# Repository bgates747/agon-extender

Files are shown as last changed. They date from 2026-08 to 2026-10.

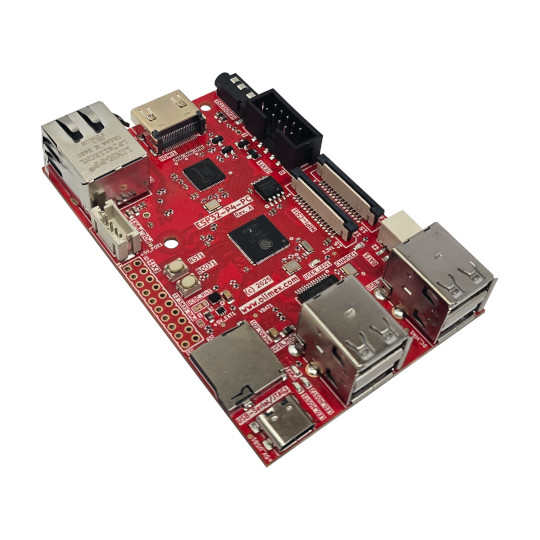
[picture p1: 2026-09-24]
docs/hardware/esp32-p4-pc/upstream/DOCUMENTS/ESP32-P4-PC-2.jpg

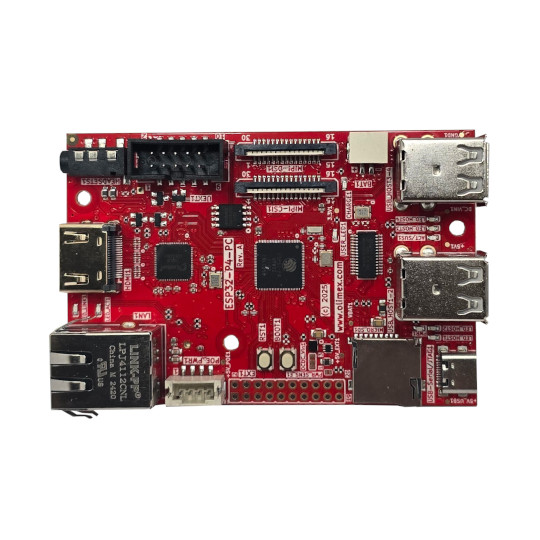
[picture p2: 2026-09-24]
docs/hardware/esp32-p4-pc/upstream/DOCUMENTS/ESP32-P4-PC-3.jpg

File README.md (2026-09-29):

# Agon Extender

Agon Extender adds an ESP32-P4 coprocessor to an Agon computer. **Extended
Display Processor (EDP)** runs on P4; **Extender MOS (EMOS)** replaces MOS on the
eZ80 and owns display routing, keyboard admission and Extender transports.

This is a working development project, not a general ready-to-install release.
The tree includes retained experiments and diagnostic targets. A source checkout,
a successful compile and a deployed/qualified combination are different things.

## Start here

The [Extender handbook](docs/README.md) is the current documentation entry point.

1. **Using an existing installation:** [operator and external-agent entry point](docs/using-extender.md).
2. **Transferring files:** [mainboard SD guide](docs/mainboard-sd.md), including the
   foreground `EMOS sdserve` EMOSlet and paired `--fast` option.
3. **Building:** [component build guide](docs/building.md). Select the native
   `p4-console` profile explicitly; the retained PlatformIO files are historical
   rollback material.
   The accepted r55 console was reconstructed from maintained source; select
   exact approved bytes through [production](production/README.md), not Git HEAD.
4. **Unfinished work:** [TODO](TODO.md). Task records preserve dated evidence;
   they are not automatically current operating instructions.

## Capabilities and limits

Current handbook review: **27 September 2026** (documentation/source inspection). Results apply to the
recorded builds and bench, not every Agon/P4 combination.

| Capability | Current status and authority |
|---|---|
| Legacy / Exclusive Compatible (ExCom) display routing | EMOS selects mainboard VDP or EDP. Retained VDP rendering and browser output work; compatibility and performance limits remain. [Architecture](docs/architecture.md), [bug register](docs/firmware-bugs.md). |
| Physical, browser and agent keyboard input | P4 USB input, explicit browser capture and paced host automation are implemented. All require EMOS to have admitted Extender input. Physical input takes priority; browser capture overrides automation. [Keyboard guide](docs/remote-keyboard.md). |
| Browser video and observation | P4 serves the page and final rendered pixels, with full-frame RLE2 by default. Browser output can slow gameplay; presented fps is not application-loop or native-rendering throughput. [Video contract](docs/protocols/browser-video.md). |
| Agon mainboard SD | Foreground `EMOS sdserve [--fast] /` supports listing, reads and recoverable staged replacement. Normal mode verifies whole files; fast mode omits those verification passes. EMOSlet installation and latest scoped physical checks: [operating guide](docs/mainboard-sd.md). It does not run alongside a game. |
| Remote reset | An optional Pi-hosted bridge pulses the Agon's reset circuit; the browser button uses that bridge. This is not P4-native reset or power cycling. [Reset guide](docs/bench-reset.md). |
| P4-local SD | Development candidate provides CLI/HTTP file and directory management; bounded r57 hardware checks recorded, outside selected production v0.1.0. [P4 SD guide](docs/p4-sd.md). Current bench firmware must be checked separately. |
| Future / deferred | Audio: [PORT-004](docs/tasks/PORT-004.md). Parallel transport, MicroPython and physical video outputs remain separate work; see [TODO](TODO.md). |

Network services use plain HTTP/WebSocket on a trusted LAN, without
authentication. The SD root passed to `sdserve` bounds access; `/` exposes the
whole mainboard card. The SD wire API does not execute programs. Agent keyboard
control can issue MOS commands only after its input path is already admitted.

The current physical reference is **Agon Light 2 + Olimex ESP32-P4-DevKit Rev D1**.
The [r03 UART harness](hardware/designs/light2-harness-r03/README.md) and its
USB addition are not a complete qualification of every as-built circuit.
The planned **ESP32-P4-PC** has a separate [reference library](docs/hardware/esp32-p4-pc/README.md)
with manuals, schematics, provenance and upstream example-clone instructions.
Do not treat the planned board as the installed DevKit.

## Source ownership and further reading

| Component / subject | Entry point |
|---|---|
| Integrated P4 console | [native profile authority](vdp/build/p4-profiles.json), [native builder](scripts/build_p4.py), [p4_console.cpp](vdp/video/extender/boot/p4_console.cpp) |
| EDP / adapted VDP | [vdp/video/extender](vdp/video/extender/), [vdp/video](vdp/video/), [retained libraries](vdp/vendor/) |
| EMOS and SD listener | [agon-emos](https://github.com/bgates747/agon-emos), including `src/` and `projects/sdserve/` |
| Host SD client | [scripts/sdcard.py](scripts/sdcard.py) |
| Embedded browser assets | [web component](vdp/video/extender/web/README.md); no separate npm build |
| Design and responsibility | [architecture](docs/architecture.md), [ownership](OWNERSHIP.md), [protocols](docs/protocols/) |
| Qualification and known faults | [qualification index](docs/qualification/README.md), [firmware bugs](docs/firmware-bugs.md), [publication review](docs/public-release-readiness.md) |
| Evidence and research | [task conventions](docs/tasks/README.md), [TRS-OS community guide](docs/tasks/TRS-80-002/COMMUNITY-GUIDE.md), [hardware-free samples](docs/tasks/TRS-80-002/bin/README.md) |

## License and upstream work

Agon Extender is distributed under **GPL-3.0-only**, except where individual
files or third-party components carry their own compatible license notices.
See [LICENSE](LICENSE) for the full text and [LICENSING.md](LICENSING.md) for
the licensing and attribution policy.

The port builds on the [official Agon VDP](https://github.com/AgonPlatform/agon-vdp)
and FabGL/vdp-gl. Original MIT and GPL-family notices and upstream attribution
remain applicable to their respective sources.

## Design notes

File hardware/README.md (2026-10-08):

# Hardware designs

Tracked hardware profiles, wiring definitions, and design evidence live here.
Every controlled design follows the identity and revision rules in
[`docs/versions/README.md`](../docs/versions/README.md).

The durable role vocabulary for hardware objects is maintained under
[`objects/`](objects/README.md). It owns names, classes, aliases, and containment
only. Pins, nets, components, and electrical connectivity remain authoritative
inside the applicable revisioned design or fixture profile.

The current P4-PC mapping has a separate
[wiring review drawing](designs/light2-p4pc-harness-draft/README.md), with complete
Agon/P4-PC headers, eight data/UART lanes and dedicated READY/CLOCK/VALID lines.
The Author confirms on2026-10-08 that the migration followed that specification.
The restored drawing and native P4-PC profile match; this is reported construction,
not a new continuity or powered parallel qualification. BOARD-001 owns remaining
as-built/electrical gates. GPIO47/48 are spare, proposed for deferred ZDI recovery.

The earlier simplified
[`light2-harness-r03`](designs/light2-harness-r03/README.md) records the DevKit
UART wiring, including disconnected Port D handshake lines, series resistors
and the separate USB cable. Those details are historical for that board; do not
apply them to the later PC assembly. Bounded UART, keyboard and ExCom results
remain under [PORT-008](../docs/tasks/PORT-008.md),
[PORT-015](../docs/tasks/PORT-015.md) and their qualification records. Neither
assembly inherits the buffered r02 isolation guarantees.

The held frozen candidate is
[`light2-harness-r02`](designs/light2-harness-r02/README.md). Its
placement-independent connectivity YAML is the electrical authority. The
revision also provides a checked design BOM in maintained YAML plus generated
Markdown and flat CSV views. The
predecessor [`light2-harness-r01`](designs/light2-harness-r01/README.md)
remains unchanged for the preserved first forward-transport prototype and its
evidence.

Revisioned physical breadboard configurations live under
[`assemblies/`](assemblies/README.md). The preserved first prototype is
`light2-extender-solderless-assembly-r01`; the new r02 electrical design is
assigned to `light2-extender-solderless-assembly-r02`, whose exact construction
map remains unfinished.

The accepted r02 physical schematic provides the circuit basis; the separate
[`wiring order`](designs/light2-harness-r02/wiring-order/README.md) plans powered
incremental construction in a now-superseded draft. The resistor-addition
proposal was rejected. The r02 design, construction, and testing remain
on hold as of 2026-09-07: full wiring is incomplete and the complete circuit
is untested. Signal views remain tracing/debugging references.
HW-001 and QUAL-002 record the actual installed
subset at each step under
[staged circuit validation](../docs/qualification/staged-circuit-validation.md).
The unfinished complete assembly map is not a lack of circuit authority or a
requirement to finish the entire build before checking a bounded stage.

The retained predecessor logic-analyzer attachment reference is
[`la03-p4-probe-fixture-r01`](fixtures/la03-p4-probe-fixture-r01/README.md).
Its green D0 endpoint was physically verified as GPIO32 / EXT2 pin 9; the
contradictory legacy pin-10 label is retained only as provenance.
Each r02 stage selects and verifies its own relevant measurement attachment;
the predecessor map is not automatically the probe map for that stage.

Machine-local specimen identities, bench topology, and current connection
status remain in the ignored `HARDWARE.local.md`, not this directory.

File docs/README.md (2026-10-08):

# Extender handbook

Start here for current operation and contracts. The [handbook closeout](tasks/AUDIT-009/CLOSEOUT.md)
records checked workflows and remaining limits; the broader [AUDIT-009](tasks/AUDIT-009.md)
historical review is incomplete. It must not require comparing old task amendments to determine
current behavior. Dated evidence supports claims but is not a second manual.

Production **v0.1.0** is the accepted local combination. The [current approved local installation](../production/README.md) selects exact
firmware, EMOSlet and host-tool archives with hashes and installation guidance.

## Use an existing installation

| Need | Current guide |
|---|---|
| First use, prerequisites, host setup and another project's workflow | [Using Extender](using-extender.md) |
| P4-local SD file/directory management candidate | [P4 SD HTTP guide](p4-sd.md), candidate only; not in selected production |
| Mainboard SD: foreground checked/fast, candidate automatic WebDAV and application transfers | [Mainboard SD](mainboard-sd.md) |
| Physical/browser/agent input, ownership and platform limits | [Keyboard input](remote-keyboard.md) |
| Read visible ExCom text without taking video ownership | [Screen text](screen-text.md) |
| Normal Agon reset and browser reset button | [Bench reset](bench-reset.md) |
| Recover an Agon that cannot boot MOS | [MOS recovery](mos-recovery.md) |
| Where files belong on SD | [SD layout](sd-layout.md) |

Remote input requires prior EMOS admission. The production SD listener is foreground,
requires Legacy mode and runs as `/emos/sdserve.bin`. Newer paired development
firmware additionally supports automatic staged mainboard WebDAV on port 8081
at an idle CLI in Legacy/negotiated ExCom, and application-initiated card transfers.
These passed bounded hardware checks but are not in selected production; the
[mainboard SD guide](mainboard-sd.md) supplies current usage and limits. P4-local SD HTTP access passed bounded r57 candidate checks but is outside the
selected production bundle. Neither this page nor the selected bundle identifies
the firmware currently on an occupied bench. Physical HDMI output remains unqualified. Consult the operating guides
for precise limits rather than assuming support from a research or example file.

## Develop against the current interfaces

| Need | Current authority |
|---|---|
| Discover host clients versus retained development helpers | [Host tool index](../scripts/README.md) |
| Common P4 service boundaries for other projects | [Shared services](shared-p4-services.md), development interface and consumer obligations |
| Linux emulator setup and review boundaries | [Emulator setup](emulator-setup.md) |
| Component builds and hardware-equivalence limits | [Building](building.md) |
| Installation bundles and selection status | [Production entry point](../production/README.md), [installation guide](installing.md) |
| Processor ownership and accepted architecture | [Architecture](architecture.md), [repository ownership](../OWNERSHIP.md) |
| EMOS resident gateway and prefixed utilities | [EMOS documentation](https://github.com/bgates747/agon-emos/blob/main/docs/README.md) |
| ExCom control / display-preserving switching | [Console protocol](protocols/excom-console.md) |
| SD wire protocol | [SD protocol](protocols/mainboard-sd.md) |
| Browser frame encodings and pacing boundary | [Video protocol](protocols/browser-video.md) |
| Firmware/build identity rules | [Version policy](versions/README.md) |
| Known faults and reproduction references | [Firmware bug register](firmware-bugs.md) |

The architecture includes accepted design beyond implemented coverage. Current
operation is bounded by the guides and recorded qualifications; an accepted
architecture is not a claim that every mode/peripheral has been implemented.
The selected r55 DevKit composition has a clean build and bounded physical
acceptance; use the production manifests rather than historical overlay recipes.
Other boards and complete peripheral compatibility remain unqualified.
The native [build guide](building.md#board-selection-and-compile-time-pin-mapping)
provides separate DevKit and candidate P4-PC board selections from one VDP source
tree. P4-PC pin and USB-hub configuration is compile-time input; it does not
establish hardware qualification or add HDMI output. A separately selected
experimental [P4-PC HDMI output](tasks/HDMI-001.md) provides fixed720p RGB888,
centered unscaled images with cropping, and retained browser keyboard/services.
r03 passes bounded Author startup and gameplay checks. Excess sprite flicker,
presentation throughput and full mode coverage remain open; this output remains
outside selected production and has no complete product HDMI acceptance.

## Test and qualify

| Need | Authority |
|---|---|
| Current versus historical procedure applicability | [Procedure index](procedures/README.md) |
| Current fixture constraints and accepted input exceptions | [Bench constraints](qualification/bench-constraints.md) |
| Capture failures and uninstrumented controls | [Capture protocol](qualification/capture-failure-protocol.md) |
| Offline HDMI candidate ranking | [HDMI candidate tool](testing/hdmi-candidates.md), experimental; no hardware changes or acceptance guarantees |
| Timing scopes, PRT units and package reuse boundary | [Game timing](testing/game-timing.md) |
| Deterministic rendering load, indefinite visual fixtures and paired mainboard/P4 measurements | [Rendering load suite](testing/render-load.md), experimental; campaign paused with partial results and an offline plotting tool |
| Permanent representative rendering fixtures and local-card result collection | [Resident rendering suite](testing/resident-render-suite.md), exact existing files and bounded acceptance |
| Installed-firmware acceptance suite | [Qualification suite](../qualification/README.md) |
| Qualification operation and retained runs | [Qualification procedure](testing/regression-suite.md) |
| Compatibility evidence / generated-matrix status | [Qualification index](qualification/README.md) |

Bench access, endpoints and installed-build receipts remain machine-local.
A procedure's existence does not authorize its execution or qualify a rebuilt
candidate. Historical runner scripts require review before reuse.

## Evidence and future work

[TODO](../TODO.md) is the unfinished-work index. [Task records](tasks/README.md),
[decision records](decisions/README.md), dated development logs and qualification
receipts hold history and rationale. [P4-PC references](hardware/esp32-p4-pc/README.md)
identify the official reference for the received Rev C replacement board and
retain the historical Rev B snapshot. Integration remains unqualified. Routine users should not need these archives
to reconstruct the instructions in this handbook.

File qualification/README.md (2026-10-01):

# Firmware qualification authority

This directory is the sole maintained executable authority for accepting an
Extender P4 or EMOS firmware revision. Historical task fixtures and scripts are
evidence and research inputs, not acceptance suites. Compatibility launchers
under `scripts/` may delegate here but contain no qualification logic.

## Acceptance policy

An installed Extender/EMOS combination is eligible for Author acceptance only
when the flash tool has produced verified receipts for both exact installed
components and one invocation of `qualification/run.py` records all of the
following against those receipts:

1. every `acceptance_required` case in `manifests/hardware.json` whose
   `applies_to` includes the flashed component passes on the installed boards;
2. the runner restores ordinary startup and admitted neutral keyboard state;
3. the durable summary identifies the flashed artifact and exact source commit,
   case results, elapsed times, and notification outcome; and
4. the Author completes any separately declared manual cases, including loaded-
   asset mode switches, before accepting a revision whose changes intersect
   those cases.

Offline source regression remains a separate development gate in `offline.py`;
it is not rerun by installed-firmware qualification and cannot substitute for
it. Build, emulator, browser-simulation, flash-write, boot-identity, and
human observations remain distinct evidence. No zero-hardware run may report
firmware qualification success. A flash receipt proves installation; it does
not substitute for installed-hardware qualification.

## Layout

| Path | Authority |
|---|---|
| `run.py` | Installed-firmware acceptance runner |
| `performance.py` | Separate installed P4 application/video cadence runner; not an acceptance substitute |
| `offline.py` | Separate pinned-source development regression runner |
| `notify.py` | Terminal spoken cue and durable visible verdict |
| `manifests/offline.json` | Complete maintained host/browser/build inventory |
| `manifests/hardware.json` | Applicable mandatory physical cases and drivers |
| `config.example.json` | Tracked schema for the ignored bench configuration |
| `tests/` | Structural tests for this qualification authority |

The full default run currently requires 25 independently reported checks across
three physical cases. The integrated P4 case exercises actual browser assets and
reset bridge, Agon reset/readmission, Legacy and ExCom routing, keyboard input,
display status, text capture, three fresh decoded WebSocket video frames, an
exact mainboard-SD round trip, independently verified cleanup, and final startup
recovery. WebSocket acquisition retains but discards queued transition geometry,
then requires three distinct frames matching the committed display status. The
RP06 P4 case exercises mode 8→20→8 first without a browser
client and then while retaining one browser-video WebSocket, checking committed
status and decoded frame geometry at every edge. The EMOS case builds its
receipt-bound fixture, stages it with restoration safeguards, exercises real
raw-sector write/read/restore with independent CRC oracles, observes a unique
ExCom start marker, then requires its unique post-I/O completion token and a
returned MOS prompt before starting its result listener and restoring the
original startup file. If completion is absent, only that run's start marker
followed by a later prompt permits recovery input; a bare prompt or retained
framebuffer content is not a foreground oracle. A missing prerequisite, receipt
or check fails closed.

QUAL-003 and QUAL-004 remain provenance for broad graphics and exact paired-
pixel testing. Their private adapters, diagnostic mainboard firmware, and
historical payloads are not silently executed as routine acceptance tests.
Reusable cases must be promoted here with current setup, cleanup, and exact
oracles before they become mandatory.

## Invocation

```sh
.venv/bin/python qualification/run.py \
  --flash-receipt /absolute/path/to/p4-flash-receipt.json \
  --flash-receipt /absolute/path/to/emos-flash-receipt.json
```

The default run requires one verified receipt for each component. `--case` is
reserved for targeted diagnostics and cannot establish full acceptance. The
runner owns its documented board resets, temporary
qualification SD file, cleanup, and terminal notification. It never flashes.

The separate performance runner also requires both verified receipts, but it
does not replace the mandatory acceptance suite:

```sh
.venv/bin/python qualification/performance.py \
  --flash-receipt /absolute/path/to/p4-flash-receipt.json \
  --flash-receipt /absolute/path/to/emos-flash-receipt.json
```

Keep ordinary browser video disconnected. The runner supplies its own controlled
video consumer for the observer-present half of each matched pair and reports
application updates/s separately from delivered frames/s. Empty controls use
the current 60-Hz request cap; Nurples adds the retained 30-Hz comparison. Each
application sample spans 30 seconds of MOS wall time. Nurples starts only after
loading and gameplay initialization; a post-sample white frame bounds the same
30-second host receive window without including loading or result cleanup. The
optional video-work counter endpoint strengthens no-video cases when present;
its absence is recorded and leaves browser disconnection as an operator-owned
precondition rather than rejecting an otherwise measurable firmware image.

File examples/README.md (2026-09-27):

# Development examples and witnesses

These programs are bounded diagnostics, not installed utilities or automatic
qualification. Current use belongs in the [handbook](../docs/README.md).
Do not replay a historical deployment just because its source remains buildable.

| Example | Purpose | Reuse boundary |
|---|---|---|
| [Key query](key-query/README.md) | Stock virtual-key query and event-counter witness | PORT-003 P03-EX01 must refresh hard-coded receipt placement before new runs |
| [Keyboard screen](keyboard-screen/README.md) | Stock rendered-character query diagnostic | REMOTE-002 R02-EX01 must refresh receipt placement and listener handover |
| [Remote keyboard](remote-keyboard/README.md) | eZ80 witness for host-injected events | REMOTE-002 R02-EX01 must refresh qualifier/receipt paths and listener handover |
| [Network hello](network-hello/README.md) | File replacement and ordinary VDP speech demonstration | DEMO-001 D01-EX01 owns the historical installer; refresh startup/service handover before replay |
| [Road matrix](road-matrix-probe/README.md) | Separate buffered computation from final drawing | Current placement guidance uses explicit evidence working directory; source still records submission, not completed rendering |
| [Video marker](video-marker/README.md) | Observable frame progress marker | Current placement guidance uses explicit evidence working directory; no scanout/completion claim |

For every new run, review and freeze its owning task's bounded fixture contract,
identify compiled bytes and preserve earlier receipts. `/autoexec.txt` alone
selects the video mode before invocation. Prepare directories and validate
current keyboard, route and foreground-service readiness. Source/build checks
do not establish current bench applicability. No examples were run or deployed
by the documentation audit.

The four refresh-required guides link retained recipes outside the current
operating path. The last two rows provide source-inspected placement only, not
a new build, installation or hardware pass.

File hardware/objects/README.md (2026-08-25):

# Hardware object authority

This directory is the durable project authority for role-descriptive hardware
object names, classifications, aliases, and containment. It answers **what an
object is** independently of a particular wiring revision, physical specimen,
bench location, test run, or ERP record.

The machine-readable authority is [`objects.yaml`](objects.yaml). Its structural
contract is [`schema.json`](schema.json), and the project validator adds
collection-wide checks that JSON Schema cannot express.

The current authority identity is `hardware-object-registry-r01`, with `draft`
status. Its lineage and latest identity are registered in
`docs/versions/artifacts.yaml`; status and identity in that registry and the
machine-readable authority must agree.

The initial 41-object vocabulary was synthesized from the accepted SETUP-006.1
discovery inventory and naming review. Those task files remain provenance, not
a second maintained object list.

## Authority boundary

The object authority owns:

1. one unique lowercase `object_id` for each durable role;
2. one human-readable label and description;
3. product, prototype, bench, measurement, proposed-product, and context
   domains;
4. reusable object classes and containment relationships;
5. searchable legacy aliases; and
6. links to related project artifact lineages where they already exist.

It does **not** own:

1. pins, nets, wire colors, connector terminals, component values, or
   electrical connectivity;
2. artifact versions or revisions, lifecycle status, physical specimen IDs,
   build IDs, baselines, or test runs;
3. current machine-local bench attachment or power state;
4. Odoo Product, Internal Reference, External ID, lot, serial, BoM, or ECO
   identities; or
5. unresolved protocol, operating-mode, or firmware behavior.

Electrical connectivity remains part of a controlled design revision under
`hardware/designs/<identity>/`. Measurement attachment remains part of a
controlled fixture revision under `hardware/fixtures/<identity>/`. This split
prevents a global vocabulary edit from silently changing the meaning of a
historical harness, fixture, baseline, or qualification run.

Machine-local specimen identity and current bench state remain in ignored local
records as required by the project handoff. ERP exports, when introduced, must
derive stable mappings from this authority and the applicable revisioned design;
they must not become a competing source of electrical truth.

## Change control

Adding, removing, merging, splitting, or redefining an object is a reviewed
semantic change to this authority. Changing only a legacy alias or correcting
wording without changing object meaning is editorial. Neither operation
silently increments a hardware design or fixture revision; any affected
revisioned artifact must be reviewed independently under
`docs/versions/README.md`.

Objects are sorted lexicographically by `object_id`. A `parent_object_id` is a
containment relationship, not an electrical connection. `related_artifact_ids`
are cross-references to the version registry, not assertions that the object is
identical to, wholly governed by, or qualified with that artifact.

## Validation

From the repository root, using the project virtual environment:

```text
.venv/bin/python scripts/validate-hardware-objects.py
```

Validation checks the JSON Schema, identifier and alias uniqueness, deterministic
ordering, parent existence and acyclicity, and references to registered artifact
IDs.

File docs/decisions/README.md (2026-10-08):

# Architecture decision records

Architecture decision records (ADRs) preserve accepted project architecture
and its rationale. Open questions and actionable work remain in the
authoritative `TODO.md` and corresponding files under `docs/tasks/`.

## Decision index

For implemented behavior begin with the [current architecture boundary](../architecture.md#implementation-boundary)
and [handbook](../README.md). This index reports decision metadata, not whether
an implementation or particular board has passed qualification. Later amendments
and linked current contracts govern over superseded details; historical run or
attention instructions are not continuing execution authorization.

| Decision | Recorded authority / completeness |
|---|---|
| [ADR-0001 — Place Extender code under `vdp/video/extender/`](ADR-0001-vdp-source-layout.md) | Accepted / Complete |
| [ADR-0002 — Use PlatformIO with Arduino and ESP-IDF together](ADR-0002-hybrid-firmware-framework.md) | Superseded by ADR-0023 / Complete |
| [ADR-0003 — Pin pioarduino release 55.03.311](ADR-0003-pioarduino-platform-baseline.md) | Accepted / Complete |
| [ADR-0004 — Identify the board as a pre-v3 ESP32-P4](ADR-0004-p4-silicon-identity.md) | Accepted / Complete |
| [ADR-0005 — Qualify QIO flash operation at 80 MHz](ADR-0005-flash-bus-mode.md) | Accepted / Complete |
| [ADR-0006 — Represent internal SRAM and external PSRAM separately](ADR-0006-board-memory-model.md) | Accepted / Complete |
| [ADR-0007 — Use two large OTA application slots](ADR-0007-flash-partition-strategy.md) | Accepted / Complete |
| [ADR-0008 — Add CMake only when the hybrid build proves it necessary](ADR-0008-minimal-cmake-boundary.md) | Superseded by ADR-0023 / Complete |
| [ADR-0009 — Provide a transparent PlatformIO wrapper](ADR-0009-platformio-wrapper.md) | Superseded by ADR-0023 / Complete |
| [ADR-0010 — Use 360 MHz on the current pre-v3 P4](ADR-0010-cpu-frequency.md) | Accepted / Complete |
| [ADR-0011 — Maintain upstream VDP fidelity and separate project-owned structure](ADR-0011-upstream-vdp-integration-and-project-structure.md) | Accepted / Complete |
| [ADR-0012 — Vendor exact release dependencies for the VDP firmware](ADR-0012-vendored-release-dependencies.md) | Accepted / Complete |
| [ADR-0013 — VDP survey findings and integration boundaries](ADR-0013-vdp-survey-integration-boundaries.md) | Accepted / Complete |
| [ADR-0014 — EDU operating modes, state ownership, and service architecture](ADR-0014-edu-operating-modes-and-service-architecture.md) | Accepted / Partial |
| [ADR-0015 — P4 display backend and logical frame service](ADR-0015-p4-display-backend-and-frame-service.md) | Accepted / Complete |
| [ADR-0016 — V1 transport electrical core](ADR-0016-v1-transport-electrical-core.md) | Accepted / Partial |
| [ADR-0017 — Generalized EDP callbacks](ADR-0017-generalized-edp-callbacks.md) | Accepted / Partial |
| [ADR-0018 — RGB222 browser video and bounded frame pacing](ADR-0018-rgb222-browser-video.md) | Accepted / Complete |
| [ADR-0019 — Host keyboard input and independent bench reset](ADR-0019-host-keyboard-and-bench-reset-control.md) | Accepted / Complete |
| [ADR-0020 — 30 fps web output at512×384](ADR-0020-web-output-30fps.md) | Accepted / Complete |
| [ADR-0021 — RLE2 as the browser-video default](ADR-0021-rle2-browser-default.md) | Accepted / Complete |
| [ADR-0022 — Explicit browser keyboard capture](ADR-0022-browser-keyboard-capture.md) | Accepted / Complete |
| [ADR-0023 — Native ESP-IDF/CMake with Arduino as a component](ADR-0023-native-esp-idf-build-authority.md) | Accepted / Partial; implementation decisions in BUILD-001 |
| [ADR-0024 — Centered HDMI presentation](ADR-0024-centered-unscaled-hdmi.md) | Accepted / Complete; HDMI-001/HDMI-002;512×384 stays pillarboxed in a widescreen carrier |
| [ADR-0025 — Bounded RGB888 rendering experiment](ADR-0025-rgb888-rendering-experiment.md) | Accepted / Complete |
| [ADR-0026 — Eight-bit ExExt payload with existing-wire handshaking](ADR-0026-four-lane-exext-transport.md) | Accepted / Partial; PORT-008 owns peripheral/protocol selection and qualification |
| [SD separation of support files, evidence and transactions](ADR-2026-09-21-sd-layout.md) | Accepted / Complete |

[Browser mainboard SD access](ADR-2026-09-27-browser-file-access.md): Accepted / Partial; remaining decisions in REMOTE-005.

[Staged WebDAV with EMOS admission](ADR-2026-09-27-staged-webdav-admission.md): Proposed / Partial; review and open decisions in REMOTE-005.

When changing an ADR's identity, title, status or completeness, update this index.
Do not infer a new decision or change qualification status merely to make the
index look complete.

## Required metadata

Every ADR begins with these fields immediately below its title:

```markdown
- Status: Accepted
- Completeness: Complete
- Date: YYYY-MM-DD
```

Add `Related task` when a task owns the decision. An ADR with partial
completeness must also name its authoritative tracker:

```markdown
- Open-decision tracker: SETUP-NNN
```

## Status

- **Proposed:** presented for review but not authoritative.
- **Accepted:** authoritative current architecture.
- **Rejected:** considered and explicitly declined.
- **Superseded:** no longer authoritative; the ADR identifies its replacement.

Status describes the authority of decisions already recorded. Qualification,
implementation, and testing state do not change an accepted decision's status;
record those separately in its task and evidence.

## Completeness

- **Partial:** accepted decisions exist, but known architectural decisions
  remain unresolved inside the ADR's declared scope.
- **Complete:** no known architectural decisions remain unresolved inside the
  declared scope.

Complete does not mean immutable, implemented, tested, or eternally final. New
evidence may amend or supersede any ADR. Partial ADRs contain only accepted
decisions and link to a task that owns the unresolved questions; they do not
duplicate open questions or actionable checklists.

When the final tracked question is resolved, incorporate the accepted result,
change completeness to `Complete`, and update the task and development log.

## Design audit records

Files named `AUDIT-YYYY-MM-DD-NNN-<subject>.md` record a bounded review of
current architecture, tasks, implementation, generated data, and evidence.
They identify contradictions, omissions, stale assumptions, and affected
authorities without making new architecture authoritative merely by finding a
problem.

Every audit begins with `Status`, `Date`, `Trigger`, `Scope`, and `Owning task`.
Findings use stable IDs and record severity, observed state, required
disposition, and affected artifacts. Status is `In progress` while coverage is
being gathered and `Complete` when the declared scope has been reviewed and
every finding has an owner or explicit deferral.

Accepted architectural corrections are promoted into the applicable ADR and
normative architecture document. Actionable work remains in the owning tracked
task and `TODO.md`; generated outputs are regenerated from their corrected
authorities. An audit is evidence and a correction map, never a competing
architecture specification or task list.

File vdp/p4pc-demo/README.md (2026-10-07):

# P4-PC playground

## Executive summary

Standalone experimental ESP-IDF firmware for P4PC-001: native VGA/720p HDMI animation,
finite analog audio playback, persistent Ethernet and a USB serial command
prompt. This is not an Extender production profile. Agon is not connected.

## Controls

Use the board's USB Serial/JTAG endpoint, 115200 baud, without DTR/RTS reset. Use the supplied Linux client to avoid open-time
modem-line transitions; generic terminal programs may reset this board.
The prompt is `p4pc>`. `help` repeats the controls.
For a single command, use project Python to run
`vdp/p4pc-demo/control.py --port PORT "demo bounce"`; it leaves DTR/RTS
untouched and waits for a bounded command-completion prompt.

| Command | Behavior |
|---|---|
| `info` | Version, IP, heap, SD, scene; pool/render statistics when the display lock is available |
| `demo orbit` | Coloured circles in intersecting orbits |
| `demo bounce` | Bouncing coloured shapes |
| `demo bars` | Static eight-colour bars |
| `demo widgets` | Start the LVGL widgets slideshow once per boot, preferably from paused startup bars |
| `bench 30` | Finite 5–30 second paced benchmark; default 10 seconds; updates/renders/submissions/scanout and stage timings |
| `bench 20 draw` | Drawing capacity: sequential fixed motion steps/refresh, same cache writeback, no presentation/wait |
| `bench 20 rgb332` / `bench 20 rgb888` | Native 640×480 matched opaque-circle reference; direct packed writes/full clear, scanout stopped; restores GUI/prior scanout |
| `scanout off` / `scanout on` | Stop/resume P4 framebuffer DMA and DSI video; retained buffers; off blanks the monitor |
| `pause` / `resume` | Freeze/resume playground animation (does not pause the widgets slideshow) |
| `tone 440 3` | 440 Hz sine wave for 3 seconds; 50–4000 Hz, 1–10 seconds |
| `melody` | Short C-major phrase |
| `volume 65` | Set codec volume, 0–90; default 65 |
| `video` | Report framebuffer samples and LVGL flush count |
| `video raw` | Pause UI refresh and fill scanout memory with direct colour bars |
| `video pattern` | DSI host bars independent of framebuffer pixels |
| `video ui` | Restore UI rendering; resumes playground animation when widgets are inactive |
| `net start` | Start persistent Ethernet/DHCP (deferred during display diagnosis) |
| `sd mount` | Mount SD read-only test path without formatting or write test |
| `sd ls` | List the SD root, limited to 128 entries; no file writes |

The serial owner executes audio synchronously for its finite duration while
LVGL and networking run independently. Audio starts silent; output goes through
the analog headset jack at codec volume 65 with moderate signal amplitude and
short note envelopes. This is not HDMI audio or a stereo-separation test.

`prepare.py --resolution 640x480` selects native RGB888 VGA: PLL 240 MHz / 8,
30 MHz, totals 952×525 and calculated 60.0240 Hz, horizontal blanking 168/96/48,
vertical 10/2/33, VIC 1 and 4:3 metadata. The selected copied BSP slot is
repurposed, including LVGL and panel buffer geometry. It is not a small window
in a 720p framebuffer. Both DSI lanes use 360 Mbps, matching RGB888 pixel demand; peripherals remain idle. This is custom
blanking requiring monitor validation. `--vga-clock apll` retains the failed r10
25.2 MHz/800×525 control; it produced no framebuffer completions.

r11/r12 native output fails Author visual review despite advancing panel
counters. r13 tests LT8912B low-resolution settle and live-stream receiver/DDS
relock; this remains an experimental remedy. Render-only format results do not
require usable HDMI and do not establish a visual pass. The selected LVGL
software renderer has no direct RGB332 backend; the reference kernel excludes
antialiasing/labels and reports drawing, motion and cache times separately.
See the [packed-format method](../../docs/tasks/P4PC-001/RGB332-REFERENCE.md).

The default remains 1280x720, RGB888. r06 uses matched WLED-derived 60 MHz
DPI/bridge timing, two 720 Mbps DSI lanes and totals 1350 × 741, calculating
59.979 Hz. This custom blanking needs physical monitor acceptance; it is not
measured refresh or proof of universal monitor support. The ultimate target
is 60 Hz. The factory SDK's inherited configuration calculates approximately
75 Hz; the earlier unbuilt 80 MHz preparation remains historical evidence.
See the task's [timing research](../../docs/tasks/P4PC-001/DEMO-CANDIDATES.md).
r09 schedules animation and LVGL refresh at 16 ms, with orbit phase based on
elapsed time. This does not establish 60 rendered frames/s: the measured
24-circle 720p workload renders about 12 frames/s while the panel completes
about 60 frames/s. See the [benchmark](../../docs/tasks/P4PC-001/BENCHMARK.md).
Ethernet remains active after DHCP. The BOOT button is deliberately unused
because GPIO35 is shared with RMII TXD1. Do not use BOOT for scene selection.
SD mounting never formats; the upstream write-test function is not invoked.

## Build and provenance

Run `prepare.py` with the project `.venv/bin/python`, supplying `--upstream`
and a new `--output` directory, plus an Author-approved `--revision rNN`.
Optional `--resolution 640x480` selects the Author-requested native VGA
comparison; default is `1280x720`. It requires a clean Olimex checkout at
`04032d68e5c727870f9d40beb9e37b7ab3a66916`. The preparer copies the factory
project into an ignored build workspace, replaces its entry point, removes
unused test components and changes console/font/formatting configuration.
The timing adaptation changes DPI and LT8912B timing together, chooses an exact clock divider,
and disables low-power blanking. Provenance and the IDF divider/compensation
workaround are explained in `prepare.py` beside the edits. The widgets demo
is supplied by the pinned LVGL dependency; its slideshow uses no input device.
r09 uses direct double buffering and a 1 MiB builtin pool allocated through
IDF's fixed PSRAM malloc policy. The inherited compiler remains debug `-Og`;
no accelerated LVGL drawing backend is selected.
The upstream BSP retains its notices and board wiring. No upstream checkout
is edited. Main application code belongs to this project.

`build.py` uses project-owned ESP-IDF 5.5.5 at
`b774170ff46c393eeb5e495ea37936038d3f4f4f` and native host tools under the
ignored workspace. Its default workspace is `agents/p4pc-demo`, containing
`project`, `tools`, `python-env` and `build`. The toolchain is Espressif
`esp-14.2.0_20260121`; Python packages must satisfy IDF's v5.5 constraints.
`build.py` rebases copied local dependency paths into the selected prepared
project without changing registry pins, then checks the actual compiled
component directories. A stale copied lock previously selected an older port;
prepared source alone is insufficient evidence of compiled source.
Retain the generated component lock, SDK configuration, source manifest and
image hashes with each candidate. `version.txt` carries the short build suffix
because the IDF app-description field is limited in size.

Before replacement, preserve and device-verify the entire factory flash. Flash
only the generated segments at their recorded offsets, keeping header bytes,
and verify them before reset. Local endpoint, rollback and installation receipts
belong in `HARDWARE.local.md` and ignored evidence. The task record owns human
visual/audio acceptance and known limits.

The current main starts with paused direct framebuffer bars before creating the animation
task. Atomic pause controls stop incoming animation without waiting behind
rendering. `info` reads counters independently of the display lock; allocator
statistics can still be unavailable while rendering is busy. Ethernet/SD remain
deferred and audio idle. The original factory control and r06 bars/circles
passed physical review. The Author also confirmed changing r09 widgets.

`display_experiment.py` copies the pinned SDK's `esp_lcd` component into the
prepared project and adds a task-local stop/resume hook. Stop waits for a complete
DMA frame, skips rearming and disables DSI video/DPI demand. Resume rebuilds the
existing descriptors, retaining buffers. This is diagnostic source, not an SDK
patch or production display contract. The SDK reference remains unmodified.

Drawing-capacity mode holds the LVGL mutex for a finite window, executes one
fixed animation step and explicit refresh per iteration, and yields one tick
for idle/watchdog readiness. The ordinary tasks remain blocked or paused until
restoration. It bypasses the ordinary port flip/wait in both scanout
states and matches its full-frame cache writeback. LVGL keeps its two buffers
and synchronization. Active DMA repeats a buffer that the diagnostic may
overwrite; drawing-only counts are not safely presented FPS or visual quality.
The paired windows isolate DMA contention. Ordinary paced mode supplies the
practical visible reference; 60 scanout completions/s alone is insufficient.

For a benchmark, select the workload first and use the raw client with a timeout
longer than the finite command, for example `--timeout 45 "bench 30"`. Retain
its start/end markers, actual device microseconds and counter output with
`--log`. A panel completion can repeat pixels. The USB owner does not update
its ordinary periodic status label while the benchmark command runs.

Stage timings use complete intervals beginning inside the finite window.
`draw_mean_ms` is render duration minus wrapper flush time, including software
drawing/dispatch. `cache_mean_ms` measures writeback, `wait_mean_ms` the port's
frame-completion semaphore, and `refresh_mean_ms` includes layout and buffer
synchronization outside the render interval. Boundary counts may differ by one.
See the [native scanout comparison](../../docs/tasks/P4PC-001/SCANOUT-COMPARISON.md).

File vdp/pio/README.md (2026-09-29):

# Historical hybrid build material

BUILD-001 replaced PlatformIO/SCons with native ESP-IDF/CMake as the sole
maintained P4 build authority. Files in this directory and `vdp/platformio.ini`
remain only to reproduce identified pre-cutover evidence, especially hybrid r61.
They are not a second current source/profile authority.

Routine builds use `scripts/build_p4.py` and `vdp/build/p4-profiles.json`.
`scripts/vdp-pio.sh` refuses execution unless the operator supplies the explicit
historical-use acknowledgement documented by that script. Frozen diagnostic
builders retain their owning task contracts; a future need must define a native
profile under a bounded task instead of silently reviving a hybrid environment.

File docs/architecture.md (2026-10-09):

# Agon Extender Architecture

This document defines the accepted design, including requirements whose
implementation remains deferred. It is not a claim of complete compatibility.
[The handbook](README.md) owns current operation; [TODO](../TODO.md) and linked
tasks own incomplete implementation and decisions. No new architecture is
established by a successful experiment or by this documentation reconciliation.

## Implementation boundary

| Area | Current boundary | Authority |
|---|---|---|
| Ordinary display | Legacy and bounded ExCom over UART work; Dual/Exclusive Extended remain broader design requirements | [Console contract](protocols/excom-console.md), PORT-003 / SETUP-005 |
| Input | Mainboard selection and admitted Extender USB/browser/agent input; platform/fault limits remain | [Keyboard guide](remote-keyboard.md) |
| Mainboard SD | Foreground EMOSlet through resident `ext.sdlink` in Legacy; not a background filesystem | [SD guide](mainboard-sd.md) |
| Generalized callbacks | Accepted production requirement; current private timing callback is not the finalized general ABI | [ADR-0017](decisions/ADR-0017-generalized-edp-callbacks.md) |
| Audio / P4-local SD / local video | Accepted or researched directions, not current working output/storage capabilities | PORT-004 / PORT-007 / P4PC-001 |
| Hardware | Simplified r03 UART/USB path has bounded evidence; drawing/as-built work remains. Four-chip r02 is held | [Hardware index](../hardware/README.md), HW-002 |
| Web pacing | Accepted 30-fps contract at 512×384 is not enforced by the selected presentation-credit browser client | [Video boundary](protocols/browser-video.md#implementation-and-later-experiment-boundary) |
| Rebuild | Base target does not reconstruct every deployed overlay | [Build limits](building.md#deployed-candidates-versus-the-base-target) |

The remaining sections state design obligations unless an implemented subset is
identified explicitly. Full fault recovery, generalized EDU APIs and compatibility
coverage must not be inferred from the working console or diagnostic services.

## Browser-video default encoding

RLE2 is the accepted default for browser video output. It compresses complete
supported frames; raw compatibility and explicit test overrides remain available.
See [ADR-0021](decisions/ADR-0021-rle2-browser-default.md) and the
[browser-video contract](protocols/browser-video.md). Encoding choice does not
change the separately accepted output pacing policy.

## Web-output cadence

The accepted 512×384 web-output contract is 30 complete frames/s. The selected r55 browser has no explicit rate limiter; its presentation-driven credits must not be described as either a guaranteed 60 Hz or an enforced 30 fps. Normal test
fixtures must cap snapshot/output admission at 30 fps, independently of native
rendering and application cadence. See [browser-video contract](protocols/browser-video.md)
and [ADR-0020](decisions/ADR-0020-web-output-30fps.md). This target still needs
representative production/browser qualification; it is not a blanket measured guarantee.

## VDP firmware lineage

Agon Extender's VDP firmware begins as a faithful port of the official Agon VDP
to the ESP32-P4. Full backward compatibility with existing Agon software is a
product requirement.

The port preserves official directory names, filenames, relative source
locations, and recognizable code wherever the target permits. P4-specific
changes should be narrow and explicit so maintainers can compare the port with
upstream and incorporate future official changes without reconstructing
equivalent modules under unrelated names.

## Repository layout

The complete P4 build project and VDP firmware live under the repository's
top-level `vdp/` directory. During BUILD-001 migration that directory contains
both the operational hybrid PlatformIO rollback path and the accepted native
ESP-IDF/CMake target structure. Within the project, `vdp/video/` mirrors the
official VDP source directory.

New Extender capabilities and extended functions live under:

```text
vdp/video/extender/
```

This location is inside the firmware source directory selected by the project's
neutral build-profile manifest while retaining a clear ownership boundary.
Existing upstream files remain at their official relative paths. Calls between the
upstream-shaped compatibility port and Extender-owned modules must use narrow,
documented integration points.

The rationale and consequences of this placement are recorded in
[ADR-0001](decisions/ADR-0001-vdp-source-layout.md).

## Change boundaries

The upstream-shaped compatibility port owns stock VDP behavior. The
`video/extender/` subtree owns capabilities that do not exist in the official
firmware.

Target adaptation should follow this preference order:

1. retain upstream code unchanged;
2. isolate board or architecture differences in target-specific support code;
3. use a small conditional or insertion point in an upstream-shaped file when
   isolation is impractical; and
4. replace an upstream implementation only when the P4 target makes the
   original mechanism unavailable.

Every deviation from upstream should remain attributable to a verified target
requirement or an accepted Extender feature.

The official header-defined screen facade remains the display integration
boundary for the port. Preserve its global Canvas/controller ownership, mode
selection and fallback, logical dimensions and scaling, palette and Copper
state, logical frame counter, completion waits, and buffer swaps. P4 display
work may narrowly adapt the concrete controller created behind that facade; it
must not replace the facade with an unrelated project-owned display model.

FabGL `Canvas` and the common bitmapped rendering layer remain the semantic
implementation beneath that facade. Preserve their primitive ordering and
queues, paint and clipping state, geometry, glyph and bitmap operations,
sprites, cursors, readback, completion, and buffering contracts. Direct
assumptions about the old Xtensa VGA-ISR environment may receive narrow P4
adaptations; those changes do not authorize unrelated renderer redesign.

The original VGA2/4/8/16/64 concrete controller family is retained behind a
narrow P4 processor/output binding. It produces native framebuffer state and
logical frame progression independently of any one physical output sink, so
the guaranteed network/browser path and later P4-native local displays consume
one rendering model. Preserve stock mode dimensions, palette quantization,
Copper scanline effects, sprite composition, readback, double buffering, frame
waits and counters, callbacks, and mode failure/fallback behavior as closely as
practical. The old GPIO-matrix, I2S1, DMA-chain, and VSync-ISR engine remains
vendored reference material, not the P4 physical backend.

This stock-shaped family is the **sole product display owner**. The neutral
P4 profile manifest names it explicitly and requires every display-bearing
profile to select exactly one complete, mutually excluded family. The older
project-owned `P4DisplayController`/`P4FrameService`/`PlaneStorage`/
`PaletteState`/`PresentationCompositor` family is not an alternate product
backend and must receive no copied product repair. It remains buildable only in
the non-release PORT-008 qualification profile while that task completes its
actual-action provenance and retained-parser fault-injection gates. Once those
gates are accepted and their transport oracles no longer depend on the older
display closure, the profile and older family are removed; frozen PORT-003
evidence remains historical rather than executable product guidance.

The video backend preserves stock framebuffer formats, memory organization,
row access, rendering algorithms and fast paths as faithfully as possible.
Reuse upstream code exactly wherever processor facilities and video-output
interfaces permit it, including portable code within the old concrete VGA
classes. Differences require a specific evidenced processor/output dependency;
generic abstractions, browser serialization and an existing project design do
not by themselves justify replacement.

Retain stock native packing, palette/Copper behavior, bitmap save/readback,
sprites, cursors, buffering, completion and mode contracts. Contiguous allocation
may coexist with a logical row-pointer table. Browser and later local-display
adapters produce their required output representation at the output boundary;
they do not require the drawing framebuffer to share that representation.
ADR-0013 and ADR-0015 record the Author's fidelity direction. The accepted
AUDIT-006 comparison selects original depth classes with narrow P4 bindings;
PORT-003 owns implementation. First-pass restoration preserves compilable
upstream behavior unchanged, including suspected bugs; fixes are deferred.
Stock lane ordering and inert sync bytes may remain in native storage, with
normalization confined to the output boundary.

A short P4 `esp_timer` callback accounts elapsed logical frames independently
of every output sink and wakes separate drawing and output tasks. P4 preserves queued primitive
execution through the unchanged common controller, logical frame progression
and presentation publication, while maintaining stock's separation between
drawing progress and periodic display progression. Frame counting/output
opportunities must not wait for a continuously replenished drawing queue to
empty. Physical sink callbacks may recycle sink buffers
but do not advance the VDP frame counter or unblock logical swaps.
On a service opportunity, P4 drains queued drawing in FIFO order until empty
or suspended, matching stock VDP's background worker with its timeout disabled.
No fixed primitive-count or elapsed-time cap throttles this drain. Suspension
is checked between primitive executions; immediate flush and double-buffered
drawing/swap contracts remain unchanged.

For the original-controller P4 binding, browser row preparation may wait for
one drawing primitive under PORT-003-R2-D001. Native drawing is excluded only
during one row preparation, and all metadata/lifetime owners share the same
exclusion protocol. This output compromise was accepted with reservation:
stock's reliable 60 Hz cadence remains the reference. The frame-clock path
takes no native-state lock and does not wait for drawing, output preparation,
network delivery or a free snapshot slot. Qualification distinguishes actual
clock jitter from delayed browser presentation. A full queue drain or full
frame copy is not an allowed exclusion boundary.
The current base service prepares snapshots on consumer demand, not on every
logical tick when no sink requests an image. The mode-derived logical
clock interval (16,667 microseconds for 60 Hz) is distinct from rendering
completion and browser presentation rate. Elapsed-tick accounting is not proof of bounded callback jitter or
uninterrupted gameplay; the [display decision](decisions/ADR-0015-p4-display-backend-and-frame-service.md)
maps current source responsibilities and qualification limits.

The retained common renderer preserves pinned upstream bodies for
queue submission, completion waits, background draining, dynamic payloads, and
swap notification. The P4 controller replaces only the unavailable physical
frame executor through existing protected seams. Narrow native-state guards
at execution/lifetime boundaries implement the accepted P4 CPU-reader binding;
they do not change drawing algorithms or add upstream bug fixes. In particular, strict
compatibility retains upstream queue-depth completion behavior even though a
separate A/B research task may evaluate stronger semantics for an upstream
contribution.

Generalized callbacks are an accepted production EDP requirement: applications
are to receive a documented return path for EDP events, results and state. The
current private timing callback is not that finalized general interface. This
supports meaningful interaction beyond submitting display commands. EMOS
retains transport and application mediation under the EDU service contract.
Render completion and the graphics benchmark are initial use cases within the
broader facility. Rendering completion remains distinct from output-sink
presentation, and the retained stock VDU completion contract still applies.
Pingo's mainboard-tested callback supplies a precedent without prescribing the
general callback mechanism or ABI. See
[ADR-0017](decisions/ADR-0017-generalized-edp-callbacks.md).

## EMOS lifecycle observability

Resident EMOS is the authoritative owner of its startup, foreground,
mode/route, failure and admitted-job lifecycle state. The P4 EDP may issue a
bounded read-only query and cache the current-epoch EMOS report for host tools;
P4 keyboard counters, rendered pixels, elapsed time and P4-local service state
are not substitutes for that report. A query grants the P4 no authority to
launch, cancel, reset, select a mode, commit a route, or mutate EMOS state.

QUAL-006 owns the incomplete protocol design. Its recommended no-rewire carrier
uses the existing full-duplex r03 UART1 epoch: P4's transmit lane carries a
private query and EMOS's sole output serializer emits one complete private
response between complete VDU/service records. RTS/CTS remain flow control, not
request signalling. The exact framing and whether queries must work before
explicit Extender UART admission remain open; no new wire or early-boot service
is selected merely by this architecture requirement.

One shared output path reuses stock per-depth packed row expansion, palette
tables, Copper traversal and sprite/cursor decoration without changing
logical framebuffer state or readback. Network/browser and later local-display
sinks receive fixed-capacity latest-generation mailboxes through a common
consumer contract. The frame service never invokes sink code; sinks poll from
their own tasks. Slow sinks may drop reported presentation generations; they
must not block rendering, grow an unbounded queue, or redefine logical frame
timing. See
[ADR-0015](decisions/ADR-0015-p4-display-backend-and-frame-service.md).

By default the P4-PC HDMI adapter presents fitting mode images unscaled and
centered in a selected widescreen nominal60Hz output buffer (initially1280×720), with black
letterboxing and pillarboxing, cropping centered oversized images. Each logical
pixel occupies one output pixel; RGB888 conversion and composition remain at
the output boundary. HDMI follows logical mode double buffering where feasible,
otherwise single buffering, with completed double-buffer publication at a
hardware frame boundary. VDP frames follow the hardware cadence independently
of conversion success. HDMI replaces browser video in this build selection;
browser keyboard and other web services remain available. Future runtime output
selection is owned by EMOS. This accepted
geometry is implemented with bounded hardware evidence; full qualification
remains pending. See
[ADR-0024](decisions/ADR-0024-centered-unscaled-hdmi.md); HDMI-001 owns remaining
implementation and qualification. The Author specifies that logical512×384
stays pillarboxed inside a widescreen carrier; it is not a4:3 HDMI output target.
HDMI-002 qualifies smaller widescreen timings under that same presentation rule.
The Author also authorizes full-width logical drawing on the proven848×480
carrier. Such Extender-specific modes use ordinary EMOS-routed VDU22 selection;
stock mode IDs and geometry remain unchanged. Initial IDs are experimental and
their implementation/qualification belongs to HDMI-002, not the stock API.
At an ordinary EMOS-routed logical mode change, the P4 may select the smallest
proven fitting carrier:684×384 for fitting images up to384lines,848×480 for
480-line images. The P4 joins drawing/output, retires borrowed framebuffer
references and restarts DSI/bridge ownership on core1 before publishing the new
mode. Same-carrier changes retain the existing candidate lifecycle. Logical
mode IDs and buffering semantics remain stock-owned. Oversized images retain
the documented crop fallback; this does not qualify additional carriers.
Experimental timing selection does not change legacy logical mode IDs.
The Author-authorized 320×240 experimental exception uses PPA bilinear2×
presentation: a decorated private320×240 snapshot becomes640×480 at(104,0) in
848×480. Logical front/back buffers remain independent from the HDMI pair.
The P4 rejects a snapshot spanning a logical swap, finishes scaling before
publication and waits for actual DMA release before reusing HDMI buffers.
This exception preserves application dimensions/swap commands, and its loaded
qualification remains owned by HDMI-002; other modes retain unscaled output.

The separate FabGL `VGATextController` is retained in the complete vendored
vdp-gl source but excluded from Extender builds. Official VDP text remains on
the retained Canvas/bitmapped-controller path, so the unused hardware
character-cell VGA driver receives neither a P4 port nor a compatibility stub.

FabGL `CVBSGenerator` likewise remains in the complete vendored vdp-gl source
but is excluded from Extender builds. Composite video is neither part of the
official VDP runtime nor a selected Extender output, so its classic-ESP32
DAC/I2S0/DMA implementation receives no P4 replacement or stub.

FabGL `Scene` also remains vendored but is excluded from Extender builds.
Official VDP sprites retain their own state and bitmapped-controller path;
shared Sprite/display types survive independently. No Scene task, mutex,
collision callback, or parallel sprite scheduler is selected unless a future
Extender feature adopts it explicitly.

The following audio paragraphs define the accepted implementation direction;
current EDP command-consumption support does not provide audio synthesis or a
working output sink. PORT-004/AUDIO-001 own that deferred implementation.
The official header-defined VDP audio runtime remains the audio integration
boundary. Preserve its parser, `PACKET_AUDIO` acknowledgements, channel state,
envelopes, buffer-backed samples, playback timing, audio-control task, and VDU
7 behavior. P4 audio work may narrowly adapt its direct
`fabgl::SoundGenerator` binding to the selected synthesis and output service;
it must not replace the official runtime with a separate audio model.

The vdp-gl waveform and mixer core remains the synthesis layer beneath that
runtime. Preserve waveform generation, channel attachment and lifetime,
sample-rate propagation, channel and global volume behavior, and signed
eight-bit PCM mixing. A narrow P4 adaptation may expose mixed samples to an
Extender-owned scheduler or sink; output backends must not create independent
synthesis semantics.

An Extender-owned PCM scheduler and sink service replaces FabGL's
classic-ESP32 DAC, sigma-delta, I2S0-register, legacy-DMA, fixed-pin, ISR/timer,
and display-mode-selected output machinery. Those physical paths remain in the
complete vendored source but are excluded from the P4 build. Network/browser
audio is the guaranteed Rev 1 sink; Rev 1 does not promise the stock analog
output location or exact analog characteristics.

Logical audio playback runs from the selected sample clock independently of
sink latency, backpressure, or availability. A disconnected or slow browser
must not block VDU processing, delay logical note completion, or alter channel
status; delivery may drop or resynchronize instead. Optional forwarding to the
onboard VDP for local playback remains a separate operating-mode decision.

The dormant vdp-gl `FileBrowser` remains in the complete vendored source but is
excluded from Extender builds. Extender does not presently select a file-browser
API, and required local storage does not imply one. The P4 DevKit microSD card
is a required v1 capability deferred beyond the first beta; its implementation
will follow maintained Olimex/Espressif P4 SDMMC reference code and a
project-owned lifecycle rather than FabGL's classic-ESP32 storage backend.
EDP owns this physical card and its filesystem service. EMOS must be able to
request file reads and receive data from that service through its owned
Extender transport; the P4 card is distinct from the Agon's own SD card.
PORT-007 owns the EMOS interface and storage integration.
Future installed-application, media, network-file, or browser interfaces consume
that storage capability without defining its physical backend.

## Hardware design and active evidence

The current P4-PC uses the
[direct PC harness mapping](../hardware/designs/light2-p4pc-harness-draft/README.md)
under BOARD-001. The Author confirms that the migration followed that drawing:
eight Port C data/UART lanes plus PD4 READY_N, PD5 CLOCK and PD7 VALID_N are
connected as specified. GPIO47/48 remain spare, proposed for deferred ZDI recovery.
No four-chip isolation circuit or series resistors are specified in that PC
drawing; pull-resistor rails and sensing-link constraints are recorded there.
This construction report does not establish powered parallel or reverse-transfer
qualification. The former
[DevKit r03 arrangement](../hardware/designs/light2-harness-r03/README.md), including
disconnected handshake lines and a separate keyboard cable, is historical evidence
for that board, not the current PC pin budget.

[ADR-0016](decisions/ADR-0016-v1-transport-electrical-core.md) records the
accepted but **held** four-chip `light2-harness-r02` candidate and provisional
V1 transport core. Its UART/parallel enable groups and hardware-default isolation
belong to that circuit, not the active direct-wire r03 arrangement. Full r02
construction and qualification remain incomplete; its retained connectivity
profile also has the unresolved integrity mismatch recorded by the audit.
Neither this document nor ordinary r03 gameplay authorizes resuming r02 or
silently promotes r03 to the released replacement architecture. HW-001/HW-002
own that reconciliation.

[`light2-harness-r01`](../hardware/designs/light2-harness-r01/README.md)
preserves predecessor forward-prototype evidence. Do not reuse one revision's
pin, probe, isolation or construction assumptions for another. The
[hardware index](../hardware/README.md) identifies their authorities; the
[staged validation process](qualification/staged-circuit-validation.md) governs
newly authorized construction/testing without requiring unrelated firmware work.
Machine-local installed state remains separate from all design records.

## EDU operating modes and application interface

Project terminology distinguishes the **Extended Display Unit (EDU)** exposed
to eZ80 software from the **Extended Display Processor (EDP)** that implements
it on the ESP32-P4. EDU names the command set, API, and logical facility; EDP
names the processor and its firmware. The terms intentionally parallel Agon's
existing VDU and VDP terminology.

The accepted short names are **ExCom** (Exclusive Compatible) and **ExExt**
(Exclusive Extended); **Dual** remains the two-display mode. Transport behavior
is part of the distinction between the exclusive modes, not an independent
policy that silently upgrades ExCom to parallel operation.

| Mode | Ordinary VDU destination and transport | Explicit EDU destination | Implementation boundary |
|---|---|---|---|
| Legacy | Mainboard VDP, stock mainboard UART | Ordinary EDU plane inactive; documented service exceptions remain | Implemented bounded production subset |
| ExCom | P4 EDP over UART; no parallel traffic | Separate EMOS-owned interface to EDP where supported | Implemented bounded production subset |
| ExExt | P4 EDP with enhanced transport for standard VDU commands; eight-bit bidirectional payload target with existing-wire handshake and UART/parallel phases | Separate EMOS-owned interface | Planned; byte timing, handover, integration and compatibility unqualified |
| Dual | Mainboard VDP; never mirrored | P4 EDP, separate result domain | Planned; general EDU interface unimplemented |

ExExt lets existing VDU applications benefit from faster transport without
rewriting their output calls. It does not promise ExCom-equivalent timing or
compatibility: differences may prove small, but require separate qualification.
Keyboard source remains independently selected. The current
[eight-bit candidate decision](decisions/ADR-0026-four-lane-exext-transport.md)
uses the existing dedicated READY/CLOCK/VALID wires for phase handshakes.
PC4–PC7 remain data lanes; PC0–PC3 serve UART between payload phases.
Payload then uses all eight lanes, temporarily excluding UART on the same pins.
EMOS owns admission, its GPIO state and UART handover; P4 firmware owns its
counterpart. Local RAM flags alone do not establish peer readiness or byte
sampling. PORT-008 owns feasibility and recovery; existing wiring is not yet
qualified for this traffic.

The future parallel-capable pair requires a reciprocal pad-release handshake
before EMOS enables shared UART pins after reset. Absent/older P4 firmware leaves
Extender I/O unavailable while mainboard MOS/keyboard remain usable. EMOS must
not reclaim those pins on timeout. Reset invalidates admission state; the current
UART-only firmware is not represented as implementing this candidate boot fence.

Extender-aware programs address the P4 through an explicit, stable, versioned
EDU API owned by EMOS. Synchronous foreground applications may link a client
binding, but that binding invokes EMOS and does not own the transport,
activation, receiver, or lifecycle. Persistent or asynchronous capabilities may
use an explicitly installed resident facility subordinate to EMOS arbitration.

Optional resident facilities do not independently intercept or redirect
`RST.LIL 10h` or `RST.LIL 18h`; the EMOS mode dispatcher alone owns those VDU
paths. Applications must discover and open EDU deliberately through EMOS. EMOS
owns persistent transport state, interrupt-driven reception, queues, client
arbitration, and mode lifecycle. Extend resident EMOS with ordinary compile-time
linking and clear command/service/interrupt boundaries. The current scope
requires no module loader, runtime relocation or restriction to moslet space.
Keep changes small and upstream-reviewable while preserving the EDU contract.
See
[ADR-0014](decisions/ADR-0014-edu-operating-modes-and-service-architecture.md).

In **Exclusive Compatible (ExCom) mode**, the EDP is the sole compatibility display
processor and uses the stock VDP UART transport contract. It owns the
stock-compatible command and response stream while MOS retains canonical VDP
sysvar storage, completion flags, and the mechanism that updates them. The
selected hardware core provides all four eZ80 UART1 signals independently of
the predecessor split-link harness; its exact firmware behavior and physical
qualification remain under HW-001 and PORT-008.

In **Exclusive Extended (ExExt) mode**, the EDP has the same exclusive compatibility
authority and logical MOS/eZ80 integration reach. Enhanced transport remains
planned. The current investigation targets eight-bit payload in both directions,
with handshake/status over the dedicated READY/CLOCK/VALID connections before
and after each bounded parallel phase. EMOS owns CLOCK and VALID in both
directions; P4 owns READY. UART must be quiesced and restored under EMOS/P4 coordination; it cannot
carry control or keyboard bytes concurrently on shared payload pins. Byte timing,
protocol and routing integration remain under PORT-008 and SETUP-005. The older
forward-only circuit remains held evidence. EMOS ownership is unchanged.

Both exclusive modes may claim compatibility only for the declared normal
application-facing surface; Extender v1 explicitly excludes local printer/USB
serial, console/terminal, ZDI, Intel HEX, YMODEM, updater, and debug facilities
unless a later accepted decision restores them. The deferred printer/console/
terminal intentions below refine that exclusion without qualifying an output
binding. EMOS's fixed VDU dispatcher and committed-backend selection are
implemented for the qualified Legacy/ExCom subset. The
[console protocol](protocols/excom-console.md) owns its current activation,
response and lifecycle contract; PORT-003 and QUAL-003 retain wider coverage
and qualification obligations. Do not interpret a working subset as complete
compatibility.

Author clarification, 2026-09-19: Firmware-update commands and Intel HEX/YMODEM maintenance are supported only
through the stock mainboard path in Legacy mode for now. The operator selects
Legacy through EMOS before invoking them; EMOS does not silently forward these
commands from ExCom to mainboard VDP. EDP does not implement their update or
transfer operations. Project-owned SD service, P4 deployment and ZDI recovery
remain separate capabilities. This scope decision does not assert that upstream
has retired or superseded these utilities. Accidental delivery to EDP still
requires defined rejection/consumption behaviour; empty handlers are not thereby
qualified as safe.

In **Dual mode**, the onboard VDP remains authoritative for VDU and MOS VDP
sysvars while the EDP is addressed through EDU and retains results in an
EDU-owned state domain. Applications and project-owned abstraction layers may
coordinate both processors, but ordinary application VDU is never mirrored:
Legacy and Dual route it only to the onboard VDP, and both exclusive modes
route it only to the EDP. Targeted private input/bootstrap control, recovery
diagnostics, and separately identified qualification traffic are not mirrored
application output. Competing writes to canonical sysvars remain unsupported.

Separately identified qualification traffic may originate in an SD-loaded
application that submits a bounded request to resident EMOS. EMOS validates
and owns the complete transport transaction; the application does not access
Extender registers, UARTs or routing state. The visible-text diagnostic keeps
ordinary VDU on the onboard VDP while P4 executes the submitted text through
retained EDP. Sample contents are independent of both firmware images. This
implements the diagnostic exception in ADR-0014 and does not constitute an
additional operating mode or ordinary-VDU route.

EMOS is one complete backward-compatible replacement for stock MOS, not a
side-by-side companion. It is the only supported software authority for
ordinary VDU routing, Extender transport ownership, and committed mode.
Applications, linked EDU bindings, and optional resident services
request those operations through EMOS and do not install independent hooks or
claim UART/GPIO ownership. The proof-of-concept and v1 contract enforce this
across supported software; they do not attempt adversarial isolation from
deliberate eZ80 machine code with unrestricted register and GPIO access. Such
direct manipulation is unsupported caveat emptor. Project hardware and
software still use fail-safe defaults and bounded activation, but make no
non-bricking guarantee for external code that violates this normative contract.

EMOS is also the sole authoritative source of the current formal operating-mode
name. It derives that name only from committed VDU-route and EDP-service state.
EDP/P4 firmware and applications may report their local condition, requested or
pending targets, readiness, transport state, and failures, but may not describe
an uncommitted, failed, or partial combination as Legacy, Dual, Exclusive
Compatible, or Exclusive Extended.

### Mode lifecycle, transition, and recovery

Formal mode is the committed combination of two EMOS-owned logical planes:
ordinary-VDU routing and EDP service. Only these combinations are valid:

| Formal mode | Committed VDU route | Committed EDP service |
|---|---|---|
| Legacy | onboard VDP | inactive |
| Dual | onboard VDP | active |
| Exclusive Compatible | EDP compatible | active |
| Exclusive Extended | EDP extended | active |

An exclusive route with inactive EDP service is invalid. Keyboard-source
selection is independently retained across mode changes under ADR-0014's
2026-09-08 amendment. Keyboard-only P4 activity does not activate the ordinary
EDP/EDU service plane or imply Dual. EMOS alone derives
and names formal mode from the two committed planes; requested, conditionally
pending, failure, and fallback information belongs to lifecycle state rather
than to a fifth formal mode.

Cold boot first reaches fully operational Legacy. Each explicit late
`autoexec.txt` or manual request permits the EMOS coordinator to make at most
one prepare/readiness/commit/recover attempt. EMOS validates every prerequisite
and initializes the complete target before publishing either plane. On a
missing or incompatible prerequisite, EMOS returns or reports a bounded failure
through an available accepted caller or diagnostic path. Any pre-commit failure
restores the current stable mode with routing unchanged and no partial
publication; this routing-coherence guarantee does not depend on preserving the
initiating program or other processor state. For the general mode-service design, a successful presence/version
probe activates EDP and commits Dual; a failed probe leaves Legacy. Exclusive
entry likewise begins in Legacy. Legacy is the mandatory transition hub: EMOS
commits Legacy before attempting a different non-Legacy destination, and no
direct non-Legacy-to-non-Legacy transition is contracted. Live Legacy-to-Dual
and Dual-to-Legacy activation is accepted; an ordinary-VDU route change may
instead use the disruptive transition described below.

Extender v1 uses pull discovery and defines no proactive EDP presence signal.
EMOS selects a reviewed transport/wiring profile, arms the eZ80 receiver, sends
the request, validates the EDP identity, protocol, and capabilities, and alone
commits mode. That handshake establishes protocol readiness; QUAL-002 remains
the authority for electrical and power/reset qualification. EDP asynchronous
traffic requires a negotiated and armed post-activation receiver. P4 reset
revokes that permission, and EMOS quarantines stale traffic.

EMOS uses one fixed set of reset-vector and C-runtime output handlers and one
semantic VDU dispatcher. Each active invocation retains a snapshot of one
committed backend. To change that backend, the EMOS coordinator blocks new
invocations, waits for active calls and owned response work to finish or be
abandoned, reinitializes affected parser state, and commits atomically. The beta
adds no second semantic VDU parser and does not preserve multi-call partial
commands across a disruptive transition.

The first idle-console Legacy↔Exclusive Compatible increment may switch
without rebooting, as accepted in PORT-008-D005. EMOS preserves keyboard
source/layout and presents a fresh destination screen/prompt. It retains
transactional readiness, parser/queue quiescence and bounded failure recovery;
ordinary commands do not authorize in-flight application switching or display
migration. The explicit `--keep-display` application exception below preserves
each processor's own display without migrating assets. The older disruptive controlled-restart baseline
applies outside this bounded exception and remains an acceptable v1 fallback.
Preserving loaded eZ80 program, data, and resident processor state is an
aspirational v1 target and a firm v2 requirement under MODE-001; preservation
never implies migration of display assets between processors. The exact restart
actor and carrier remain open under SETUP-005 F018. A fixed-backend build still
activates explicitly after Legacy startup, and persisted preferred mode is not
a v1 contract. A pending state carried across reset exists only if a selected
implementation requires it; retained cross-boot circuit breaking remains
conditional under MODE-002. Exact lifecycle-state storage and session/shutdown
APIs remain open in SETUP-005.

A successful explicit activation remains latched system state when the
foreground caller exits or no known callers remain. Normal return to Legacy is
an explicit coordinated EMOS shutdown and may refuse or time out if registered
work cannot quiesce. A separately explicit forced shutdown may invalidate work
after warning.

Reset invalidates the affected component's sessions, parsers, pending work,
readiness, and authority even if RAM bytes or another processor survive;
invalidation does not require erasure. eZ80/MOS and whole-system resets return
through Legacy. P4 reset or detected EDP failure in Dual invalidates EDU work
and causes EMOS to commit Legacy while ordinary VDU continues through the
onboard VDP. In an exclusive mode, EDP or transport failure blocks ordinary
VDU, permits only bounded reinitialization, and then disruptively recovers to
Legacy without claiming preservation of application, display, audio, buffer,
or other EDP-visible state. EMOS recovery may use the onboard VDP for a
best-effort diagnostic only after disclaiming that continuity.

EMOS lifecycle records retain requested, conditionally pending, committed,
failure, and fallback information. Structured failure reporting is advisable
during beta and mandatory for v1. It provides best-effort descriptive display
output plus durable machine-readable consequences and safely obtainable
processor context, never relies solely on a failed component when another
accepted sink survives, and never delays safe recovery. The durable P4-flash
crash-log requirement and provisional `coredump` sink are defined below; exact
record behavior and qualification remain with DIAG-001.

Application entry point and operating-mode destination are separate concerns.
`RST.LIL 10h`, `RST.LIL 18h`, and the corresponding C-runtime output paths are
always conventional VDU calls. EMOS routes them to the onboard VDP in Legacy
and Dual, to the EDP stock-compatible backend in Exclusive Compatible, and to
the EDP enhanced backend in Exclusive Extended. Explicit EDU calls remain a
separate versioned interface with a separate result domain, even in an
exclusive mode where both interfaces reach the EDP.

No new RST vector is allocated for EDU. The existing MOS API dispatcher reaches
the resident EMOS gateway through API `0x51`; C-function slot `0x20` is its C
entry. A versioned request identifies the service and input/output buffers;
a client binding may hide that request construction. The maintained
[EMOS gateway contract](https://github.com/bgates747/agon-emos/blob/main/docs/emos-v1-contract.md)
owns the exact ABI. The gateway exists, but general EDU drawing services and
Dual mode do not follow merely from its presence. The same distinction keeps
ordinary VDU queries in the canonical MOS result domain and explicit EDU results
separate. Do not resurrect the cancelled external module/provider loader.

An EDU-aware application may therefore combine VDU and EDU calls without
creating another operating mode. In Dual this intentionally coordinates two
processors; in either exclusive mode it uses two interfaces to the EDP. An
application may also require Exclusive Extended and use conventional VDU
restart calls as its efficient compatible-output path rather than wrapping
every transfer in an EDU invocation. Such a mode-dependent application must
verify or request Exclusive Extended before issuing output that would be unsafe
or meaningless if routed to the onboard VDP.

Every active Extender mode requires EMOS. In Dual, EMOS keeps ordinary VDU on
the onboard VDP while separately activating and arbitrating EDU access to the
EDP. Stock MOS supports only Legacy: Extender remains inactive, and an unknown
Extender command or API may fail normally. Direct linked-client ownership of
UART1, parallel GPIO, interrupt vectors, or EDP lifecycle under stock MOS is
outside the supported architecture.

The accepted buffered r02 design requires hardware-default driver isolation;
the active direct-wire r03 arrangement does not provide those buffer enables.
Do not infer power-domain or contention isolation from software ownership or
pull-up resistors. EDP gates ordinary display activation through the bounded
EMOS exchange. Explicit resident keyboard and foreground SD services have their
own admission and do not implicitly enable ordinary VDU routing. Supported
pre-activation logic patterns or GPIO-direction
changes may be ignored or fail safely without opening another operation. These
rules govern every project-produced design, build,
example, and test. They are not a privilege boundary or warranty for arbitrary
external code that directly manipulates shared GPIO, UART, interrupt, flash, or
routing resources in violation of the EMOS contract; such code may corrupt,
damage, or brick either system. If EDP safely observes unmanaged activity, it
may warn through an Extender-owned display or log only and must not respond over
unactivated Agon-facing wiring.

In **Legacy mode**, the onboard VDP retains ordinary VDU and display behavior,
including maintenance/operator facilities omitted by Extender. Explicitly
selected browser or native USB keyboard input may continue through P4 and EMOS; it is the
accepted exception to older total Extender absence/quiescence requirements.
EMOS retains canonical keyboard state ownership. The foreground mainboard-SD
listener is another explicitly admitted Legacy
service: EMOS owns its transport through `ext.sdlink`, and sdserve performs file
I/O on eZ80. It does not activate the ordinary EDP display/EDU plane or imply
Dual. Other general EDP/EDU service remains inactive. In Dual mode those
facilities may likewise remain available through ordinary VDU
to the onboard VDP; they are not implemented by Extender.

During ExCom, EMOS leaves a static mode/status notice on mainboard VGA and
hides its text cursor with stock VDP commands. Ordinary CLI echo and application
VDU output follow the EDP route. The mainboard VDP keeps scanning out the notice
and generating the retained VBlank clock without periodic EMOS redraws or a
double-buffering requirement. This transition/status output does not mirror
ordinary VDU; Dual retains both displays' active roles.
Initially, returning to Legacy starts a fresh mainboard screen with a visible
cursor and MOS prompt, preserving keyboard source and layout. Clearing the
screen is an initial implementation choice rather than a permanent mode rule.

The formal operating-mode names are **Legacy mode**, **Exclusive Compatible
mode**, **Exclusive Extended mode**, and **Dual mode**. “Compatible” and
“Extended” are accepted short forms in unambiguous operating-mode context, but
“Exclusive” remains part of both official exclusive-mode names.
**ExCom** is accepted conversational shorthand for **Exclusive Compatible**;
the formal name and stable mode identity remain unchanged.

EMOS CLI control uses case-insensitive `EMOS <subcommand>` syntax in both
interactive commands and autoexec. `EMOS EXCOM` and `EMOS LEGACY` request the
named destination mode; `EDU` explicitly addresses Extender functionality while
`VDU` retains ordinary semantics and EMOS-owned routing. The accepted command
contract is in [ADR-0014](decisions/ADR-0014-edu-operating-modes-and-service-architecture.md#cli-and-keyboard-selection--2026-09-08).

`EMOS KEYINPUT mainboard` selects the Agon mainboard keyboard;
`EMOS KEYINPUT extender` selects P4's common input source: native USB, explicit
browser capture or host-agent automation, arbitrated on P4. Browser capture does
not require the historical `EMOS KEYINPUT browser` selector. This supersedes the
earlier browser-input deferral; see [ADR-0022](decisions/ADR-0022-browser-keyboard-capture.md)
and the [keyboard guide](remote-keyboard.md). PORT-015 records native USB
implementation and qualification; REMOTE-001/002 record the remote providers.
With no source argument, the command reports the selected source.
`SET KEYBOARD n` remains the distinct runtime layout selection with the same
effect across modes. `EMOS LEGACY` preserves the selected keyboard source;
returning display output to the mainboard does not shut down selected browser
or P4 USB keyboard input.
Across boots, `autoexec.txt` alone restores these selections. EMOS starts with
mainboard keyboard input; commands at the interactive prompt change runtime
state without saving a separate state/configuration file. No new nonvolatile
settings store is introduced for this increment.

Extender v1 does not inherit the stock VDP's UART0 `DBGSerial` mapping or local
operator facilities. In either exclusive mode, attempts to invoke those paths
must follow stock VDP command consumption and observable failure behavior as
closely as practical. Strict compatibility modes preserve even undesirable
observable stock behavior; other modes should provide improved deterministic
failure and recovery. The exact strict-mode boundary and command-level
semantics are tracked under SETUP-005-D006.

## Firmware build model

Native ESP-IDF/CMake is the accepted outer project, dependency and build
authority. The project retains Arduino-ESP32 as a pinned ESP-IDF component
rather than selecting two competing outer frameworks. BUILD-001 completed the
maintained-path cutover; PlatformIO/SCons remains identified historical rollback
material only.

Arduino preserves the application-level structure expected by official
`agon-vdp`, including its sketch entry point and Arduino-oriented APIs and
libraries. ESP-IDF supplies the lower-level target configuration and native P4
facilities needed for silicon revision handling, memory, partitions, USB,
Ethernet, multimedia peripherals, and future Extender functions.

The native build must prove selected, compiled and linked graph agreement,
configuration/dependency equivalence and bounded physical behavior before it
replaces the operational hybrid build. See
[ADR-0023](decisions/ADR-0023-native-esp-idf-build-authority.md).

FreeRTOS supplied by ESP-IDF remains the firmware concurrency substrate.
Extender replaces inherited ESP32-PICO watchdog disabling and core-placement
assumptions with one explicit P4-native policy. Operating modes may change
which tasks run and how they are supervised; strict compatibility governs
externally observable reset and failure behavior rather than requiring obsolete
watchdog internals. Exact task affinity, subscriptions, timeouts, and controlled
resets require subsystem-specific qualification.

Arduino PSRAM and ESP-IDF capability-aware allocation remain the underlying
memory substrate, preserving explicit selection of external, internal,
DMA-capable, and other constrained memory. The compatibility baseline does not
preclude future compile-time performance profiles that exploit P4 resources at
the cost of legacy behavioral fidelity. EDU-aware applications must discover
the active profile's advertised capabilities rather than infer them.

The input choices are Agon-mainboard or Extender-connected keyboard input. P4 acquires one directly attached USB HID boot keyboard,
translates its events into retained stock VDP keyboard semantics and emits
normal VDP keyboard packets to EMOS over the existing r03 four-signal UART1 link at
1,152,000 baud, 8N1 with RTS/CTS. Keyboard configuration/query traffic uses the
same UART in the Agon-to-P4 direction. No parallel transfer or direct
onboard-VDP/EDP link is required for this capability.

EMOS owns the selected input ingress and stock-compatible packet handling.
P4 sends keyboard events/settings, not MOS memory: EMOS updates its own key
sysvars, event counter, virtual keyboard map and application keyboard hooks
through the stock handling semantics. Ordinary applications continue to use
MOS keyboard APIs, sysvars and the keymap; they do not forward input to P4 or
configure UART1. Browser/P4 session messages are distinct from the stock VDP
wire contract and do not introduce a proprietary UART keyboard envelope.

An explicit `EMOS KEYINPUT extender` command enables native USB input through
P4; `EMOS KEYINPUT mainboard` selects the mainboard VDP's keyboard path. EMOS
admits only the selected keyboard source and continues handling the mainboard
VDP's other communications. Source selection is independent of display mode;
autoexec alone restores the desired selection after reboot. Source changes
release held state before admitting the new source; no dual-keyboard mixing
is selected.

Browser input follows [ADR-0022](decisions/ADR-0022-browser-keyboard-capture.md).
P4 admits one controlling browser session at a time. Explicit Capture overrides
host-agent input; a physical USB keypress overrides browser and agent input.
P4 releases the displaced provider's held keys and discards its pending events
before admitting the new provider. Latest explicit browser Capture wins among
browser sessions; opening/reconnecting a page alone does not take ownership.
Input-socket loss, focus loss or explicit release revokes browser capture;
video-only disconnect does not. Reacquisition is explicit. Human browser key
transitions are not subject to the host-agent API's 20 ms pacing policy.

Session admission and revocation precede stock packet delivery. The selected
browser session is a keyboard authority, including normal stock key effects;
focus is a capture condition, not authentication. EMOS retains input-source
selection and canonical-state ownership. EMOS uses interrupt-driven UART1 reception with packet assembly separate from
UART0; the receive streams must not race or splice parser state. The precise session and ingress mechanisms are
owned by SETUP-005, REMOTE-001, PORT-006, PORT-008 and agon-emos INTEG-009.

Physical PS/2 keyboard/mouse acquisition remains on the onboard VDP where
those devices are used. It is not a relay for browser keys. The accepted bench
clock remains the onboard VDP's VBlank/PB1 path. Native USB input uses the
[specified USB keyboard connection](../hardware/designs/light2-harness-r03/README.md#usb-keyboard-addition--2026-09-09).
It does not replace VBlank or itself change ordinary VDU routing. A bounded
qualification session has explicit entry/exit; it does not
claim complete Exclusive Compatible mode; Legacy permits the explicitly
selected keyboard service described above.

For the selected directly attached USB keyboard, P4 receives
USB HID reports through its native host controller, translates them into
ordered processed keyboard events and sends stock keyboard packets through
the same EMOS-owned UART1 session. Explicit `EMOS KEYINPUT extender` selection
controls this path independently of browser focus/network and display mode.
Initial scope is one wired HID boot-protocol keyboard with normal EMOS CLI on
mainboard VGA. USB removal releases held state; it is not browser lease expiry.
No implicit browser/USB mixing or new UART keyboard packet format is selected.

P4's processed-input adapter owns EDP-local keyboard variables, relevant
callbacks, control-key and paged-mode behavior and stock packet generation.
Later Agon-originated EDU event forwarding retains its non-echo rule; browser
keys are original events and must be emitted toward EMOS. Mouse injection and
full mode-specific input composition remain separate scope.

Physical vdp-gl keyboard/mouse drivers, PS/2 controllers, scan-code tasks and
device controls stay vendored but excluded from the P4 build. The browser
adapter reuses stock virtual-key/event vocabulary and applicable pure mapping
semantics without depending on physical PS/2 hardware. Direct USB keyboard
input may use the selected P4 DevKit's existing native host plus the required
USB connector and power assembly. This permission does not restore the omitted
PS/2 engines or select other peripheral expansion.

Extender retains ESP-IDF's OTA image, boot-partition, rollback, and restart
lifecycle as the low-level update substrate. This is independent of the omitted
stock VDP serial updater and does not select an update transport. A project-
owned replacement is warranted only if evidence shows the ESP-IDF facilities
are materially inferior to sound clean-sheet ESP32-P4 practice.

Extender networking is project-owned. The P4 DevKit's native wired Ethernet is
the primary Rev 1 backend; the dedicated-header Olimex MOD-WIFI-ESP8266 is an
optional Rev 1 wireless backend whose P4-to-module protocol and module firmware
must be selected and qualified separately. The dormant vendored vdp-gl ICMP
helper is excluded from the P4 build: it assumes a local Arduino WiFi/raw-lwIP
interface and is not an adapter for a separate ESP8266 network processor.

The initial build pins pioarduino platform release `55.03.311`, which combines
Arduino-ESP32 3.3.11 with ESP-IDF 5.5.5. A moving release alias or development
branch is not an acceptable reproducible baseline. See
[ADR-0003](decisions/ADR-0003-pioarduino-platform-baseline.md).

The Rev-D1 development board's v1.3 ESP32-P4 is represented as the pre-v3
`esp32p4_es` platform variant. SDK configuration explicitly limits compatible
full revisions to 100 through 199, and board qualification reports and checks
the runtime revision. See
[ADR-0004](decisions/ADR-0004-p4-silicon-identity.md).

The primary board environment configures the 16 MB SPI flash for QIO at
80 MHz. This is a qualification candidate until cold-boot, reset, reflash, and
flash-integrity tests pass on the physical board. DIO at 80 MHz is the defined
fallback if QIO proves unreliable. See
[ADR-0005](decisions/ADR-0005-flash-bus-mode.md).

The board definition uses a conservative 512,000-byte internal-RAM link budget
and declares external PSRAM separately. The 32 MB PSRAM operates in hexadecimal
mode at 200 MHz and is intended for explicit bulk allocation; it is not treated
as interchangeable with internal SRAM. Bring-up verifies its capacity and runs
a memory test. See [ADR-0006](decisions/ADR-0006-board-memory-model.md).

The 16 MB flash contains two equal 7 MiB OTA application slots. A candidate
image is written to the inactive slot and must pass an explicit post-boot health
check before it is marked valid; otherwise the bootloader rolls back. There is
no separately maintained factory application. Required NVS, OTA metadata, and
crash diagnostics use the leading data area, and the approximately 1.9 MiB
remainder stays reserved until a durable use is approved. See
[ADR-0007](decisions/ADR-0007-flash-partition-strategy.md).

V1 requires a bounded durable crash-log sink in the P4's onboard flash so
mainboard failure evidence never depends on an optional microSD card. The
dedicated `coredump` partition is the initial candidate and must be validated
for the versioned Extender record, native ESP-IDF crash evidence, integrity,
interrupted writes, and wear limits. P4 microSD may provide richer optional
history or exports. Browser or local video may present a surviving
human-readable report but is not durable by itself. Diagnostic persistence must
never delay safe recovery.

Native ESP-IDF/CMake is the accepted sole top-level build authority for
maintained P4 firmware. Arduino-ESP32 remains a pinned ESP-IDF component so the
upstream-compatible VDP lifecycle and Arduino APIs do not require a runtime
rewrite. One neutral checked-in manifest owns buildable profiles and selected
project sources; a project-owned wrapper binds pinned project-scoped ESP-IDF
source/tools, fresh profile output, dependency locks and build identity. The
native CMake/Ninja graph must compile and link the same declared source closure,
and its compilation database is authoritative only after validation against the
linked objects. See
[ADR-0023](decisions/ADR-0023-native-esp-idf-build-authority.md).

BUILD-001 implemented that accepted direction after host and hardware
equivalence. `scripts/vdp-pio.sh` now fails closed unless an operator explicitly
acknowledges a bounded historical rollback reproduction. Neither the cutover nor
a development build changes the selected production bundle.

The primary Rev-D1 pre-v3 board environment configures the CPU at 360 MHz. A
forced 400 MHz candidate repeatedly asserted during clock initialization on the
attached rev 1.3 silicon and is rejected for this hardware profile. See
[ADR-0010](decisions/ADR-0010-cpu-frequency.md).

### Explicit application display preservation

For paired graphics inspection, applications use public mos_oscli to request
`EMOS LEGACY --keep-display` and `EMOS EXCOM --keep-display` at complete
VDU/query boundaries. Mainboard VDP and EDP each retain their own mode, scene
and resources; EMOS changes the committed route and reply authority through
its coordinator without clearing those scenes or drawing a mode notice. USB
source selection and the mainboard clock remain independent. Default console
switch commands keep their fresh-display behavior. ADR-0014 records this
bounded extension; it does not authorize direct application transport access.

## Browser-video encoding and pacing

EDP composes the final pixels on P4. The [browser-video contract](protocols/browser-video.md)
owns presentation transport encoding and pacing: RGB222 saves threefold payload
relative to RGB888, browser WebGL expands colours, and bounded frame credits
control delivery without a fixed 5 fps throttle. Logical VDP time remains
independent of network/browser progress. Hardware qualification of the new
encoding and pacing is tracked in PORT-003.

### Deferred Extender firmware update path — 2026-09-20

Current stock maintenance support remains Legacy-only. Functional P4 EDP
updating using the stock &A1 interface is a deferred production direction,
under EMOS-owned routing and explicit update targeting. Both implementation
and discard-only repairs are deferred; this does not qualify today's empty
handler. ADR-0014 and PORT-003-D015 record the scope and research.

### Deferred printer output intent — 2026-09-20

VDU 1/2/3 remain desired serial debugging/output facilities for EDP, rather than
intentional discard-only commands. Their P4 output binding is not yet selected
or qualified. Research and likely implementation are deferred; this is not a
v1 delivery commitment. ADR-0014 and PORT-003-D016 refine the earlier exclusion.

Console (&FE) and terminal (&FF) modes share the deferred printer-output scope:
possible future serial facilities, with one endpoint/coexistence review before
implementation. Current P4 behavior and EMOS route authority remain unchanged;
no implementation or qualification is implied (PORT-003-D017).

### Foreground EMOS utilities

Resident EMOS retains gateway, transport, keyboard and display-mode ownership.
The accepted `/emos/<name>.bin` foreground MOSlet dispatch follows
[ADR-0014](decisions/ADR-0014-edu-operating-modes-and-service-architecture.md):
built-ins first, idle CLI only, ordinary fixed-address MOSlet format. Cancelled
external `.emo` provider loading is retired; no background module framework is
introduced. Implementation and validation are tracked in
[AUDIT-008](tasks/AUDIT-008.md).

### Planned browser file access

The browser file-management trial for mainboard SD is parked as a fallback,
including bulk selection and whole-directory operations. The browser uses P4
HTTP and EMOS-owned mainboard service access. Final interface selection is reopened after usability review. Library selection
and added operations remain investigation scope; this is not implemented browser behavior.
See [the decision](decisions/ADR-2026-09-27-browser-file-access.md).

### Bounded direct RGB888 experiment

The explicitly selected RGB-001 experimental P4-PC HDMI build may replace the
mode20/8/13664-colour logical storage with BGR888 rows in the LCD-owned720p
buffers while retaining colour semantics, EMOS routing and the independent frame
clock. The row spacing is3840bytes. Double-buffer swaps release the former front
only after DMA adopts the completed back; physical scrolling moves pixel contents.
Ordinary builds retain native storage. The initial separate-plane/copy variant
remains retained evidence. This scoped experiment is recorded in
[ADR-0025](decisions/ADR-0025-rgb888-rendering-experiment.md); production selection
and performance acceptance remain separate. Double-buffer overlay changes are
presented with explicit application swaps; autonomous overlay timing remains
outside this variant's qualified scope.

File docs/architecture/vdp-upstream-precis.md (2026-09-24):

# Official VDP Architecture Précis

Status: Draft for Author review  
Source baseline: AgonPlatform/agon-vdp release `v2.16.0`,
[`c7ac293d2aa81ddfa693390549bcd909069c8fc3`](https://github.com/AgonPlatform/agon-vdp/commit/c7ac293d2aa81ddfa693390549bcd909069c8fc3),
verified as the latest official tag on 2026-08-20

## Scope
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

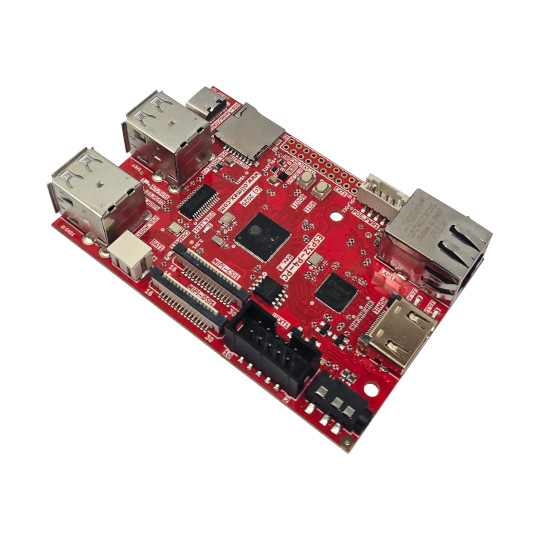
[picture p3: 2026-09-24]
docs/hardware/esp32-p4-pc/upstream/DOCUMENTS/ESP32-P4-PC-1.jpg

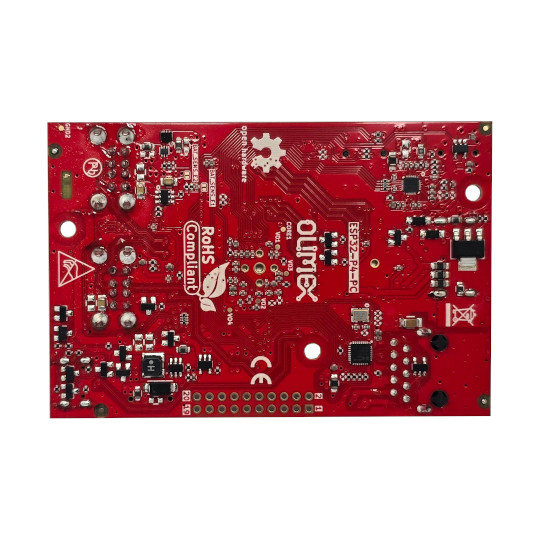
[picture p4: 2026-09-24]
docs/hardware/esp32-p4-pc/upstream/DOCUMENTS/ESP32-P4-PC-4.jpg

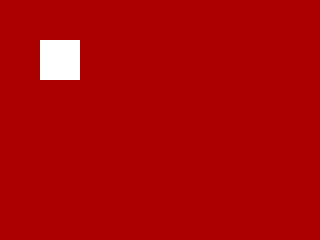
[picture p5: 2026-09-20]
docs/tasks/QUAL-004/page-controls/evidence/PAGE_FRONT/mainboard.png

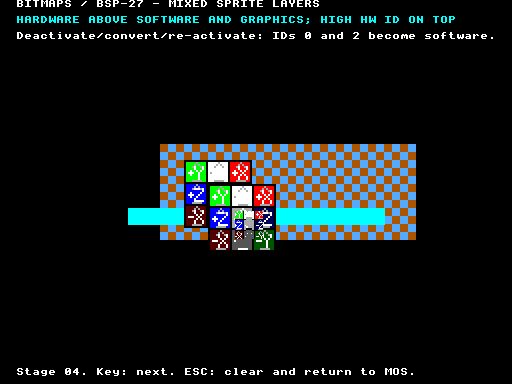
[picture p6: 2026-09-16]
docs/tasks/QUAL-004/evidence/bounded-corpus/BSP27_04-a1/BSP27_04/mainboard.png

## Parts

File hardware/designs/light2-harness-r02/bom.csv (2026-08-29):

line_id | quantity | uom | category | references | product_name | manufacturer | manufacturer_part_number | value | package | procurement_spec | role
ic-sn74lvc244an | 2 | each | integrated-circuit | U1;U2 | TI SN74LVC244AN octal buffer | Texas Instruments | SN74LVC244AN | SN74LVC244AN | PDIP-20 | Exact part number; N suffix is the through-hole PDIP package. | Agon-powered forward UART, parallel-data, CLOCK, and VALID_N buffering.
ic-sn74lv125an | 2 | each | integrated-circuit | U3;U4 | TI SN74LV125AN quad buffer | Texas Instruments | SN74LV125AN | SN74LV125AN | PDIP-14 | Exact part number; N suffix is the through-hole PDIP package. | Agon-powered UART return and P4-powered low-only isolated controls.
resistor-220r-1pct | 13 | each | resistor | R1;R2;R3;R4;R5;R6;R7;R8;R9;R10;R11;R12;R13 | 220 ohm 1% through-hole resistor |  |  | 220 ohm | axial through-hole | 220 ohm, 1% tolerance or better; breadboard-compatible lead size. | Replaceable source-series protection and damping on every driven transport output.
resistor-47k-1pct | 8 | each | resistor | R14;R15;R16;R17;R18;R19;R20;R21 | 47 kilohm 1% through-hole resistor |  |  | 47 kohm | axial through-hole | 47 kilohm, 1% tolerance or better; breadboard-compatible lead size. | P4 data and shared-UART inactive-state bias.
resistor-10k-1pct | 10 | each | resistor | R22;R23;R24;R25;R26;R27;R28;R29;R30;R31 | 10 kilohm 1% through-hole resistor |  |  | 10 kohm | axial through-hole | 10 kilohm, 1% tolerance or better; breadboard-compatible lead size. | CLOCK, VALID_N, READY_N, output-enable, and P4 control default-state bias.
capacitor-100nf-ceramic | 4 | each | capacitor | C1;C2;C3;C4 | 100 nF ceramic bypass capacitor |  |  | 100 nF | radial through-hole | Nonpolar ceramic, at least 6.3 V rating, breadboard-compatible lead spacing. | One local supply bypass capacitor at each logic IC.
capacitor-1uf-ceramic | 2 | each | capacitor | C5;C6 | 1 uF ceramic bulk capacitor |  |  | 1 uF | radial through-hole | Nonpolar ceramic, at least 6.3 V rating, breadboard-compatible lead spacing. | One local bulk capacitor for each independent 3.3 V power domain.

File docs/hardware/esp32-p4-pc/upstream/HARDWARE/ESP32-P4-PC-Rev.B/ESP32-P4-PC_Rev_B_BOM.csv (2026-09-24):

Id | Designator | Footprint | Quantity | Designation | Supplier and ref
1 | C73,C72 | C_0402_5MIL_DWS | 2 | NA(27pF/50V/5%/C0G/C0402)
2 | FET7,FET8,FET4,FET3,FET6,FET5 | SOT23 | 6 | BSS138(SOT-23)
3 | +5V1,DC_VIN1,GND1,+5V_POE1,VBAT1,+5V_EXT1,+5V_USB1,3.3V1,VO4,GND2,CORE1,VO2,VO3,VO1 | TESTPAD_40-ROUND | 14 | TESTPAD
4 | R86,R64,R85,R48,R83,R70,R42,R43,R67,R27,R55,R66,R102,R68,R54,R41,R3 | R_0402_5MIL_DWS | 17 | 10k/R0402
5 | USB-Serial/JTAG1 | USB2.0_TYPE-C(A40-00119-A52-12)_Paste | 1 | USB-C-16P-F(A40-00119-A52-12)
6 | MIPI-CSI1,MIPI-DSI1 | TE_1-1734248-5 | 2 | FPA-VZA2-15-LF
7 | HDMI1 | HDMI-SWM-19_Paste | 1 | HDMI-SWM-19
8 | USER_LED1,LED_LINK1,LED_HOST3,LED_HOST4,LED_HOST2,LED_HOST1 | LED_0603_KA | 6 | LED/GREEN/0603
9 | C28,C27 | C_0402_5MIL_DWS | 2 | 150pF/50V/2%/NP0/C0402
10 | C38,C107,C106,C105,C95,C30,C21,C19,C7,C52,C91,C109,C112,C108,C111,C69,C4,C121,C96,C40,C53,C87,C51,C85,C46,C5,C23,C119,C42,C131,C57,C11,C49,C43,C12,C47,C32,C9,C101,C128,C94,C115,C120,C54,C31,C71 | C_0402_5MIL_DWS | 46 | 100nF/10V/20%/X5R/C0402
11 | C114,C113,C25,C80,C81,C79,C24 | C_0402_5MIL_DWS | 7 | 27pF/50V/5%/C0G/C0402
12 | BOOT1,RST1 | YTS-A016-X | 2 | YTS-A016-X
13 | R21,R12,R69,R11,R7,R10,R33,R49,R22,R37 | R_0402_5MIL_DWS | 10 | 4.7k/R0402
14 | R74,R84,R73,R88,R8,R72,R9,R91,R4,R39,R61,R82,R93,R92,R62,R56,R57,R80 | R_0402_5MIL_DWS | 18 | 2.2k/R0402
15 | R94,R90,R96 | R_0402_5MIL_DWS | 3 | 470k/R0402
16 | R26,R15,R16,R14,R25,R38 | R_0402_5MIL_DWS | 6 | 22R/R0402
17 | L4,L3 | L_2016_MM | 2 | 1.0uH/4.2A/DCR=35mR/20%/2.00x1.60x1.00mm/L2016(PIM201610-1R0MTS00)
18 | C14,C65,C74,C129,C133,C134,C136,C118,C132,C93,C130,C92 | C_0805_5MIL_DWS | 12 | 47uF/6.3V/20%/X5R/C0805
19 | C35,C102,C103,C123,C63,C75,C37,C124,C66 | C_0603_5MIL_DWS | 9 | 22uF/6.3V/20%/X5R/C0603
20 | Q6,Q2 | TSX-3.2x2.5mm_GND(3) | 2 | Q25MHz/18pF/30ppm/4P/3.2x2.5mm(ABM8-25.000MHZ-D2Y-T)
21 | Q3 | TSX-3.2x2.5mm_GND(3) | 1 | Q40.000MHz/12pF/10ppm/4P/3.2x2.5x0.70mm(Harmony_Electronics_CORP./HSX321S)
22 | R87 | R_0402_5MIL_DWS | 1 | 1M/R0402
23 | C1,C45,C2,C44 | C_0402_5MIL_DWS | 4 | 22pF/50V/5%/C0G/C0402
24 | LED_ACT1,CHARGE1 | LED_0603_KA | 2 | LED/Yellow/0603
25 | UEXT1 | GBH-254-SMT-10 | 1 | P-B-V-10-LF
26 | Q1 | CM7V-T1A(Crystal_Package-1206_3.20x1.50x0.65mm) | 1 | Q32.768kHz/12.5pF/2P/SMD1206
27 | U1 | QFN104_10mm×10mm_Pitch_0.35mm | 1 | ESP32-P4NRWxx(QFN104)
28 | R46,R47 | R_0402_5MIL_DWS | 2 | 10.5k/1%/R0402
29 | U9,U10,U11 | SLP2510P8_TEST | 3 | NA(RCLAMP0524P(SLP2510P8))
30 | C29,C6,C18,C67,C82,C99,C3,C56,C22,C68,C20,C50,C70,C76,C41 | C_0402_5MIL_DWS | 15 | 10uF/6.3V/20%/X5R/C0402
31 | C16,C15 | C_0603_5MIL_DWS | 2 | 100nF/50V/20%/Y5V/C0603
32 | U7 | SSOP28_10x4mm_Pitch_0.64mm | 1 | FE1.1s(SSOP-28)
33 | R63,R32,R19,R81 | R_0402_5MIL_DWS | 4 | NA/R0402
34 | USB_HOST3-4,USB_HOST1-2 | USB_TWO_LEVEL | 2 | USBB1-FRWH-4A(USB-Ax2)
35 | BAT1 | PH2.0-2AT(BAT) | 1 | PH2.0-2AT
36 | R76 | R_0402_5MIL_DWS | 1 | 6.04k/1%/R0402
37 | FID2,FID4,FID6,FID8 | Fiducial1x3_Paste | 4 | Fiducial
38 | U3 | SO-8_208mil | 1 | W25Q128JVSIQ(16MB)
39 | PWR1,ACT/SUS1 | LED_0603_KA | 2 | LED/RED/0603
40 | U5,U4 | SOT-563-6 | 2 | TPS62A02ADRLR(SOT-563-6)
41 | U12 | QFN64_7.5x7.5mm_Pitch_0.4mm | 1 | LT8912B(QFN64)
42 | R36 | R_0402_5MIL_DWS | 1 | 220k/R0402
43 | LAN1 | RJP-003TC1(LPJ4112CNL) | 1 | RJP-003TC1(LPJ4112CNL)
44 | R65,R75,R71 | R_0402_5MIL_DWS | 3 | 100k/R0402
45 | Q4 | TSX-3.2x2.5mm_GND(3) | 1 | Q12MHz/18pF/30ppm/4P/3.2x2.5mm(ABM8-12.000MHZ-D2Y-T)
46 | MICRO_SD1 | TFC-WPAPR-08 | 1 | TFC-WPAPR-08-LF
47 | L1,L7,L8,L2,L5,L6 | L_0805_5MIL_DWS | 6 | 600OHM/2A/UPZ2012E-601-2R0TF/0805
48 | HEADSETS1 | PJ-320D | 1 | PJ-320D
49 | C117 | CPOL-RM3.5mm_8.0x11.5mm_PTH | 1 | 1000uF/10V/20%
50 | POE_PWR1 | PH2.0-4PLB | 1 | PH2.0-4AT
51 | C62,C59 | C_0402_5MIL_DWS | 2 | NA(120pF/50V/5%/C0G/C0402)
52 | EXT1 | HN2x10 | 1 | NA(HN2x10)
53 | C60,C33 | C_0402_5MIL_DWS | 2 | NA(100nF/10V/20%/X5R/C0402)
54 | MH1,MH2,MH3 | Mounting_Hole_Drill-3.3mm_Clerance-7mm | 3 | Mounting_Hole_NPTH
55 | FID3,FID1,FID7,FID5 | Fiducial1x3 | 4 | Fiducial
56 | R13 | R_0402_5MIL_DWS | 1 | 10M/R0402
57 | DCDC_Vin1 | SJ_2_SMALL_12_TIED | 1 | Closed(1-2)
58 | C110 | C_0402_5MIL_DWS | 1 | 2.2nF/50V/10%/X7R/C0402
59 | PWR_SENS_E1,BAT_SENS_E1,BAT_SENS_E2 | SJ_1_SMALLER | 3 | Opened
60 | C61,C36,C88,C48,C97,C84,C55,C58,C98,C39,C86,C100,C10,C126,C104,C8 | C_0402_5MIL_DWS | 16 | 1uF/6.3V/10%/X5R/C0402
61 | R5,R6 | R_0402_5MIL_DWS | 2 | 5.1k/1%/R0402
62 | R103,R89 | R_0402_5MIL_DWS | 2 | 6.81k/1%/R0402
63 | C125,C135,C90,C89,C127,C116 | C_0805_5MIL_DWS | 6 | NA(47uF/6.3V/20%/X5R/C0805)
64 | R2,R1 | R_0402_5MIL_DWS | 2 | 4.02k/1%/R0402
65 | U15 | SOT-23-5 | 1 | TP4054-42-SOT25-R(SOT23-5)
66 | C122,C34,C64 | C_0603_5MIL_DWS | 3 | NA(22uF/6.3V/20%/X5R/C0603)
67 | R50 | R_0402_5MIL_DWS | 1 | 110R/1%/R0402
68 | R35,R34 | R_0402_5MIL_DWS | 2 | 1.5k/R0402
69 | R78 | R_0402_5MIL_DWS | 1 | NA(200R/R0402)
70 | L9 | L_0805_5MIL_DWS | 1 | NA(600OHM/2A/UPZ2012E-601-2R0TF/0805)
71 | R29,R30 | R_0402_5MIL_DWS | 2 | NA(2.2k/R0402)
72 | L11 | CD42(43) | 1 | 4.7uH/2.33A/DCR=70mR/20%/CD43(NRS4018T4R7MDGJ)
73 | D4 | SMA-KA | 1 | 1N5822/SS34/SMA
74 | R17 | R_0402_5MIL_DWS | 1 | 6.19k/1%/R0402
75 | R77 | R_0402_5MIL_DWS | 1 | 10R/R0402
76 | R52 | R_0402_5MIL_DWS | 1 | 240R/1%/R0402
77 | R53 | R_0402_5MIL_DWS | 1 | 2.7k/1%/R0402
78 | C26,C83 | C_0402_5MIL_DWS | 2 | NA(10uF/6.3V/20%/X5R/C0402)
79 | D2,D3 | SOD-123_1C-2A_KA | 2 | 1N5819S4(SOD123)
80 | Q5 | SOT23 | 1 | BC817-40
81 | VR2 | SOT-23-5 | 1 | AP1231-3.3V(SOT23-5)
82 | R24,R105 | R_0402_5MIL_DWS | 2 | 24.9k/1%/R0402
83 | R28,R18 | R_0402_5MIL_DWS | 2 | NA(10k/R0402)
84 | R95 | R_0402_5MIL_DWS | 1 | 8.25k/1%/R0402
85 | VR1 | SOT223 | 1 | LD1117AG-AD-AA3-A-R
86 | C77,C78 | C_0402_5MIL_DWS | 2 | 20pF/50V/5%/NP0/C0402
87 | R45 | R_0402_5MIL_DWS | 1 | 6.49k/1%/R0402
88 | R51 | R_0402_5MIL_DWS | 1 | 49.9k/1%/R0402
89 | R59,R58,R60 | R_0402_5MIL_DWS | 3 | 33R/R0402
90 | U6 | SOT23-6 | 1 | CH217K(SOT23-6L)
91 | U14 | SOT23-6 | 1 | MT3608(SOT23-6)
92 | R23 | R_0402_5MIL_DWS | 1 | NA(4.7k/R0402)
93 | R31 | R_0603_5MIL_DWS | 1 | 0R/R0603
94 | U2 | QFN32_EP(33)_4.00x4.00x0.80mm_Pitch_0.40mm | 1 | IP101GRR(32-PIN_QFN)
95 | C17 | C_1206_5MIL_DWS_ISO | 1 | 1nF/2000V/10%/X7R/C1206
96 | R98 | R_0402_5MIL_DWS | 1 | 1.05k/1%/R0402
97 | R40 | R_0402_5MIL_DWS | 1 | NA(0R/R0402)
98 | R79 | R_0402_5MIL_DWS | 1 | 200R/R0402
99 | U16,U13 | SOT-5X3 | 2 | TPS2116
100 | RM2 | RA0805_(4X0402)_xx_BIGGEROUTPADS | 1 | RA0805_(4X0402)_33R
101 | U8 | QFN-20_EP(21)_3x3x0.6mm_Pitch_0.4mm | 1 | ES8311(QFN-20)
102 | RM1 | RA0805_(4X0402)_xx_BIGGEROUTPADS | 1 | RMAT_(4x0402)_4.7k
103 | TVS1 | SOT-23-5 | 1 | ESDS314DBVR(SOT-23-5)
104 | C13 | C_0402_5MIL_DWS | 1 | 4.7uF/X5R/20%/10V/C0402
105 | FET1 | SOT23 | 1 | IRLML6402(SOT-23)
106 | R44 | R_0402_5MIL_DWS | 1 | 30.1k/1%/R0402
107 | R20 | R_0402_5MIL_DWS | 1 | NA(10M/R0402)

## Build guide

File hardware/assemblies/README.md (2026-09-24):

# Hardware assembly configurations

This directory records reproducible physical assembly configurations. An
assembly revision selects an electrical design revision and describes how that
design is physically realized. It does not replace the selected design's
connectivity authority.

## Recorded assemblies and current applicability

| Record | Applicability |
|---|---|
| [r01](light2-extender-solderless-assembly-r01/README.md) | Preserved first prototype, not the current r03 wiring map |
| [r02](light2-extender-solderless-assembly-r02/README.md) | Held incomplete buffered construction; no complete-circuit qualification |

The active simplified r03 wiring has no complete replacement assembly record
here. [HW-002](../../docs/tasks/HW-002.md) owns that gap and the deferred USB
drawing update; the [hardware index](../README.md) owns current applicability.
Do not label the live bench as either recorded assembly merely because those
are the available profile files.

## Specimens and revisions

An individual board on the bench is a specimen of an assembly revision. Its
private serial identity, location, and live attachment state remain in ignored
machine-local records. Qualification manifests use safe specimen aliases and
select both the exact assembly and electrical-design revisions.

Moving a conductor or component, changing a breadboard coordinate, changing a
connector or wire construction, or making another physical change that may
affect reproduction or test results advances the assembly revision. A separate
electrical-design revision is also required when that change alters the
selected connectivity or electrical properties.

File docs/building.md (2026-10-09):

# Building Extender components

Compile entry points and the accepted combination are indexed by the
[production selection](../production/README.md). The r55 clean build passed bounded
physical and Author review. This is not a fresh-machine installation qualification
or permission to deploy. Read the
[provenance boundary](#deployed-candidates-versus-the-base-target) before selecting
a replacement for an installed image, and the [operation entry point](using-extender.md)
before using an existing bench.

## Building the P4 firmware

Native ESP-IDF/CMake is the sole maintained outer build authority. Arduino-ESP32
3.3.11 remains a pinned ESP-IDF component. The project-scoped ESP-IDF 5.5.5
source, Python environment and tools are provisioned under ignored
`agents/build001/native-tools/`; the exact ESP-IDF commit is enforced by the
wrapper. Use **`p4-console` explicitly** and a fresh output path:

```sh
.venv/bin/python scripts/build_p4.py \
  --profile p4-console \
  --output agents/builds/console-local \
  --build-id UNVERSIONED-DO-NOT-DEPLOY
```

`p4-console` is the minimal ordinary product-development profile. Its manifest
records required definitions separately from default-off historical diagnostics
and rejected experiments; the builder rejects overlap, and the action validator
rejects excluded definitions on compiled sources. Do not enable a diagnostic or
experiment by editing the ordinary profile. A recurring diagnostic requires an
explicitly named profile and owning task contract.

The same manifest declares the selected stock-shaped display family as the
single product display owner. `p4-port008-nonrelease-qualification` selects a
different, older family solely to close PORT-008's bounded provenance and
retained-parser work; it is not a product, deployment, fallback or repair
target. The builder rejects mixed display families, a second product owner, or
a non-release family without an explicit task owner and retirement contract.
Do not copy a product display fix into the non-release family.

An identified build uses a project-approved ID in place of the unversioned
sentinel and requires a clean committed checkout. The wrapper rejects an
existing output, a wrong ESP-IDF checkout, unsafe manifest paths, unsupported
profiles and dirty identified inputs. It generates disposable CMake component
files, invokes IDF/Ninja, validates declared/compiled/archived/linked agreement,
and writes a manifest, dependency lock, effective SDK configuration, build log,
section report, validation report, canonical compilation database, ELF, map,
individual flash segments and offset-zero factory image.

Use optional `--reset-url "$RESET_BRIDGE_URL"` to configure the browser reset
bridge. The default is unset, leaving the reset button disabled. The endpoint is
recorded only by hash in the local manifest and inserted into the generated
embedded page; never commit a private endpoint. Request pacing is unchanged; the browser requests
`?rle2=1&packed=2` for the retained lossless compression selection.

After building, with Playwright and Chromium installed in the local environment:

```sh
.venv/bin/python tests/browser_bundle_test.py \
  --build-output agents/builds/console-local
```

This checks actual embedded asset bytes, browser negotiation and paired codec
outputs without a board connection. It does not measure P4 performance.
[prepare_console.py](../scripts/prepare_console.py) is only a compatibility name
that delegates ordinary console builds to the native wrapper. The old
[PlatformIO wrapper](../scripts/vdp-pio.sh) is retained for accepted bounded
reproduction of identified hybrid evidence and fails unless its historical-use
acknowledgement is supplied.

### Board selection and compile-time pin mapping

The native builder selects hardware independently of the software profile:

```sh
.venv/bin/python scripts/build_p4.py \
  --profile p4-console --board p4-pc \
  --tools-path "$P4_IDF_TOOLS" --python-env "$P4_IDF_PYTHON_ENV" \
  --output agents/builds/pc-local \
  --build-id UNVERSIONED-DO-NOT-DEPLOY
```

Set the two tool variables to host-native installations. Migrated x86 compiler
executables cannot run on the Pi ARM64 host; the wrapper checks executability
before creating output. Neither option changes the pinned ESP-IDF checkout or
managed component versions. Machine-local tool locations belong in
`HARDWARE.local.md`, not board profiles.

Omitting `--board` retains `p4-devkit`. The revisioned configuration files under
[`vdp/build/boards`](../vdp/build/boards/README.md) are the native hardware-input
authority. `p4-pc` currently supports only `p4-console`; recovery and historical
buffered parallel qualification remain DevKit-only. The builder rejects unknown
boards, unsupported compositions and invalid/conflicting GPIO allocations.

Each output contains `board.json` and the generated
`project/components/agon_vdp/agon_extender_board_config.hpp`. Shared C++ code
uses that header for UART routing, its startup input fence and TX cancellation,
Ethernet, local SD and USB hub setup. The build manifest records board identity,
configuration/header hashes and compiler identity. Validation checks actual
compiler dependencies and the effective application/bootloader silicon range.

Both variants retain browser output. Selecting the PC board does not add HDMI,
select a new display family or change EMOS's ownership of transport admission.
The PC mapping is a candidate direct harness: eight shared UART/parallel lanes
plus READY_N, CLOCK and VALID_N. Its GPIO20/32 sensing options must remain
disconnected. See [BOARD-001](tasks/BOARD-001.md) for pending physical review and
bench gates; compile success does not qualify that wiring or authorize flashing.

The [current wiring drawing and mapping](../hardware/designs/light2-p4pc-harness-draft/README.md)
retain the original assignments. The Author arranged the bench to suit that
mapping and withdrew the reversed-PC proposal. The unchanged PC board JSON
and existing PC build outputs match this restored mapping; no firmware
remapping is needed for the orientation request.

For the pending P4-PC keyboard experiment, add `--usb-fsls-only` to the native
`p4-console --board p4-pc` command. IDF 5.5.5 lacks the public `fsls_only`
install option. The source-bound recipe in
[`usb_fsls_only.cmake`](../vdp/native/usb_fsls_only.cmake) generates a USB HCD
derivative that restricts the existing HS-capable controller to FS/LS before
each root-port reset. It keeps the onboard hub and pin mapping, with a
12 Mbit/s upstream link. Other board/profile combinations reject the flag;
omitting it retains the existing USB source. The SDK checkout remains unchanged.
The manifest records the option and recipe/derivative hashes; validation checks
the actual compile action and USB archive. The Author's keyboard tests fail;
passive serial confirms full-speed operation followed by failure of the initial
device-descriptor transfer. Physical keyboard operation remains unqualified;
see BOARD-001.

### Selected DevKit configuration

The maintained [board definition](../vdp/boards/olimex_esp32_p4_devkit.json),
[console SDK configuration](../vdp/pio/p4-console.sdkconfig),
[SDK defaults](../vdp/sdkconfig.defaults) and
[partition table](../vdp/partitions.csv) select the following baseline. These
are build inputs, not a fresh measurement of the installed firmware or a P4-PC
profile.

| Item | Selected configuration / interpretation |
|---|---|
| Silicon | Pre-v3 P4 (`esp32p4_es`); generated revision bounds must be checked for the selected build |
| CPU | SDK selects 360 MHz. The board JSON's descriptive 400 MHz field is not runtime proof; [ADR-0010](decisions/ADR-0010-cpu-frequency.md) records why forced 400 MHz was rejected |
| Flash | 16 MiB, 80 MHz. Effective IDF flash settings and the first-stage image header are recorded by the selected native build |
| PSRAM | 32 MiB target, hex mode at 200 MHz, boot memory test; distinct from internal SRAM |
| Internal-memory budget | The historical board metadata's 512,000-byte figure is not physical SRAM capacity and does not include all PSRAM; use IDF map/size output and runtime heap evidence |
| Application partitions | Two 7 MiB OTA slots, plus NVS, OTA metadata, coredump and reserved data. Partition presence does not implement a network updater or qualify durable crash reporting |

The [recorded bring-up](tasks/SETUP-001.md) passed its bounded canary scope;
sustained production-load and later-board qualification are separate. SDK defaults
do not necessarily overwrite a previously generated configuration. Inspect the
selected build's effective SDK settings when defaults or targets change; retain
candidate provenance rather than treating an old generated file as authority.

Build products are under `<output>/build/`; `<output>/manifest.json` records
their hashes and identities. The wrapper never flashes a board. An ordinary
build should carry **`UNVERSIONED-DO-NOT-DEPLOY`**. A successful build alone
does not qualify its firmware for a particular assembly; consult the
[version/build conventions](versions/README.md) and the relevant physical
acceptance record before deployment.

### Which files actually get compiled?

The definitive source/profile authority is
[p4-profiles.json](../vdp/build/p4-profiles.json). It names compiled sources,
forbidden alternatives, embedded browser assets, dependencies, definitions and
profile-specific integration settings. Generated project/component CMake files
inside a fresh output are disposable and must not be edited. The validator
compares this declaration to the actual compile database and Ninja archive/link
edges. Start tracing execution at
[p4_console.cpp](../vdp/video/extender/boot/p4_console.cpp), which includes the
retained browser-VDP boot code and
[console transport](../vdp/video/extender/transport/console_hardware.inc).

### Upstream source and library pins

The [reviewed import identities](dependencies/reviewed/source-baselines.yaml)
record VDP `v2.16.0`, vdp-gl `all-the-plots`, ESP32Time `2.0.6` and CRC `1.0.4`.
The first two have pinned Git commits; the latter two use registry-package
path/content evidence. These are recorded imports, not a fresh upstream release
survey. The three libraries are vendored under `vdp/vendor/`; compiled subsets
come from the target selection above, not directory presence.

The [vendoring decision](decisions/ADR-0012-vendored-release-dependencies.md)
does not cover the entire toolchain: platform/framework packages and the console's
pinned managed components still have their own acquisition and lock records.
The [dependency graph's scope](dependencies/README.md#model-scope-versus-deployed-builds)
is narrower than all later console overlays; its historical verification is not
a complete compatibility-delta audit of the currently deployed firmware.

## Building EMOS and the SD application

EMOS is built separately from the P4 firmware. Its current AgonDev build uses
[mos-agondev](https://github.com/bgates747/mos-agondev) for source preparation,
assembly translation and linking, and the
[AgonDev toolchain](https://github.com/AgonPlatform/agondev). The maintained
EMOS source remains in `agon-emos`; generated builder worktrees are disposable.

Start with [mos-agondev/STARTHERE.md](https://github.com/bgates747/mos-agondev/blob/main/STARTHERE.md)
for the toolchain and builder setup, supplying the EMOS checkout to its
`--agon-mos` source option. That builder currently requires Python 3.14 or newer.
EMOS's own Python dependencies are listed in its
[requirements-dev.txt](https://github.com/bgates747/agon-emos/blob/main/requirements-dev.txt).
Once the local paths and Python environments are configured, the EMOS
checkout's own Makefile provides the product build:

```sh
# Run from the agon-emos repository root.
make PYTHON=.venv/bin/python firmware-check
```

The [EMOS Makefile](https://github.com/bgates747/agon-emos/blob/main/Makefile)
defines `MOS_AGONDEV_ROOT`, `MOS_WORKTREE` and `AGONDEV_TOOLCHAIN` overrides.
With its default layout, firmware outputs are in
`../mos-agondev/projects/mos-port/bin/`. For identified builds and automated
qualification, see
[prepare_boot_review.py](https://github.com/bgates747/agon-emos/blob/main/scripts/prepare_boot_review.py);
that workflow also requires a configured Fab runtime and runs automated
runtime checks. Start with [emulator setup](emulator-setup.md) for profile
ownership, stock-versus-EMOS selection and validation limits.

The maintained `agon-emos` repository contains the resident SD gateway and
`projects/sdserve/`. The listener is built separately from resident EMOS. Its
ordinary application build, with AgonDev on `PATH`, is:

```sh
# Run from the agon-emos repository root.
make -C projects/sdserve
```

This produces the ordinary application `projects/sdserve/bin/sdserve.bin`. In that checkout,
`projects/sdserve/README.md` covers explicit toolchain paths, identified builds
and its EMOS requirements; `scripts/prepare_sdserve.py` creates identified
application bundles.
Use the [mainboard SD operating guide](mainboard-sd.md) for the host client
and service lifecycle. Compiling this application alone does not install the
EMOS gateway or matching P4 firmware it needs.

The installed EMOSlet instead occupies the 32 KiB MOSlet region. From the
`agon-emos` repository, a compile-only build is:

```sh
make -C projects/sdserve clean
make -C projects/sdserve RAM_START=0xB0000 RAM_SIZE=0x8000
```

The clean step prevents reuse of objects from the other memory layout. Both
layouts produce the same output filename: do not interchange their payloads.
The MOSlet installs as `/emos/sdserve.bin` and is invoked through `EMOS sdserve`;
the ordinary application fallback uses LOAD/RUN. `prepare_sdserve.py` prepares
ordinary application bundles; it does not by itself select the MOSlet layout.
Identified MOSlet builds and their validation are recorded in the
[fast-transfer tasklet](tasks/REMOTE-005/FAST-TRANSFER.md). Consult the
[EMOS utility contract](https://github.com/bgates747/agon-emos/blob/main/docs/emos-utilities.md)
for dispatch and memory limits. No build command in this guide deploys firmware.

## Private parallel payload compile probe

PORT-008's explicit `--parallel-boot-candidate` P4-PC build compiles the private
shared handover, UART drain/parking and native PARLIO RX/TX coordinator. It does
not activate ExExt or provision a payload buffer. Ordinary selections exclude
the native coordinator and payload leaves. Unprovisioned offers are rejected.

The companion EMOS `port/parallel-native-candidate.mk` includes the private
foreground coordinator and native assembly. The complete checked image uses
130473 ROM bytes, 599 free; ordinary EMOS uses 128739 bytes, 2333 free. These are
compile/link measurements with unchanged ROM and caller-inventory guards, not
deployed identities or production selections. The coordinator has no activation
caller, public API or CLI command. See the
[coordinator integration evidence and remaining gate](tasks/PORT-008/LIVE-COORDINATOR-LC02-RESULTS.md)
before selecting either private composition. A separately reviewed fixture and
physical qualification remain required.

EMOS excludes its C receive correctness reference from ordinary/native builds;
`port/parallel-reference-test.mk` retains it explicitly for tests. The RAM-only
instruction image is never firmware. Earlier
[ROM-fit](tasks/PORT-008/NATIVE-ROM-FIT-RESULTS.md),
[diagnostic extraction](tasks/PORT-008/DIAGNOSTIC-ROM-RECOVERY-RESULTS.md) and
[block-control refusal](tasks/PORT-008/BLOCK-CONTROL-RESULTS.md) retain their own
historical build sizes and validation limits.

The extracted diagnostics build in sibling `agon-emos/projects/uartprobe` with
`make NAME=uarttest` and `make NAME=vdppoll`, using the selected AgonDev toolchain.
During an authorized paired development deployment their binaries belong at
`/emos/uarttest.bin` and `/emos/vdppoll.bin`; they are not present on SD by
assumption. Commands keep their EMOS prefix, require an idle Legacy CLI and an
unclaimed UART1, and retain their distinct peer/baud requirements. See the
[component guide](../../agon-emos/projects/uartprobe/README.md). No build command
installs either file or authorizes bench use.

## Deployed candidates versus the base target

The maintained `p4-console` target includes the selected codecs, browser decoders,
build flags and hash-guarded DSP derivative. It no longer requires hidden task
snapshot overlays. The accepted r55 build additionally fixes the separate
bootloader configuration path and checks both silicon ranges before freezing an
image. See the [current bundle](../production/README.md) for exact binaries and
[physical acceptance](tasks/RELEASE-001/R01-07.md) for the bounded scope.

EMOS and the listener reproduce historical bytes exactly. P4 r55 is a separately
identified clean reconstruction, not byte-identical to the old installed reset
build. Compression negotiation and reset configuration are explicit in its
manifest. No new FPS guarantee or change to request pacing is implied.

### Exact EMOS and MOSlet reproduction

[reproduce_sd_components.py](../scripts/reproduce_sd_components.py) clones clean
owning repositories into a fresh directory, uses the existing MOS builder and
AgonDev toolchain, and requires expected historical hashes. For the selected
recorded installation (substitute local checkout/tool paths):

```sh
.venv/bin/python scripts/reproduce_sd_components.py \
  --emos-source ../agon-emos --builder-source ../mos-agondev \
  --toolchain ../mos-agondev/toolchains/agondev \
  --builder-python ../mos-agondev/.venv/bin/python \
  --output agents/sd-reproduction \
  --emos-build-id agon-emos-v0.1.19-b2026-09-24-02-02-56Z \
  --listener-build-id sdserve-v0.2.0-b2026-09-24-02-21-03Z \
  --emos-sha256 817deb27aa6139dcfbf616f10f799f90d2eed08c17e87883f57d6cc8583195d7 \
  --listener-sha256 bd7dc38aeac564d2df3da5a7c2dc1cd902ebf1973ef96140307649023f3dbb11
```

The exact commits and compiler hash are in the
[reproduction record](tasks/RELEASE-001/BUILD-RESULTS.json). Select those commits
in clean local checkouts if current source has advanced. Reused timestamps are
permitted solely for exact hash reproduction; differing outputs fail and must
not be deployed with a historical identity. A genuinely changed build needs a
new timestamp through the owning project's identified build procedure.
The helper builds the **MOSlet**, not an ordinary LOAD/RUN application, and does
not modify an emulator, SD card or board.

## Local installation packaging

The [production entry point](../production/README.md) and `production/current.yaml`
select the accepted immutable bundle. r02 packages the exact physically tested
r55 outputs; it does not rebuild or flash them. A clean source export must pass
both application and bootloader silicon-configuration checks. The maintained
pre-build hook resolves the configuration path absolutely for both CMake builds.

The selected inputs are in
[the packaging selection](../production/bundles/extender-installation-r02/selection.json).
Local generated build directories are inputs, not runtime dependencies:

```sh
.venv/bin/python scripts/package_installation.py \
  --selection production/bundles/extender-installation-r02/selection.json \
  --p4-build agents/release001/builds/reset-corrected \
  --sd-build agents/release001/builds/sd-components \
  --emos-source ../agon-emos --builder-source ../mos-agondev
.venv/bin/python scripts/verify_installation.py \
  dist/production/extender-installation-r02/extender-installation-r02
```

The builder requires a clean packaging checkout and refuses an existing output
directory. Use the immutable bundle's recorded packaging commit to reconstruct
its recipe; do not reuse the identity for changed inputs. Archive timestamps are
not claimed reproducible: select retained archives by recorded SHA-256.
Neither command deploys or creates the current selection. The configured local
firmware contains a private reset endpoint. Its build-owner configuration remains
local; changing it requires a newly identified build. Public source/license
limits remain in [NOTICES](../production/NOTICES.md). The failed r01 archive is
historical evidence and must not be deployed.

## P4-local SD HTTP candidate

The standard `p4-console` source selection includes
`video/extender/storage/local/http.cpp`. The selected console SDK configuration
uses heap-backed FatFS long filenames, required by upload staging names. Other
fixture targets do not acquire this service automatically.

Host-only filesystem checks:

```sh
g++ -std=c++17 -Wall -Wextra -Werror -I vdp/video \
  tests/storage/p4_local_files_test.cpp -o /tmp/p4-local-files-test
/tmp/p4-local-files-test
```

A low-level PlatformIO compile is not an identified release or evidence that the
physical SD card mounts. Follow the normal identified build/deployment workflow
before bench qualification. See [P4 SD operations](p4-sd.md).

Additional P4-local file management checks (Linux host):

```sh
g++ -std=c++17 -Wall -Wextra -Werror -I vdp/video \
  tests/storage/p4_local_replace_failure_test.cpp -Wl,--wrap=rename \
  -o /tmp/p4-local-replace-test
/tmp/p4-local-replace-test
.venv/bin/python -m unittest discover -s tests/storage -p 'test_*.py' -v
```

The replacement test injects an installation rename failure and verifies old-file
restoration. Python tests use a localhost HTTP peer to check client framing,
command dispatch and tree transfers; they do not execute ESP-IDF handlers or
qualify an SD card. The console HTTP URI limit is 2048 bytes to accommodate two
encoded paths; recursive filesystem traversal is bounded to 16 levels.

Detached consumers should start with [shared P4 service boundaries](shared-p4-services.md),
not the complete console translation-unit selection. The Ethernet header is
Arduino-backed but independent of VDP, EMOS and HTTP route composition.

The optional development `--lcd` build is described in [LCD output](lcd-output.md);
it is not enabled in ordinary builds or the selected production bundle.

## P4-PC HDMI development output

The native builder accepts `--display-output browser` (the default) or
`--display-output hdmi`. HDMI is restricted to `p4-console` on `p4-pc` and
uses the same stock-shaped renderer. The selected adapter supplies fixed
1280×720 RGB888 output by default, centered unscaled images and cropping, with logical-mode
buffering and hardware-paced frames. Browser video is omitted; browser keyboard,
HTTP and SD services remain. Native DevKit/browser selection is unchanged.

The experimental `--hdmi-timing auto` option requires
`--rolling-scanout --direct-rgb888 --render-benchmark-output normal` and an
explicit dirty-experiment build identity. It selects684×384 for logical images
that fit that carrier and848×480 otherwise. Thus512×384 is centered at(86,0),
while640×480 is centered at(104,0) with no clipped text rows. Smaller modes remain
centered and unscaled;320×240 has no new physical timing yet. Oversized modes
retain the crop fallback pending inventory. `/display/status` reports the active
carrier rather than the build's initial size.

The automatic build also exposes experimental single-buffer modes **96–99**:
848×480 at 64, 16, 4 and 2 colors respectively. These provisional IDs expose
the complete 848×480 carrier, without changing stock modes or adding DB aliases.
They use the existing native compositor; the direct RGB888 fast path remains
limited to its previously qualified geometries. Select them through ordinary
EMOS-routed `VDU 22 n`; stock mainboard VDP does not implement these IDs.
See [full-width qualification](tasks/HDMI-002.md) for current validation limits.

The behavior in this paragraph and the next describes the retained r06 build.
Unaccepted development source now also contains the r07/r08 experiment with
three 848-wide slots, selected task stacks in PSRAM, and direct RGB888 mode 96.
That experiment fails longer Nurples runs with stopped scanout and a recorded
DSI underrun. A fresh build of this working tree is **not** the proven r06
rollback. Use its exact retained artifacts/manifest, and consult the
[failed experiment record](tasks/HDMI-002/ROLLING480-RESULTS.md) before choosing
development firmware. Production selection is unchanged.

The subsequent r09 source adds a bounded one-request refill queue and preserves
the first scanout fault for diagnosis. It passes host checks and target compilation
only; it has not been deployed. See the [offline review](tasks/HDMI-002/OFFLINE480-REVIEW.md)
before choosing this experiment. The three-slot allocation,1,600µs limit and
physical timings are unchanged; waiting time counts toward that limit.

The following r10 experiment adds cancellation of submitted swap waiters and
fault-aware panel borrowing/recreation at joined mode boundaries. It retains
r09's refill remedy. Host lifecycle and failure-injection checks pass; this is
still unflashed development, not a repair verified on the physical monitor.
See the [mode-lifecycle review](tasks/HDMI-002/MODE-LIFECYCLE-REVIEW.md) for exact
build status and the distinction between reproduced host defects and the
unresolved physical mode96-to97 failure.

The automatic build reserves three32-row684 rolling SRAM slots at boot and
retains them across carrier changes, avoiding later fragmentation. The684 carrier
uses those slots and immutable hardware
sprite snapshots. The848 carrier reuses pinned IDF's full-frame DMA, avoiding
an additional47KiB of SRAM that three848-wide slots would require. This does
not qualify equivalent hardware-sprite performance in480-line modes. Sprites
remain enabled through the native compositor, with unchanged palette behavior;
bounded640×480 checks in16/4/2-color modes pass. Carrier
changes stop/join the former rendering owners and restart DSI/LT8912B on core1;
fixed selections remain available. See [runtime qualification](tasks/HDMI-002.md).

The explicit experimental `--hdmi-timing 848x480` option selects the
[HDMI-002](tasks/HDMI-002.md) custom 60.06944 Hz timing: PLL240/7 pixel clock,
two 480 Mbps DSI lanes and 1104×517 totals. It is not exact DMT 0Eh or a
native 512×384 signal. A 512×384 logical image is centered unscaled at (168,48).
Omitting the option retains 1280×720. The build manifest and embedded browser
status record the selected output; browser video remains absent in HDMI builds.
The accepted partial-scroll implementation can be selected with the existing
experimental `--direct-rgb888` option; this does not promote it to production.
The additional experimental `--hdmi-timing 512x384` selection uses a native
512×384 active area with the same clock and totals, larger blanking porches and
4:3 metadata. The standalone signal failed physical review and the Author now
targets a widescreen carrier with512×384 pillarboxed. This full512-wide selection
is retained experimental preparation, not a deployment recommendation.
With `--rolling-scanout --direct-rgb888 --render-benchmark-output normal`,
its twelve 32-row DMA blocks use three internal SRAM slots totaling 147456 bytes,
versus 244224 bytes for the 848-wide experiment. The rolling renderer and DMA
driver must use matching build definitions; validation checks both. Full-firmware
startup, mode transitions, sprites and gameplay for that512-wide build remain
unqualified; it is not the accepted standalone684-wide timing pattern.

The explicit `--hdmi-timing 684x384` selection uses the reviewed widescreen
carrier with512×384 centered at(86,0), preserving the clock and totals above.
Combined with the same rolling/direct/benchmark flags, twelve32-row blocks
reuse three SRAM slots totaling196992bytes. Build validation checks matching
684-wide C DMA and C++ definitions. The initial candidate exhausted internal
memory during hardware Nurples and crashed in buffer ownership cleanup. The
latest placement remedy completes the marked3600-update run at nominal60/s and
ordinary menu/mode-change/Escape exit, with about22KiB internal RAM free during
play. Author review and broader qualification remain pending; automatic Agon
SD admission after ordinary exit rejects in ExCom and recovers through
`EMOS LEGACY` without reset. Use
[the integration record](tasks/SPRITE-001/INTEGRATION.md) for current evidence.
The old full848 image remains usable for service recovery, but is not a
hardware-sprite Nurples playtest rollback. The current rolling candidate prefers
PSRAM for all ordinary malloc sizes (`CONFIG_SPIRAM_MALLOC_ALWAYSINTERNAL=0`),
while preserving the32768-byte internal reserve and explicitly internal RTOS/DMA
allocations. The physical rolling build also allocates the unchanged1024-entry
primitive queue payload in PSRAM, with its RTOS control in internal RAM. The
owned adapter uses pinned IDF static-queue construction and capability-aware
deletion; the stock queue capacity, order and drawing behavior are unchanged.
An optional `--abort-on-alloc-failure` is restricted to an explicit
experimental rolling build; it uses IDF's heap-abort diagnostic and must not be
confused with the memory remedy. Default builds are unaffected. See
[allocation diagnosis and current checks](tasks/HDMI-002/MEMORY-RESULTS.md).
For controlled comparisons, `--dependencies-lock PATH` seeds dependency
resolution from a retained build lock. Verify the resulting lock against the
intended baseline; the option does not itself prevent a resolver update.

HDMI is experimental, outside selected production. Its pre-v3 silicon callback
is DMA frame completion rather than a separate hardware-vsync interrupt; original
70/75Hz modes physically use the fixed ~60Hz HDMI cadence. See
[HDMI-001](tasks/HDMI-001.md) for scope, constraints and pre-flash evidence.

The explicit `--allow-dirty-experimental` exception is restricted to admitted
HDMI experimental build identities on P4-PC/console/HDMI. It archives exact Git-visible
VDP and build-tool source bytes before compiling, records their hashes, and
rejects changes during the build. It does not qualify dirty source or waive
the normal clean-input guard for other identified builds. Build outputs retain
`source.tar.gz`, `source-inputs.json`, `display.json`, board inputs, dependency
lock, compile/link validation, image hashes and normal manifests. No build command
flashes a board.

The 2026-10-09 diagnostic extraction ordinary candidate and its three MOSlets
have subsequently passed [bounded hardware qualification](tasks/PORT-008/DIAGNOSTIC-ROM-RECOVERY-HARDWARE.md).
This development installation does not replace the selected production bundle
or qualify the private parallel coordinator.

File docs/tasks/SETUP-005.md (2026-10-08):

# SETUP-005 — Resolve EDU operating modes and system integration

## State

- Status: In progress — mode vocabulary and D001–D002 accepted. D003/D007 have
  an accepted browser/UART direction; their remaining choices and D004–D006/D008
  stay open. Keyboard decisions accepted for freeze, 2026-09-08.
- Started: 2026-08-21 00:49 EDT
- Finished: --

## Intent

Resolve the remaining architectural decisions governing EDU operating modes,
transparent legacy compatibility, MOS integration, response ownership, and
optional use of the onboard VDP as a service behind Extender. This task is the
authoritative open-decision tracker for
[ADR-0014](../decisions/ADR-0014-edu-operating-modes-and-service-architecture.md).

Do not let these system-integration decisions block SETUP-004's source and
driver disposition survey. SETUP-004 determines what code and behavior must be
retained, replaced, stubbed, omitted, or deferred; this task determines how the
retained behavior is routed between processors and MOS.

## Current integration boundary

Selectable mainboard/Extender input and bounded Legacy/ExCom console switching
are implemented. P4 USB, browser and agent keyboard providers now share
`EMOS KEYINPUT extender` under [ADR-0022](../decisions/ADR-0022-browser-keyboard-capture.md).
Use the [keyboard guide](../remote-keyboard.md) and
[console contract](../protocols/excom-console.md) for current operation.
PORT-015 retains native-input proof; REMOTE-001 retains browser acceptance and
limits. The older decisions below record how this direction was reached, not
an instruction to defer the implemented browser path.

The accepted foreground [mainboard-SD service](../mainboard-sd.md) is an
additional explicit Legacy service under EMOS transport ownership. It does not
activate ordinary EDP/EDU routing or settle the wider D003–D008 decisions.

| Decision | Accepted direction or remaining question | State / owner |
|---|---|---|
| SETUP-005-K001 | Browser → P4 processed keyboard → stock VDP packets on r03 UART1 → EMOS-owned keyboard handling/sysvars/keymap. Both directions use 1152000/8N1 RTS/CTS. No parallel or onboard relay. | Accepted by the Author, 2026-09-08; amended ADR-0014 and architecture. |
| SETUP-005-K002 | Explicit autoexec command enables EMOS browser-keyboard reception; for the first increment EMOS accepts P4 keyboard events exclusively while retaining other onboard VDP communications. On focus loss/disconnect, P4 sends stock key-up packets for held keys, then stops keyboard packets to EMOS. | Initial behavior accepted for trial by the Author, 2026-09-08. Detailed session mechanisms remain to be specified with REMOTE-001 and INTEG-009. |
| SETUP-005-K003 | Persistent UART1 reception and stock handler reuse with separate UART0 parser state, stock callback context/order and no conflicting keyboard writers. | Interrupt-driven UART1 and separate packet assembly accepted, 2026-09-08; detailed implementation/qualification belongs to PORT-008 and INTEG-009. |
| SETUP-005-K004 | Case-insensitive `EMOS <subcommand>` control; `EMOS EXCOM` / `EMOS LEGACY` destination selectors; `EDU` explicit Extender commands; `EMOS KEYINPUT [mainboard / browser / extender]` source selection/reporting; `SET KEYBOARD n` layout retained across mode changes; reboot persistence via autoexec. | Accepted, 2026-09-08; ADR-0014 CLI section is authoritative. K009 selects implementation of the reserved extender source. |
| SETUP-005-K005 | Keyboard source is independent of display mode. `EMOS LEGACY` restores mainboard VDU routing while preserving selected browser input; explicitly selected keyboard traffic is an exception to total Extender absence in Legacy. | Accepted by the Author, 2026-09-08; amends ADR-0014 and the two-plane model without treating keyboard-only activity as Dual. |
| SETUP-005-K006 | Start with mainboard input; restore desired source/layout and other explicit startup selections through `autoexec.txt` only. Commands retain runtime state across mode changes, not through separate saved configuration. | Accepted by the Author, 2026-09-08. No new state/.cfg/NVS settings store for this increment; revisit only if a later need justifies it. |
| SETUP-005-K007 | ExCom sends ordinary CLI/VDU output to EDP; mainboard VGA shows a static mode banner with cursor hidden. No double buffering or periodic redraw; VBlank continues. Dual retains active display roles. | Accepted by the Author, 2026-09-08; ADR-0014 display section. |
| SETUP-005-K008 | Initially, return to Legacy with a fresh mainboard screen, visible cursor and MOS prompt, preserving keyboard source/layout. | Accepted by the Author, 2026-09-08. Later, consider one-line transition notices and cursor hide/show while preserving the existing background; not a first-increment gate. |
| SETUP-005-K009 | Bring forward one directly attached USB keyboard using P4 native USB host and `EMOS KEYINPUT extender`; reuse stock packets over r03 UART1. First prove ordinary EMOS CLI on mainboard VGA, independently of browser focus/network. The DevKit USB connector/power assembly is permitted for this input. | Accepted by Author, 2026-09-09; PORT-015 owns implementation and physical proof; ADR-0014 amended. |
| SETUP-005-K010 | Prioritize selectable `mainboard` / `extender` keyboard input after native USB CLI and gameplay pass. Defer browser input until explicitly reprioritized, preserving its code, decisions and findings. Record the tested USB connection in the hardware specification now; defer the schematic update to the next Author session. | Accepted by Author, 2026-09-09; PORT-015/PORT-005 own input qualification. Browser deferral later superseded by [ADR-0022](../decisions/ADR-0022-browser-keyboard-capture.md) and REMOTE-001 implementation; HW-002 owns the drawing update. |

K002's initial behavior, K003's receiver direction and K005's independent
keyboard source are settled; K006 settles autoexec-only persistence. The
original documentation freeze preceded implementation; the current guides above
record the later implemented subset. No broad
mode-transition redesign or complete four-mode matrix is a prerequisite for
an explicitly bounded keyboard test. Product mode integration remains gated.

K002 cleanup was accepted for trial: P4 tracks held keys and emits their stock
key-up events before going quiet on focus loss or browser disconnect. This
avoids leaving EMOS's keymap in a held state. REMOTE-001/PORT-005 implement the
behavior; receiver qualification verifies the resulting EMOS state. Abrupt
browser loss must not depend on the browser sending its own final releases.

K005 explicitly permits selected browser input while mainboard VDU output
continues. Mode changes preserve the keyboard source. Keyboard-only P4 traffic
is an accepted exception to earlier total-inactivity language in D002 and the
linked lifecycle studies; it does not activate the ordinary EDP/EDU service or
commit Dual. EMOS still owns activation, transport and canonical state. K006
restores startup selections only by executing autoexec commands. The immediate
startup/source/receiver decisions are settled; broader task questions remain
outside this first increment.
The Author approved the original decision freeze on 2026-09-08. Subsequent
implementation and acceptance are linked in the current integration boundary.

## Display preservation

The bounded `--keep-display` option now implements explicit per-display
preservation; see the current console contract and ADR-0014. It does not
migrate resources between the two processors. The original preference below
explains that decision rather than requesting another implementation.

The Author would prefer eventually retaining the mainboard display contents,
including a user-chosen background, with one-line mode-change confirmations
and cursor hide/show on departure and return. K008's initial fresh-screen
behavior is accepted for now, not a permanent requirement to clear the display.
When revisiting this, account for notice placement and scrolling so a status
line does not accidentally destroy the background it is meant to preserve.
No screen snapshot/restore machinery or new implementation is requested now.

## Implementation strategy — resident EMOS

The Author rejected the proposed moslet-space module foundation and runtime
relocation. Extend resident EMOS with normal compile-time linking and clear
command/service/interrupt ownership. No module loader, generic module manager
or moslet-space restriction gates the keyboard increment. INTEG-009 owns the
implementation; MOS-001 is cancelled and retains historical research only.
K001–K008 remain accepted. The documentation freeze is approved; coding is
separate.

## Accepted operating-mode vocabulary

Current transport clarification (2026-10-08):
[ADR-0026](../decisions/ADR-0026-four-lane-exext-transport.md) and PORT-008 P08-F
target eight-bit payload both ways, using the existing READY/CLOCK/VALID wires for
handshake/status before and after the payload phase; UART requires coordinated handover.
The earlier parallel-forward/UART-return vocabulary below is historical transport
scope, not a prohibition on this accepted new direction. Mode identity and EMOS
ownership remain unchanged; ExExt lifecycle/routing implementation remains open.

The Author accepted the following formal names and stable identities on
2026-08-23:

- **Legacy mode** — `mode:extender:legacy`; mainboard VDU routing and inactive
  EDP/EDU service, with explicitly selected browser input permitted under K005.
- **Exclusive Compatible mode** — `mode:extender:exclusive-compatible`; the EDP
  is exclusive and uses the stock VDP UART transport contract.
- **Exclusive Extended mode** — `mode:extender:exclusive-extended`; the EDP has
  the same exclusive compatibility authority and uses the enhanced
  parallel-forward/UART-return transport.
- **Dual mode** — `mode:extender:dual`; the onboard VDP owns ordinary VDU and
  canonical stock state while EDU addresses the active EDP separately.

“Compatible” and “Extended” are permitted short forms in unambiguous
operating-mode context. “Exclusive” is mandatory in the two official names.
On 2026-09-08 the Author also accepted **ExCom** as conversational shorthand
for **Exclusive Compatible**, retaining its formal name and stable identity.
On 2026-09-26 the Author accepted **ExExt** for **Exclusive Extended**.
Naming is resolved; lifecycle, routing, reverse capabilities, carve-outs, and
the remaining questions below stay open.

## Accepted clarification — 2026-09-26

SETUP-005-D009 [x] — Author reaffirmed ExCom UART-only/no parallel traffic,
ExExt as Exclusive Extended with standard VDU parallel forwarding, and Dual
as mainboard VDU plus explicit EDP/EDU. ExExt compatibility remains separately
qualified. Existing applications need no output-call rewrite to benefit in
ExExt. Keyboard-source selection remains independent.

The existing MOS API gateway (`0x51`, C slot `0x20`) is the explicit service
entry, not a new RST vector or external-module mechanism. General EDU drawing,
Dual and ExExt implementation remain pending. See the current
[architecture](../architecture.md) and
[ADR amendment](../decisions/ADR-0014-edu-operating-modes-and-service-architecture.md).
This acceptance does not close the other lifecycle/interface questions.

## Accepted MOS terminology

**Extender MOS (EMOS)** is the project-owned complete backward-compatible
replacement build of official stock MOS. EMOS is not a companion installed or
run beside stock MOS. It retains stock MOS behavior and interfaces while adding
the VDU dispatcher, mode-transition coordinator, and other explicitly accepted
Extender support. Use “stock MOS” for the unmodified official firmware and
“EMOS” for this replacement from this point forward.

## Open decisions

- [x] **SETUP-005-D001 — Exclusive EDP routing:** accepted 2026-08-23. Use one
  EMOS semantic VDU dispatcher for `RST.LIL 10h`,
  `RST.LIL 18h`, and MOS C-runtime `putch`/`printf`, with byte and block-stream
  operations. Legacy and Dual select onboard UART0; Exclusive Compatible
  selects the future EDP stock-UART backend; Exclusive Extended selects the EDP
  forward-parallel backend. Raw UART APIs retain their device identities. Rev
  1 uses MOS/eZ80 as the sole onboard-VDP/EDP intermediary and retains a private
  onboard-VDP control route only for input bootstrap and accepted delegated
  configuration. Fixed-backend MOS builds are permitted and required as
  developmental/qualification stages, but do not resolve D002 lifecycle.
  Application entry point and destination remain distinct: reset-vector and
  C-runtime output are always VDU calls, while explicit EDU calls use the
  separate versioned EDU interface and result domain. EDU-aware applications
  may combine both call classes without defining another operating mode. In
  Dual they address different processors; in either exclusive mode both may
  reach different interfaces of the EDP. Mode-dependent applications may
  require Exclusive Extended and use conventional VDU restart calls as their
  efficient compatible-output path, but must verify or request that mode before
  issuing output that would be unsafe or meaningless through the onboard VDP.
- [x] **SETUP-005-D002 — Mode lifecycle:** accepted 2026-08-24. Define selection, discovery,
  transition, reset, failure, and recovery behavior for Legacy, Exclusive
  Compatible, Exclusive Extended, and Dual modes. Legacy mode must make
  Extender electrically and logically absent from the Agon interface. Mode
  activation must be transactional: missing or incompatible MOS hooks, EDP
  firmware support, resident/TSR-like support, MOS Modules, transport backends,
  or other prerequisites must leave the current mode and routing unchanged and
  report a bounded failure. On stock MOS, the normal `Invalid command` or
  unavailable-API result for an uninstalled Extender facility is acceptable
  graceful failure; stock MOS supports only Legacy and direct Extender hardware
  access is out of scope. Accepted lifecycle foundation: formal mode is the
  committed combination of two distinct EMOS-owned logical planes, VDU routing
  and EDP service. The only supported combinations are Legacy
  (onboard/inactive), Dual (onboard/active), Exclusive Compatible
  (EDP-compatible/active), and Exclusive Extended (EDP-extended/active).
  Exclusive routing with inactive EDP is invalid. A third independent state
  dimension requires explicit architectural review. Live Legacy↔Dual
  activation is accepted. The proof-of-concept/beta baseline uses a disruptive
  controlled restart for ordinary-VDU route changes outside the accepted
  PORT-008-D005 idle-console Legacy↔ExCom exception, and remains an
  acceptable v1 fallback. Preserving the loaded eZ80 program/data and resident
  processor state is an aspirational v1 target and firm v2 requirement under
  [MODE-001](MODE-001.md); preservation does not imply migrating display
  assets between processors. Every activation uses a
  prepare/readiness/commit/recover transaction: validate all prerequisites and
  initialize the complete target before publishing new routing, restore a
  stable mode after bounded pre-commit failure, and let the EMOS coordinator
  make no more than one transition attempt per explicit request. This
  routing-coherence guarantee is independent of later
  state-preservation work. Legacy is the mandatory hub for all transitions:
  there are no contracted direct transitions between two non-Legacy modes.
  Every cold boot reaches fully operational Legacy and contacts Extender only
  after an explicit late `autoexec.txt` or manual invocation. A successful
  explicit presence/version probe activates EDP and commits Dual; failure
  leaves Legacy. Exclusive entry begins only after Legacy. Persisted preferred
  mode selection is exploratory and not a v1 contract. Pending state is needed
  only if a selected implementation carries an attempt across reset; retained
  cross-boot circuit breaking is not a beta requirement and remains a
  regression-driven conditional v1 target under [MODE-002](MODE-002.md).
  After commit, detected EDP failure in Dual invalidates EDU work and commits
  Legacy while onboard VDU continues. Exclusive EDP/transport failure blocks
  VDU and allows only bounded reinitialization before disruptive recovery to
  Legacy; it must not claim that application/display state survived. Structured failure
  reporting is advisable during beta and a hard v1 requirement, but not a beta
  gate. It requires best-effort descriptive onscreen reporting and durable
  machine-readable logs of consequences and safely obtainable processor
  context under [DIAG-001](DIAG-001.md). Reset invalidates the affected
  component's sessions, parsers, pending work, readiness, and authority even
  when RAM bytes or another processor survive; invalidation does not require
  erasure. eZ80/MOS and whole-system resets return through Legacy, and P4 reset
  in Dual commits Legacy. EMOS is a single complete
  backward-compatible stock-MOS replacement whose dispatcher alone owns
  ordinary VDU routing and whose lifecycle/EDU machinery alone owns EDP
  activation in Dual and both exclusive modes. Formal mode is derived from the
  two committed planes. Lifecycle
  records include requested, conditionally pending, committed, failure, and
  fallback information. Exact APIs and storage remain deferred, persisted user
  preference is not a v1 contract, and fixed-backend builds still require
  explicit activation after Legacy startup. Successful explicit
  probe/activation latches Dual as system state; foreground exit or zero known
  callers does not deactivate EDP. Normal return to Legacy is an explicit
  coordinated shutdown which may refuse or time out when registered work
  cannot quiesce. A separately explicit forced shutdown may invalidate work
  after warning. Reset/failure follows the accepted recovery rules; exact
  session and shutdown APIs remain deferred.
  EDP presence is pull-discovered as a hard v1 policy. EDP/P4 firmware and
  carrier wiring remain quiescent while Legacy is committed or a mode
  transaction is uncommitted. EMOS prepares the eZ80 receiver, issues the
  explicit request, validates the EDP response, and alone commits mode.
  Asynchronous EDP traffic requires a negotiated, armed post-activation
  receiver; P4 reset revokes that permission and EMOS quarantines stale traffic.
  Rev 1 defines no proactive presence signal. QUAL-002 owns electrical and
  power/reset qualification; D003 owns parser and response-domain mechanics.
  Before EMOS commits an exclusive route, a reviewed transport/wiring profile
  must be selected, EMOS must arm the eZ80 receiver and request readiness, and
  EDP/P4 firmware must return compatible identity, protocol, and capability
  data. That handshake establishes protocol readiness only; QUAL-002 remains
  the physical-wiring electrical authority.
  EMOS uses one fixed set of modified reset-vector and C-runtime output handlers
  which call one VDU dispatcher; mode changes switch only its committed backend,
  not vector tables. Each active invocation retains one backend snapshot. The
  EMOS coordinator blocks new calls, waits for active calls and owned response
  work to finish or be abandoned, reinitializes affected parser state, and then
  commits atomically. Beta adds no second semantic VDU parser and does not
  preserve multi-call partial commands across a disruptive transition.
  The EMOS dispatcher, EDP/P4 firmware, and carrier wiring never mirror
  ordinary application VDU to both processors. Legacy/Dual send it only to
  onboard VDP; exclusive modes send it only to EDP. Targeted private
  input/bootstrap control, recovery diagnostics, and separately identified
  qualification traffic are not mirrored application output.
  EMOS recovery may use the onboard VDP for diagnostics or restored Legacy
  output after exclusive EDP failure only after explicitly disclaiming
  application/display continuity; it must not claim that lost or unknown EDP
  display, audio, buffer, or application-visible state survived.
  Every active Extender mode requires EMOS. Before a valid activation
  transaction, carrier hardware must hold P4-to-Agon drivers disabled through
  hardware-safe defaults and EDP firmware may accept only the bounded
  activation exchange. Valid pre-activation logic patterns or GPIO-direction
  changes through project-owned supported paths may be ignored or fail safely.
  Ordinary VDU, EDU, updater, and persistent-write operations remain
  unavailable. External code that directly violates EMOS ownership receives no
  non-bricking guarantee. Any
  best-effort unmanaged-traffic warning uses only an Extender-owned out-of-band
  display or log and never the unactivated Agon interface. QUAL-002 owns the
  electrical proof; protocol and parser owners must prove bounded handling.
  EMOS recovery/reporting code and EDP/P4 diagnostic firmware must not send the
  only report through a failed component when another accepted sink survives,
  and diagnostic delivery must not delay safe recovery.
  V1 requires a bounded durable crash-log sink in P4 onboard flash independent
  of optional microSD. The existing `coredump` partition is the initial
  candidate pending DIAG-001 integrity, interrupted-write, wear, native-crash,
  retrieval, and evidence-scope qualification. Video/browser reporting alone
  is not durable.
  EMOS is the only supported authority for ordinary VDU routing, Extender
  transport hardware, and committed mode. Applications, linked clients, TSRs,
  MOS Modules, and resident services may request those operations only through
  documented EMOS interfaces. This is not an adversarial guarantee against
  deliberate unrestricted eZ80 register/GPIO access; no bomb-proof privilege
  system is a proof-of-concept or v1 requirement, and violating code may
  corrupt, damage, or brick either system.
  EMOS alone names the current formal mode from its committed state. EDP/P4
  firmware and applications may report local, requested, pending, readiness,
  transport, or failure state but must not present an uncommitted, failed, or
  partial combination as a formal mode.
  The EMOS mode-transition coordinator completes a committed return to Legacy
  before attempting any different non-Legacy destination. Direct non-Legacy
  transitions require later separate architecture, implementation, and
  qualification approval.
- [ ] **SETUP-005-D003 — Compatible response delivery (partially accepted):**
  EMOS owns reception and canonical sysvar effects. K001 selects ordinary VDP
  keyboard packets from P4 over the existing r03 UART1 link for the next
  increment. Stock MOS currently parses VDP packets only from UART0; INTEG-009
  must preserve its keyboard semantics while providing an EMOS-owned UART1
  ingress. Sysvars and the virtual keymap are local MOS memory, not additional
  UART payload formats. Keep UART0/UART1 parser assembly and source authority
  separate; reuse stock handlers without competing canonical writers.
  K002/K003 track session/receiver details. Other packet classes, exclusive-mode
  integration and Dual's separate EDU result domain remain open. The old r02
  circuit and parallel Work 2.e are held, not prerequisites for this r03 UART
  keyboard increment. Do not conflate the completed bounded UART diagnostics
  with a persistent receiver or complete mode qualification.
- [ ] **SETUP-005-D004 — Legacy abstraction boundary:** define which classes of
  non-EDU-aware software can be supported through wrappers or loaders in
  Dual mode and the qualification required for each class.
- [ ] **SETUP-005-D005 — Audio output routing:** decide whether any mode forwards
  EDP audio commands to the onboard VDP for local hardware playback. Retaining
  the complete audio command surface does not require this route; the currently
  scoped Rev 1 output is network/browser audio.
- [ ] **SETUP-005-D006 — Unsupported maintenance-command behavior:** define the
  closest practical stock-VDP-compatible command consumption, parser recovery,
  and externally observable failure behavior used in both exclusive modes for
  printer/USB serial, console/terminal, ZDI, Intel HEX, YMODEM, updater, and
  local-debug commands. Determine the stock behavior for each command and
  classify behavior by operating mode. Strict compatibility modes must permit
  stock-observable Bad Things—including corrupted output, resets, crashes, or
  Guru Meditations—where suppressing them would violate compatibility. Modes
  without that strict promise should improve the behavior with deterministic
  no-op, rejection, status, timeout, parser recovery, and diagnostics. Define
  explicitly which modes are strict before assigning command behavior.
- [ ] **SETUP-005-D007 — Peripheral-input ownership and routing (partially accepted):**
  K009/K010 select native USB keyboard input into P4, then stock keyboard
  packets over UART1 into EMOS, with explicit mainboard/extender selection.
  K001's browser acquisition was subsequently implemented under REMOTE-001;
  [ADR-0022](../decisions/ADR-0022-browser-keyboard-capture.md) selects common
  `KEYINPUT extender` admission and P4 provider arbitration. Applications use normal MOS key reads, sysvars,
  virtual keymap and callbacks; no aware-application relay is required. P4
  preserves relevant EDP-local keyboard state and packet semantics. K002/K003
  retain exact source/session/receiver choices; PORT-015/PORT-005 own native
  USB mapping, repeat and release, while REMOTE-001 retains browser-specific
  session details. The stock onboard VDP remains the source
  for physical devices where selected and remains the current VBlank clock.
  Mouse, multi-source composition and later aware-application EDU forwarding
  remain open. Copied Agon-originated events retain non-echo behavior.
  Rev 1 selects no direct onboard-VDP/EDP bridge; LINK-001 is later research
  and is not a keyboard dependency. The P4 USB connector/power addition is
  selected; no direct onboard-VDP/EDP bridge is implied.
- [ ] **SETUP-005-D008 — RTC authority and synchronization:** define the
  authoritative clock and read/set routing in Legacy, Exclusive Compatible,
  Exclusive Extended, and Dual modes. Specify how MOS RTC sysvars, the onboard
  VDP, the EDP system clock, and optional network time interact; prevent
  competing writers; define reset persistence, timezone expectations, conflict
  and failure behavior, and any capability/status reporting. Do not allow
  network synchronization to silently override an application-set clock unless
  the selected policy explicitly permits it.

When all eight decisions are accepted and incorporated into ADR-0014, change its
completeness to `Complete` and remove the resolved items from this task after
recording their disposition in the development log.

## Qualification and implementation gates

- Every accepted decision must update the corresponding QUAL-001 operating-mode,
  transport, MOS/sysvar, carve-out, blocker, and qualification fields.
- `SETUP-005-D001` and `D002` retain EMOS routing and lifecycle authority.
  PORT-008-D003 now sequences r02 circuit/component tests independently of a
  complete exclusive-mode implementation. Full SETUP-005-D003
  acceptance still gates production response routing, broad General Poll and
  response-class qualification, Exclusive Compatible integration, Dual's EDU
  result domain, and any general compatibility claim. Bounded physical-link
  analysis and stage tests that make no mode or MOS claim remain independently
  permissible under their applicable procedure gates. The
  [staged process](../qualification/staged-circuit-validation.md) does not
  release any mode-dependent freeze or authorize physical execution itself.
- `SETUP-005-D002` gates QUAL-002's complete legacy-absence, reset, failure, and
  recovery state matrix.
- `SETUP-005-D005` gates only optional onboard-VDP audio forwarding; it does not
  block PORT-004's guaranteed network/browser sink.
- `SETUP-005-D006` through `D008` continue to block their exact mode-dependent
  compatibility rows and physical procedures until accepted.

## Current routing analysis

D001's EMOS-owned VDU dispatcher/backend map and D002's lifecycle contract are
accepted. Exact response parsing, input integration, transport details, and
implementation remain gated by D003, D007, REMED-001, and their owning PORT
tasks.

The common required behavior of Exclusive Compatible and Exclusive Extended is:

```text
all application audio/video output -> EDP
selected browser/physical input    -> Extender compatibility path
Extender compatibility path         -> one coherent MOS response/sysvar domain
```

A normal resident program cannot transparently intercept untouched applications
through the documented MOS interrupt-vector API because the VDU restart handlers
are fixed in low ROM. The evaluated implementation families are:

1. **Hardware interposition:** place switching or gateway hardware between the
   eZ80, onboard VDP, and EDP. This offers strong transport ownership but is
   disfavored because requiring users to modify an Agon with a soldering iron is
   incompatible with the intended product experience.
2. **Narrow MOS transport support:** leave `RST.LIL 10h` and `RST.LIL 18h`
   unchanged while adding a selectable output backend to the MOS routines they
   already invoke. Legacy mode targets the onboard UART, Exclusive Compatible
   targets the Extender stock-UART transport, and Exclusive Extended targets
   the Extender enhanced forward transport.
3. **Runtime ROM shadowing or patching:** redirect the low-memory handlers using
   eZ80 mapping facilities if such a safe mechanism exists. Feasibility has not
   been established.
4. **Application loaders or binary rewriting:** adapt selected programs. This
   may support useful compatibility profiles but cannot establish a guarantee
   for arbitrary untouched binaries.

The immediate Extender keyboard route is USB keyboard → P4 → UART1 → EMOS. EMOS
preserves stock packet-handler effects and application interfaces; its
session/source-selection policy prevents conflict with onboard UART0 traffic.
A later selected physical onboard-input route may use an EMOS-owned relay and
controlled device configuration, but is not a prerequisite for native USB input.
D003/D007 retain the remaining parser/session decisions and broader mode scope.

## Review gate

Present the open decisions individually with recommendations, alternatives,
tradeoffs, prerequisites, and downstream effects. Do not implement MOS changes,
resident-service behavior, transport routing, mode transitions, or onboard-VDP
delegation until the corresponding decision is accepted and promoted into
ADR-0014.

## Accepted REMED-002 findings

The Author accepted SETUP-005's portions of F004, F009, and F018 through
[REMED-002](REMED-002.md). The audit evidence and provenance remain in
[`AUDIT-2026-09-01-001`](../decisions/AUDIT-2026-09-01-001-open-task-and-implementation-integrity.md).
These actions do not decide D003--D008 or authorize EMOS/EDP implementation.

1. [ ] **F004 policy split:** Under D006, decide the actor-explicit behavior for
   a complete but unsupported audio or updater command in each reachable mode,
   including full-byte consumption, bounded failure reporting, and whether the
   command is prohibited before transport activation. PORT-003 and PORT-004
   own parser and audio implementation contracts.
2. [x] **F009:** Promote every already accepted D002 lifecycle, transition,
   reset, discovery, recovery, and EMOS-ownership rule into ADR-0014 and
   `docs/architecture.md` before any downstream task consumes D002 as a
   satisfied implementation gate. Record the promotion in the development log.
3. [ ] **F018:** Resolve the disruptive beta transition carrier separately:
   name which processor restarts, where the requested target survives, which
   actor reissues or consumes it, when EMOS commits the target, and how failed
   or absent retained state returns to Legacy. If accepted, assign the EMOS
   implementation and cross-project qualification to a separately approved
   task rather than MODE-001 or MODE-002 by implication.

F009 is correction of normative authority, not a reopening of accepted D002
content. F018 remains an unresolved architecture question and must be presented
one decision at a time under this task's normal review gate.

### F009 promotion record

On 2026-09-01, ADR-0014 and `docs/architecture.md` received the complete
accepted D002 mode-state, transaction, transition, dispatcher, discovery,
activation, shutdown, reset, failure, recovery, and diagnostic-lifecycle
contract. The promotion also corrected two stale durable statements: the EMOS
committed-backend dispatcher is accepted rather than unresolved, and ordinary
application VDU is never mirrored even under controlled ownership. D003--D008
remain open, and the promotion deliberately leaves F018's disruptive-restart
actor and carrier unresolved.

PORT-008-D005, accepted 2026-09-09, authorizes the first idle-CLI ExCom/Legacy
implementation without restart. It preserves keyboard source/layout with fresh
destination screens. F018 is not a prerequisite for this bounded increment.

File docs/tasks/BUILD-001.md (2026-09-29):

# BUILD-001 — Native ESP-IDF/CMake P4 build authority

## Executive summary

**Accepted by the Author on 2026-09-28; frozen by the commit containing this
contract.** Replace
the P4 firmware's PlatformIO/SCons outer build with native ESP-IDF/CMake while
retaining Arduino-ESP32 as a pinned ESP-IDF component. The migration establishes
one authoritative build graph for source selection, compiler options,
dependencies, generated assets, partitions and linked objects. Under the
Author's 2026-09-28 sequencing amendment, it must first reproduce the latest
working pre-LCD ExCom product and provide that closure to AUDIT-010. LCD support
is redeployed only after the audit, review and accepted fixes; it is no longer
part of BUILD-001's initial equivalence baseline.

BUILD-001 is the prerequisite to AUDIT-010's baseline freeze. The
migration must finish, be reviewed and have its resulting source/build identity
recorded before AUDIT-010 A10-02 begins. Until the Author accepts this contract,
no implementation, dependency installation, firmware build, flash, reset, SD
mutation, production selection or audit-baseline change was authorized before
the Author accepted this document.

Created: 2026-09-28. Owning queue: `TODO.md`. Related owners:
[AUDIT-010](AUDIT-010.md), [LCD-001](LCD-001.md), [PORT-003](PORT-003.md),
[PORT-006](PORT-006.md) and [QUAL-001](QUAL-001.md).

## Purpose

Make ESP-IDF/CMake the sole top-level build authority for maintained ESP32-P4
firmware. Arduino-ESP32 remains available as an ESP-IDF component for the
Arduino APIs and upstream-derived code that currently depend on it. Native
ESP-IDF facilities remain native components. The resulting build must expose
the real linked translation-unit closure to CMake and emit a trustworthy
compilation database suitable for AUDIT-010's analysis tools.

The migration must answer these immutable questions:

B01-Q01 [x] Which checked-in artifact is the single authority for selected source
files, and how does CMake consume it without a competing PlatformIO selection?

B01-Q02 [x] How are the ESP-IDF release, tools, Arduino-ESP32 component, managed
components and non-managed third-party sources pinned and reproduced without
depending on unrecorded global developer state?

B01-Q03 [x] How does each maintained P4 build profile express configuration,
feature flags, dependencies, embedded files, partitions and output identity?

B01-Q04 [x] Which current PlatformIO environments are maintained product or
diagnostic profiles that must migrate, and which are obsolete or frozen evidence
that must be disposed explicitly rather than copied forward?

B01-Q05 [x] What evidence demonstrates build equivalence and explains every
material ELF, map, image-size, dependency or runtime difference introduced by
the build migration? Hardware functional equivalence remains B01-06.

B01-Q06 [ ] When can PlatformIO/SCons source selection and its generated CMake
facade be removed from the maintained P4 path without losing rollback,
provenance or a still-used profile?

## Scope and boundaries

The implementation scope is the maintained ESP32-P4 firmware build under
`vdp/`, its project-owned build helpers, configuration, source-selection data,
dependencies, generated assets, tests and current build documentation. Inspect
`../agon-emos` and `../mos-agondev` only where their tools or artifacts consume a
P4 build identity. Official `../../agon-docs`, `../../agon-vdp` and
`../../agon-mos` remain read-only references.

Preserve the selected pre-LCD application behavior and source closure unless a
change is strictly necessary to express the same program under ESP-IDF. Small
compatibility adapters are permitted only when identified individually and
covered by targeted tests. Porting Arduino-dependent application code to pure
ESP-IDF is outside scope. LCD code and its post-r61 source changes are outside
the initial native-equivalence and audit baseline; retain them for LCD-001's
later delta. Repairing LCD behavior, the late-mode20 allocation failure, browser
resource exhaustion, rendering semantics or unrelated defects is outside scope;
record newly exposed defects for their owning tasks.

Production firmware and `production/current.yaml` remain unchanged throughout
the migration. A successful development migration does not authorize production
promotion, a version number, a tag or publication. Do not remove the existing
working build path until the replacement has passed this contract and the Author
accepts the cutover.

Git history and superseded implementations are outside routine discovery. If
current authorities and artifacts cannot resolve a material build contract,
pause before historical review and present the exact question, proposed commits
or date range and stopping condition for Author acceptance.

## Decision register

The Author accepted these decisions with the contract on 2026-09-28.

| ID | State | Recommended decision | Consequence |
|---|---|---|---|
| B01-D01 | [x] Accepted | Native ESP-IDF/CMake becomes the sole top-level authority for maintained P4 builds. | The outer PlatformIO/SCons graph no longer decides which P4 objects are linked. |
| B01-D02 | [x] Accepted | Retain the exact compatible Arduino-ESP32 release as a pinned ESP-IDF component. | Existing Arduino APIs can remain while new native ESP-IDF code does not pass through an Arduino build authority. |
| B01-D03 | [x] Accepted | Retain one neutral, checked-in P4 source/profile manifest and generate or validate CMake inputs deterministically from it. | Source provenance remains machine-readable while CMake compiles the same declared closure; generated files are never a second editable authority. |
| B01-D04 | [x] Accepted | Provide one project-owned wrapper around the pinned native ESP-IDF tools and isolated tool state. | Operators receive repeatable profile selection and identity capture without relying on an ambient `idf.py` installation. |
| B01-D05 | [x] Accepted | Migrate every maintained current or diagnostic P4 profile; explicitly classify obsolete profiles instead of preserving them by default. | Cutover cannot silently strand a qualification or recovery build, while historical experiments do not become permanent maintenance obligations. |
| B01-D06 | [x] Accepted | Judge migration by source/configuration equivalence, explained binary differences and runtime qualification, not presumed byte identity. | Link ordering and native build metadata may change, but unexplained behavioral or material image differences block acceptance. |
| B01-D07 | [x] Accepted | Freeze AUDIT-010's source baseline only after BUILD-001 acceptance. | Static analysis observes the actual native CMake build graph rather than the current hybrid graph's unused object descriptions. |
| B01-D08 | [x] Accepted | Retire the maintained PlatformIO/SCons path only after rollback and clean-build evidence are retained. | The migration remains reversible until the replacement is accepted; frozen historical evidence is not rewritten. |
| B01-D09 | [x] Accepted 2026-09-28 | Rebase BUILD-001 equivalence on the last working pre-LCD Extender commit `6c6bea3beb2f8abc89c5b1f40a0e7dd0890a084d`, paired with EMOS v0.1.23 source `21a9ba27f1f346473d767c2c3053ee18e8911335`. | The combined LCD candidate and its startup failure remain evidence, but AUDIT-010 receives a proven pre-LCD closure; LCD-001 redeploys LCD only after audit fixes. |

## Work contract

### B01-01 [x] Research official integration contracts

The bounded conclusions and exact official sources are recorded in
[RESEARCH.md](BUILD-001/RESEARCH.md).

Read current official ESP-IDF build-system, component-manager, configuration,
tool-installation and compilation-database documentation. Read official
Arduino-ESP32 documentation for use as an ESP-IDF component and establish the
exact Arduino/ESP-IDF compatibility contract for the versions currently pinned
by the project. Consult source only where the official documentation is
insufficient. Record exact documentation, releases, commits and conclusions in
a bounded précis under `docs/tasks/BUILD-001/` before implementation.

B01-01a [x] Determine whether Arduino-ESP32 can be acquired reproducibly as a
managed component at the required version or must be supplied through a pinned
project-owned component source; record integrity and offline-build implications.

B01-01b [x] Establish the native ESP-IDF mechanism for per-profile `sdkconfig`
defaults, partition tables, embedded files, component dependencies and C/C++
compile options used by this project.

B01-01c [x] Establish how the native build emits `compile_commands.json`, map
files, size reports, flash images and dependency locks, and how each artifact is
bound to the selected profile and source revision.

### B01-02 [x] Inventory and preserve the current build contract

Inventory and controls are recorded in [INVENTORY.md](BUILD-001/INVENTORY.md).
The Author accepted the profile dispositions on 2026-09-28: migrate the console,
maintained MOS recovery and active PORT-008 non-release qualification profiles;
freeze superseded diagnostics; preserve rejected profiles as tombstones.

Before changing build files, record the exact repositories, production
selection, development source, PlatformIO platform/framework packages,
toolchains, generated component files and dependency locks. Inventory every
`platformio.ini` environment and classify it as maintained product, maintained
diagnostic, obsolete experiment or frozen evidence. Pause for Author review of
the classification before excluding a profile from migration.

B01-02a [x] Capture the current actual SCons compile and link actions for the
combined ExCom+LCD target, its selected translation units, definitions, include
paths, language standards, component dependencies, embedded assets, partition
table, `sdkconfig`, ELF/map/image sizes and immutable output hashes.

B01-02b [x] Run the currently applicable host-side checks and retain their exact
commands and results as pre-migration controls. Do not initiate a hardware run
without a separately reviewed procedure and explicit Author authorization.

B01-02c [x] Identify every script, document, CI action, qualification profile,
packaging step or operator procedure that invokes PlatformIO or consumes its
output layout.

### B01-03 [x] Review the native-build design

The proposal is recorded in [DESIGN.md](BUILD-001/DESIGN.md) and now pauses for
Author acceptance before any maintained build-path change. The Author accepted
the source/profile authority, wrapper and graph-validator design on 2026-09-28;
the Author then accepted managed Arduino-ESP32 3.3.11 and project-scoped
official ESP-IDF 5.5.5 source/tools. The additive implementation boundary
was accepted on 2026-09-28 through host equivalence only; hardware remains a
separate review gate.

Produce the proposed directory/component graph, source/profile authority,
dependency acquisition and lock strategy, isolated tool environment, output
layout, build-identity format and operator commands. Show how each maintained
profile maps to native ESP-IDF configuration and how the wrapper prevents stale
generated inputs. Pause for Author acceptance of the design before changing the
maintained build path.

B01-03a [x] Name the owner and lifecycle of every generated file. A generator
must fail on stale or inconsistent inputs and must not make generated CMake a
second hand-edited source of truth.

B01-03b [x] Define a build-graph validator that compares declared sources,
compiled objects, linked objects and compilation-database entries, with explicit
handling for framework and third-party component internals.

B01-03c [x] Define rollback so an unsuccessful native migration can restore the
preserved hybrid build without altering production or discarding evidence.

### B01-04 [x] Implement the native ESP-IDF/CMake build

Introduce the minimum checked-in CMake components, profile data and project-owned
wrapper needed to build the preserved P4 source closure with native ESP-IDF.
Retain Arduino-ESP32 as the pinned component selected in B01-01. Keep product
source edits separate from build changes and itemize any unavoidable adapter by
symbol, reason, test and removal condition.

B01-04a [x] Reproduce source selection, language standards, definitions, include
paths, link inputs, embedded assets, partitions, `sdkconfig` values and managed
dependencies for the combined ExCom+LCD target.

B01-04b [x] Map each accepted maintained diagnostic profile without reintroducing
an outer build graph or profile-specific hand-edited source list.

B01-04c [x] Emit immutable build identity, dependency lock, ELF, map, flash
images, size reports and canonical compilation database into a profile-specific
output directory.

B01-04d [x] Ensure a clean checkout can provision or locate the pinned tools and
components through documented, project-scoped commands. Do not modify global
developer packages or hide machine-specific paths in tracked files.

B01-04e [x] Apply the accepted native build authority to the bounded pre-LCD
Extender source `6c6bea3beb2f8abc89c5b1f40a0e7dd0890a084d` without importing
later LCD implementation. Preserve the existing native infrastructure changes
as a reviewable build-only delta and prove that selected project sources match
the retained r61 closure.

The resulting clean branch is `codex/build001-prelcd`. Corrected candidate
`build001-e7b35fd5-console-prelcd`, built at
`e7b35fd5bb5ab88b619a9a433a78ffa132119d19`, selects exactly the retained r61
product closure's 22 project and 11 vendored translation units and no LCD source
or dependency. It explicitly retains r61's staged-WebDAV profile setting and
accepts the private browser-reset endpoint only as a machine-local build input.
The initial boot-only procedure is
[PRELCD-BOOT-PROCEDURE.md](BUILD-001/PRELCD-BOOT-PROCEDURE.md).

### B01-05 [x] Validate build-graph and artifact equivalence

Host evidence and the one remaining static-analysis smoke are recorded in
[VALIDATION.md](BUILD-001/VALIDATION.md).

Run clean native builds and compare them with the B01-02 controls. Triage every
difference before hardware use; do not treat a successful link as equivalence.

B01-05a [x] Prove that every intended project translation unit is compiled once,
every linked project object is represented by the selected source authority, and
the canonical compilation database covers the real linked project closure.

B01-05b [x] Compare configuration, partition layout, embedded assets, symbols,
sections, map ownership, IRAM/DRAM/PSRAM/flash use and image sizes. Explain and
dispose every material difference.

B01-05c [x] Repeat clean builds in fresh output directories and compare outputs.
Record deterministic hashes where achieved; identify and bound any intentional
timestamp, path or tool metadata that prevents byte-for-byte reproducibility.

B01-05d [x] Run applicable host tests, build-graph validation and AUDIT-010's
accepted compiler/static-analysis smoke checks against the canonical database.
Tool findings remain audit inputs and are not repaired inside this migration
unless they prove a migration error.

B01-05e [x] Repeat B01-05a through B01-05d for the pre-LCD native closure and
compare it with retained hardware-tested r61 build
`uart-excom-console-r61-b2026-09-28-03-12-48Z`, factory SHA-256
`f794a8bba96f9afbfc1dae6eaa4554eb676880d76ffe74bda97bbebc7e160fea`.
The completed combined-LCD comparison remains failed/deferred evidence and does
not satisfy this replacement baseline.

### B01-06 [x] Perform bounded hardware equivalence qualification

After B01-05 passes, prepare a run sheet that names the exact firmware, bench
state, expected observations, rollback image, evidence paths and stopping
conditions. Read `HARDWARE.local.md` and current bench constraints, then obtain
explicit Author authorization before flashing or resetting the P4 or deploying
fixtures.

The first authorized attempt failed during ESP-IDF startup and rolled back
safely; see [HARDWARE-RESULTS.md](BUILD-001/HARDWARE-RESULTS.md). No functional
equivalence subitem passed. A corrected immutable candidate and reviewed
procedure dependency are required before B01-06 resumes.

The subsequent native pre-LCD boot canary failed at the identical
`sdio_mempool_create` assertion. Because that candidate selected no LCD source
or dependency, LCD is no longer a candidate cause of this boot loop. B01-HR07
owns diagnosis of the native `esp_hosted`/SDIO build boundary before another
hardware candidate.

B01-HR07 and B01-HR08 subsequently resolved that gate. Native CMake had honored
ESP-Hosted's whole-archive constructor while the working hybrid link omitted
it. Extender uses wired Ethernet, so commit `eadc2925` explicitly disables the
unused remote-Wi-Fi/ESP-Hosted configuration. The exact corrected candidate
booted twice without assertion, initialized USB input and wired Ethernet, and
served HTTP successfully. This is a boot-canary pass, not completion of the
functional-equivalence items below.

The first functional pass then exposed B01-HR09: candidate `d17cae79` booted and
passed Legacy, ExCom, keyboard and HTTP checks, but did not listen on staged
WebDAV port 8081. The migration had reproduced the source closure while omitting
r61's explicit `--staged-webdav` build variant. The corrected native profile now
defines that behavior directly and preserves the private reset endpoint through
a non-tracked wrapper argument. The amended exact-candidate procedure requires
renewed Author acceptance before another flash.

B01-06a [x] Verify flash, boot, EMOS transport, Legacy and ExCom output,
keyboard/input, SD service, browser service and clean recovery using targeted
tests chosen to detect build-migration regressions. Do not enable or test LCD in
this baseline qualification.

B01-06b [x] Run the mode20 static-grid control as an automated fixture with its
mode selected only in `/autoexec.txt`. After all automated passes finish, the
Author manually runs Nurples and other real applications that switch modes
after loading significant VDP-buffer assets. Record the pre-LCD mode-switch,
browser and gameplay result as an equivalence baseline. Do not grant automated
fixtures a mode-switch exception or infer anything about the later LCD resource
failure from a pre-LCD pass.

The controls and human runs are recorded in the accepted procedure and hardware
results. Static mode20 and the asset-heavy transition pass in Legacy; the same
Nurples executable retains 320-by-240 geometry after its late mode20 request in
native pre-LCD ExCom. B01-HR11 must compare the exact hybrid r61 image before
this can be classified as inherited behavior or a migration regression.

B01-06c [x] Keep runtime monitoring bounded. Reusable unattended tests must print
progress on the legacy mainboard display where practical and invoke the existing
audible success/failure notification without overwriting a retained failure
message.

The accepted detached `bench_job.py` terminal-hook contract, focused host tests
and retained hardware result demonstrate this behavior. The failure path plays
its cue before restoring the durable Legacy failure message; the success path
leaves its terminal result visible.

### B01-07 [x] Cut over maintained build consumers

After the Author accepts B01-05 and B01-06 evidence, update maintained build,
test, package and operator entry points to use native ESP-IDF/CMake. Update the
handbook and `docs/building.md`; preserve machine-local details only in ignored
records. Remove or quarantine PlatformIO/SCons generation only after every
B01-02 consumer has migrated or received an explicit disposition.

B01-07a [x] Retain enough identified hybrid-build material and instructions to
reproduce the pre-migration baseline during the agreed rollback interval without
presenting it as the current build authority.

B01-07b [x] Verify that maintained documentation contains one canonical P4 build
procedure and does not direct operators to stale PlatformIO output paths.

B01-07c [x] Present production impact separately. Do not promote, version, tag or
publish a native-built firmware until the Author accepts a production proposal
under the repository's normal promotion rules.

### B01-08 [x] Hand the canonical baseline to AUDIT-010

Record the accepted native-build commit, exact tool/component locks, selected
profile, build identity, artifact hashes and canonical compilation database in
AUDIT-010's baseline ledger. Implement its accepted A10-P02 pre-LCD baseline
amendment while preserving the original frozen A10-P01 combined-LCD direction
as superseded decision history.

B01-08a [x] Demonstrate that AUDIT-010 analysis commands consume actual linked
project actions rather than unused CMake object descriptions.

B01-08b [x] Preserve known LCD/mode20/browser behavior as deferred LCD-001
integration evidence. Do not include LCD code in the exhaustive audit baseline;
after AUDIT-010 review and fixes, require it as a redeployment regression.

## Gates and success criteria

B01-G01 [x] The Author accepted and froze this contract before B01-01 began.

B01-G02 [x] Official integration research and current-profile inventory are
complete before the native design is accepted.

B01-G03 [x] One checked-in authority selects sources and profiles; CMake's actual
compiled and linked graph agrees with it.

B01-G04 [x] The pinned native toolchain and Arduino component build every accepted
maintained P4 profile from clean project-scoped state.

B01-G05 [x] Material configuration, dependency, section, size and binary
differences are explained, and targeted host tests pass.

B01-G06 [x] Author-approved hardware equivalence checks pass with rollback
available and without changing production selection.

B01-G07 [x] Maintained consumers and documentation use the native path; obsolete
PlatformIO profiles and helpers have explicit dispositions.

B01-G08 [x] AUDIT-010 receives a trustworthy canonical compilation database and
an immutable accepted baseline before its exhaustive review begins.

BUILD-001 is complete only when B01-G01 through B01-G08 are satisfied and the
Author accepts the migration result. Completion does not by itself constitute
production promotion.

The native authority was cut over at `755d6f37`; the exact accepted audit
handoff is recorded in [AUDIT-010/BASELINE.md](AUDIT-010/BASELINE.md). Hybrid
r61 material remains explicitly gated rollback evidence. Selected production
v0.1.0/r02 is unchanged. The Author accepted the completed migration result on
2026-09-29; BUILD-001 is closed and removed from the active queue.

## Evidence and change discipline

Store research, inventories, comparison tables, raw build-graph reports and
reviewed result summaries under `docs/tasks/BUILD-001/`; keep bulky generated
build trees and machine-local paths out of Git. Every retained run names its
source commit, profile, tool/component identities, command, output hashes and
result. Use stable `B01-*` identifiers in findings and review discussion.

Commit the accepted contract separately before research or implementation.
Thereafter keep research/design, implementation, validation and cutover changes
reviewable; do not combine unrelated product fixes with build migration. Preserve
dirty work in all participating repositories and never rewrite frozen task
evidence.

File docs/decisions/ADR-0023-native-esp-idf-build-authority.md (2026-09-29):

# ADR-0023 — Use native ESP-IDF/CMake with Arduino as a component

- Status: Accepted
- Completeness: Partial
- Date: 2026-09-28
- Related task: BUILD-001
- Open-decision tracker: BUILD-001

## Context

The P4 firmware began as a PlatformIO Arduino project and later combined
Arduino and ESP-IDF under PlatformIO/SCons. Project source selection, dependency
locks, embedded assets, native ESP-IDF components and build identities were
added incrementally through PlatformIO pre-scripts.

The resulting hybrid build now has two materially different graphs. Generated
ESP-IDF CMake/Ninja metadata describes `.obj` nodes, while SCons separately
compiles and links `.o` nodes. The generated compilation database therefore
cannot authoritatively describe the linked project closure for static analysis
or maintenance. Preserving both orchestration layers also duplicates source,
configuration and dependency reasoning.

The firmware still depends materially on Arduino lifecycle and APIs. Removing
Arduino would turn build consolidation into a broad runtime port without a
demonstrated product benefit.

## Decision

Native ESP-IDF/CMake becomes the sole top-level build authority for maintained
P4 firmware. Retain the exact compatible Arduino-ESP32 release as a pinned
ESP-IDF component and preserve the Arduino `setup()`/`loop()` lifecycle during
the initial migration.

Use one neutral checked-in manifest as the authority for buildable profiles,
selected sources, configuration inputs, embedded assets and relevant compile
options. A project-owned wrapper validates that manifest, selects pinned
project-scoped ESP-IDF source and tools, prepares fresh profile-specific output
and invokes native `idf.py`. Generated CMake fragments are disposable outputs,
not editable authorities.

Validate migration through declared/compiled/linked graph agreement, exact
dependency and configuration records, explained artifact differences, host
controls and later Author-approved hardware equivalence. Do not presume binary
identity. Retain rollback and the current hybrid build until the Author accepts
cutover.

BUILD-001 owns unresolved profile disposition, detailed native layout,
implementation, validation and cutover. Production remains unchanged until a
separate accepted promotion.

## Consequences

1. ESP-IDF CMake, Ninja and the component manager compile and link the final
   P4 image; PlatformIO/SCons will leave the maintained path after accepted
   migration.
2. Arduino APIs and upstream-compatible VDP source structure remain available
   without making Arduino or PlatformIO the outer build authority.
3. ESP-IDF, its tools, Arduino-ESP32 and managed dependencies require exact
   source/tool identities and checked-in solver locks.
4. The native compilation database becomes eligible for AUDIT-010 only after a
   validator proves correspondence with linked project objects.
5. Following accepted BUILD-001 equivalence, native ESP-IDF/CMake is the
   operational development-build authority. PlatformIO procedures remain only
   for explicit bounded reproduction of identified hybrid evidence.

## Superseded decisions

This decision supersedes ADR-0002's selection of PlatformIO as the outer hybrid
build, ADR-0008's generated-CMake boundary and ADR-0009's PlatformIO wrapper as
the long-term maintained interface. Their rationale and transition evidence
remain historical. ADR-0003's exact pioarduino pin remains applicable to the
rollback build until BUILD-001 cutover disposes it.

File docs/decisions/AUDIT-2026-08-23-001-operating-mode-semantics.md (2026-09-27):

# AUDIT-2026-08-23-001 — Operating-mode semantics and ownership consistency

- Status: Historical audit complete — dispositions tracked by REMED-001 and SETUP-005
- Date: 2026-08-23
- Trigger: Author clarification during QUAL-001 Review Gate 2
- Scope: All tracked architecture, decisions, tasks, qualification data,
  procedures, hardware records, implementation, tests, generated artifacts,
  and development logs that encode Extender operating-mode semantics
- Owning task: QUAL-001

## Current applicability

This is the August 23 audit baseline, not the current operating contract.
[Architecture](../architecture.md) and
[ADR-0014](ADR-0014-edu-operating-modes-and-service-architecture.md) own accepted
mode semantics. [REMED-001](../tasks/REMED-001.md) tracks remaining conformance;
[SETUP-005](../tasks/SETUP-005.md) owns unresolved architecture decisions.
Do not restart the naming discussion or treat this record's original instructions
as a second work queue.

| Historical statement | Current disposition |
|---|---|
| No implemented modes; missing UART task | Bounded Legacy/ExCom routing exists under [PORT-008](../tasks/PORT-008.md). The original absence statements describe the audit date, not current firmware. |
| Compatible/Extended short forms | Current accepted abbreviations are ExCom and ExExt; Dual remains separately addressed mainboard VDU and EDP EDU. |
| Legacy implies total logical absence | Current architecture permits explicitly admitted Extender keyboard and foreground SD service in Legacy. That does not activate ordinary EDP display routing or waive electrical constraints. |
| Equal exclusive ownership | Both exclusive modes use EMOS-mediated ownership, but ExExt parallel transport and parity remain unqualified; ownership equivalence is not a timing or compatibility result. |
| Three-mode qualification data need replacement | Still open under [QUAL-001](../tasks/QUAL-001.md) RG2-02R and REMED-001. Bounded ExCom acceptance does not promote the obsolete matrix. |
| Full compatibility / maintenance question | Current architecture retains explicit maintenance deferrals and Legacy-only handling; a mode name does not restore omitted functionality. Broader decisions stay in SETUP-005. |
| Historical harness qualification | Applies only to its named circuit. [QUAL-002](../tasks/QUAL-002.md) and hardware owners retain full electrical gates; later receipts do not qualify the predecessor assembly. |

The findings, coverage table and disposition questions below retain their dated
observations. This applicability review does not revalidate every original
source observation, close Dual/ExExt work or grant physical qualification.

## Purpose and authority boundary

Audit the repository against the Author's clarified top-level operating-mode
boundaries before QUAL-001 accepts or promotes its mode matrix. This record
captures observed state and required disposition. It does not itself rename a
mode, resolve an implementation mechanism, amend ADR-0014, or authorize code,
MOS, transport, wiring, or generated-data changes.

QUAL-001 Review Gate 2 decision `RG2-02` is withdrawn and replaced by
`RG2-02R`. Current qualification mode records remain superseded candidate data
and must not be promoted before the accepted four-mode vocabulary and remaining
boundaries are reflected and reviewed.

## Clarified target contract

The audit uses the following Author-supplied boundary as its review baseline.
The names below are authoritative as accepted by the Author.

| Mode | Active display processors | Compatibility command transport | Reverse path | MOS/eZ80 ownership boundary |
|---|---|---|---|---|
| Legacy | Onboard VDP only; an attached Extender behaves exactly as if it were not attached | Stock onboard-VDP path | Stock onboard-VDP path | Onboard VDP and stock MOS retain all ownership. Official ID: `mode:extender:legacy`. |
| Exclusive Compatible | P4 EDP is the exclusive compatibility display processor | Stock VDP UART transport contract rather than the eight-bit forward path | Stock-compatible UART response path | EDP has the same unrestricted logical access to MOS integration hooks, canonical VDP sysvars, restart-vector routing, and related eZ80 assets that the onboard VDP has through MOS. Official ID: `mode:extender:exclusive-compatible`; **Compatible** is the accepted short form. |
| Exclusive Extended | P4 EDP is the exclusive display processor | Eight-bit forward parallel transport | Enhanced UART return contract, capabilities not yet selected | Same exclusive logical ownership and integration reach as Exclusive Compatible mode; transport enhancement does not reduce compatibility ownership. Official ID: `mode:extender:exclusive-extended`; **Extended** is the accepted short form. |
| Dual | Onboard VDP behaves normally while Extender capabilities are also active | Ordinary VDU remains with the onboard VDP; EDU addresses Extender separately | Extender uses a separate restricted result/return domain | Onboard VDP retains canonical MOS VDP sysvars and other exclusive stock assets. Extender must not collide with or impersonate that ownership; exact restrictions remain to be enumerated. Official ID: `mode:extender:dual`. |

“Logical access” is intentionally mechanism-neutral. The P4 cannot directly
write eZ80 memory across the presently selected physical links. Equivalent
ownership must be supplied through an accepted MOS/eZ80 route; this audit will
distinguish the required externally visible authority from the mechanism used
to implement it.

On 2026-08-23 the Author accepted **Exclusive Compatible mode** and
**Exclusive Extended mode** as the two official P4-exclusive names. The word
“Exclusive” is mandatory in formal naming; **Compatible** and **Extended** are
permitted short forms where the operating-mode context is unambiguous.
The Author also accepted **Dual mode** as the official name for simultaneous,
separately addressed onboard-VDP and EDP operation.

## Initial findings

### `MODE-AUDIT-F001` — “Legacy mode” is ambiguous between two incompatible system states

- Severity: Critical
- Observed state: ADR-0014 decision 20 and `docs/architecture.md` define legacy
  mode as a stock-machine bypass in which Extender is electrically and
  logically absent and the onboard VDP owns VDU, responses, input, sysvars, and
  maintenance facilities.
- Clarified boundary: A P4-active, P4-exclusive mode using the stock UART
  transport contract and full compatibility ownership is mandatory. The Author
  may retain “legacy mode” for the existing electrically absent bypass state
  and coin a new name for this strict-compatible P4 mode.
- Consequence: Existing prose may remain correct for the bypass state if its
  name is retained, but it must not be mistaken for the missing P4-exclusive
  stock-UART mode. Any use of “legacy” without naming the active processor and
  transport is unsafe until terminology is frozen.
- Disposition: Resolved for the two P4-exclusive states as Exclusive Compatible
  and Exclusive Extended. Legacy remains the bypass/inactive name. Amend
  affected architecture where it currently treats bypass as the only
  legacy/stock-compatibility profile.
- Known affected authorities: ADR-0014, `docs/architecture.md`, SETUP-005,
  AUDIT-001, QUAL-001, QUAL-002, PORT-008, SETUP-004 records, and the current
  qualification mode data and generators.

### `MODE-AUDIT-F002` — The required stock-UART exclusive mode is missing

- Severity: Critical
- Observed state: Current documents define one `EDP-exclusive compatibility
  mode`, generally associated with the split parallel-forward/UART-return
  architecture. They do not model a separate P4-exclusive stock-UART mode.
- Clarified boundary: Exclusive Compatible and Exclusive Extended are both
  P4-exclusive and have equivalent compatibility ownership, but use different
  transport profiles and may expose different reverse capabilities.
- Consequence: Current three-way mode matrices cannot represent the clarified
  contract by relabeling rows. A second exclusive identity and transport axis
  are required, or mode records must otherwise encode the distinction without
  losing ownership equivalence.
- Disposition: Names and IDs are resolved as
  `mode:extender:exclusive-compatible` and
  `mode:extender:exclusive-extended`; transport is intrinsic to those mode
  identities. Exact reverse capabilities remain unresolved.

### `MODE-AUDIT-F003` — Dual-mode ownership is directionally correct but incomplete

- Severity: High
- Observed state: ADR-0014 already gives ordinary VDU and canonical MOS VDP
  sysvars to the onboard VDP in Dual mode and requires a distinct EDU
  result domain. This matches the clarified top-level boundary.
- Gap: The repository does not exhaustively enumerate which MOS hooks, sysvars,
  completion flags, restart-vector routes, eZ80 memory, callbacks, input state,
  RTC state, and asynchronous packet domains are exclusive or safely shareable.
- Consequence: “Separate EDU result domain” is directionally sound but too
  abstract to qualify non-collision or to design the reverse transport.
- Required disposition: Produce an explicit ownership inventory after the
  current audit identifies every existing assumption and unresolved item.

### `MODE-AUDIT-F004` — “Access to MOS/sysvars/reset vectors” needs a logical-versus-physical distinction

- Severity: High
- Observed state: Existing accepted architecture correctly prohibits the P4,
  applications, and resident services from writing MOS-owned memory directly.
  Current physical transport also provides no direct memory bus.
- Clarified boundary: Both exclusive modes must enjoy the same externally
  visible integration authority as the stock VDP.
- Consequence: Documentation must state the compatibility contract as logical
  ownership mediated by MOS/eZ80 code, while separately tracking the unresolved
  routing mechanism. Otherwise “unrestricted access” could be misread as
  unsafe direct memory ownership.
- Required disposition: Preserve MOS ownership of memory writes while defining
  the exclusive EDP as authoritative source/consumer for the same logical
  hooks, parser effects, completion flags, and sysvar updates.

### `MODE-AUDIT-F005` — Current QUAL-001 candidate mode matrix is incomplete

- Severity: Critical
- Observed state: QUAL-001 currently assigns all 211 interfaces to the onboard
  VDP in `mode:extender:legacy`, all 211 ordinary VDU interfaces to the onboard
  VDP in cooperative mode, and 185 required/8 unsupported/18 unresolved entries
  to one EDP-exclusive mode.
- Clarified boundary: If “legacy” remains the bypass name, its current ownership
  row may remain. A new Exclusive Compatible row is required, and the current
  EDP-exclusive row is the predecessor candidate most closely aligned with
  Exclusive Extended. Dual remains onboard-VDP-owned for ordinary VDU.
- Consequence: `RG2-02` cannot be accepted as written. Reviewed modes,
  mode-expectations, obligations, fixture data, seed scripts, generated views,
  tests, and the task execution record require correction after terminology and
  the stock/bypass disposition are accepted.
- Required disposition: Keep RG2-02 open and suspend all authority promotion.

### `MODE-AUDIT-F006` — Stock UART compatibility has three distinct layers

- Severity: Critical
- Observed state: Official VDP `v2.16.0` consumes a byte stream at 1,152,000
  baud and returns protocol packets over `Serial2`. Its concrete binding uses
  fixed ESP32 TX, RX, RTS, and CTS pins, starts with RTS flow control, and may
  enable CTS/RTS full duplex. Stock MOS sends VDU bytes through UART0 from the
  fixed restart handlers and feeds UART0 receive bytes directly to the
  MOS-owned VDP packet parser.
- Clarified boundary: Exclusive Compatible mode requires the stock
  application and MOS-visible contract, but the current Extender attachment
  reaches eZ80 UART1 rather than the onboard VDP's UART0 path.
- Consequence: Documentation currently uses “stock UART contract” without
  consistently separating (a) VDU and response bytes, (b) MOS routing and
  parser effects, and (c) physical signaling and flow control. A software/MOS
  route can preserve the first two while using different physical pins, but
  that is not literally the stock electrical path.
- Required disposition: SETUP-005 must define the required fidelity at all
  three layers. PORT-008 then owns the selected implementation and
  qualification; no direct P4 write to MOS memory is permitted.

### `MODE-AUDIT-F007` — The current harness is not a stock-UART design candidate

- Severity: Critical
- Observed state: `light2-harness-r01` maps eZ80 PC0 to P4 GPIO22 as receive,
  and conditionally maps P4 GPIO12 to eZ80 PC1 as transmit through buffered
  direction control. That circuit has inherited 115,200-baud, 8-N-1,
  break-before-make evidence for the predecessor's enhanced
  parallel-forward/reverse-UART experiment. It was not designed to conform to
  the stock VDP UART's physical, flow-control, endpoint-routing, or firmware
  requirements. No separate RTS/CTS conductors are selected.
- Author disposition: Do not treat this circuit as the first stock-UART design
  target and do not qualify it into that role by incremental testing. The
  stock-UART profile requires a fresh hardware design review, a new design, and
  the complete validation and qualification appropriate to that design.
- Sequencing consequence: Hardware design does not gate development of the
  stock-compatible firmware behavior. Firmware work must first establish the
  exact endpoint, signaling, flow-control, timing, reset, failure, and recovery
  demands using hardware-independent boundaries and deterministic tests. Once
  those requirements are mature enough to drive circuitry, create the formal
  hardware design-review task and new versioned design. Physical testing begins
  only after that review is accepted.
- Existing-harness boundary: `light2-harness-r01` remains relevant only to the
  enhanced split-link profile and as inherited evidence about its own circuit.
  It supplies no stock-UART hardware authority or qualification claim.

### `MODE-AUDIT-F008` — PORT-008 owns only the enhanced split transport

- Severity: Critical
- Observed state: PORT-008's intent and work plan define one compatibility
  transport: eight-bit parallel Agon-to-P4 commands and UART1 P4-to-eZ80
  responses. Its General Poll, MOS parser, physical ownership, and bench stages
  all presume that profile.
- Gap: No task owns an end-to-end P4-exclusive stock-UART command and response
  profile, including selection, MOS routing, flow control, General Poll, exact
  packets, sysvar effects, malformed traffic, reset, and recovery.
- Required disposition: After mode names and transport fidelity are accepted,
  revise PORT-008 into explicit transport-profile work or split out a separate
  firmware task. Permit hardware-independent firmware implementation and host
  qualification to proceed. Create a separate hardware design-review task only
  after the firmware requirements can authoritatively drive the new design.
  Keep shared parser and compatibility evidence factored once; do not make two
  unrelated implementations of the official wire semantics.

### `MODE-AUDIT-F009` — “Strict” and “full compatibility” currently exceed the accepted v1 scope

- Severity: High
- Observed state: ADR-0014 promises compatibility only for the declared normal
  application-facing surface and explicitly carves out printer/USB serial,
  console/terminal, ZDI, Intel HEX, YMODEM, firmware updating, and local debug.
  Some current prose nevertheless calls EDP-exclusive operation “strict” or
  “complete” compatibility.
- Consequence: A final mode name containing “strict” or “compatible” can be
  read as restoring those omitted facilities. Transport fidelity and
  compatibility-surface coverage are independent claims.
- Required disposition: The naming discussion must either preserve the
  accepted carve-outs visibly or explicitly reopen them. QUAL-001 must encode
  the selected surface for both P4-exclusive modes rather than infer it from a
  mode label.

### `MODE-AUDIT-F010` — Exclusive Compatible and Exclusive Extended share ownership but not transport

- Severity: High
- Observed state: The clarified contract gives both exclusive modes the EDP as
  the sole audio/video compatibility authority and grants the same logical
  reach into MOS-owned parser effects, completion flags, sysvars, input
  integration, and related eZ80 state. Their required distinction is command
  transport and, eventually, enhanced reverse capabilities.
- Consequence: Most retained VDU, display, audio, RTC, input, malformed-stream,
  and MOS-state obligations apply to both exclusive modes. Copying those rules
  independently would invite drift; transport-specific obligations must remain
  distinct.
- Required disposition: Model both modes explicitly while factoring their
  common exclusive-ownership contract into one reusable profile or domain.
  Duplicate only the interface/mode expectation tuples required by the matrix,
  not the explanatory authority.

### `MODE-AUDIT-F011` — Dual mode does not imply stream or state duplication

- Severity: Medium
- Observed state: The Author accepted Dual mode as the official name. ADR-0014
  explicitly rejects sending one uncontrolled ordinary VDU stream to both
  processors because state and response packets can diverge.
- Consequence: “Dual mode” accurately says both processors are active, but must
  not be documented as dual ownership, mirrored VDU, or shared canonical
  sysvars.
- Disposition: Define Dual mode as VDU/onboard-VDP plus separately addressed
  EDU/EDP, with stock state remaining onboard-owned. “Dual” describes two
  active processors, not dual ownership, mirrored VDU, or shared sysvars.

### `MODE-AUDIT-F012` — Existing source-selection decisions generally survive the four-mode correction

- Severity: Medium
- Observed state: SETUP-004 and ADR-0013 classify upstream code by retained
  behavior versus replaceable or omitted physical implementation. Display,
  audio, RTC surface, parser, packet, and shared type decisions do not depend on
  whether P4 commands arrive by UART or parallel transport. Physical PS/2,
  classic video, analog audio, and maintenance-driver omissions remain
  deliberate.
- Consequence: The audit does not reopen the completed source survey. Its
  mode-dependent language must be expanded so retained behavior is required in
  both P4-exclusive modes and proof-of-concept input injection is not mistaken
  for the final exclusive input route.
- Required disposition: Correct reviewed SETUP-004 evidence and dispositions
  only where they encode a three-mode assumption, then regenerate their
  projections and dependency data. Do not alter accepted source dispositions
  without a separate substantive finding.

### `MODE-AUDIT-F013` — Dual-mode EDU behavior is not the same thing as stock VDU compatibility

- Severity: High
- Observed state: The candidate matrix assigns every ordinary VDU interface to
  the onboard VDP in Dual mode, which matches ADR-0014. Some obligations
  nevertheless associate EDP display, audio, and input behavior with those VDU
  interface subjects in Dual mode.
- Consequence: Those obligations may describe useful EDP behavior reached via
  EDU, but a stock VDU interface row cannot prove an EDU operation that has not
  yet been specified or mapped. This risks conflating stock compatibility with
  analogous extended capability.
- Required disposition: During QUAL-001 correction, keep stock VDU expectations
  onboard-owned in Dual mode. Represent EDP behavior there through
  explicit EDU interfaces, mapped obligations, or another reviewed subject
  type after the EDU contract exists; do not silently reuse stock VDU rows.

### `MODE-AUDIT-F014` — Qualification infrastructure needs bounded correction, not redesign

- Severity: Medium
- Observed state: The schema and semantic validator derive the complete
  interface/mode cross product from reviewed mode records and can support four
  modes. The one-time seed script emits exactly three modes, the compact matrix
  renderer hard-codes three columns, one unit test fixes the count at 633, and
  current reviewed/generated data contain three mode identities.
- Consequence: Adding the missing mode should produce 844 interface/mode tuples
  for the present 211 interfaces. The existing normalized model, duplicate
  protection, references, deterministic generation, and authority boundary
  remain valid.
- Required disposition: After terminology is accepted, update reviewed data,
  make rendering order data-driven or explicitly four-mode, change invariant
  tests to assert the reviewed cross product, and regenerate all projections.
  Do not hand-edit generated files.

### `MODE-AUDIT-F015` — No system-mode behavior is encoded in current firmware

- Severity: Low
- Observed state: No Extender system-mode ID, selector, transition, or routing
  implementation exists under `vdp/`. Current PORT-003 code implements a
  mode-neutral display backend and frame service. Occurrences of upstream
  `legacyModes` in `agon_screen.h`, `context.h`, and `vdu_sys.h` refer to the
  stock VDU display-mode interpretation, not Extender operating modes.
- Consequence: No firmware rollback is required. Future code and generated
  dependency queries must distinguish “legacy display modes” from Extender
  “legacy mode.”
- Required disposition: Reserve stable machine IDs for Extender operating
  modes and use qualified terminology in prose. Do not rename upstream
  `legacyModes`, because preserving upstream names supports future merges.

### `MODE-AUDIT-F016` — Legacy/bypass is also an electrical contract

- Severity: High
- Observed state: ADR-0014, QUAL-002, and AUDIT-001 already require a connected
  and powered or unpowered Extender to be electrically and logically absent in
  legacy mode. The current harness leaves production isolation, power order,
  reset order, and released shared lines unqualified.
- Consequence: Retaining “legacy mode” for bypass is semantically coherent, but
  it is not satisfied merely by firmware deciding not to parse commands. The
  inactive board must release every shared net and avoid back-powering,
  contention, reset interference, and partial activation.
- Required disposition: Keep QUAL-002 as owner and expand its state matrix to
  all four modes after lifecycle decisions. Legacy/bypass remains its strongest
  absence case.

### `MODE-AUDIT-F017` — Top-level capability prose is incomplete, not contradictory

- Severity: Medium
- Observed state: README promises stock-compatible UART communication and an
  enhanced one-way parallel path but does not assign them to operating modes.
- Consequence: The public overview supports the clarified product direction but
  leaves readers unable to tell when each transport or VDP is authoritative.
- Required disposition: Add a compact operating-mode summary only after final
  names and boundaries are accepted.

### `MODE-AUDIT-F018` — Historical records and mode-neutral procedures do not need rewriting

- Severity: Low
- Observed state: Development logs record decisions as they occurred, including
  the earlier three-mode model. Existing P4 canary and frame-service procedures
  do not exercise system modes; their uses of “legacy” generally mean the
  predecessor repository or inherited evidence.
- Consequence: Rewriting history would destroy provenance, while globally
  replacing “legacy” would corrupt unrelated meanings.
- Required disposition: Add a dated correction/supersession entry when the new
  taxonomy is accepted. Amend only active or normative records. Preserve old
  logs, run manifests, and mode-neutral procedures as historical evidence.

### `MODE-AUDIT-F019` — Hardware terminology also overloads “legacy”

- Severity: Medium
- Observed state: The hardware profile names its UART section
  `legacy_uart_candidate`, where “legacy” means the inherited stock-compatible
  UART target, while fixture paths use `legacy-evidence` to mean provenance
  imported from the predecessor repository.
- Consequence: Neither term identifies Extender legacy/bypass mode. Automated
  searches can therefore produce false mode matches.
- Required disposition: Preserve `legacy-evidence` as provenance vocabulary.
  After transport names are accepted, rename or explicitly qualify
  `legacy_uart_candidate` as the stock-VDP UART transport candidate and update
  dependent references through the profile's normal revision process.

### `MODE-AUDIT-F020` — Active task and authority correction order is constrained

- Severity: High
- Observed state: ADR-0014 and `docs/architecture.md` are the normative mode
  authority; SETUP-005 owns unresolved architecture; QUAL-001 is paused before
  mode promotion; PORT-008 and QUAL-002 consume those decisions; SETUP-004 and
  AUDIT-001 are accepted planning inputs; generated qualification and
  dependency files are projections.
- Consequence: Editing consumers first would create another incoherent state.
- Required disposition: Apply accepted corrections in this order: (1) freeze
  names and boundaries in SETUP-005/ADR-0014/architecture, (2) revise active
  transport and qualification tasks, (3) correct reviewed source data, (4)
  regenerate projections and dependency artifacts, (5) rerun validators and
  tests, and (6) resume QUAL-001 Review Gate 2.

## Coverage register

| Area | State | Initial observation |
|---|---|---|
| Normative architecture and ADRs | Reviewed | ADR-0014 and `docs/architecture.md` correctly define legacy/bypass and Dual ownership but originally contained only one P4-exclusive mode. ADR-0013 source boundaries remain valid. |
| Active setup/port/qualification tasks | Reviewed | SETUP-005 must own the four-mode correction; PORT-008 lacks stock-UART-exclusive work; QUAL-001 is correctly paused; QUAL-002 remains the absence/power owner; PORT-003 through PORT-007 need only bounded mode-language corrections. |
| Reviewed and generated qualification data | Reviewed | Three-mode data are incomplete. Core model is reusable; seed, renderer, fixed-count test, reviewed records, and generated projections require correction and regeneration. |
| Hardware and transport records | Reviewed | The PC0/PC1 circuit belongs to the enhanced split-link experiment and is not a stock-UART candidate. Stock UART requires a fresh firmware-driven hardware review and new design; shared-pin and electrical-absence work for the existing enhanced harness remains unqualified. |
| Firmware and tests | Reviewed | No Extender system-mode implementation exists. PORT-003 is mode-neutral. Upstream `legacyModes` is unrelated display-mode vocabulary and must remain recognizable for mergeability. |
| Procedures and run manifests | Reviewed | Current procedures and runs are mode-neutral and use “legacy” chiefly for predecessor provenance; no result is invalidated by the taxonomy correction. |
| Development logs and historical evidence | Reviewed | Preserve historical statements. Add a current supersession entry after decisions are accepted rather than rewriting prior logs. |

## Artifact disposition map

| Class | Artifacts | Disposition after Author decisions |
|---|---|---|
| Normative authority | ADR-0014; `docs/architecture.md` | Amend first with final names, four functional boundaries, common exclusive ownership, and mode-specific transports. |
| Open architecture tracker | SETUP-005 | Expand D001–D008 across four modes; add or split questions where strict UART and enhanced reverse contracts differ. |
| Active qualification authority candidate | QUAL-001 task, reviewed YAML, seed script, renderer, tests | Keep RG2-02 open; correct to four modes and 844 tuples; separate stock VDU from EDU behavior in Dual mode; regenerate. |
| Transport and physical qualification | PORT-008; QUAL-002; `light2-harness-r01` | Add hardware-independent stock-UART firmware ownership and preserve enhanced split-link work. After firmware requirements mature, create a separate stock-UART hardware design-review task and new design. Retain legacy/bypass electrical absence qualification; do not repurpose `light2-harness-r01` as stock-UART hardware. |
| Accepted source survey and planning | ADR-0013; SETUP-004; AUDIT-001; PORT-004/005 | Preserve dispositions and findings; add bounded correction notes and regenerate derivative inventories where mode scope changes. |
| Implementation | `vdp/` and current host/target tests | No corrective code action now; modes are not implemented. Later implementation waits for accepted architecture and task gates. |
| Public overview | README | Add mode summary after terminology is frozen. |
| Historical evidence | development logs, procedures, run manifests, `legacy-evidence/` | Preserve; add supersession provenance later. |

## Historical questions referred to the owning tasks

These are audit findings, not decisions or an independent actionable checklist.
Consult SETUP-005 and REMED-001 for current decisions and remaining work;
this historical list does not reopen resolved questions.

1. Does “full compatibility” restore the maintenance/operator facilities
   currently carved out of Extender v1, or do those carve-outs apply to both
   exclusive modes despite the broader phrase?
2. Which exact physical and flow-control requirements must the new stock-UART
   design satisfy after firmware work has frozen its externally visible,
   endpoint, timing, reset, failure, and recovery demands?
3. Which reverse capabilities distinguish Exclusive Extended mode once both
   exclusive modes have equal canonical MOS ownership?

## Audit conclusion

The clarified design is a four-mode system, not a corrected three-mode system:

1. legacy/bypass — Extender inactive and indistinguishable from absence;
2. Exclusive Compatible mode — P4 exclusive over the stock-UART contract;
3. Exclusive Extended mode — P4 exclusive over the enhanced transport; and
4. Dual mode — both processors active, but with separate command
   and state domains and onboard VDP primacy for stock VDU/MOS state.

The repository has no implemented system-mode behavior to remove. Its accepted
source-selection and completed display work remain usable. The material defects
are in mode vocabulary, transport task coverage, qualification classification,
and the boundary between stock VDU compatibility and EDU capability. The
correction must begin with a naming and contract discussion, then proceed
through the ordered authority map above before QUAL-001 Review Gate 2 resumes.

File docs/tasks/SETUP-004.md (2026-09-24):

# SETUP-004 — Determine upstream I/O driver disposition

## Current applicability

This completed survey records dispositions, not implementation of every retained
service. [ADR-0013](../decisions/ADR-0013-vdp-survey-integration-boundaries.md)
and [architecture](../architecture.md) own accepted boundaries;
[building](../building.md) identifies actual console selection.

| Area | Current disposition / limit |
|---|---|
| Video | Retain original depth controllers/native rows through narrow P4 bindings. The generic replacement proposal is superseded by stock restoration. |
| Input | Omit FabGL PS/2 acquisition. P4 USB/browser/agent providers use common EMOS admission under ADR-0022. Application-forwarded non-echo events and mouse integration remain separate scope. |
| Audio | Runtime/synthesis retention is intended implementation; accepted command consumption is not audio output. PORT-004 owns remaining work. |
| Storage | PORT-007 owns future P4-local SD. Current mainboard SD uses the EMOSlet, not FabGL FileBrowser or a P4-local filesystem. |
| Hardware | r01 is historical survey context. HW-001/r02 and HW-002/r03 have separate states/evidence; none is selected by this survey. |
| Generated inventories | Retained extraction/decision evidence for their baseline; not proof of later compiled profiles. Use the durable dependency workflow and current console manifest. |

Dated execution records preserve earlier analysis. Current ADRs and this map
govern reuse; survey completion starts no build or qualification campaign.

## State

- Status: Complete — all subsystem dispositions accepted or explicitly deferred
- Started: 2026-08-20 20:52 EDT
- Finished: 2026-08-22 06:55 EDT

## Intent

Review the official VDP and vdp-gl hardware-facing I/O facilities and decide
which Extender must retain, replace, stub, omit, or defer. Reduce unnecessary
ESP32-PICO-to-P4 porting while preserving the externally observable behavior
required for VDP backward compatibility.

Begin from the documented VDU interface rather than implementation internals.
The Author reviewed command families in
[`SETUP-004/VDU-inventory.md`](SETUP-004/VDU-inventory.md) to establish the intended
compatibility boundary. Driver disposition follows
from that product-level compatibility boundary.

This is a survey and disposition task. It does not implement driver removals,
replacement drivers, compatibility adapters, or build-selection changes.

## Authority and inputs

- [ADR-0013 — VDP survey findings and integration boundaries](../decisions/ADR-0013-vdp-survey-integration-boundaries.md)
- [SETUP-003 — official VDP structural inventory](SETUP-003.md)
- [SETUP-003 generated compiler and include evidence](SETUP-003/generated/)
- [Light 2 harness r01 first design target](../../hardware/designs/light2-harness-r01/README.md)
- Official VDP release `v2.16.0` at
  `c7ac293d2aa81ddfa693390549bcd909069c8fc3`
- vdp-gl tag `all-the-plots` at
  `ac2dd5986daf496c43ae8e7fe41836274aec54a0`

## Required dispositions

Assign exactly one provisional disposition to every material hardware-facing
subsystem:

- **Retain:** required substantially as implemented, subject to P4 adaptation.
- **Replace:** behavior is required but implementation becomes project-owned.
- **Stub:** an interface must remain, but no physical implementation is needed.
- **Omit:** neither implementation nor compatibility surface is required in the
  Extender image.
- **Defer:** evidence is insufficient; record the exact unresolved dependency
  or product decision.

Provisional dispositions become accepted architecture only after Author
review. Any accepted decision with broad or durable consequences receives an
ADR or an amendment to ADR-0013.

## Work

1. Derive a candidate inventory from compiler evidence, source includes,
   PlatformIO library selection, and targeted source searches. At minimum
   review:
   - **1.a** Arduino, ESP-IDF, and FreeRTOS hardware abstractions used by those
     areas;
   - **1.b** RTC and peripheral-device drivers;
   - **1.c** UART, GPIO, ADC, I2C, SPI, timers, interrupts, and ULP facilities;
   - **1.d** FabGL VGA, composite-video, display-controller, and canvas drivers;
   - **1.e** sound generators and physical audio output;
   - **1.f** PS/2 keyboard and mouse controllers;
   - **1.g** network, updater, and transfer facilities;
   - **1.h** storage and filesystem interfaces.

   For each candidate, record:
   - owning project and source files;
   - selected translation units and header-defined implementation;
   - direct hardware and architecture dependencies;
   - startup, task, interrupt, callback, and global-state connections;
   - VDP commands, responses, status packets, or application-visible
     behavior;
   - present physical owner: main board, onboard VDP, Extender, or none;
   - proposed disposition and rationale; and
   - dependencies on other disposition decisions.

   Trace each proposed omission far enough to identify compile/link fallout.
   Distinguish removing an independently selected translation unit from
   severing a header-defined or global-state dependency inside the effective
   VDP translation unit.
2. Identify facilities that are not needed physically but whose protocol
   surface must remain for backward compatibility. Recommend a project-owned
   adapter, inert stub, explicit unsupported response, or continued delegation
   to the onboard VDP as appropriate.
3. Produce a compact review matrix grouped by subsystem. Keep unresolved
   decisions here rather than in an ADR.
4. Present the matrix to the Author in manageable groups and record accepted
   dispositions. Create follow-on implementation tasks only after review.

## Initial accepted boundary

Per ADR-0013, FabGL PS/2 controller and physical keyboard/mouse support will
not be ported or built for Extender. Mainboard PS/2 acquisition remains
with its onboard VDP; P4 USB/browser/agent acquisition is project-owned. The survey must still trace protocol and compile-time coupling
before assigning the precise **Omit**, **Stub**, or **Replace** mechanics.

Retain keyboard and mouse command parsing and externally visible protocol state
needed by exclusive compatibility mode, while leaving broader Dual-mode composition
unresolved. This retained surface does not reverse the physical-driver boundary:
upstream PS/2 acquisition remains excluded, and couplings such as sprite command
`&40` calling mouse-owned cursor code require a project-owned adapter or
delegation boundary.

Retain the complete buffered-callback facility unconditionally. Commands 80 and
81 modify EDP-local registration state, while callback execution can alter or
suppress later protocol packets. Exclusive compatibility mode requires those
indirect MOS-visible effects to match the official VDP behavior.

EMOS owns ordinary VDU dispatch, transport admission and committed mode.
Explicit EDU bindings must use its documented interface; no independent
application/resident bypass is supported. The generalized EDU surface is not
implied complete by this survey. See
[ADR-0014](../decisions/ADR-0014-edu-operating-modes-and-service-architecture.md).

### Known diagnostic-output constraint

Official VDP `v2.16.0` implements buffered command 128 with
`force_debug_log()` through `DBGSerial`, which is stock UART0 on ESP32 pins 3
and 1. It reports the stream count, prints transform matrices in readable form,
or emits the entire first buffer stream as hexadecimal. It sends no VDP protocol
packet and modifies no MOS sysvar.

The P4 port must bind this command to an explicit EDP diagnostic console or log
sink rather than inherit the upstream UART mapping. Because output is
synchronous and unbounded by command semantics, large buffers can stall VDU
processing and may expose task-latency or watchdog problems. Preserve that
behavioral warning during implementation and qualification.

## Outputs

- A machine-readable driver/subsystem inventory under
  `docs/tasks/SETUP-004/generated/`.
- A concise review matrix under `docs/tasks/SETUP-004/`.
- Task-local reproducible extractors under `docs/tasks/SETUP-004/scripts/` if
  SETUP-003 evidence is insufficient.
- Follow-on implementation tasks and accepted ADR updates after review.

## Work 1.a execution record

The deterministic extraction classified 764 scoped evidence items: 719 belong
to 13 framework/runtime candidates and 45 are explicitly assigned to later
Work 1 boundaries. No item is ambiguous or unclassified. The passing
[coverage audit](SETUP-004/generated/work-1a/coverage.yaml) and generated
[disposition matrix](SETUP-004/disposition-matrix.md) record the completed
Author review. Every candidate has an accepted disposition; explicitly deferred
design and qualification details remain in their named follow-on work.

### Work 1.a Author review

- **Accepted — `framework-unused-wifi-include`: Omit.** Official VDP v2.16.0
  includes `WiFi.h` but has no WiFi API consumer or runtime activation. Remove
  the include from the Extender source; no adapter or stub is required.
- **Upstream contribution opportunity:** test removal of the same include in an
  otherwise untouched v2.16.0 checkout using the exact upstream build. If that
  proves no accidental transitive-header dependency, propose the one-line
  cleanup upstream. This is not required for the Extender port and does not
  authorize changing the official checkout or opening a PR.

### Work 1.a question register

These questions were resolved one at a time. Each answer is recorded as
**Accepted**, **Deferred** to a named task or decision, or **Rejected** with a
replacement disposition. Work 1.a closed after every question was disposed and
the generated audit and projections were refreshed.

#### W1A-Q01 — Arduino core types and utilities

- **Status:** Accepted — Retain (2026-08-21)
- **Candidate:** `framework-arduino-core-types`
- **Question:** Retain the Arduino source-level contracts used by vendored
  agon-vdp, vdp-gl, ESP32Time, and CRC code, including `Arduino.h`, `String`,
  and `map()`?
- **Recommendation:** **Retain.** They are available under the accepted hybrid
  framework and avoiding them would require unnecessary upstream-source
  surgery.
- **Alternatives/tradeoffs:** Replace with standard C++ or project-owned
  equivalents, increasing divergence and future upstream-merge work; omission
  would fail compilation.
- **Downstream effect:** Individual hardware APIs remain subject to their own
  disposition; this accepts only the shared source compatibility layer.
- **Disposition:** **Retain.** Preserve the shared Arduino source-compatibility
  layer; hardware-facing APIs remain independently reviewable.

#### W1A-Q02 — Arduino sketch lifecycle

- **Status:** Accepted — Retain (2026-08-21)
- **Candidate:** `framework-arduino-sketch-lifecycle`
- **Question:** Retain Arduino `setup()`/`loop()` lifecycle idioms and upstream
  startup shape on P4?
- **Recommendation:** **Retain.** The hybrid-framework decision and physical
  canary already qualify this lifecycle, and preserving it minimizes upstream
  structural divergence.
- **Alternatives/tradeoffs:** Replace it with a pure ESP-IDF `app_main`, gaining
  direct lifecycle control at the cost of needless porting and merge burden;
  omission removes firmware startup.
- **Downstream effect:** The contents and ordering of `setup()` remain subject
  to display, transport, audio, and input dispositions.
- **Disposition:** **Retain.** Preserve upstream `setup()`/`loop()` structure;
  adapt startup contents only as owning subsystem decisions require.

#### W1A-Q03 — Arduino Stream/Print contract

- **Status:** Accepted — Retain (2026-08-21)
- **Candidate:** `framework-arduino-stream-contract`
- **Question:** Retain the abstract Arduino `Stream`/`Print` byte-stream
  interface as the compatibility seam used by VDP command processing and
  internal buffer streams?
- **Recommendation:** **Retain.** It separates parser behavior from physical
  transport and allows Extender-owned transports to replace stock UART without
  rewriting the parser family.
- **Alternatives/tradeoffs:** A project-owned stream abstraction could reduce
  Arduino coupling but would touch pervasive upstream interfaces; omission is
  compile-incompatible.
- **Downstream effect:** This does not retain `Serial2`, UART pin mappings, or
  stock duplex behavior; those are W1A-Q05 and later peripheral decisions.
- **Disposition:** **Retain.** Preserve the abstract byte-stream seam without
  retaining stock `Serial2`, pin assignments, or duplex behavior.

#### W1A-Q04 — Arduino timing services

- **Status:** Accepted — Retain (2026-08-21)
- **Candidate:** `framework-arduino-timing`
- **Question:** Retain portable Arduino `millis()`, `micros()`, `delay()`, and
  `delayMicroseconds()` calls where their owning subsystem survives?
- **Recommendation:** **Retain**, subject to subsystem-specific timing
  qualification. The accepted target framework supplies them and replacing
  every call adds divergence without an identified benefit.
- **Alternatives/tradeoffs:** Replace globally with ESP-IDF timing APIs for
  finer control, at the cost of broad source changes; omission breaks timing,
  timeout, and pacing behavior.
- **Downstream effect:** Low-level drivers may still require targeted timing
  replacement after Work 1.c–1.f determines their disposition.
- **Disposition:** **Retain.** Preserve portable Arduino timing calls where the
  owning subsystem survives, subject to later driver-level qualification.
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

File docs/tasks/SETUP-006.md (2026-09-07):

# SETUP-006 — Establish the Light 2 Extender wiring target

## State

- Status: On hold — incomplete. Naming/scaffold work and the r02 design and
  assembly records are retained under HW-001. Full-circuit wiring is incomplete
  and the complete circuit is untested; construction and as-built completion
  are paused by the Author as of 2026-09-07.
- Started: 2026-08-24 19:09 EDT
- Finished: --

## Intent

Develop one coherent, human-buildable electrical wiring target for the Agon
Light 2 and Olimex ESP32-P4-DevKit prototype while preserving exact provenance,
machine-readable connectivity, construction guidance, and reviewable diagrams.
Build the task incrementally as firmware requirements and electrical decisions
become concrete rather than attempting to design the complete carrier in
advance.

This task began from the then-adopted `light2-harness-r01`, its vendored
legacy evidence, and the corresponding read-only legacy repository. Existing
files are evidence and inputs, not proof that their terminology, presentation,
mode scope, electrical design, or qualification claims are suitable for the
current product.

## Working boundary

Provisional inventories, naming records, source extracts, diagram generators,
draft diagrams, and review evidence belong under `docs/tasks/SETUP-006/` while
their permanent roles and maintained file structure are being discovered.
Accepted recurring hardware definitions will later be promoted or synthesized
into a role-named location under `hardware/`; the task directory will retain
bounded decision and development evidence.

This task does not by itself authorize moving a wire, changing a component,
advancing a harness revision, powering hardware, connecting the Agon, flashing
firmware, or executing a physical test. Those actions require their applicable
versioning, design-review, procedure, and qualification gates.

## Authority and inputs

The following are the historical research inputs. Suspended construction used
the r02 connectivity basis, maintained physical schematic, and separate
`wiring-order/` under HW-001, following PORT-008-D003/D004 and the
[staged process](../qualification/staged-circuit-validation.md).
The permanent input-bias proposal was rejected; HW-001-Q011 retains the
unresolved input-state question on hold. Signal views remain tracing/debugging
references. No wiring sequence is currently authorized for execution.

1. `hardware/designs/light2-harness-r01/profile.yaml` and its current README.
2. The files under `hardware/designs/light2-harness-r01/legacy-evidence/`,
   especially `wiring-diagram.svg` and `carrier-breakout-design.md`.
3. The read-only legacy project's `design/README.md`, which contains the
   generically named Markdown companion text for `wiring-diagram.svg`.
4. The read-only legacy project's `design/reset-actuator-module.md`, which is
   the only recovered design-intent record for a Pi-controlled P4 `ESP_EN`
   configuration of the reusable reset breakout. It does not document the
   photographed Pi-to-Agon configuration, and its referenced SVG is missing.
5. The accepted operating-mode and hardware boundaries in REMED-001,
   SETUP-005, PORT-008, QUAL-002, and the operating-mode audit.
6. `docs/versions/README.md` for controlled wiring, profile, fixture, diagram,
   procedure, and physical-assembly identities.
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

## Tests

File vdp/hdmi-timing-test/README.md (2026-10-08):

# Standalone HDMI timing pattern

Experimental P4-PC fixture for [HDMI-002](../../docs/tasks/HDMI-002.md).
It replaces the complete P4 application temporarily. No Agon routing, keyboard,
Ethernet, SD, LVGL or game services are started. Product renderer code is unchanged.

The current r02 trial generates custom 848×480 near 60 Hz with supported PLL240/7,
two 480 Mbps DSI lanes and matched 1104×517 totals. The exact 33.75 MHz DMT/APLL
proposal was not deployed; the task explains the silicon-revision concern.

`pattern.c` writes BGR888 directly into the panel-owned framebuffer before DSI
starts. It is never repainted: subsequent USB logs record only frame-DMA progress
and HDMI hot-plug detection. These do not establish picture correctness. The
Author must inspect the outer border, all four corner labels, channel bars and
centered unscaled 512×384 field. Circle/square shapes help reveal stretching.

Use the repository Python environment:

```sh
.venv/bin/python tests/display/hdmi_timing_pattern_test.py
.venv/bin/python vdp/hdmi-timing-test/build.py --output agents/hdmi002/new-build
```

The builder requires the existing native ARM tools from the P4-PC demonstration
and ESP-IDF 5.5.5 at the pinned revision. It refuses an existing output directory,
freezes source/hash provenance, builds and merges the image, then checks compiled
source closure and factory segment contents. `manifest.json` and `build.log`
remain with the generated image. It does not flash.

Deployment requires the current machine-local bench identity, checked silicon
image headers, retained exact rollback and flash/readback evidence. Consult the
task and `HARDWARE.local.md`; do not reuse old private bench addresses or select
production from the newest generated file.

r03 adds `--timing 512x384`, `684x384`, `320x240` and `428x240` for isolated
native-active experiments. The default remains848×480. All retain the accepted
PLL240/7,1104×517 totals and480Mbps lanes; front porches absorb the change in
active dimensions. No resampling or black active border substitutes for native
pixels. `timings.py` owns the explicit experimental tuples; generated
`timing_config.h` and the manifest preserve the selection in each fresh build.
The two wide candidates round width to a multiple of4; aspect rounding is in the
manifest. These are not supported VDU modes. The512×384 physical trial fails
visual review despite continuous DMA progress. The Author now selects widescreen
HDMI with a centered512×384 game canvas;684×384 is the next standalone signal
trial. Its edge/color pattern covers the carrier, before centered-game integration.
Picture acceptance is separate from a successful build or frame-DMA counter.

r04 centers a512×384 image inside684×384, and320×240 inside428×240, with black
sidebars. The outer white border marks the complete carrier; the inner border
marks the logical image. Each color label is centered over its bar. This fixes
the r03 pattern's constant-spacing labels without changing timing or bridge
initialization. The Author confirms the r03 684×384 signal steady with correct
circle/square aspect and all outer edges visible. The r04 centered layout also
passes Author review as correct and steady. These are bounded pattern results,
not qualification of full Extender services or games at this timing.

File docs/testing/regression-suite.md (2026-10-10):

# Firmware qualification suite

The canonical executable authority is [`../../qualification/`](../../qualification/README.md).
The maintained workflow has two independent commands. The first command builds
and flashes one exact component commit and independently verifies the installed
bytes and boot identity; run it separately for P4 and EMOS. The second command accepts both receipts,
runs every applicable installed-hardware case. The separate offline source
suite remains available for development regressions. A host or emulator pass is never described as
hardware validation or firmware acceptance. Acceptance requires a successful
complete canonical run against verified installed bytes.

The maintained regression runner exercises the current Extender host, browser
and native `p4-console` build closure without flashing or resetting either
board, changing either SD card, launching a foreground application, or attaching
an extra browser consumer to the P4. The explicit case and exclusion inventory
is `qualification/manifests/offline.json`. Physical additions are registered in
`qualification/manifests/hardware.json`. They do not weaken or replace any retained
case. `qualification/run.py` consumes the hardware inventory and refuses
to run a physical case without the matching verified component receipt.

The launcher resolves the selected Extender commit once and materializes it in
an ignored local shared clone. The suite runs only from that pinned snapshot and
the selected clean EMOS commit, checking both identities before every case and
at completion. The ordinary development checkouts may therefore change while
the suite runs; no separate Git worktree is required and those edits cannot
silently enter the active run.

Performance measurements and physical/manual cases are not part of this run.
In particular, Nurples and other loaded-asset mode-switch cases remain at the
end of the automated passes for manual testing under the Author's accepted
AUDIT-010 disposition.

## Launch from another computer

Use the [canonical network instructions](https://github.com/bgates747/agon-dev-env/blob/feature/standardized-deployment/codex/environment.md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) to select and access the current regression host.
The host-local `agents/regression-suite.local.json` owns the Extender HTTP
endpoint and remains ignored. Once connected, invoke the installed application
launcher locally:

```sh
~/.local/bin/agon-extender-regression
```

The launcher prints the fresh job path, then streams concise phase, current-case
and case-result lines to the SSH console. The actual worker is detached: closing
SSH or pressing Ctrl-C stops only the status stream and does not stop the suite.
`--detach` returns immediately when no live console display is wanted. Do not
poll the run with an agent. On completion or detected failure, the terminal hook
selects Legacy, plays the accepted `/extender/attention.txt` spoken cue,
explicitly exits the listener started by that batch, and then prints the final
result so alert output cannot erase a failure message. The hook does not reset
either board.

The printed paths identify these durable records:

1. `result.json` — detached command and notification-hook status and durations.
2. `suite/progress.json` — last durable phase/case or terminal state.
3. `suite/events.jsonl` — fsynced UTC transition history.
4. `suite/summary.json` — source identities, case results, separate preparation,
   fixture-runtime and retrieval durations, and stated coverage limits.
5. `suite/cases/*.log` — one combined stdout/stderr log per case.
6. `notification.json` — cue execution receipt, separate from whether a human
   heard it or observed the Legacy pixels.

The suite deliberately does not write progress to the mainboard for each host
case: it does not own the foreground, and taking that ownership could alter a
concurrent physical workload. The durable host records are its progress channel.
Only the terminal notification interacts with the admitted Extender keyboard.

## Commit-pinned hardware workflow

The machine-local `agents/hardware-validation.local.json` follows
`qualification/config.example.json`. It identifies the component-owner
checkouts, exact P4 USB identity and remote flashing tool, Extender endpoint,
and the independently commissioned Agon reset controller. It remains ignored;
tracked files contain no bench addresses, credentials or unique device values.

The flash command is independent of the test command:

```sh
.venv/bin/python scripts/flash_firmware_commit.py \
  --target emos --commit EMOS_COMMIT
```

Before an EMOS flash, the command normally verifies and resets the P4 over its
stable USB identity, waits for the P4 HTTP service, resets the Agon, verifies
fresh Extender input admission, and stops any foreground SD listener before
typing at the EMOS prompt. This closes browser video/input and stale agent
sessions automatically; the operator does not inspect or release them by hand.
Use `--no-reset-p4` only for a deliberate expert run that preserves those
sessions and accepts responsibility for an input-ownership conflict.

Use `--target p4 --commit EXTENDER_COMMIT` for an Extender/P4 repair. The
command resolves the revision to a full commit, builds from a fresh detached
snapshot, performs exactly one component-appropriate flash, verifies the full
EMOS ROM or P4 flash plus observed boot identity, and prints the durable local
receipt path. It never accepts a dirty working tree as the requested firmware.
After a verified P4 flash and boot, the command normally uses the bench Pi's
independent reset actuator to reset the Agon, then requires a new EMOS boot
epoch and working Extender keyboard admission before reporting complete
success. Use `--no-reset-agon` only for deliberate P4-only work where preserving
the running Agon is more important than restoring and proving the paired
connection. A failed or uncertain P4 flash never triggers the Agon reset.

The hardware test command is separately invoked with that receipt:

```sh
.venv/bin/python qualification/run.py \
  --flash-receipt /absolute/path/to/p4-flash-receipt.json \
  --flash-receipt /absolute/path/to/emos-flash-receipt.json
```

It streams every named check and pass/fail status to the invoking SSH console.
The full run requires verified P4 and EMOS receipts and runs all applicable
physical cases against the already installed firmware. It
does not rebuild or reflash. It writes an overall `summary.json`, restores each
case's startup state, sends the accepted Legacy spoken cue, and leaves a failure
verdict on the Legacy screen after alert playback. The operator does not need an
agent to monitor the run.

The mandatory integrated smoke exercises the installed P4 web assets, browser
reset bridge, P4-to-EMOS keyboard path, ExCom display/status/text capture, and a
temporary exact-byte mainboard-SD round trip, then restores the ordinary startup
state. The dependent `a10-rp06-mode-transaction` case then switches mode
8→20→8 without a browser consumer and repeats the sequence while retaining
one browser-video WebSocket. It checks committed display status and decoded
frame geometry at each edge, closes the browser connection and restores
ordinary startup. Loaded-asset Nurples remains a separate manual case.

The additional EMOS physical case is `a10-rp04-raw-sd-write`. Its eZ80 fixture
refuses to write unless the card has a valid MBR whose first partition begins
after sector 2. It retains sector 2 in RAM, exercises the repaired RST `0x08`
write API, independently reads the result, restores through MOS's distinct C
write dispatch, and independently verifies the exact preimage before reporting.
An unverified restoration is an infrastructure failure and stops advancement.
The raw-sector fixture itself starts the result service only after no write was
attempted or after exact restoration was independently verified. The runner
allows 20 seconds for that positive completion handoff. If it is absent, the
runner fails without automatically resetting the Agon; a timeout is never
treated as evidence that interrupting raw media work is safe.

## First complete RP04 hardware run

Exact EMOS commit `8ecea5bc6cb4f9f563bc570316afbdaa08648632` was
built, flashed and verified by full installed-ROM readback. Exact Extender
runner commit `1b79083038b83fc4a60265b3d05db1e554e51c15` then
produced the retained local run
`agents/hardware-validation/regression-2026-09-29-23-07-38Z-1b79083038b8/`.

| Field | Result |
| --- | --- |
| EMOS artifact | 128,579 bytes; SHA-256 `7c7ac79fcbdb4a9d67885aede552e808e0111bcc7e2d54b012c43add0305317a` |
| Installed ROM | 131,072 bytes; exact padded match; SHA-256 `4fab4a413ff3e7d163ee8bd605ef9390503ba25db116a5c9e6137e300932a729` |
| Retained closure | 55 passed; zero failure, infrastructure error, timeout or blocked; 150.491329 monotonic seconds |
| Physical fixture | pass; 142.566509 monotonic seconds; fixture SHA-256 `9ed1064702f339ca8b6f3bb4ba852cdb9ccf724b59446ff4859b69eb85a47ce3` |
| Card safety | sector 2; first partition LBA 8192 |
| Test oracle | write/read pattern CRC32 `3b3befd6`; test status 0 |
| Restoration oracle | preimage/restored CRC32 `b2aa7578`; restore and verification statuses 0 |
| Startup | exact original 85-byte `/autoexec.txt` restored; final ready reset observed |
| Overall summary | success; SHA-256 `b3a2124ed85416e4788570b956a73dca8bb4239e35a3fdfe500d39f5ba9bf04a` |

The spoken Legacy cue ran. The run exposed that the retained attention batch
leaves its SD listener in the foreground; the maintained notifier now exits
that listener before printing its durable verdict. That follow-up has a
targeted structural test and was manually exercised against the run's actual
listener without replaying the already-heard alert.

## Bounded development checks

`--case CASE_ID` or repeated `--phase host|browser|build` options select a
subset. `--no-notify` exists only for runner development; a run using it does
not satisfy the unattended hardware-notification contract. The default launch
is the full manifest at the commit resolved from `HEAD`, with notification.
`--commit COMMIT` selects another existing commit explicitly.

An output folder is never reused. Success means every selected independent case
passed, the native source identities stayed fixed and clean, and the terminal
notification hook succeeded. A missing terminal `result.json` after a host
interruption is unknown, not success.

## First retained complete pre-hardware run

The Author launched the first full pinned run from the Lenovo on 2026-09-29.
The ignored local evidence directory is
`agents/regression-runs/2026-09-29-21-25-50Z-a8e6c5dc549f/`.

| Field | Result |
| --- | --- |
| Extender source | `a8e6c5dc549f355f2264c1423609d2b147410a60`, clean and unchanged |
| EMOS source | `21a9ba27f1f346473d767c2c3053ee18e8911335`, clean and unchanged |
| Cases | 54 passed; zero failure, infrastructure error, timeout or blocked |
| Suite duration | 143.542507419 seconds monotonic |
| Phase duration | host 35.843347309 s; browser 24.551770785 s; build 82.770066925 s |
| Terminal hook | success; 19.632202248 seconds; 108 keyboard events accepted, zero discarded/pending/held |
| Complete detached job | success; 163.236620222 seconds |
| `suite/summary.json` SHA-256 | `798f69c986f301b4d91bfec01adee98e046ca8cfb80e363e24be83d173b6db5f` |
| `result.json` SHA-256 | `4a21029917fff5357344ba11ce80298617704df8e23233f9b47456db40ad0241` |

The terminal-hook receipt proves accepted keyboard injection, not that the
Author heard the cue or observed Legacy pixels. This run establishes the pinned
pre-RP04 host/browser/native baseline; its EMOS commit predates the uncommitted
RP04 raw-SD repair and therefore is not RP04 acceptance evidence.

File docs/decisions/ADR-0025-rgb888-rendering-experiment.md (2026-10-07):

# ADR-0025 — Bounded RGB888 rendering experiment

- Status: Accepted
- Completeness: Complete
- Date: 2026-10-05
- Related task: RGB-001

## Decision

The Author authorizes a CPU-only experiment comparing direct RGB888 logical
storage with the retained native renderer, using existing mode20/8 workloads
and a bounded mode136 follow-up. Ordinary builds retain mode-native storage.
Only an explicitly selected experimental P4-PC HDMI benchmark build substitutes
RGB888 storage for the selected64-colour geometries.

The first implementation reuses common Canvas/rasterizers and preservesRGB222
colour quantization, GCOL operations, public bitmap formats and sprite background
semantics. The P4 CPU expands plotted bitmap/software-sprite pixels when drawing;
it composes hardware sprites into the presentation image before DSI DMA.
Definition-time expansion caches and PPA acceleration remain deferred.

The Author's subsequent direction selects LCD-owned720p buffers as the renderer's
pixel storage. Logical row descriptors address the centered viewport with the
physical720p stride. Ordinary presentation performs cache writeback/selection,
without a framebuffer copy. Stock colour/asset semantics and the independent
nominal60Hz hardware frame clock remain intact.

An application-requested double swap is staged before the upcoming DMA boundary.
A separate core1 task submits the completed back while the drawing executor
waits under native exclusion. The DMA acknowledgment releases the old front;
only then may the ordinary swap notification authorize drawing into it. This
task must not require the exclusion held by its caller. Teardown cancels an
unsubmitted request and joins a submitted buffer's physical release.

The CPU composes overlays into panel storage with saved background rows. It
restores backgrounds before drawing/readback or recycling an old front. Double
overlays are completed on the back at application swaps; independent overlay
updates without those swaps are outside this experiment's qualified scope.

## Rationale and boundary

The initial separate RGB888 planes isolated the renderer change and retained a
presentation copy. Static controls then measured23.19ms preparation at512×384,
including19.41ms row copy/composition. The Author directs removal of that copy.
Its builds, evidence and earlier decision remain traceable in RGB-001.

On IDF5.5.5/pre-v3 P4, the callback follows DMA selection. Releasing the old front
at logical pointer exchange would race scanout. Waiting until a hardware edge
to begin staging would instead introduce two-edge pacing. Early staging plus
actual DMA acknowledgment addresses both constraints. Scrolling must copy pixel
contents because DMA cannot follow logical row-pointer rotations.

No measured performance claim follows the new design alone. EMOS routing,
existing fixture bytes, fixed HDMI timing and production selection remain
unchanged. Expanded asset caches and PPA remain deferred.

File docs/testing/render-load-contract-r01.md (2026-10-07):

# Render load benchmark contract r01

## Executive summary

Frozen first benchmark contract under [BENCH-009](../tasks/BENCH-009.md), authorised
by the Author on2026-10-04. One eZ80 application submits deterministic progressive
workloads through EMOS to either VDP. Application-visible completion, P4 drawing/
presentation phases and hardware refresh are different measurements. No result
may be described as physical displayed FPS without independent output evidence.

The adjacent machine-readable definition under `tests/performance/render_load`
is normative for counts, ordering and parameters. Freeze both hashes before
implementation. Changes require a new contract revision and fresh identified runs.

## Workload and execution

1. Default modes are20,8,136,21,149. Mainboard and P4 run equal modes/colour depths.
   Mode148 is not supported;21/149 supplies the512×384 double-buffer pair.
2. Each level preloads all assets and40 generated frames:8 warm-up,32 measured.
   Integer trajectories use seed0xB009. Levels1,4,16,64 increase count or a stated
   area/overlap unit. Coordinates preserve an8-pixel top band for a frame marker.
3. Families: static control; growing rectangle area; lines/circles;16/32-pixel
   bitmaps; moving software/hardware sprites; fixed64 sprites with growing overlap;
   text/scroll; mixed primitives/bitmaps/sprites. Commands and asset formats are
   explicit. RGBA2222 is used for prepared bitmap assets.
4. Software/hardware sprite variants use the same images/positions, explicit API
   selection and one refresh after each complete movement batch. Setup resets
   sprites and painting/context state. Double-buffer setup initialises both buffers.
5. Three passes alternate endpoint order mainboard/P4, P4/mainboard, mainboard/P4.
   Within each pass levels rise monotonically. Failures are outcomes, not discarded
   samples. Warm-up, loading, setup, SD saving and result retrieval are untimed.
6. The application contains no mode switch, UART/GPIO access or route override.
   `/autoexec.txt` selects EMOS route and `VDU 22 n` before loading it. Payloads
   are length-bounded and hash-verified after deployment. Frames are identical
   across endpoints; diagnostic run tags outside timing may differ.

## Measurements

1. Submission ends after counted MOS output returns; this includes eZ80 command
   copying, routing and transport backpressure. It is not rendering completion.
2. Completion follows official screen-pixel query23,0,0x84 and its matching MOS
   reply flag. The VDP query fences earlier Canvas work. Its cost includes the
   reply and MOS dispatch. It does not measure physical display or all recurring
   sprite/scanline work. Use empty controls to show overhead without subtracting
   it as a constant. Double-buffer frames include the ordinary swap command.
3. Throughput frames have no deliberate pacing. Paced frames target successive
   60Hz opportunities using raw MOS clock deadlines; they never omit workload
   updates to appear faster. PRT1 measures submission, completion and total wall
   intervals. Counts are /256 system-clock ticks, with saturation recorded as
   overflow/failure, never unwrapped. Raw MOS clock corroborates run duration.
4. Nominal PRT units are13.889µs/count at18.432MHz. Raw MOS time advances2 per
   mainboard60Hz vblank; it is120 units/s with16.67ms granularity. Clock calibration
   and immediate-read controls precede comparisons. A16.67ms active completion
   budget is1,200 nominal PRT counts; report clock limits beside deadline results.
5. The P4 diagnostic image measures discontiguous wall intervals for drawing drain,
   native-row lock waiting, row composition, RGB888 expansion, cache submission,
   complete conversions/submissions and DMA frame completion. These are not
   exclusive CPU times. Phase intervals crossing window boundaries are excluded
   and counted. Window bounds may exclude one in-flight conversion.
6. A small prepared bitmap encodes frame index and complement in the top band.
   It supports P4 complete-conversion identity checks and future camera observation;
   it does not prove a coherent image reached the monitor. Single-buffer writes
   can overlap scanout. Mainboard physical frame delivery remains unavailable.
7. Controls retain the same executable: no frame marker/timing probes, marker with
   timing probes disabled, and ordinary marker/timing. Compare perturbation.
   Diagnostic window records must match run tag/case ID with no missing closures.

## Diagnostic windows and output controls

1. An ordinary buffered write23,0,0xA0,65535,0,12,payload carries magic`B009`,
   version1, op(reset0/begin1/end2), little-endian caseID16, flags(timing bit0,
   frame marker bit1) and runTag24. Ordinary mainboard firmware consumes/discards
   the same bytes. Only an explicitly selected P4 diagnostic build observes them.
   No logging, replies, file I/O or network requests occur in per-frame timing.
2. Normal HDMI provides existing scanout and conversion. Held HDMI retains DMA
   scanout/logical hardware cadence but suppresses presentation conversion.
   Render-only retains logical buffers/resident RGB888 memory and ordinary drawing,
   suppresses conversion and starts no DSI DMA; a60Hz software clock supplies
   opportunities. This clock/resource difference must accompany comparisons.
3. Pair the full five-mode mainboard/normal-HDMI suite. Replay modes20/8 for
   held-HDMI and render-only controls with the same passes/workloads. The hold/off
   pair isolates scanout contention in native rendering; normal/hold isolates
   presentation interference. Neither pair isolates RGB expansion without phase
   instrumentation. No architectural timing change is promoted from these tests.

## Validity, recovery and reporting

1. Reject wrong mode/geometry, payload corruption, missing fence reply, timer
   overflow, transport failure, malformed/incomplete records or telemetry mismatch.
   Preserve checkpointed prior cases, mark failed cases, recover a known fixture,
   continue independent work and repeat affected cases without timing probes.
2. Keep finite preparation/runtime/retrieval clocks separately. Pilot evidence
   determines advance estimates; explicit bounded fixture deadlines govern recovery,
   never an assumed duration. Restore prior startup byte-for-byte and ordinary P4
   firmware at the end; verify admitted EMOS input and HTTP readiness.
3. Present worst cases first, ranked by P4/mainboard completion slowdown. Tables
   name endpoint/variant, units, baseline and `(P4−mainboard)/mainboard×100%` for
   equal application metrics. Report medians, ranges/p95, achieved application
   updates/s, over-budget frames, failures and phase costs separately.
4. Preserve exact source/tool/image identities, raw records, contract hashes and
   payload hashes. Do not claim production qualification or measured monitor FPS.

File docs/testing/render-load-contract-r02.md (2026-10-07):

# Render load benchmark contract r02

## Executive summary

Second frozen benchmark contract under [BENCH-009](../tasks/BENCH-009.md), authorised
by the Author on2026-10-04. One eZ80 application submits deterministic progressive
workloads through EMOS to either VDP. Application-visible completion, P4 drawing/
presentation phases and hardware refresh are different measurements. No result
may be described as physical displayed FPS without independent output evidence.

The machine-readable `tests/performance/render_load/contract-r02.json` definition under `tests/performance/render_load`
is normative for counts, ordering and parameters. Freeze both hashes before
implementation. Changes require a new contract revision and fresh identified runs.

## Workload and execution

1. Default modes are20,8,136,21,149. Mainboard and P4 run equal modes/colour depths.
   Mode148 is not supported;21/149 supplies the512×384 double-buffer pair.
2. Each level preloads assets and40 generated template frames, performs8 warm-up
   frames, then repeats the deterministic40-frame cycle indefinitely. Space
   advances one case; Escape finishes the active case and exits the application.
   Presses are latched through the public MOS keyboard callback; release and
   typematic repeats cannot cause duplicate advancement. No timer advances cases.
   Integer trajectories use seed0xB009. Levels1,4,16,64 increase count or a stated
   area/overlap unit. Coordinates preserve an8-pixel top band for a frame marker.
3. Families: static control; growing rectangle area; lines/circles;16/32-pixel
   bitmaps; moving software/hardware sprites; fixed64 sprites with growing overlap;
   text/scroll; mixed primitives/bitmaps/sprites. Commands and asset formats are
   explicit. RGBA2222 is used for prepared bitmap assets.
4. Software/hardware sprite variants use the same images/positions, explicit API
   selection and one refresh after each complete movement batch. Setup resets
   sprites and painting/context state. Double-buffer setup initialises both buffers.
5. Automated runs use the same fixture and admitted keyboard path: the Pi injects
   Space at10-second wall-clock intervals after a20-second startup allowance.
   Actual case bounds and completed frames are recorded; compare rates and
   distributions, not equal work totals. Cases with fewer than64 measured frames
   are marked short and repeated at longer explicit intervals. A transition
   requested during preparation may end the next case prematurely; reject that
   result rather than silently stretching or claiming a fixed10-second window.
   Three passes alternate endpoint order mainboard/P4, P4/mainboard, mainboard/P4.
   Within each pass levels rise monotonically. Failures are outcomes, not discarded
   samples. Warm-up,
   loading, setup, SD saving and result retrieval are untimed. Retain up to65,535
   per-frame records in RAM; visual rendering continues after capacity, with
   truncation explicitly recorded. Complete automated distributions require no
   truncation. Checkpoint records only after a case ends.
6. The application contains no mode switch, UART/GPIO access or route override.
   `/autoexec.txt` selects EMOS route and `VDU 22 n` before loading it. Payloads
   are length-bounded and hash-verified after deployment. Frames are identical
   across endpoints; diagnostic run tags outside timing may differ.

## Measurements

1. Submission ends after counted MOS output returns; this includes eZ80 command
   copying, routing and transport backpressure. It is not rendering completion.
2. Completion follows official screen-pixel query23,0,0x84 and its matching MOS
   reply flag. The VDP query fences earlier Canvas work. Its cost includes the
   reply and MOS dispatch. It does not measure physical display or all recurring
   sprite/scanline work. Use empty controls to show overhead without subtracting
   it as a constant. Double-buffer frames include the ordinary swap command.
3. Throughput frames have no deliberate pacing. Paced frames target successive
   60Hz opportunities using raw MOS clock deadlines; they never omit workload
   updates to appear faster. PRT1 measures submission, completion and total wall
   intervals. Counts are /256 system-clock ticks, with saturation recorded as
   overflow/failure, never unwrapped. Raw MOS clock corroborates run duration.
4. Nominal PRT units are13.889µs/count at18.432MHz. Raw MOS time advances2 per
   mainboard60Hz vblank; it is120 units/s with16.67ms granularity. Clock calibration
   and immediate-read controls precede comparisons. A16.67ms active completion
   budget is1,200 nominal PRT counts; report clock limits beside deadline results.
5. The P4 diagnostic image measures discontiguous wall intervals for drawing drain,
   native-row lock waiting, row composition, RGB888 expansion, cache submission,
   complete conversions/submissions and DMA frame completion. These are not
   exclusive CPU times. Phase intervals crossing window boundaries are excluded
   and counted. Window bounds may exclude one in-flight conversion.
6. A small prepared bitmap encodes frame index and complement in the top band.
   It supports P4 complete-conversion identity checks and future camera observation;
   it does not prove a coherent image reached the monitor. Single-buffer writes
   can overlap scanout. Mainboard physical frame delivery remains unavailable.
7. Controls retain the same executable: no frame marker/timing probes, marker with
   timing probes disabled, and ordinary marker/timing. Compare perturbation.
   Diagnostic window records must match run tag/case ID with no missing closures.

## Diagnostic windows and output controls

1. An ordinary buffered write23,0,0xA0,65535,0,12,payload carries magic`B009`,
   version1, op(reset0/begin1/end2), little-endian caseID16, flags(timing bit0,
   frame marker bit1) and runTag24. Ordinary mainboard firmware consumes/discards
   the same bytes. Only an explicitly selected P4 diagnostic build observes them.
   No logging, replies, file I/O or network requests occur in per-frame timing.
2. Normal HDMI provides existing scanout and conversion. Held HDMI retains DMA
   scanout/logical hardware cadence but suppresses presentation conversion.
   Render-only retains logical buffers/resident RGB888 memory and ordinary drawing,
   suppresses conversion and starts no DSI DMA; a60Hz software clock supplies
   opportunities. This clock/resource difference must accompany comparisons.
3. Pair the full five-mode mainboard/normal-HDMI suite. Replay modes20/8 for
   held-HDMI and render-only controls with the same passes/workloads. The hold/off
   pair isolates scanout contention in native rendering; normal/hold isolates
   presentation interference. Neither pair isolates RGB expansion without phase
   instrumentation. No architectural timing change is promoted from these tests.

## Validity, recovery and reporting

1. Reject wrong mode/geometry, payload corruption, missing fence reply, timer
   overflow, transport failure, malformed/incomplete records or telemetry mismatch.
   Preserve checkpointed prior cases, mark failed cases, recover a known fixture,
   continue independent work and repeat affected cases without timing probes.
2. Keep finite preparation/runtime/retrieval clocks separately. Pilot evidence
   determines advance estimates; explicit bounded fixture deadlines govern recovery,
   never an assumed duration. Restore prior startup byte-for-byte and ordinary P4
   firmware at the end; verify admitted EMOS input and HTTP readiness.
3. Present worst cases first, ranked by P4/mainboard completion slowdown. Tables
   name endpoint/variant, units, baseline and `(P4−mainboard)/mainboard×100%` for
   equal application metrics. Report medians, ranges/p95, achieved application
   updates/s, over-budget frames, failures and phase costs separately.
4. Preserve exact source/tool/image identities, raw records, contract hashes and
   payload hashes. Do not claim production qualification or measured monitor FPS.

## Revision authority and retained evidence

The Author requested longer runs, indefinite visual inspection, manual case
selection/exit and wall-clock scripted keypresses on2026-10-05. This changes
execution from fixed32-frame work to repeated templates and measured actual
windows. The frozen r01 contract and its successful two-case clock/protocol
pilots remain evidence; they are not long benchmark results.

Lossless SD packing is permitted outside measurement: the host validates the
packed stream against the original generated bytes, verifies one deployed
whole-file readback, and the eZ80 restores each complete case before setup and
warm-up. Packing does not change any measured VDU bytes. Fast upload retains
packet CRC checks and skips repeated whole-file verification passes.

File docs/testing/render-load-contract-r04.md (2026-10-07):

# Render load benchmark contract r04

## Executive summary

Fourth frozen benchmark contract under [BENCH-009](../tasks/BENCH-009.md), authorised
by the Author on2026-10-04. One eZ80 application submits deterministic progressive
workloads through EMOS to either VDP. Application-visible completion, P4 drawing/
presentation phases and hardware refresh are different measurements. No result
may be described as physical displayed FPS without independent output evidence.

The machine-readable `tests/performance/render_load/contract-r04.json` definition under `tests/performance/render_load`
is normative for counts, ordering and parameters. Freeze both hashes before
implementation. Changes require a new contract revision and fresh identified runs.

## Workload and execution

1. Default modes are20,8,136,21,149. Mainboard and P4 run equal modes/colour depths.
   Mode148 is not supported;21/149 supplies the512×384 double-buffer pair.
2. Each level preloads assets and40 generated template frames, performs8 warm-up
   frames, then repeats the deterministic40-frame cycle indefinitely. Space
   advances one case; Escape finishes the active case and exits the application.
   Presses are latched through the public MOS keyboard callback; release and
   typematic repeats cannot cause duplicate advancement. No timer advances cases.
   Integer trajectories use seed0xB009. Levels1,4,16,64 increase count or a stated
   area/overlap unit. Coordinates preserve an8-pixel top band for a frame marker.
3. Families: static control; growing rectangle area; lines/circles;16/32-pixel
   bitmaps; moving software/hardware sprites; fixed64 sprites with growing overlap;
   text/scroll; mixed primitives/bitmaps/sprites. Commands and asset formats are
   explicit. RGBA2222 is used for prepared bitmap assets.
4. Software/hardware sprite variants use the same images/positions, explicit API
   selection and one refresh after each complete movement batch. Setup resets
   sprites and painting/context state. Double-buffer setup initialises both buffers.
5. Automated runs use the same fixture and admitted keyboard path: the Pi injects
   Space at10-second wall-clock intervals after a20-second startup allowance.
   Actual case bounds and completed frames are recorded; compare rates and
   distributions, not equal work totals. Cases with fewer than64 measured frames
   are marked short and repeated at longer explicit intervals. A transition
   requested during preparation may end the next case prematurely; reject that
   result rather than silently stretching or claiming a fixed10-second window.
   Three passes alternate endpoint order mainboard/P4, P4/mainboard, mainboard/P4.
   Within each pass levels rise monotonically. Failures are outcomes, not discarded
   samples. Warm-up,
   loading, setup, SD saving and result retrieval are untimed. Retain up to31,402
   per-frame records in RAM; visual rendering continues after capacity, with
   truncation explicitly recorded. Complete automated distributions require no
   truncation. Checkpoint records only after a case ends.
6. The application contains no mode switch, UART/GPIO access or route override.
   `/autoexec.txt` selects EMOS route and `VDU 22 n` before loading it. Payloads
   are length-bounded and hash-verified after deployment. Frames are identical
   across endpoints; diagnostic run tags outside timing may differ.

## Measurements

1. Submission ends after counted MOS output returns; this includes eZ80 command
   copying, routing and transport backpressure. It is not rendering completion.
2. Completion follows official screen-pixel query23,0,0x84 and its matching MOS
   reply flag. The VDP query fences earlier Canvas work. Its cost includes the
   reply and MOS dispatch. It does not measure physical display or all recurring
   sprite/scanline work. Use empty controls to show overhead without subtracting
   it as a constant. Double-buffer frames include the ordinary swap command.
3. Throughput frames have no deliberate pacing. Paced frames target successive
   60Hz opportunities using raw MOS clock deadlines; they never omit workload
   updates to appear faster. PRT1 measures submission, completion and total wall
   intervals. Counts are /256 system-clock ticks, with saturation recorded as
   overflow/failure, never unwrapped. Raw MOS clock corroborates run duration.
4. Nominal PRT units are13.889µs/count at18.432MHz. Raw MOS time advances2 per
   mainboard60Hz vblank; it is120 units/s with16.67ms granularity. Clock calibration
   and immediate-read controls precede comparisons. A16.67ms active completion
   budget is1,200 nominal PRT counts; report clock limits beside deadline results.
5. The P4 diagnostic image measures discontiguous wall intervals for drawing drain,
   native-row lock waiting, row composition, RGB888 expansion, cache submission,
   complete conversions/submissions and DMA frame completion. These are not
   exclusive CPU times. Phase intervals crossing window boundaries are excluded
   and counted. Window bounds may exclude one in-flight conversion.
6. A small prepared bitmap encodes frame index and complement in the top band.
   It supports P4 complete-conversion identity checks and future camera observation;
   it does not prove a coherent image reached the monitor. Single-buffer writes
   can overlap scanout. Mainboard physical frame delivery remains unavailable.
7. Controls retain the same executable: no frame marker/timing probes, marker with
   timing probes disabled, and ordinary marker/timing. Compare perturbation.
   Diagnostic window records must match run tag/case ID with no missing closures.

## Diagnostic windows and output controls

1. An ordinary buffered write23,0,0xA0,65535,0,12,payload carries magic`B009`,
   version1, op(reset0/begin1/end2), little-endian caseID16, flags(timing bit0,
   frame marker bit1) and runTag24. Ordinary mainboard firmware consumes/discards
   the same bytes. Only an explicitly selected P4 diagnostic build observes them.
   No logging, replies, file I/O or network requests occur in per-frame timing.
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

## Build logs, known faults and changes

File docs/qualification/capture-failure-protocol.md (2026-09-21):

# Capture failure and uninstrumented controls

## Executive summary

Author-directed protocol, accepted 2026-09-20: a failure with capture
instrumentation marks that case; it does not end the suite. The host controller
preserves evidence, recovers the affected processor and continues independent
cases. After the suite, the controller reruns failed cases without capture
instrumentation on the affected endpoint. This separates rendering defects
from possible diagnostic interference without losing remaining coverage.

## Procedure

1. The host controller marks each crash, hang, incomplete acquisition or unstable
capture against its case, endpoint, firmware/build hashes and startup history.
Retain useful serial traces, input hashes and any partial images. Do not count
that case as a passing image comparison or immediately retry it to erase failure.
2. The host controller performs the established recovery/reset and verifies
readiness before the next independent case. Recreate each case's required state
from a fresh start; do not carry potentially corrupted state forward. Continue
other cases and the other endpoint where independent execution is possible.
If recovery cannot restore verified readiness, record the remaining cases as
blocked; do not send commands blindly into an unknown state.
3. After the capture suite, rerun every marked case on its affected endpoint:
mainboard uses the verified official stock VDP release; Extender uses the matching
EDP implementation with the capture routine/instrumentation absent. Merely
omitting a capture request or disconnecting the browser is not equivalent to
removing the routine. Record unavoidable binary/configuration differences.
4. Preserve the same fixture bytes, mode, setup/teardown history, pacing and
completion fences. Omit only capture-specific requests. Each control defines a
bounded observation interval and evidence for completion/responsiveness; collect
ordinary serial panic output without introducing new rendering instrumentation.
5. Report capture and control outcomes separately per case and endpoint:
reproduced without capture, not reproduced in the bounded control, or control
blocked/inconclusive. A negative control neither proves capture caused the fault
nor qualifies pixels that were never captured. Preserve repeat counts and limits.
6. Restore verified normal firmware/startup, release observers and confirm input
and prompt readiness after the campaign. Product repairs remain separate work.

## Applicability and traceability

This governs subsequent capture-suite execution, superseding stop-on-first-
capture-failure and immediate diagnostic-retry rules in older task contracts.
It does not rewrite historical outcomes or override explicit deferred test scope.
The motivating [sprite control](../tasks/QUAL-004/sprite-scroll/stock-control/RESULTS.md)
failed with diagnostic firmware but did not reproduce on one official-stock run;
its startup-history difference remains recorded rather than hidden.

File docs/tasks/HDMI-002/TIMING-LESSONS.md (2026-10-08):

# HDMI timing lessons — 640×480 failures and native 512×384

## Executive summary

The earlier 640×480 attempts did **not all fail for a demonstrated common
reason**. The APLL attempt, r10, probably selected a DPI clock source that this
P4 silicon cannot use; it produced no frame-DMA completions. The later PLL
attempts, r11–r13, did scan frames but never produced an acceptable monitor
picture. Their remaining bridge/timing/monitor failure is unresolved.

The successful 848×480 experiment supplies a better starting point: a supported
PLL clock, deliberately matched P4/DSI/bridge timing, a simple static framebuffer
and an unchanged bridge driver. It proves that 480 active lines can work here;
it does not retrospectively identify why the 640-pixel-wide trials failed.

For a future **native 512×384 HDMI signal**, derive the timing from clocks this
silicon can actually generate, check bridge/monitor limits, and repeat the static
visual gate before adding the renderer. The present 512×384 rectangle inside an
848×480 signal is not native 512×384 output.

## Evidence map

1. [Original 640×480 comparison](../P4PC-001/SCANOUT-COMPARISON.md) retains
   r10–r13 observations, configurations and software measurements.
2. [HDMI-002 contract/results](../HDMI-002.md) identifies the successful static
   image, exact factory hash, deployment checks and Author visual confirmation.
3. [Standalone source](../../../vdp/hdmi-timing-test/README.md) contains the
   reproducible build and pattern. Frozen machine-local images/captures remain
   under `agents/hdmi002/`; older captures remain under the P4-PC experiment.
4. ESP-IDF 5.5.5 commit `b774170ff46c393eeb5e495ea37936038d3f4f4f` is the exact
   SDK used. Relevant source is `components/hal/mipi_dsi_hal.c`,
   `components/hal/esp32p4/include/hal/mipi_dsi_ll.h`,
   `components/esp_lcd/dsi/esp_lcd_panel_dpi.c` and
   `components/esp_hw_support/port/esp32p4/rtc_clk.c` in that pinned checkout.
5. The [vendored LT8912B component](../../../vdp/components/esp_lcd_lt8912b/UPSTREAM.json)
   pins Olimex commit `04032d68e5c727870f9d40beb9e37b7ab3a66916` and file hashes.
   Its bridge source is unchanged in the successful experiment.

## Separate the failures

| Trial | Clock and signal | What actually happened | Supported conclusion |
|---|---|---|---|
| 640 r10 | Requested APLL 25.2 MHz; total 800×525; two 720 Mbps lanes | Startup display locks timed out; finite 5.019917 s window had zero renders and zero DMA completions; USB uptime advanced | Display scanout failed to progress. The APLL DPI mux is now a strong causal suspect; not a renderer throughput result or demonstrated reset loop. |
| 640 r11 | PLL240/9≈26.667 MHz; total 847×525; two 720 Mbps lanes | Approximately 60 DMA completions/s; unusable picture, including a fresh static boot | P4 frame progression worked. HDMI acceptance did not. Nonstandard timing/bridge handling remained unresolved. |
| 640 r12 | PLL240/8=30 MHz; total 952×525; two 360 Mbps lanes; H 168/96/48, V 10/2/33; negative sync; 4:3 metadata | Approximately 60 completions/s; fresh paused bars still failed visual review | Integer lane/pixel timing and matched configured totals were **insufficient**. No evidence that LVGL load alone caused the missing picture. |
| 640 r13 | r12 timing plus receiver settle 0x04 and receiver/DDS relock after P4 scanout started | Fresh static bars still failed | These two bridge changes did not repair that configuration. Neither became a proven fix. |
| 848 r02 | PLL240/7≈34.286 MHz; total 1104×517; two 480 Mbps lanes; H 32/112/112, V 6/8/23; positive sync; VIC 0 | Approximately 60 completions/s, HDMI hot-plug detected, Author reports “that is a beautiful sight” | This complete configuration produces visible output on the connected monitor. It is custom timing near 60 Hz, not exact DMT 0Eh. |

H/V triplets above are front porch / sync width / back porch. DMA completions,
LVGL rendering and actual visible output are separate measurements.

### Why r10 probably stalled

The SDK accepts `MIPI_DSI_DPI_CLK_SRC_APLL`, and its APLL setup can report a
plausible calculated frequency without proving that APLL reaches the DPI block.
The old trial's 25,200,020 Hz report therefore did not establish a running pixel
clock. Source inspection found no missing acquire/set step: the SDK powers and
gates APLL, programs coefficients and waits for calibration.

Espressif introduced DPI selector 3/APLL in
[commit be2b6efa](https://github.com/espressif/esp-idf/commit/be2b6efadc559596c22071ffec90423ea962c6e1),
whose subject/body concerns changes for silicon 3.0. The DPI APLL case is not
guarded like the revised PHY clock path. The
[official TRM](https://documentation.espressif.com/esp32-p4_technical_reference_manual_en.html),
pre-release v0.7 dated 2026-08-20, page 1128/register 11.16, lists DPI clock
selector 3 as invalid; it lists XTAL, PLL240 and PLL160 for the other selectors.
The newer DSI diagram in the same preliminary manual includes APLL, so the
manual itself mixes revision coverage. Its SHA256 is recorded in the main task.

Together with r10's zero-DMA behavior on actual silicon 1.3, this is strong evidence
of an unsupported old-silicon mux selection. It is **not** an isolated reproduced
vendor-confirmed defect, and cannot explain r11–r13, which already used PLL.
The 848 experiment avoided the questionable source rather than retrying it.

### Why r11–r13 remain unresolved

Changing a framebuffer size does not define an HDMI mode. The P4's pixel
clock/blanking, DSI packet timing, LT8912B reconstruction and monitor expectations
all have to agree. These trials used custom signals, and later trials changed
several variables together. No single-variable comparison isolated the remaining
fault. Specific facts and unresolved possibilities are:

1. **Clock rounding is a real SDK behavior.** The DPI divider is integer. The
   HAL rounds the source/request ratio, then adjusts the P4 producer's horizontal
   front porch when realized and requested clocks differ. Its DSI host timing
   calculation uses the requested clock separately. Programming the external
   bridge from the original requested totals can therefore produce disagreement.
   This behavior matters to every new modeline; it is not proof that every old
   failed trial had this mismatch. r12 already used an exact integer clock.
2. **Clock alignment alone was not sufficient.** r12 had integer horizontal
   byte-clock timings and still failed. Its two 360 Mbps lanes equal the raw
   RGB888 demand at 30 MHz; the successful trial's two 480 Mbps lanes exceed its
   approximately 411.429 Mbps-per-lane active-pixel demand. That difference may
   matter to DSI packet/blanking/FIFO behavior, but no controlled test proves
   a lane-headroom cause. Do not turn a payload-rate equality into a complete
   DSI link budget: packet overhead and burst scheduling still matter.
3. **Custom timing and HDMI metadata were not equivalent.** The old 640 path
   used VIC 1 with custom clock/blanking, whereas the successful 848 path uses
   VIC 0. Monitor interpretation is a possible contributor; no metadata-only
   comparison was performed. A custom signal must not be advertised as a CTA
   mode merely because active width/height match.
4. **480 active lines are not categorically unsupported.** The working848
   signal also has 480 active lines. It uses the original settle 0x10 and original
   reset order. The earlier settle 0x04/post-start-relock changes are neither
   demonstrated requirements for 480 lines nor a proven repair for 640×480.
5. **The bridge's integer `pclk_mhz` was a misleading lead.** In this pinned
   driver it is consulted only by the disabled internal-pattern path. Ordinary
   output reconstructs timing from incoming DSI. Rounding that field alone did
   not establish a normal-output fault or a fix.
6. **Rendering speed was a different issue.** The earlier LVGL circle workload
   drew in roughly 22–25 ms, too slow for a new rendered frame every 16.67 ms.
   That explains its sub-60 animation throughput, not the unusable static picture.
   Removing LVGL now narrows the test; it does not prove LVGL caused the old
   bridge failure. Older direct/static controls had already failed too.

## Lessons for native 512×384

These are constraints for the next scoped experiment, not authorization to run it.

1. **Define the actual output.** A 512×384 active HDMI signal is different from
   a 512×384 image inside 848×480 or 1280×720. In a true 512×384 signal, the monitor
   must accept the timing and provide any desired pillarboxing/aspect treatment.
   Adding transmitted black columns changes the active signal size again.
2. **Start from supported clocks.** On this specimen use the verified legacy
   clock muxes and realizable integer divisors. Do not reuse APLL solely because
   a current SDK enum exposes it. Derive horizontal/vertical totals from the
   actual clock and desired approximately 60 Hz cadence; then calculate the
   resulting horizontal frequency and blanking durations explicitly.
3. **Check electrical/timing limits before selecting that clock.** Establish
   LT8912B input/output clock ranges, DSI lane constraints and monitor EDID/range
   limits. A smaller active image need not imply a proportionally smaller pixel
   clock: extra blanking may be needed. Present success at 848×480 does not prove
   that the monitor will accept 512×384, nor that a low pixel clock is supported.
4. **Keep all timing owners consistent.** Supply the same active dimensions,
   totals, porch widths and polarity to P4 DPI and LT8912B. Calculate the DSI
   host's byte-clock values using the realized lane rate. Prefer exact integer
   relationships, explicitly account for payload/packet headroom, and record
   any unavoidable HAL compensation. Check driver realizability rather than
   assuming requested lane rates are generated exactly.
5. **Use truthful HDMI metadata.** A custom 512×384 mode has no established
   standard VIC in this experiment. Use custom-mode signaling unless an actual
   standard mapping is verified; choose 4:3 treatment deliberately. An aspect
   hint is not a guarantee that a monitor will preserve shape or avoid overscan.
6. **Use the same minimal proof first.** Keep the proven bridge driver, board
   initialization, channel order and static pattern methodology. Change only
   the timing/geometry required for 512×384. Start with one framebuffer, paint
   before scanout, flush its cache, then leave it unchanged for a physical review.
   A 512-pixel RGB888 row is 1536 bytes and a 384-line frame is 589,824 bytes, both
   suitably aligned to the 64-byte boundary used in these tests.
7. **Verify the right things independently.** Check both bootloader/application
   silicon ranges before flash; read back exact bytes; log selected clock/divider,
   DMA progression and bridge detection. Judge visible edges, colors, one-pixel
   detail, shape/aspect and stability on the actual monitor. None of the software
   counters by itself closes the visual gate. Keep exact 848 and Nurples rollback.
8. **Measure product benefit later.** At equal 60 frames/s, reading a 512×384
   RGB888 framebuffer once per frame is 35.39 MB/s versus 73.27 MB/s for 848×480,
   approximately 51.7% fewer active framebuffer bytes. These are arithmetic
   payload estimates, excluding blanking/protocol traffic, rendering, cache and
   buffer copies; they are not measured contention relief or a gameplay result.
   A static timing pass must precede renderer integration, scrolling/sprites,
   double-buffer ownership and user-input regression tests.

## Stop state

Only the 848×480 static trial has been deployed in this task. The Author's request
for these notes does not authorize a native 512×384 flash or another 640×480 trial.
The existing pattern remains unchanged on the monitor.

Subsequent authorization: the Author later requested native512×384, wide, and
320×240 experiments after sprite integration. See HDMI-002 M01–M03 for current
authorization and selected tuples; the stop state above records the earlier
static-trial handback, not the current bench installation.

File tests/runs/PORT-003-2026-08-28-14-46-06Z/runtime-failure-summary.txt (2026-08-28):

PORT-003-2026-08-28-14-46-06Z runtime failure summary

Candidate source commit:
  39b45df18622d872eb729644a56b2f92297da6cf
Candidate build:
  extender-vdp-v0.1.0-b2026-08-28-01-57-52Z
Factory image SHA-256:
  760c1b0adb465033aded33af097913983ee0f92b385425b92c148fa3566daf32

Deployment result:
  Erase, exact-image write, esptool write verification, and independent
  verify_flash all succeeded on the ESP32-P4 revision 1.3 specimen.

Runtime stop condition:
  The first passive USB Serial/JTAG capture contained 7,780 exact instances of
  the following error in 7,784 lines (475,136 bytes):

    E (11946) task_wdt: esp_task_wdt_reset(707): task not found

  The same error continued through timestamp 19722 ms at approximately one
  message per millisecond. This violates the procedure's clean-runtime
  requirement and makes subsequent timing, Ethernet, browser, reconnect, and
  memory evidence unreliable. Required runtime checks 2 through 10 were not
  attempted.

  Complete bench-retained serial capture SHA-256:
    9e457c0789a8d6cb36b81bf9d2f68ddd1a6e9a16eca66c8f2da5ff1b5b1358ca

Observed periodic diagnostics amid the flood:
  I (13968) extender_snapshot: enabled=1 alloc_fail=0 cadence=671 transition=0 producer_busy=0 no_slot=0 compose_fail=0 published=61 no_new=0
  I (13969) extender_network: state=4 clients=0 refused=0 credits=0 protocol=0 sent=0 send_fail=0 disconnect_release=0 http=1/0 http_fail=0 queued=0 queue_fail=0 socket_fail=0
  I (13970) extender_provider: acquired=0 no_new=0 invalid=0 sent=0 failed=0 disconnected=0

Bounded diagnosis:
  1. The linked processLoop(void*) contains no esp_task_wdt_reset() call, so
     VDP_USE_WDT was not selected in the retained parser task.
  2. The linked setup() retains official VDP v2.16.0's calls to
     disableCore0WDT() and disableCore1WDT().
  3. Arduino-ESP32 3.3.11 implements those functions by removing each IDLE
     task from the ESP-IDF task watchdog. It does not deregister ESP-IDF's
     per-core IDLE hook.
  4. ESP-IDF 5.5.5's still-registered non-SMP idle_hook_cb() calls
     esp_task_wdt_reset() from the now-unregistered IDLE task, producing the
     observed task-not-found flood whenever that core idles.
  5. ESP-IDF's own reconfiguration path removes both the IDLE subscription and
     its hook. The official VDP calls therefore express a valid retained
     intention but use a framework binding that is not valid for this pinned
     P4 Arduino/ESP-IDF combination.

No firmware correction was made during or after this failed run.

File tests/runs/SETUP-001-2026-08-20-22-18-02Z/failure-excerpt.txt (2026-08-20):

Representative excerpt from each repeated r02 boot cycle:

I (...) qio_mode: Enabling QIO for flash chip WinBond
I (...) boot.esp32p4: SPI Speed      : 80MHz
I (...) boot.esp32p4: SPI Mode       : QIO
I (...) boot.esp32p4: SPI Flash Size : 16MB
I (...) boot: Loaded app from partition at offset 0x20000
I (...) esp_psram: Found 32MB PSRAM device
I (...) esp_psram: Speed: 200MHz
I (...) esp_psram: SPI SRAM memory test OK

assert failed: esp_clk_init clk.c:142 (res)
...
Rebooting...

The complete raw captures are retained with the bench run. This tracked excerpt
contains no private network path or unique hardware address.

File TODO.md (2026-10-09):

# Agon Extender TODO

This is the single authoritative unfinished-work index. Task files own detailed
subtasks, gates and evidence. Completed history remains in task records and the
development log. Ordering below replaces historical competing priority headings;
classification does not grant new execution or waive human acceptance.

## Browser paste — accepted development, release closeout pending

- [ ] **[REMOTE-004 — Browser clipboard paste](docs/tasks/REMOTE-004.md)** — Browser paste and restored Reset Agon accepted after Author testing. Source, local tests and bounded P4 deployment evidence retained; broader validation and production promotion remain within the HDMI release boundary. Broader clipboard investigation remains deferred.

## Active board-build preparation

- [ ] **[SPRITE-001 — Nurples hardware-sprite trial](docs/tasks/SPRITE-001.md)** — Author reports beautiful output from the full684 memory remedy; the thin tear disappears when paused, and mainboard hardware sprites show no tear. Rollback reproduces ordinary Nurples's upper-playfield visibility defect. HDMI-002 now selects a480-line carrier on mode0 exit; Author confirms full upper text. ExCom SD admission, tearing and broader qualification remain open.

- [ ] **[HDMI-002 — HDMI video timings](docs/tasks/HDMI-002.md)** — Accepted r10 native HDMI/Nurples evidence retained. Full r11 adds PPA-scaled 320×240 with logical double buffering preserved; bounded sprite checks pass at about60 application updates/s and30 presented images/s. Author reports Rally looks fine in demo/racing, but its existing ExCom control failure remains (Legacy controls work). Diagnostic-label correction, broader qualification and production promotion remain open; three further native240 timing probes also failed Acer picture acquisition; exact full r11 restored and ExCom prompt/input verified. N02 offline timing shortlist is ready for review; no new bench trial.

- [ ] **[BOARD-001 — Board-selectable P4 builds and compile-time pin profiles](docs/tasks/BOARD-001.md)** — Board profiles, shared pin consumers, ARM builds and validation pass for DevKit/PC. Web keyboard/video works; Author reports Nurples at 16–17 fps. The tested full-speed USB experiment bypasses the previous transaction-translation rejection, but serial now confirms failure of the keyboard's initial device-descriptor transfer. Try an alternative keyboard as the next hardware control. SD checks, electrical review and canonical qualification/acceptance remain.

## Networking prior-art review — awaiting review

- [ ] **[NET-002 — Agon networking prior art and Extender reuse](docs/tasks/NET-002.md)** — Review PerryZi/Zimodem, get/zget and related Agon tools against our networking capabilities; recommend reusable code/interfaces and bounded adaptations. Source review N02-01–05 complete; recommendations await Author review. Preserve the existing SD service; proposed AT compatibility is a separate decision.

## Transparent text — scope review

- [ ] **[TEXT-001 — Transparent text backgrounds](docs/tasks/TEXT-001.md)** — Prototype implemented; native pixel checks and P4 compile pass. Lenovo bespoke rainbow demo awaits Author visual acceptance; no hardware deployment.

## Do now — PLAN-001

- [ ] **[AUDIT-010 — Implementation integrity and resource-lifecycle audit](docs/tasks/AUDIT-010.md)** — RP01–RP04 are accepted. The canonical paired installed-system suite passed both cases and all 17 required checks; manual Nurples ExCom mode switching/gameplay passed at 25–29 fps. RP05 is next. Nurples causality remains deferred until the complete audit/repair sequence ends, and LCD returns afterward as a separately reviewed delta.

- [ ] **[AUDIT-009 — Documentation accuracy and consolidation](docs/tasks/AUDIT-009.md)** — Current-handbook closeout complete through N25; broader historical inventory remains incomplete. [Closeout](docs/tasks/AUDIT-009/CLOSEOUT.md) identifies usable guides and remaining owners. No automatic archive-review or bench tranche; revisit unresolved records when current work depends on them.

- [ ] **[REMOTE-005](docs/tasks/REMOTE-005.md)** — Ad hoc fast-transfer implementation deployed; local and bounded physical checks accepted; broader research/discussion: human-friendly access to Agon SD through P4; compare browser, FTP, SMB and WebDAV. Selected production retains EMOS v0.1.19, while development EMOS v0.1.23 and its finite application-card path have bounded hardware evidence and form AUDIT-010's current pre-LCD baseline. YMODEM comparison complete; external protocol unselected. SD layout cleanup recorded; `/tmp/extender` transaction migration, interactive session handling and R05-10 qualification-procedure refresh remain.

- [ ] **[AUDIT-008 — EMOS ROM headroom and SD-loaded EMOSlets](docs/tasks/AUDIT-008.md)** — Delivered tranche closed out; further extraction and broader qualification parked. Revisit for measured ROM pressure or a concrete utility benefit, not routine splitting for its own sake.

- [ ] **[PLAN-001 — Timing closeout and next-work selection](docs/tasks/PLAN-001.md)**. T01 committed; T02 reconciliation prepared for review in [the disposition table](docs/tasks/PLAN-001/QUEUE-REVIEW.md). T03 source audit and mode-startup investigation delivered; inherited palette defect recorded, with upstream/Extender patches deferred for credits. Aginvadors optimization and further browser-performance experiments are deferred.

## Next-work candidates and remaining implementation

- [ ] **[PORT-008 — Eight-bit bidirectional ExExt transport](docs/tasks/PORT-008.md)** — Private native P4 RX/TX and EMOS assembly leaves pass off-bench correctness checks; P4 target compile passes. EMOS ROM gate refuses native integration by 265 bytes (preceding private candidate: 91 free). Full admission/drain/deadline/status composition, ROM fit and physical payload qualification remain. No payload activation or installed firmware change. Earlier UART E08/E09 evidence retained; E10 separate.

- [ ] **[REMOTE-007 — Restore staged WebDAV file transfers](docs/tasks/REMOTE-007.md)** — Metadata requests succeed but file GET returns HTTP 500 on the current bench; checked foreground EMOS listener transfers work. Bounded reproduction, fault isolation, repair and Legacy/ExCom/file-manager validation planned; execution not started.

- [ ] **[HDMI-001 — Fixed 720p HDMI presentation for existing Agon modes](docs/tasks/HDMI-001.md)** — r03 startup, EMOS prompt modes0/3/8/20 and Author gameplay checks pass for Nurples and 320×240 Aginvadors/Rally. Excess sprite flicker remains open; passive timing records about19.2 complete updates/s versus60 DMA frames/s without an identified controlled game scene. Full mode coverage, fidelity/performance and promotion remain pending.
- [ ] **[BENCH-009 — Deterministic rendering load suite](docs/tasks/BENCH-009.md)** — Long r04 campaign paused. Supplemental five-mode static controls complete. Permanent resident selection and card collection pass; the separate bounded RGB888 report is complete. No full-campaign resumption selected.

- [ ] **[RESEARCH-007 — Indexed framebuffer and palette-expansion feasibility](docs/tasks/RESEARCH-007.md)** — Investigation recorded, not started: compare eight-bit indexed storage and P4 CPU/PPA/display expansion for faster output through P4-PC’s existing HDMI path. External VGA/Pico output is separate. Preserve stock VDU semantics and a necessary true-colour path; verify CLUT support and total pipeline cost before changing architecture. No implementation or bench work selected.

- [ ] **[PPA-001 — Identify PPA rendering acceleration opportunities](docs/tasks/PPA-001.md)** — Deferred, not started; Author requests task recording only. Assess current clears, rectangular fills, bitmap/sprite compositing and transforms against IDF5.5.5 PPA capabilities, then rank source-linked opportunities and proposed comparisons. No implementation or bench work selected.

- [ ] **[RGB-001 — Direct RGB888 rendering experiment](docs/tasks/RGB-001.md)** — Original r01 measurements and gameplay failure retained. SCAN-001 copy-scroll remedy r02 passes Author Nurples review; Rally steering remains an unchanged separate issue. Broader firmware qualification/promotion remains pending. Aginvadors held-fire slowdown is an application bug. Caches, PPA and the long campaign stay deferred.

- [ ] **[SCAN-001 — Segmented HDMI scanout and transparent partial scrolling](docs/tasks/SCAN-001.md)** — S01–S05 complete. S06-R01 copy-scroll remedy built/flashed; 13 bounded cases pass, short Nurples returns to 60 updates/s and scrolling with 32 software sprites reaches 54–55 versus 26 before. Normal startup/configurations restored; Author passes Nurples, with Rally input still an unchanged separate issue. Production qualification/promotion and remaining S06 controls/mechanism gates stay open. Segmented DMA and dependent integration are explicitly deferred by the Author after this pass.

- [ ] **[QUAL-006 — Modern automated hardware-test control plane](docs/tasks/QUAL-006.md)** — Audit complete; Author review and contract decisions remain. Generalize EMOS's existing finite safe-point admission so ordinary qualification can stage, launch, observe and finish correlated jobs without rewriting `/autoexec.txt`, rebooting per case, scraping stale prompt pixels, or guessing listener readiness. Retain boot-script launch only where startup, first admission, reset or recovery is the behavior under test. QUAL-005 remains authoritative until an accepted migration.

- [ ] **[DIAG-002 — Report Extender connection and P4 identity at EMOS startup](docs/tasks/DIAG-002.md)** — After AUDIT-010 and the separately reviewed sparse-checkout/workspace reduction, make EMOS report bounded Extender connection state and the installed P4 firmware/build identity at startup. Preserve usable Legacy boot when the P4 is absent and do not merge or automate the independent reset actions.

- [ ] **[FWBUG-013 — ExCom prompt cursor stops flashing at column zero](docs/tasks/FWBUG-013.md)** — Author-reported physical defect: the cursor does not flash initially at the first prompt position and stops after Backspace returns there, but continues flashing when left-arrow returns to the same coordinate. Reconcile the installed build and isolate EMOS cursor-command state from EDP rendering after the AUDIT-010 review gate.

- [ ] **[REMOTE-006 — Independent browser-requested Extender reset](docs/tasks/REMOTE-006.md)** — Add a Reset Extender button beside Reset Agon while preserving two independent actions. Select an external P4 reset executor capable of recovering more than a responsive self-restart; define Legacy/ExCom and in-flight-service outcomes before implementation. Queued behind the active AUDIT-010 review/repair gate unless explicitly reprioritized.

- [ ] **[RESEARCH-006 — Mainboard VDP via Pico 2/Cowbell](docs/tasks/RESEARCH-006.md)** — Initial assessment recorded; investigate header-only serial transport versus digital VGA taps, fidelity and bandwidth. Research only; no implementation or bench work selected.

- [ ] **[TRS-80-003 — Shared P4 services and native-eZ80/MAME bridge](docs/tasks/TRS-80-003.md)** — Feasibility study first: coordinate detached MAME reuse, then native Agon execution with P4 device models, EMOS bridge and eight-bit parallel transport. Cross-project orientation recorded; common Ethernet boundary extracted for detached build evaluation; hybrid feasibility and image leases remain open.

- [ ] **[LCD-001 — Olimex MIPI LCD exploration](docs/tasks/LCD-001.md)** — Preserve the working experimental panel evidence and implementation. After AUDIT-010 reviews and fixes the pre-LCD baseline, redeploy LCD support as a separately reviewed delta and rerun geometry, late-mode, browser/service, performance and gameplay regressions.

- [ ] **[PORT-003](docs/tasks/PORT-003.md)** — Display backend works; wider command consumption and faithful coverage remain incomplete. Primary implementation owner for T03; retain accepted key-query/audio slices and all explicit command deferrals.

- [ ] **[AUDIT-007](docs/tasks/AUDIT-007.md)** — Parked by the Author: first graphics-backend review and mode-startup investigation delivered; exhaustive remainder deferred. Resume only on explicit Author direction; preserve existing finding owners and feature deferrals.

- [ ] **[QUAL-003](docs/tasks/QUAL-003.md)** — Many bounded results complete; correctness gaps and review gates remain; browser experiments parked. Separate retained correctness/exception work from dormant performance branches; no automatic new run.

- [ ] **[PORT-006](docs/tasks/PORT-006.md)** — Network service works; resilience/update-service scope incomplete. Browser keyboard was reintroduced. Keep remaining network obligations; browser input belongs to REMOTE-001, not a retired-service claim.

- [ ] **[QUAL-001](docs/tasks/QUAL-001.md)** — Matrix scaffold exists; four-mode reconciliation and validator integrity gates remain. Retain infrastructure work; partial records do not certify complete compatibility.

- [ ] **[REMED-001](docs/tasks/REMED-001.md)** — Some architecture promotions complete; broader conformance/replacement work incomplete. Reconcile only applicable remaining obligations; old global freeze wording is not evidence that accepted ExCom ceased to work.

- [ ] **[REMED-002](docs/tasks/REMED-002.md)** — Findings have mixed fixes, deferrals and outstanding validation. Retain finding IDs and owning-task gates; no blanket closure from successful gameplay.

- [ ] **[SETUP-005](docs/tasks/SETUP-005.md)** — Immediate ExCom/input decisions accepted; broader mode-integration questions remain. Resolve decisions only when selected scope depends on them; do not reopen settled keyboard choices.

- [ ] **[HW-002](docs/tasks/HW-002.md)** — Simplified wiring accepted within scope; USB schematic/as-built and endpoint review incomplete. Keep documentation obligations; remove the obsolete tomorrow/date framing from the queue.

## Review and closeout queue — no automatic new experiments

- [ ] **[BENCH-002](docs/tasks/BENCH-002.md)** — 30-Hz test deployment exists; later feedback and production/test split supersede initial awaiting-review wording. Review final disposition; production Nurples is single-vblank and the slower build is test-only.

- [ ] **[BENCH-004](docs/tasks/BENCH-004.md)** — Mailbox implementation/local tests complete; task still lacks an explicit Mac handshake receipt. Locate or obtain a peer round-trip only if needed; empty mailbox checks do not establish that gate.

- [ ] **[RESEARCH-001](docs/tasks/RESEARCH-001.md)** — Five source reviews complete; synthesis available. Accept/archive research separately from any proposed optimization; no new search or implementation.

- [ ] **[RESEARCH-002](docs/tasks/RESEARCH-002.md)** — Published-throughput research complete. Accept/archive findings; published link/codec rates are not measured application throughput.

- [ ] **[RESEARCH-003](docs/tasks/RESEARCH-003.md)** — Twelve standalone runs complete; 60-fps delivery unmet. Historical candidate-left-installed note is obsolete as a current bench description. Review bounded result; consult latest restoration authority rather than assume the old candidate is installed.

- [ ] **[BENCH-001](docs/tasks/BENCH-001.md)** — Bounded telemetry/driving work complete and frozen; human review/remaining game continuation separate. Close accepted scope after review; retain AgonArcade RALLY-22 ownership of further driving.

- [ ] **[REMOTE-002](docs/tasks/REMOTE-002.md)** — Host input implemented, tested and used; current task summary links the implementation commit and operating guide. Review remaining physical/human gates; no duplicate implementation required.

- [ ] **[REMED-003](docs/tasks/REMED-003.md)** — Identical filesystem probe passes hardware/raw image and fails directory backend; report prepared. Author reviews report; submitting to upstream requires explicit authorization.

- [ ] **[NET-001](docs/tasks/NET-001.md)** — Viewer takeover implemented; six connections/five handovers passed. Retain pending human browser acceptance; later use does not automatically establish every gate.

- [ ] **[QUAL-004](docs/tasks/QUAL-004.md)** — 77 static scene pairs matched, including [static teletext](docs/tasks/QUAL-004/teletext/RESULTS.md). [Sprite/scroll follow-up](docs/tasks/QUAL-004/sprite-scroll/RESULTS.md): stock INITIAL visual/exit control passed; mainboard OVERLAP/EDGES/HIDDEN passed repeat capture, HIDDEN also full oracle. Extender checks passed; three checkpoints match mainboard exactly, INITIAL has visual control only. [Packed expansion BM02](docs/tasks/QUAL-004/packed-expansion/RESULTS.md) passed; BM03 parked. Capture-interference investigation QUAL-004-CI01 and four Copper controls deferred; no claim of complete dynamic-sprite parity.

## Parked, blocked and unscheduled work

- [ ] **[BENCH-008](docs/tasks/BENCH-008.md)** — Correct output but worse frame rate with replacement deltas; initial experiment complete. B08-06 cost investigation deferred until Author resumes; pre-experiment P4 firmware restored after the regression.

- [ ] **[RESEARCH-008 — P4 output through Pico 2/Cowbell](docs/tasks/RESEARCH-008.md)** — Independent external-output investigation, primarily for P4-DevKit. Assess indexed delivery, palette expansion, HSTX and transport costs only when selected. No dependency for P4-PC indexed HDMI work; no implementation or bench action authorized.

- [ ] **[RESEARCH-005](docs/tasks/RESEARCH-005.md)** — Deferred VGA pillarboxing, P4 VGA output and aspect-preserving output research; FabGL investigation and existing P4 VGA driver lead retained. No implementation or bench work scheduled.

- [ ] **[BENCH-007](docs/tasks/BENCH-007.md)** — Package/results committed; F01 mainboard panic, F02 Rally fixture discrepancy and B07-R01 procedure refresh remain. Retain these unscheduled follow-ups here; measurement implementation is complete, not another half-built package. Refresh the retained runner/startup procedure before reuse under current fixture rules.

- [ ] **[AUDIO-001](docs/tasks/AUDIO-001.md)** — SD feasibility measured; integrated parallel/audio stages not executed. Keep behind current porting priority; AF02 needs its own bounded contract.

- [ ] **[P4PC-001 — Ad hoc P4-PC setup and experimentation](docs/tasks/P4PC-001.md)** — Standalone ESP-IDF HDMI/audio experiments. Working 720p at near-60 Hz scanout renders circles at 12 fps; native 640×480 r12 renders about 30 fps but fails physical picture review. Paired capacity averages 31.77 fps scanout on / 34.02 off; drawing remains the main limit. r13 render-only RGB332 measures 3.786 ms drawing / 200 fps versus RGB888 13.758 ms / 66.667 fps, excluding scanout. Author confirms r13 fresh static bars also fail; usable native HDMI and 60-fps animation remain open.

- [ ] **[TRS-80-001](docs/tasks/TRS-80-001.md)** — Ecosystem survey/reference acquisition complete; architecture unselected. Retain future design work; no new implementation implied.

- [ ] **[HW-003](docs/tasks/HW-003.md)** — Alternate board desk assessment complete; collaborator specimen unresolved. Await exact hardware/variant and separate adaptation scope.

- [ ] **[PORT-005](docs/tasks/PORT-005.md)** — Native USB input works; broader keyboard parity/settings refinements deferred. Preserve working input and fix blocking regressions only; browser-specific follow-up remains separate.

- [ ] **[REMOTE-003](docs/tasks/REMOTE-003.md)** — Pi-backed browser reset accepted. Direct P4 reset wiring remains deferred.

- [ ] **[REMOTE-001](docs/tasks/REMOTE-001.md)** — Browser input/UI deployed; game/fullscreen follow-ups explicitly deferred. Preserve committed input/UI work; do not expand optimization or infer physical takeover acceptance.

- [ ] **[SETUP-006](docs/tasks/SETUP-006.md)** — Old full-circuit wiring target remains on hold/incomplete. Retain predecessor evidence; reconcile applicability when hardware design resumes.

- [ ] **[HW-001](docs/tasks/HW-001.md)** — Old full r02 circuit incomplete and unqualified. Do not treat simplified harness success as full r02 qualification; re-scope before resuming.

- [ ] **[PORT-004](docs/tasks/PORT-004.md)** — Audio command framing slice passed; actual synthesis/output deferred. Retain Wolf3D and wider audio obligations; framing success does not implement sound.

- [ ] **[PORT-007](docs/tasks/PORT-007.md)** — P4-local SD HTTP file/directory management r57 passes bounded hardware checks; Author acceptance/promotion pending. Broader storage remains required v1 work. Keep distinct from the accepted mainboard SD service; EMOS read access remains required.

- [ ] **[QUAL-002](docs/tasks/QUAL-002.md)** — Full-circuit electrical absence/power/reset qualification on hold. Requires applicable hardware design and separate physical contract.

- [ ] **[UPSTREAM-001](docs/tasks/UPSTREAM-001.md)** — Lifecycle correction A/B research not started. No upstream fixes imported into strict-compatible first-pass port by default.

- [ ] **[MODE-001](docs/tasks/MODE-001.md)** — Broader state-preserving transitions not implemented; bounded ExCom switching already exists. Retain future transition contracts without describing current ExCom as absent.

- [ ] **[MODE-002](docs/tasks/MODE-002.md)** — Post-beta automatic retry-protection evaluation not started. Require evidence and explicit scope before adding retry machinery.

- [ ] **[DIAG-001](docs/tasks/DIAG-001.md)** — General recoverable diagnostics/crash-record product work not started. Retain release requirement and evidence/privacy decisions; task-local capture is not the full feature.

- [ ] **[LINK-001](docs/tasks/LINK-001.md)** — Direct onboard-VDP/EDP link is optional deferred research. Not a prerequisite for existing keyboard/ExCom path.

- [ ] **[PORT-016](docs/tasks/PORT-016.md)** — MicroPython long-term feature; v1 placement undecided. No timing or input dependency; remain deferred.

- [ ] **[BENCH-003](docs/tasks/BENCH-003.md)** — Author stopped after first Legacy acquisition timeout; no FPS conclusion. Do not restart; BENCH-007 does not retroactively pass this different experiment.

- [ ] **[BENCH-005](docs/tasks/BENCH-005.md)** — Initial latency and later packing/mode investigations retained; further output experiments now parked. Retain unresolved Legacy acknowledgement/readout limits; no new browser-performance work.

- [ ] **[BENCH-006](docs/tasks/BENCH-006.md)** — ExCom text readback implemented; Legacy S04 explicitly deferred. Keep only Legacy follow-up as remaining scope; preserve functioning ExCom endpoint.

## Governing limits

EMOS owns ordinary VDU routing and Extender activation/transports. Preserve
accepted Legacy/ExCom, input and mainboard SD capabilities. Official references
stay read-only. No Golem, upstream publication, new hardware qualification or
experimental push follows from queue cleanup.

[ADR-0020](docs/decisions/ADR-0020-web-output-30fps.md) remains unchanged. Its
scope versus later higher-rate client/experiment records must be reconciled
before future output qualification; do not assume that a current firmware cap
has been verified. See PLAN-001-N04 in the disposition table. Old experiment
headings no longer compete with the approved current sequence.

- [ ] **[RELEASE-001 — Native HDMI production v0.2.0](docs/tasks/RELEASE-001.md)** — Version authorized; preserve accepted r10/EMOS bytes, complete native receipt/paired qualification and packaging before selection and annotated release tag.

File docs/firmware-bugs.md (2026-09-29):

# MOS/VDP firmware bug register

## Executive summary

Running cross-firmware record started 2026-09-20. Record defects in stock MOS/VDP
and Extender EMOS/EDP, including resolved defects and source-level hazards.
Platform manifestation and evidence strength are separate: an inherited source
bug is not automatically a reproduced hardware crash on both processors.
This is a findings register, not another work queue; TODO and linked tasks own
implementation and priority. No new tests or fixes are authorized by an entry.

## Recording convention

Use stable `FWBUG-NNN` IDs. Never renumber or reuse them. When a finding is
promoted to an implementation task, use the same ID and
`docs/tasks/FWBUG-NNN.md`; TODO remains the only work queue. Existing owning
tasks retain their history and reference this ID rather than creating a second
bug identity. Source task records must link back to the register and item.

Each ID is an identity, not automatic authority to begin fixing it.

Each entry identifies the affected component and
version where known, trigger/reproducer links, separate mainboard/Extender
observations, evidence status, disposition and owning task. Distinguish Author
reports, captured physical failures, host reproductions, source findings and
unverified suspicions. Keep fixed entries. Do not classify intentional behavior,
incomplete features or emulator-only problems as proven stock firmware bugs.

This initial index seeds the current palette finding and retained major records.
Older detailed findings remain authoritative at the links below; this is not a
claim that every historical audit item has already been individually backfilled.

## FWBUG-001 — Palette deletion advances an erased map iterator

| Field | Record |
|---|---|
| Component | Stock VDP v2.16.0 / vdp-gl `ac2dd5986daf496c43ae8e7fe41836274aec54a0`, inherited by EDP. `VGAPalettedController::deletePalette(65535)`. |
| Trigger | Custom Copper palettes exist, then palette cleanup runs during resolution setup. The loop erases its current unordered-map entry, then advances the invalid iterator. |
| Mainboard | **Manifests on mainboard — Author report, 2026-09-20.** Same faulty official source independently reproduced under host ASan. This investigation did not capture this palette fault on physical mainboard; its earlier sprite-scanout crashes are separate. |
| Extender | **Captured physical P4 crash**, installed `key-query-probe-r01-b2026-09-20-02-08-44Z`; fault PC resolves to this loop. EDP host extraction also reports heap-use-after-free. |
| Reproduction conditions | [Retained COP16_SETUP scene and hashes](tasks/QUAL-004/fixtures/SCENES.json), followed by the startup sequence described in [investigation results](tasks/AUDIT-007/mode-lifetime/RESULTS.md). Startup failed during 640×480 allocation before intended mode9 reselection. [Host reproducer](tasks/AUDIT-007/mode-lifetime/check_palette_iterator.py), [panic](tasks/AUDIT-007/mode-lifetime/panic.txt), [receipt](tasks/AUDIT-007/mode-lifetime/receipt.json). The hardware evidence here is P4 evidence, not a claimed mainboard test receipt. |
| Disposition | **Patching upstream and Extender deferred until more credits are available**, per Author. No patch applied. |
| Owner | [AUDIT-007 bounded investigation](tasks/AUDIT-007/MODE-LIFETIME.md); PORT-003 owns any later EDP correction. Upstream publication requires separate authorization. |

## Other retained findings

| ID | Defect / hazard and reproduction record | Mainboard | Extender | Disposition / evidence limits |
|---|---|---|---|---|
| FWBUG-002 | Sprite-scanout crash under bounded sprite scenes; [QUAL-004 results](tasks/QUAL-004/RESULTS.md), including BSP25_04; later [BENCH-007](tasks/BENCH-007.md) F01; [two-software-sprite setup](tasks/QUAL-004/sprite-scroll/RESULTS.md) stopped before its first capture. | Captured physical crashes in diagnostic runs. | No equivalent crash established by these records. | Unresolved INITIAL diagnostic failure; it does not invalidate the later bounded sprite/scroll passes. [Official stock control](tasks/QUAL-004/sprite-scroll/stock-control/RESULTS.md) did not crash in one30-second observation; diagnostic influence, startup history and intermittency remain unresolved. Author deferred capture-interference investigation for token budget under [QUAL-004-CI01](tasks/QUAL-004.md#deferred-capture-interference-investigation--author-decision-2026-09-20). Subsequent stock visual review and clean exit passed. [Later paired checkpoints](tasks/QUAL-004/sprite-scroll/extender-followup/RESULTS.md) passed OVERLAP/EDGES/HIDDEN exactly; P4 INITIAL has visual control only. Full dynamic parity and diagnostic causality remain unproven. Keep separate from palette cleanup. |
| FWBUG-003 | Transform/sample numeric edge cases exposed by Rally; [Rally findings](tasks/QUAL-003/rally-excom/FINDINGS.md). | Same-game baseline does not establish equivalent manifestation. | Port numeric behavior required correction; see per-experiment evidence in linked findings. | Retained scoped corrections; not a claim that all Rally differences are solved or stock runtime is defective. |
| FWBUG-004 | Unsupported audio handler failed to consume complete VDU command payloads, disrupting later parsing; [grammar and fixture](tasks/PORT-004/audio-framing/PLAN.md), [results](tasks/PORT-004/audio-framing/results/README.md). | Reference behavior, not reported defective by this test. | Local parser defect, repaired with retained command grammar and unavailable audio backend. | Scoped framing repair accepted; audio synthesis remains unimplemented. |
| FWBUG-005 | Virtual-key query `VDU 23,0,&99,key` failed to generate its expected reply; [test contract](tasks/PORT-003/key-query/PLAN.md), [269-row physical results](tasks/PORT-003/key-query/RESULTS.md). | Reference behavior; no equivalent defect established. | Confirmed missing reply in old adapter; corrected on P4. | Bounded fix accepted. Preserve normal key-event semantics. |
| FWBUG-006 | Empty firmware-updater handler leaves selector/payload bytes in ordinary VDU stream; [exact grammars and source findings](tasks/PORT-003/command-consumption/README.md), [updater research](tasks/PORT-003/command-consumption/updater.md). | Stock handler is the reference, not the defective empty adapter. | Confirmed source-level consumption gap; do not inflate to a captured application failure. | All updater changes, including discard-only handling, deferred. |
| FWBUG-007 | Primitive completion and swap-notification hazards; [UPSTREAM-001 questions and preserved candidate](tasks/UPSTREAM-001.md). | Stock-hardware manifestation not established by the proposed A/B investigation. | Earlier local lifecycle findings/candidate retained; applicability to restored backend needs review. | Suspected upstream hazards, not blanket proven bugs. A/B research deferred; do not silently import old fixes. Queued operand lifetime is separately indexed as FWBUG-012. |
| FWBUG-013 | At an EMOS prompt in ExCom, the text cursor does not flash initially at column zero. Typing a character starts flashing; backspacing to column zero stops it, while moving left to column zero with the arrow key leaves it flashing. [Bounded report and reproduction contract](tasks/FWBUG-013.md). | Legacy behavior has not yet been compared. | **Author-reported physical observation, 2026-09-29.** The operation-dependent result at the same coordinate suggests cursor state or invalidation history matters; root cause is not established. | Open and queued. Reconcile exact installed EMOS/EDP identities, compare Legacy and ExCom output surfaces, then isolate producer state from P4 rendering before repair. |

## Additional confirmed source findings — 2026-09-20

Source baseline for stock MOS below: v3.0.2,
`8336409351ee5314e02801a7b72a4f1bb5282519`. The audit documents contain exact
upstream source links. Read-only EMOS source check at `26ba877` confirms the
specific inheritance/correction notes below; no hardware run was made for this
register update. MOS and EMOS both execute on the mainboard eZ80: “Extender”
in these rows means the replacement EMOS build, not code executing on P4.

| ID | Bug and trigger / reproduction conditions | Stock mainboard | Extender | Status / disposition |
|---|---|---|---|---|
| FWBUG-008 | Raw SD write API `0x73` calls `_SD_readBlocks_API`. Valid unlock plus nonzero block count reads card data into the caller buffer instead of writing it. [Dispatch trace A010/A011](tasks/AUDIT-004/trace-mos-interfaces.md). | Source-proven v3.0.2 dispatch defect; stock emulator failure recorded. Stock physical cohort excludes this call. | Same call retained through EMOS `8f29bf8`. **Physical EMOS v0.1.17 failure recorded in mos-tests:** success returned but sector unchanged; C write control succeeds. [Existing tests/results](firmware-bugs/mos-tests-coverage.md). The uncommitted A10-RP04 EMOS candidate changes only the call target and passes four independent raw-image cases. Ordinary FatFS writes use a different path. | **Candidate awaiting Author acceptance:** EMOS owns the wrapper correction; `mos-tests` owns the reused fixture/oracle. [RP04 evidence](tasks/AUDIT-010/RP04-RAW-SD-WRITE.md). Physical destructive-sector qualification remains separately gated and was not rerun. |
| FWBUG-009 | Volume-label API `0xA4` calls `_f_setlabel` but lacks a return after restoring HL. It falls into setcp/not-implemented and reports status23 instead of the actual result, even if the label changed. [Wrapper trace](tasks/AUDIT-004/trace-mos-interfaces.md). | Source-proven v3.0.2 defect; stock emulator records status23. Stock physical cohort excludes it. | Same fallthrough retained in EMOS `src/mos_api.asm::ffs_api_setlabel`. **Physical EMOS v0.1.17 reports status23 for both seeds.** [Existing test/results](firmware-bugs/mos-tests-coverage.md). | **Independently discovered and verified:** Extender source audit plus existing mos-tests runtime evidence. Fix owned by mos-tests, deferred until tokens are available. If it blocks current Extender work, consider an EMOS-first patch and notify mos-tests with reusable patch/test evidence. No current blocker established; no patch started. |
| FWBUG-010 | Known UART reply type with payload shorter than its required length still dispatches; fields come partly from stale reusable-buffer bytes. Reproduce by a complete packet followed by a truncated-length packet of a known type. [T001 receiver trace](tasks/AUDIT-004/trace-primary-protocol.md#t001--reverse-framing-mos-receiver-and-failure-limits). | Source-confirmed missing per-type validation; no physical injected-packet run recorded. | EMOS retained UART0 parser still lacks general per-type checks. Its private graphics-result length check is not a general repair; the separate Extender UART receiver is not claimed affected by this record. | Open source-level defect; don't equate a result flag with validated payload receipt. |
| FWBUG-011 | Reply length above16 enters discard without saving that length. With previous length0 it discards256 following bytes, losing subsequent packets. [Exact state-machine trigger](tasks/AUDIT-004/trace-primary-protocol.md#t001--reverse-framing-mos-receiver-and-failure-limits). | Source-confirmed in selected stock MOS; correction not present in that reference. | **Corrected in EMOS source:** UART0 state1 saves received length before entering discard. Not a new physical retest. | Stock-side open; EMOS is not listed as still broken. |
| FWBUG-012 | Clearing bitmap/buffer ownership while queued primitives or active sprite frames still reference it can leave dangling operands. All-buffer clear calls `resetBitmaps` without its required prior sprite reset; oversized managed paths can clear borrowed points before execution. [F022 conditions and source evidence](decisions/AUDIT-2026-09-01-001-open-task-and-implementation-integrity.md#integrity-audit-f022--queued-renderer-operands-and-persistent-users-outlive-their-owners), [PORT-003 D012](tasks/PORT-003.md). | Source-proven lifetime defect in pinned VDP/vdp-gl; isolated physical reproduction not established. | Historical retained exposure documented; current all-buffer clear still does not reset sprites. Native locking alone does not extend destroyed object lifetime. Full current-build trigger suite remains unexecuted. | Deferred under D012. Not asserted to be the root cause of FWBUG-002. Keep original F022/H002 IDs as aliases. |

No single-root-cause claim joins the sprite panic, palette iterator fault and
queued operand lifetime finding. They have different evidence and triggers.

## Existing MOS test-suite coverage

[Cross-reference against mos-tests](firmware-bugs/mos-tests-coverage.md) records
direct coverage for FWBUG-008/009, physical EMOS evidence, stock-hardware
exclusions and absent targeted coverage for the other registered bugs. Reuse
those tests rather than creating duplicate fixtures.

## Historical detailed registers

[REMED-002](tasks/REMED-002.md) indexes earlier EMOS/EDP transport, ownership and
implementation findings with their original stable IDs and mixed validation
states. Those records remain linked coverage rather than being relabelled as
current confirmed bugs. Add individual entries here as their source, applicable
build and reproducible conditions are reconciled; retain the original finding ID.

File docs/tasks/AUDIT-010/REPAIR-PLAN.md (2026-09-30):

# AUDIT-010 A10-07 — Reviewed findings and itemized repair plan

## Executive summary

The Author approved the complete A10-06 findings set on 2026-09-29 and accepted
the proposed repair cadence: address one independently bounded defect at a time,
test it, present its evidence, and pause for Author acceptance before starting
the next item. This document records all finding and coverage dispositions and
proposes the complete dependency-ordered A10-08 plan.

The order is severity-first after two mandatory medium-severity authority
prerequisites. `AUDIT-010-F005` must establish the selected product profile and
`AUDIT-010-F012` must establish the sole product display owner before any
high-severity display repair can produce meaningful evidence. Within a severity
class, direct memory/lifetime risk, demonstrated impact and dependency order
take precedence over the numerical finding ID.

The Author approved this complete itemization on 2026-09-29. A10-07 is frozen
by its dedicated documentation commit before any executable A10-08 change.
Execution is authorized only one item at a time under the acceptance cadence
below; the first authorized item is `A10-RP01`.

## Review state

`A10-RP-S01` [x] The Author reviewed and approved the complete
[A10-06 findings](FINDINGS.md) on 2026-09-29.

`A10-RP-S02` [x] The Author accepted one-at-a-time correction and validation,
with a mandatory pause for Author acceptance before the next item.

`A10-RP-S03` [x] The Author reviewed and approved this complete disposition
matrix, dependency order and validation plan as a whole on 2026-09-29.

`A10-RP-S04` [x] A10-07 is frozen in its own dedicated documentation commit
after `A10-RP-S03`; A10-08 begins from that boundary with `A10-RP01` only.

`A10-RP-S05` — The later Author-reported `FWBUG-013` cursor defect was filed
after the frozen A10-06 findings set. It remains visible in its own task and does
not silently enter this repair plan. Reprioritizing it requires an explicit plan
amendment; it does not change the dispositions below.

## Immutable execution cadence

`A10-RP-C01` — Execute exactly one numbered plan item at a time. An item includes
its bounded research refresh, implementation or validation-only work, regression
manifest, tests, evidence, documentation and logical commit. Shared test
infrastructure may be reused, but unrelated source corrections may not share an
item or acceptance claim.

`A10-RP-C02` — At the end of every executable or validation-only item, stop and
present: exact repositories/commits, changed actors and contracts, test results,
remaining limits, target state, and the next proposed item. Do not begin that
next item until the Author explicitly accepts the completed item.

`A10-RP-C03` — A failed test, incomplete repair or Author-requested revision
remains within the current item. Diagnose and iterate only that item; failure
does not authorize work on a later item. Preserve informative failures under
the normal evidence policy.

`A10-RP-C04` — Before changing code, each item declares a regression manifest
covering its direct behavior, previously accepted neighboring behavior, build
profile and applicable cross-processor/wire contracts. Passing a targeted test
does not waive those regression checks.

`A10-RP-C05` — Source-contract, host, sanitizer, build and static checks are
normal item validation. Each executable repair uses the maintained independent
exact-commit flash command followed by the complete retained suite plus its
registered repair-specific physical case. Running either command is the bounded
operator invocation of its documented mutations; hardware evidence is never
inferred from host or emulator success.

`A10-RP-C06` — Reusable target suites run unattended where practical, print
progress on the Legacy/mainboard screen, preserve failure text, record durable
start/end timing, and emit the accepted audible completion or failure cue. The
agent does not spend the fixture runtime continuously monitoring it.

`A10-RP-C07` — Validation-first findings do not authorize speculative source
changes. Present their evidence and pause. If a mismatch or applicable trigger
is demonstrated, amend this plan with a bounded repair item and obtain Author
approval before implementing it.

`A10-RP-C08` — Each accepted item receives its own final disposition and commit.
Approval advances only to the next listed item; it is not blanket acceptance of
later repairs, production promotion or post-audit LCD redeployment.

## Coverage-row dispositions

The Author's approval accepts the final A10-06 disposition of every frozen
coverage row. The compact record below is explicit; detailed actors, sources
and cross-references remain in [COVERAGE-LEDGER.md](COVERAGE-LEDGER.md).

| Coverage ID | A10-07 disposition |
|---|---|
| `A10-COV001` | Accepted complete; F002 and F005 proceed under this plan. |
| `A10-COV002` | Accepted complete with no finding. |
| `A10-COV003` | Accepted complete; F001, F002 and F012 proceed. |
| `A10-COV004` | Accepted complete; F001, F011, F012 and FWBUG-001 proceed. |
| `A10-COV005` | Accepted complete; F006, F008, F011, F012, FWBUG-001, FWBUG-007 and FWBUG-012 proceed. |
| `A10-COV006` | Accepted complete; eager-lifetime defect remains F002. |
| `A10-COV007` | Accepted complete; persistent allocation policy remains F002. |
| `A10-COV008` | Accepted complete; socket composition remains F004. |
| `A10-COV009` | Accepted complete; F002, F003 and F004 proceed. |
| `A10-COV010` | Accepted complete; F013 is conditionally deferred. |
| `A10-COV011` | Accepted complete; global socket composition remains F004. |
| `A10-COV012` | Accepted complete; F003, F004 and conditionally deferred F013 apply. |
| `A10-COV013` | Accepted complete with no finding. |
| `A10-COV014` | Accepted complete with no finding. |
| `A10-COV015` | Accepted complete with no finding. |
| `A10-COV016` | Accepted complete with no finding and the recorded hardware limit retained. |
| `A10-COV017` | Accepted complete; F013 is conditionally deferred. |
| `A10-COV018` | Accepted complete; F014 contract work proceeds. |
| `A10-COV019` | Accepted complete; F014 contract work proceeds. |
| `A10-COV020` | Accepted complete with no finding. |
| `A10-COV021` | Accepted complete; F005 and F012 proceed. |
| `A10-COV022` | Accepted complete; F005/F012 proceed and retired predecessors remain disposed. |
| `A10-COV023` | Accepted complete; F010 proceeds. |
| `A10-COV024` | Accepted complete with no new client finding. |
| `A10-COV025` | Accepted complete with no finding. |
| `A10-COV026` | Accepted complete; F008/F011 validation and F009 repair proceed. |
| `A10-COV027` | Accepted deferred LCD delta; regress F001/F002/F008 after AUDIT-010. |
| `A10-COV028` | Accepted complete exclusion. |
| `A10-COV029` | Accepted complete read-only reference use with no finding. |
| `A10-COV030` | Accepted bounded comparison; mode20 evidence does not prove cause. |
| `A10-COV031` | Accepted complete with no finding. |
| `A10-COV032` | Accepted complete; FWBUG-008/009/010 proceed under their existing IDs. |
| `A10-COV033` | Accepted complete; F006/F007 and FWBUG-006/007/012 proceed. |
| `A10-COV034` | Accepted complete integration; F004 proceeds and the OSV limit remains explicit. |
| `A10-COV035` | Accepted complete; F004 and F005 proceed. |

## Finding dispositions

No finding is rejected. “Validation first” means evidence is accepted as a
real gap or source concern, but no repair is authorized until the planned
discriminating test establishes an applicable consequence. “Deferred” retains
the finding and its activation condition without scheduling a standalone edit.

| Finding | Severity | A10-07 disposition | Plan owner |
|---|---|---|---|
| `AUDIT-010-F001` | High | Accept for two separately committed repairs: checked lower allocation, then P4 prepare/commit/rollback. | `A10-RP05`, `A10-RP06` |
| `AUDIT-010-F002` | High | Accept for repair after display ownership and transaction repairs. | `A10-RP09` |
| `AUDIT-010-F003` | High | Accept atomic WebDAV startup/rollback repair. | `A10-RP10` |
| `AUDIT-010-F004` | Medium | Accept one application-wide socket budget/admission repair. | `A10-RP12` |
| `AUDIT-010-F005` | Medium prerequisite | Accept profile correction before behavioral firmware repair. | `A10-RP01` |
| `AUDIT-010-F006` | High | Accept isolated size/lifetime/stack-safety repair. | `A10-RP03` |
| `AUDIT-010-F007` | Medium | Accept one defined conversion seam after complete caller inventory. | `A10-RP11` |
| `AUDIT-010-F008` | Medium gap | Accept validation first; repair only through an approved amendment after a mismatch. | `A10-RP16` |
| `AUDIT-010-F009` | Low | Accept browser-test ownership/drain repair. | `A10-RP20` |
| `AUDIT-010-F010` | Low | Accept maintained-documentation correction. | `A10-RP21` |
| `AUDIT-010-F011` | Medium unresolved | Accept shape validation first; repair only proven cases through an approved amendment. | `A10-RP17` |
| `AUDIT-010-F012` | Medium prerequisite | Accept architecture/profile correction, oracle extraction and explicit retirement boundary. | `A10-RP02` |
| `AUDIT-010-F013` | Low | Defer standalone cleanup; activate only when an owning file changes, with golden vectors. | `A10-RP22` |
| `AUDIT-010-F014` | Low | Accept contract clarification and shared corpus first; no assumed consolidation. | `A10-RP19` |
| `FWBUG-001` | High | Accept isolated selected-vdp-gl iterator repair; do not change display family. | `A10-RP07` |
| `FWBUG-006` | Medium | Accept official-grammar-derived consume-and-report repair. | `A10-RP13` |
| `FWBUG-007` | Medium unresolved | Accept bounded validation first; repair only demonstrated applicable subconditions through an amendment. | `A10-RP18` |
| `FWBUG-008` | High | Accept EMOS raw-write wrapper correction using the existing mos-tests owner and fixture. | `A10-RP04` |
| `FWBUG-009` | Medium | Accept EMOS volume-label wrapper-return correction using existing tests. | `A10-RP14` |
| `FWBUG-010` | Medium | Accept general per-reply minimum-length validation in the EMOS UART0 receiver. | `A10-RP15` |
| `FWBUG-012` | High | Accept bounded trigger validation first; ownership repair only for established all-buffer, point and sprite cases through an amendment. | `A10-RP08` |

## Dependency-ordered repair and validation sequence

Every item below ends at the `A10-RP-C02` acceptance pause. Checkbox completion
means its evidence has been presented and accepted, not merely that code was
written or a test launched.

### Authority prerequisites

`A10-RP01` [x] **F005 — Minimal authoritative product-development profile.**
Classify every selected definition/source as required, diagnostic or rejected;
move retained diagnostics to explicitly named profiles; reject conflicting draw
flags; rebuild the native graph and prove one deterministic ordinary profile.
Validation: manifest/profile tests, native build, linked-source/definition graph
and unchanged required service inventory. This medium item precedes high repairs
because all later build and test identities depend on it.

Accepted by the Author on 2026-09-29 after the minimal-profile build/graph and
neighbor regressions passed and the audit-impacting browser oracles were repaired
and rerun. Implementation commits: `2105f50b`, `36131e8d`.

`A10-RP02` [x] **F012 — Sole product display owner and retirement boundary.**
Confirm the selected stock-shaped display family as product owner, inventory and
extract unique nonrelease oracles, define the nonrelease family's removal or
archive condition, and prove exactly one family links in each admitted profile.
Do not copy repairs between families. Validation: `A10-VP06`, architecture and
profile checks, plus build proof. This is the second and final severity-order
exception.

Accepted by the Author on 2026-09-29 after both isolated native profiles,
applicable host contracts, flash verification, boot/service smoke and the
Author-observed Nurples late ExCom mode-switch regression passed. Implementation
commit: `f8458a31`; hardware-observation record: `4307e94d`.

### High severity

`A10-RP03` [x] **F006 — Mutable font bounds, lifetime and fixed scratch.**
Refresh the official font contract, retain backing/offset ownership and size,
validate every metadata mutation/use, and replace unbounded or wrapped stack
scratch with a fixed safe strategy. Validation: `A10-VP07` under ASan/UBSan,
maximum/short/mutated/destroyed-offset cases, screen-character capture, P4
compile and declared neighboring text regressions. Upstream publication remains
a separate decision.

Accepted by the Author on 2026-09-29 after sanitizer, screen-capture,
neighboring renderer/text and actual selected P4 build evidence passed.
Implementation commit: `c789d45a`; see
[RP03-MUTABLE-FONTS.md](RP03-MUTABLE-FONTS.md).

`A10-RP04` [x] **FWBUG-008 — EMOS raw SD write dispatch.** Correct only the
EMOS/MOS API wrapper so valid write requests invoke the write path and preserve
status/ABI behavior. Reuse the owning mos-tests fixture and controls; do not
duplicate it in Extender. Validation: existing emulator/host controls, rebuilt
EMOS identity, and a separately authorized physical destructive-sector test
using a disposable controlled sector with restoration evidence.

Candidate and two-command hardware workflow complete; see
[RP04-RAW-SD-WRITE.md](RP04-RAW-SD-WRITE.md). Source, linked-image, four
independent raw-image cases, exact-commit full-ROM verification, the expanded
55-case retained closure and the registered physical write/readback/restoration
case pass. The Author accepted RP04 on 2026-09-30 after the canonical paired
hardware suite passed all 17 checks and a manual Nurples ExCom run passed.
RP05 is now the next authorized repair item.

`A10-RP05` [x] **F001a — Checked display allocations.** Add complete failure
checks and local cleanup for inherited viewport pool/table and paletted DMA-row
allocation without yet redesigning the outer P4 transaction. Validation: the
allocation subset of `A10-VP01`, null/failure injection at every allocation,
sanitizers where host execution is meaningful, native build, and proof that no
partial object is published or dereferenced.

Accepted implementation and validation are recorded in
[RP05-CHECKED-DISPLAY-ALLOCATIONS.md](RP05-CHECKED-DISPLAY-ALLOCATIONS.md).
The Author accepted RP05 on 2026-09-30 after clean-commit qualification,
exact-commit paired hardware evidence and the required manual loaded-asset
transition passed. RP06 is now the next authorized repair item.

`A10-RP06` [ ] **F001b — P4 mode prepare/commit/rollback.** Build one selected-
family transaction that prepares geometry/controller/clock/workers before
retiring the live mode, publishes only after success, and retains a usable old
mode or mode1 fallback with truthful status. Reuse official modeline parsing.
Validation: the remaining `A10-VP01` failures, early/late mode transitions and,
after explicit authorization, `A10-VP02` mode8↔20 hardware cases. This item does
not absorb palette or browser-resource policy.

Authorized implementation contract:
[RP06-MODE-TRANSACTION.md](RP06-MODE-TRANSACTION.md).

`A10-RP07` [ ] **FWBUG-001 — Palette erase iterator lifetime.** Repair the
selected vdp-gl cleanup loop without selecting the parallel display family.
Validation: retained ASan host reproducer, multiple-palette/all-palette cleanup,
Copper palette regression, native build and the bounded physical sequence only
if its procedure is authorized.

`A10-RP08` [ ] **FWBUG-012 — Queued operand/bitmap/sprite lifetime validation.**
Run the existing bounded current-build trigger suite in required D012 order for
all-buffer clear, managed-point teardown and active sprites. Make no speculative
source repair. Present results and pause. Any established repair becomes a new
subitem added by an Author-approved plan amendment before code changes.

`A10-RP09` [ ] **F002 — Optional, demand-sized browser presentation resources.**
Make basic display attach independent of snapshot availability; size/lifetime
snapshot and codec storage from actual demand with bounded leases and graceful
capability-specific degradation. Validation: `A10-VP03`, every allocation
failure with zero/active browser demand, browser reconnect/codec fallbacks,
native build and separately authorized `A10-VP02` resource measurements.

`A10-RP10` [ ] **F003 — Atomic WebDAV startup and retry.** Keep listener and
workers in staged local ownership, publish readiness only after the complete
runtime exists, unwind in reverse order on every failure and permit a clean
retry. Validation: `A10-VP04` failure at every socket/task step, cleanup/leak
proof, retry, network-service regressions and native build.

### Medium severity

`A10-RP11` [ ] **F007 — Defined numeric conversion seam.** Inventory every
parser and buffered caller, replace aliasing and signed-shift UB with one checked
bit-safe contract, and retire the partial duplicate rather than add a third
helper. Validation: `A10-VP08` UBSan and golden matrices for widths, shifts,
special floating values and all entry points; include Rally numeric regressions.

`A10-RP12` [ ] **F004 — Application-wide socket budget and admission.** Assign
declared shares/reserve across video HTTP, local-SD HTTP, WebDAV and component
internal needs; make startup/admission obey the selected global limit. Do not
merge distinct protocols. Validation: `A10-VP05` static selected-config budget,
boundary admission tests and combined service host checks. Hardware saturation
is optional and requires a later explicit request/procedure.

`A10-RP13` [ ] **FWBUG-006 — Firmware-updater command consumption.** Derive
selector/payload grammar from the official handler, consume every complete
unsupported command, report unsupported status as contracted, and preserve the
following ordinary VDU byte stream. Validation: retained selector/payload corpus
with a sentinel ordinary command after every case, truncation handling, parser
regressions and native build. No P4 OTA feature is implied.

`A10-RP14` [ ] **FWBUG-009 — EMOS volume-label API return.** Add the missing
wrapper return while preserving the actual FatFS result and ABI. Reuse existing
label tests and do not broaden filesystem behavior. Validation: success/failure
status cases, label state, rebuilt EMOS identity and separately authorized
physical reuse of the existing fixture if required.

`A10-RP15` [ ] **FWBUG-010 — EMOS UART reply minimum lengths.** Define the
minimum payload for every known reply type and reject/discard a short known
packet before dispatch without using stale bytes. Keep general validation
separate from the private graphics-result check. Validation: retained complete-
then-short trigger for every known type, following-packet recovery, ordinary
traffic regressions and rebuilt EMOS identity.

`A10-RP16` [ ] **F008 — Dynamic scanout-effects proof.** Build one deterministic
static Copper/cursor/sprite fixture with machine-checkable regions and compare
native P4 output with browser bytes under the unattended cue contract. Do not
repair on visual suspicion. Present `A10-VP09` results; a mismatch requires an
approved plan amendment before source work, while a pass closes only the stated
pre-LCD coverage gap and becomes a later LCD regression.

`A10-RP17` [ ] **F011 — Filled arc/sector consequence validation.** Run
`A10-VP11` across quadrants, wrap and radii against an independent simple edge
oracle. Present results before any code change. Equivalent output disposes the
runtime consequence while retaining the dead-code conclusion; a mismatch opens
only the proven cases through an approved plan amendment.

`A10-RP18` [ ] **FWBUG-007 — Completion/swap applicability validation.** Use
the existing bounded UPSTREAM-001 trigger against the selected product owner;
do not import the preserved candidate first. Present which, if any, completion
or swap subcondition manifests. Any repair requires an approved plan amendment
limited to demonstrated applicable behavior.

### Low severity and retained deferral

`A10-RP19` [ ] **F014 — SD path-policy contract and corpus.** Name common
syntax/confinement versus intentional `sdjob` restrictions and build
`A10-VP13` from shared accepted/rejected vectors. Do not merge the services or
predicates merely because they overlap. Present the policy/corpus result; only
an evidenced accidental divergence may open consolidation through an amendment.

`A10-RP20` [ ] **F009 — Browser page-error ownership.** Bind one immutable error
sink to each page iteration, drain it before PASS/close and prevent a late
callback from contaminating another run. Validation: `A10-VP10`, consecutive
pages with delayed injected failure, existing browser layout checks and a clean
resource shutdown.

`A10-RP21` [ ] **F010 — Maintained build guidance.** Replace the routine
historical PlatformIO invocation with the exact maintained native entry point;
retain explicit historical reproduction wording only where necessary.
Validation: command/link checks and documentation references; no target run.

`A10-RP22` [ ] **F013 — Conditional CRC consolidation watch.** No standalone
code change is scheduled. At each accepted item touching an owning P4 or EMOS
CRC file, either leave the primitive untouched with a recorded reason or amend
that item to introduce one dependency-free primitive per processor toolchain
and run `A10-VP12` cross-target vectors. Mark this finding deferred at A10-09 if
no owner changes; do not create churn solely to close it.

## A10-09 and post-audit boundary

`A10-RP-X01` — A10-09 assembles the individually accepted item receipts and any
approved conditional amendments. It does not rerun already sufficient tests
merely to create one monolithic pass, but it must run the smallest combined
integration matrix needed to detect cross-item regressions.

`A10-RP-X02` — Production promotion, bundle/version/tag selection and publication
occur only after the complete accepted repair set and required target evidence
are reviewed. No plan item independently promotes production.

`A10-RP-X03` — Only after AUDIT-010 closes may LCD-001 reintroduce LCD support as
a separately reviewed delta. That delta must regress mode lifecycle, browser
resource independence, dynamic effects, early/late modes, assets, colour,
geometry and browser/service coexistence.

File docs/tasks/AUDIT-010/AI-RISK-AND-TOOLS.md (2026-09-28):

# AUDIT-010 A10-01 — Model-risk and analysis-tool research

## Executive summary

Research cutoff: 2026-09-28. No public evidence found supports the general
claim that GPT-5.6 writes better code than GPT-6 for a large, mixed-language,
multi-repository embedded product such as Extender. The public labels are also
not symmetric: OpenAI documents a GPT-6 family with Astra, Sol and Luna model
IDs, not a model whose public ID is `gpt-6.0`; `gpt-5.6` is a public alias that
routes to `gpt-5.6-sol`. An exact comparison requires retained model, reasoning,
harness, tool, prompt/context and task receipts. Subjective experience is a
useful reason to audit, but it is not a defect attribution or comparative
measurement.

The credible evidence does support a model-independent risk model. Long-context
information can be used unevenly; repository work requires coordinating changes
across files and functions; generated code exhibits missing cases, fabricated
objects or dependencies and incomplete implementation; and a patch can pass its
available tests while still diverging from intended behavior. Those risks map
directly to Extender's present concerns about allocation order, resource
ownership, stale published state, service coexistence and local tests that may
not exercise the integrated product.

The smallest justified A10-04 stack is the existing compiler-warning and
host-sanitizer coverage plus seven local FOSS capabilities: LLVM
Clang-Tidy/Static Analyzer, Cppcheck, Ruff, mypy, ShellCheck, narrowly authored
Semgrep Community Edition policy rules, and OSV-Scanner in offline scan mode.
This is intentionally a heterogeneous stack: no single parser or rule family
covers C/C++, Python, shell, dependency metadata and Extender-specific ownership
rules. Each tool starts report-only, with a canary proving that it analyzed the
intended files and can detect a known synthetic defect. PMD CPD, Vulture, REUSE,
Include-What-You-Use and secret scanning are deferred or excluded for the
reasons below.

The decisive project-specific prerequisite is compilation-database integrity.
Extender's hybrid PlatformIO/SCons build records that ESP-IDF-generated
`compile_commands.json` and `build.ninja` describe unused CMake `.obj` nodes,
while SCons produces the linked `.o` objects. A10-04 must derive or validate
Clang inputs against captured actual SCons actions and the selected-source
manifest. A clean scan of the wrong build closure would be false evidence.

No new scanner was installed or run. No source, firmware, hardware, SD card,
network service or component-owner repository was changed. Author review and
acceptance of the recommended set remain the gate before A10-04 installation or
execution.

## A10-01 research method and evidence classes

A10-RM01 — **Official product facts.** Model names, published behavioral
guidance and supported reasoning settings come only from current
[OpenAI developer documentation](https://developers.openai.com/api/docs/guides/latest-model).
Tool versions, licenses and behavior come from each tool's maintained source,
release page or official manual.

A10-RM02 — **Reproducible evaluations and published research.** The cited
papers disclose tasks, populations and methods that supply general failure
hypotheses. The TACL long-context study, ICLR SWE-bench paper, USENIX Security
package study and DOI-linked SWE-bench patch study have reviewed publication
venues; the generated-code bug taxonomy is cited from its public research
record. None evaluates the exact current GPT-6 Astra and GPT-5.6 Sol
configurations on Extender, so its rates must not be transferred to either
model or this repository.

A10-RM03 — **Maintainer evidence.** Tool identities, licenses, supported
features and documented limits come from maintained source, official manuals
and release pages. A repository-hosted issue such as the Gitleaks false-negative
report is identified as a reproducible report, not silently elevated to a
vendor guarantee; an accepted tool must still pass its own canary.

A10-RM04 — **Project evidence.** Current tracked source and documentation were
inspected without Git-history traversal. The current tree already contains
many host tests using `-Wall -Wextra -Werror` and AddressSanitizer or
UndefinedBehaviorSanitizer. It also contains the explicit actual-action
provenance warning in `vdp/pio/capture_p4_actual_steps.py`. These facts shape
the recommended tools; they are not a completed audit or a finding set.

A10-RM05 — **Subjective reports.** The Author's experience that some GPT-5.6
work has been stronger than GPT-6 work on this project is retained as the
motivation for A10-01. No community anecdote was promoted to comparative
evidence: such reports normally omit exact model snapshot, reasoning level,
context, tools, instructions, task difficulty and acceptance criteria. A broad
collection of anecdotes would add volume without producing a controlled
comparison.

A10-RM06 — **Local inventory only.** On 2026-09-28 the workstation exposed
Ubuntu Clang 18.1.3, but not `clang-tidy`, `scan-build`, Cppcheck, Ruff, mypy,
Semgrep, ShellCheck or Java on `PATH`. This records installation impact, not the
future A10-02 tool baseline. A10-04 must pin every accepted executable and
receipt after installation.

## Model identity and comparative evidence

| ID | Label under discussion | What the public documentation establishes | Audit treatment |
|---|---|---|---|
| A10-M01 | “GPT-6.0” | OpenAI publishes the GPT-6 family IDs [`gpt-6-astra`, `gpt-6-sol` and `gpt-6-luna`](https://developers.openai.com/api/docs/guides/latest-model). It does not publish `gpt-6.0` as the model ID on that page. | Treat “6.0” as ambiguous unless a retained session receipt identifies the model, reasoning setting and harness. The Author's earlier “6 Astra” wording is consistent with the public family name but does not establish a snapshot or run configuration. |
| A10-M02 | GPT-6 Astra | OpenAI calls Astra its highest-capability GPT-6 model and says it is generally better than GPT-5.6 Sol at staying coherent during long tasks. The same guidance says Astra can be more sensitive to skills and `AGENTS.md`, more likely to stop for clarification, and broader in testing than a small task needs. [Official GPT-6 guidance](https://developers.openai.com/api/docs/guides/latest-model) | These are vendor behavioral claims and prompting cautions, not defect rates or proof that an Extender change is correct. They justify explicit authority, scope and test boundaries. |
| A10-M03 | “GPT-5.6” | OpenAI documents `gpt-5.6` as an alias for `gpt-5.6-sol`, with Terra and Luna as other family members. It supports `none`, `low`, `medium`, `high`, `xhigh` and `max` reasoning; the guidance says to compare settings on representative workloads rather than assume more effort is always the best tradeoff. [Official GPT-5.6 guidance](https://developers.openai.com/api/docs/guides/latest-model?model=gpt-5.6) | A bare family label still omits reasoning, mode, harness, context and tools. Record those inputs for any future comparison. |
| A10-M04 | Direct GPT-6 versus GPT-5.6 result | The official guidance contains a general long-task-coherence claim for Astra, but no public reproducible evaluation was found for this exact P4/ESP-IDF, eZ80, Python and hardware-in-the-loop product. OpenAI also states that model output is nondeterministic and behavior changes between snapshots and families, requiring representative evaluations. [Model-optimization guidance](https://developers.openai.com/api/docs/guides/model-optimization) | No general quality ranking is accepted for AUDIT-010. Repository evidence decides findings. A future model comparison would need a frozen task corpus, blind rubric, repeated runs and executable receipts and is not required to complete this code audit. |

A10-M05 — **Comparative conclusion.** There is evidence for distinct documented
behaviors, but not for the proposition that either family has a higher defect
rate in Extender. Code style, a successful local fix, or a visible regression
cannot identify the authoring model. AUDIT-010 must therefore audit all in-scope
code against the same contracts, regardless of provenance.

## Evidence-backed failure modes and Extender controls

Real-world repository tasks often require coordinated changes across multiple
functions, classes and files and very long contexts, as the original
[SWE-bench paper](https://arxiv.org/abs/2310.06770) explains. A TACL study found
that long-context models could perform materially worse when relevant material
appeared in the middle rather than at the beginning or end, although its tested
models predate GPT-5.6 and GPT-6
([Liu et al., 2024](https://aclanthology.org/2024.tacl-1.9/)). These results
justify explicit coverage and source receipts; they do not measure either
current model.

An empirical taxonomy of 333 bugs from CodeGen, PanGu-Coder and Codex includes
misinterpretation, prompt-biased code, missing corner cases, wrong input types,
hallucinated objects or attributes and incomplete generation
([Tambon et al., 2024](https://arxiv.org/abs/2403.08937)). A later study found
that 7.8% of analyzed plausible SWE-bench patches were counted correct while
failing developer-written tests, while 29.6% behaved differently from the
ground-truth patch
([Wang, Pradel and Liu, 2025/2026](https://arxiv.org/abs/2503.15223)). Those
populations are not Extender and do not yield an Extender failure probability;
they demonstrate why a narrow passing test is insufficient evidence.

| Risk ID | Relevant failure mode | Concrete Extender exposure | Required control |
|---|---|---|---|
| A10-R01 | Incomplete dependency tracing | A display-mode change crosses retained VDP code, selected vendor code, P4 allocation capabilities, output adapters, HTTP snapshots, EMOS-visible state and fixtures. Several generations of implementation coexist in the tree. | A10-02 selected-source ledger; actual compile/link action receipt; caller/consumer tracing across repositories; official API source where documentation is insufficient. |
| A10-R02 | Locally correct but globally inconsistent change | A change can correct LCD output while retaining a larger framebuffer, starving an HTTP connection task, changing browser capture or publishing a mode that did not commit. | Actor-explicit A10-03 transition maps; coexistence/resource matrix; full regression manifest rather than only the triggering fixture. |
| A10-R03 | Instruction or contract drift | Long sessions combine repository instructions, task contracts, accepted ADRs, production pins and later user corrections. OpenAI specifically warns that GPT-6 Astra is sensitive to skills and `AGENTS.md`. | Frozen task contract; one authoritative TODO; source-backed decisions; stable coverage/finding IDs; explicit approval gates; instruction contradictions logged rather than silently resolved. |
| A10-R04 | Fabricated API, dependency or environmental assumption | ESP-IDF capability heaps, FabGL behavior, EMOS/VDP ABI and host packages can be plausible but wrong. Package hallucination is a documented code-generation supply-chain risk in a 576,000-sample study, though that study did not test current GPT-5.6/GPT-6 ([USENIX Security 2025](https://www.usenix.org/conference/usenixsecurity25/presentation/spracklen)). | Verify APIs in official docs/source; compile the selected build; pin and inventory packages; use OSV against recognized manifests; never install a proposed dependency merely because generated code names it. |
| A10-R05 | Weak error paths, rollback or truthfulness | A failed allocation or service startup may leave stale mode state, partial resources, silent fallback or a client-visible reset. Happy-path rendering does not prove rollback. | Manual transition review plus Clang/Cppcheck/Ruff/mypy findings; negative and fault-injection tests; published-state assertions; durable failure receipts. |
| A10-R06 | Lifetime, ownership and concurrency mistakes | Renderer, snapshot, LCD, HTTP, keyboard, UART and storage tasks share buffers, queues, callbacks and shutdown paths. Host models cannot reproduce every FreeRTOS schedule or capability heap. | Static lifetime checks; existing ASan/UBSan host harnesses; selected host TSan only where the same synchronization semantics exist; manual FreeRTOS ownership review; later bounded target heap/task diagnostics. |
| A10-R07 | Test overfitting and incomplete oracle | A deterministic Nurples fixture proved a mode-order symptom but did not by itself prove total exhaustion, fragmentation, a capability-heap shortage or the HTTP failure mechanism. | Preserve counterexamples; test both allocation orders and isolated/simultaneous services; define expected state, not just pixels; run broader regression manifests before accepting a fix. |
| A10-R08 | False completion claims | Compilation, ping, HTTP reset, correct LCD pixels and clean exit each prove different things. One cannot substitute for another. | Evidence matrix that names actor and observation; distinguish build, host, transport and physical evidence; require durable receipts and Author physical acceptance where applicable. |
| A10-R09 | Review bias toward plausible generated code | Fluent code and comments can make locally plausible ownership or fallback behavior appear intentional. Tool output can create a second automation bias. | Review contracts and counter-evidence before authorship; triage every tool report; use canaries and coverage counts; require manual end-to-end tracing; never treat “zero findings” as architecture proof. |
| A10-R10 | Model and harness nondeterminism | Model behavior changes with snapshot, effort, compaction, available tools and context order. [OpenAI's evaluation guidance](https://developers.openai.com/api/docs/guides/evaluation-best-practices) recommends representative regression evaluations and identifies long conversations and ambiguous tool data as edge cases. | Preserve model/harness receipts when model comparison matters; judge product behavior through deterministic builds, tests and evidence rather than confidence in a particular model. |

## Repository-specific analysis constraints

A10-C01 — **Actual C/C++ closure.** `vdp/pio/capture_p4_actual_steps.py`
states that generated ESP-IDF `compile_commands.json` and `build.ninja` refer to
unused CMake `.obj` nodes in this hybrid build; SCons emits the linked `.o`
objects. A10-04 must synthesize analysis commands from a fresh actual-action
capture or prove, file by file and argument by argument, that another database
matches it. The source-selection manifest remains the expected-project-source
set. Analyzer coverage must report selected, successfully parsed, skipped and
failed translation units separately.

A10-C02 — **Compiler diversity.** The production build uses its pinned
Espressif/GCC environment; Clang is an independent parser/analyzer. A Clang
parse failure can reflect GNU extensions, Xtensa/RISC-V builtins, generated
headers or mismatched configuration rather than a product defect. Conversely,
successful Clang parsing does not reproduce the target compiler. Native build
warnings and Clang-based analysis are complementary evidence.

A10-C03 — **Vendor boundary.** Automated tools may scan selected vendor files
and project modifications, but third-party reports must be attributed and
triaged against AUDIT-010's integration-focused scope. Unselected examples,
generated HTML and untouched vendor internals must not dominate counts or
silently enlarge AUDIT-007.

A10-C04 — **Host versus target.** Existing ASan/UBSan harnesses are valuable
for project-owned algorithms and explicit adapters. They do not reproduce P4
heap capabilities, DMA alignment, PSRAM fragmentation, FreeRTOS task stacks,
interrupt context, LCD/DSI timing or physical UART behavior. Every retained
result must name which substitutions the host harness made.

A10-C05 — **Assembly.** No maintained standalone FOSS analyzer was found that
can prove eZ80 register preservation, ADL/24-bit assumptions, bank/address
semantics and MOS/VDP ABI correctness across this product. The selected AgonDev
build, assembler diagnostics, maps, ABI probes, emulator tests and bounded
hardware tests remain necessary. C/C++ or Python scanner success says nothing
about assembly correctness.

A10-C06 — **Privacy and network behavior.** Accepted scanners must execute
locally. Rules and vulnerability data may be downloaded into a pinned local
environment before scanning, but project source, firmware, private bench data,
paths and findings must not be submitted to a hosted service. Auto-fix is off.

## FOSS tool survey — identity and applicability

Versions are the newest maintained releases located on the research cutoff,
not pre-accepted installation choices. A10-02 will record the exact installed
identities after Author selection.

| Tool ID | Tool and research version | Maintained source and license | Languages / analysis class | Compilation database | Target execution |
|---|---|---|---|---|---|
| A10-TL01 | LLVM 23.1.2: Clang diagnostics, Clang-Tidy and Clang Static Analyzer | [23.1.2 release](https://github.com/llvm/llvm-project/releases/tag/llvmorg-23.1.2); [Apache-2.0 WITH LLVM-exception](https://github.com/llvm/llvm-project/blob/main/llvm/LICENSE.TXT) | C/C++; compiler diagnostics, AST lint, path-sensitive static analysis. The [Clang-Tidy manual](https://releases.llvm.org/22.1.0/tools/clang/tools/extra/docs/clang-tidy/index.html) exposes bugprone, analyzer, concurrency, CERT, performance and portability families. | Effectively required at this scale; must satisfy A10-C01. | No for static analysis. LLVM sanitizers require instrumented host execution and an appropriate harness. |
| A10-TL02 | Cppcheck 2.22.0 | [2.22 release/source](https://github.com/cppcheck-opensource/cppcheck/releases/tag/2.22.0); [GPL-3.0](https://github.com/cppcheck-opensource/cppcheck/blob/main/COPYING) | C/C++; independent parser/dataflow for bounds, uninitialized data, lifetime, leaks, API misuse and portability. Its project describes support for non-standard embedded syntax. | Optional but preferred. The [manual](https://github.com/cppcheck-opensource/cppcheck/blob/main/man/manual.md) imports `compile_commands.json`; source-only configuration exploration is also possible. | No. |
| A10-TL03 | Ruff 0.16.9 | [0.16.9 release](https://github.com/astral-sh/ruff/releases/tag/0.16.9); [MIT](https://github.com/astral-sh/ruff) | Python; syntax, correctness, import, exception, modernization and selected security lint rules. | No. | No. |
| A10-TL04 | mypy 2.3.1 | [2.3.1 documentation/changelog](https://mypy.readthedocs.io/en/stable/changelog.html); [MIT](https://github.com/python/mypy/blob/master/pyproject.toml) | Python; gradual static typing and interface consistency. | No; requires import/config resolution and useful annotations or stubs. | No. |
| A10-TL05 | ShellCheck 0.11.0 | [0.11.0 release and maintained source](https://github.com/koalaman/shellcheck/releases/tag/v0.11.0); [GPL-3.0](https://github.com/koalaman/shellcheck/blob/master/LICENSE) | POSIX shell/Bash; syntax, quoting, expansion, pipeline, status and portability semantics. | No. | No. |
| A10-TL06 | Semgrep Community Edition 1.178.0 | [1.178.0 release](https://github.com/semgrep/semgrep/releases/tag/v1.178.0); [LGPL-2.1-or-later](https://github.com/semgrep/semgrep/blob/develop/LICENSE) | Multi-language syntactic/semantic pattern queries. Selected here only for locally authored ownership/API/policy rules, primarily Python and declarative files. | No. | No. |
| A10-TL07 | OSV-Scanner 2.6.0 | [2.6.0 release](https://github.com/google/osv-scanner/releases/tag/v2.6.0); [Apache-2.0](https://github.com/google/osv-scanner/blob/main/LICENSE) | Recognized dependency manifests, lockfiles, SBOMs and installed-package inventories; known-vulnerability and license metadata queries. | No. | No. The [official repository](https://github.com/google/osv-scanner) documents local offline-database scans. |
| A10-TL08 | REUSE 6.2.0 | [6.2.0 release](https://github.com/fsfe/reuse-tool/releases/tag/v6.2.0); the [maintained source](https://github.com/fsfe/reuse-tool) documents original code as GPL-3.0-or-later and mixed licenses for borrowed code/docs/data | Repository copyright/SPDX/license policy and SPDX output. | No. | No. |
| A10-TL09 | PMD Copy/Paste Detector 7.28.0 | [7.28.0 release](https://github.com/pmd/pmd/releases/tag/pmd_releases/7.28.0); [BSD-3-Clause](https://github.com/pmd/pmd/blob/main/LICENSE) | Token-level duplicate detection for C/C++, Python and other languages. | No. | No; requires a Java runtime. |
| A10-TL10 | Vulture 2.16 | [2.16 release](https://github.com/jendrikseipp/vulture/releases/tag/v2.16); [MIT](https://github.com/jendrikseipp/vulture/blob/main/LICENSE.txt) | Python dead/unreachable-code candidates with confidence levels. | No. | No. |
| A10-TL11 | Include-What-You-Use 0.26 | [0.26 release](https://github.com/include-what-you-use/include-what-you-use/releases/tag/0.26); [University of Illinois/NCSA Open Source License](https://github.com/include-what-you-use/include-what-you-use/blob/master/LICENSE.TXT) | C/C++ direct include dependency analysis. The maintained README calls it experimental and binds 0.26 to Clang 22. | Required. | No. |
| A10-TL12 | Gitleaks 8.30.1 | [8.30.1 release](https://github.com/gitleaks/gitleaks/releases/tag/v8.30.1); [MIT](https://github.com/gitleaks/gitleaks/blob/master/LICENSE) | Secret-pattern scanning of files or Git history. | No. | No. |
| A10-TL13 | ESP-IDF 5.5.5 built-in size and heap diagnostics | Project is already pinned to 5.5.5; [ESP-IDF license](https://github.com/espressif/esp-idf/blob/master/LICENSE) is Apache-2.0 | P4 linked-image size plus capability-heap, task-allocation, failed-allocation and heap-trace diagnostics. | No for runtime APIs; size reporting consumes the real map/ELF. | Yes for heap/task behavior; size analysis is host-side over the built image. |

## FOSS tool survey — likely signal, noise, cost and disposition

| Tool ID | Likely Extender signal | Expected false positives / blind spots | Resource cost | Proposed disposition |
|---|---|---|---|---|
| A10-TL01 | Use-after-move, null/lifetime paths, unchecked results, suspicious conversions, lock/API patterns and target-independent UB in selected C/C++. Host ASan/UBSan can expose executed memory/UB faults; a bounded host TSan run can expose races only in faithfully modeled host concurrency. | GNU/ESP attributes, generated headers, FreeRTOS idioms and vendor code may be noisy. Static analysis is path- and model-limited. [ASan typically doubles runtime](https://clang.llvm.org/docs/AddressSanitizer.html); [TSan uses about 5× memory plus 1 MB per thread by default](https://clang.llvm.org/docs/ThreadSanitizer.html) and cannot establish P4 scheduling correctness. | Moderate-to-high installation/storage; moderate scan CPU; high for sanitizers over broad suites. | **Select.** Pin a project-isolated LLVM release, validate actual commands, use a reviewed check set, and prohibit `-fix`. Retain existing native compiler warnings as a separate pass. |
| A10-TL02 | A second parser can find bounds, uninitialized, leak and ownership problems even where Clang cannot consume the embedded build cleanly. | Configuration explosion, macro-heavy ESP code and incomplete library models can create noise; no FreeRTOS schedule or target heap model. | Moderate CPU and result volume; small-to-moderate install. | **Select as a bounded complementary pass.** First run project-owned/selected files with the validated configuration; stop expanding configurations if the pilot produces no unique signal. |
| A10-TL03 | High-signal Python correctness, exception, resource, import and obvious security issues in build, deployment, fixture and receipt tools. | Rule families can conflict with established style; lint does not prove subprocess protocol, filesystem atomicity or hardware behavior. | Low. | **Select.** Start with correctness/error/security families, report-only, and add style only where it bears on correctness. |
| A10-TL04 | Interface/return-state mismatches, `None` handling, collection shape and typed receipt/schema errors in higher-risk Python tools. | [Mypy does not type-check unannotated function bodies by default](https://mypy.readthedocs.io/en/stable/dynamic_typing.html); dynamic imports, subprocess data and loosely typed scripts limit coverage. Repo-wide strict mode would create annotation debt unrelated to defects. | Low-to-moderate; potentially high triage if enabled indiscriminately. | **Select, staged.** Analyze already typed modules and high-risk orchestration/receipt code first; record typed-line/module coverage. Do not add annotations merely to silence the tool during audit. |
| A10-TL05 | Quoting, wildcard, pipeline-status, unset-variable and portability faults in the small shell surface. | Cannot understand external command contracts or hardware state; intentional word splitting needs review. | Very low. | **Select.** The source surface is small and the semantic signal is distinct. |
| A10-TL06 | Enforce Extender-specific forbidden bypasses, owner-only calls, missing paired cleanup patterns, diagnostic-build guards and policy-sensitive APIs that generic linters do not know. | Semgrep itself states CE is limited to single-file/single-function analysis and tolerates more noise; its advanced C/C++ capabilities are in the proprietary engine ([CE comparison](https://semgrep.dev/products/semgrep-vs-ce/)). A match cannot prove cross-file ownership or absence. | Low-to-moderate for narrow local rules. | **Select narrowly.** Use only reviewed, checked-in local rules with positive/negative canaries and metrics/network disabled. Do not use cloud, Assistant, Pro rules or C/C++ security claims. |
| A10-TL07 | Known vulnerabilities and license metadata for dependency ecosystems and lockfiles it recognizes. It can reveal stale host Python or packaged dependencies relevant to build/deployment integrity. | PlatformIO/ESP-IDF managed components, vendored snapshots and ad hoc pins may be absent or mapped imperfectly. A match does not prove exploitability; a clean result covers only recognized packages and database contents. | Moderate initial database download/disk; low-to-moderate scan. | **Select in offline scan mode.** Record recognized and unrecognized manifests separately; do not run experimental remediation or package-manager actions. |
| A10-TL08 | Missing SPDX/copyright/license records across project files and bundled source. | Extender already has layered notices and vendor provenance not necessarily expressed file-by-file in REUSE form, so initial noise could be very high and remediation could become unrelated metadata work. | Low scan cost, potentially high triage/remediation cost. | **Defer.** First use current manifests, `NOTICES.md` and AUDIT-010 vendor ledger. Pilot REUSE later only if those expose an unresolved provenance gap. |
| A10-TL09 | Large copied blocks that may have diverged, duplicated ownership or repeated fixes across C/C++ and Python. | Token similarity is not semantic duplication; generated fixtures, protocol tables and vendor code dominate unless carefully excluded. Requires Java, currently absent. | Moderate-to-high install/disk and triage. | **Defer.** Manual coverage-ledger review should identify suspicious duplication first; then run CPD against named project-owned areas if needed. |
| A10-TL10 | Unused or unreachable Python functions and imports that may expose abandoned paths. | The project explicitly uses callbacks, plugin-like entry points and generated/invoked scripts; [Vulture documents both missed dead code and implicit-call false positives](https://github.com/jendrikseipp/vulture). | Low. | **Defer.** Use Ruff, mypy, coverage/callers and manual tracing first. Run Vulture only against a bounded module with an explicit entry-point whitelist. |
| A10-TL11 | Direct include hygiene and accidental dependency coupling. | Its own README calls it experimental; version 0.26 targets Clang 22 while the current LLVM release is 23.1.2. Embedded generated headers and the hybrid build add mapping noise. It does not find lifecycle defects. | High integration effort relative to expected A10 signal. | **Exclude from A10-04.** Reconsider only for a demonstrated include/dependency problem. |
| A10-TL12 | Current-tree credentials or private tokens committed in ordinary files. | The latest release has a reproducible maintainer-repository report that canonical secrets can produce “no leaks found” with exit 0 ([issue 2170](https://github.com/gitleaks/gitleaks/issues/2170)). Git-history mode would also violate AUDIT-010's historical-review gate. | Low scan cost but unacceptable false-assurance risk at this version. | **Exclude 8.30.1.** A later fixed/pinned version would require a known-secret canary and current-tree-only scope unless the Author separately approves bounded history. |
| A10-TL13 | Distinguish total free memory from largest contiguous block, capability-specific shortage and low-water marks; attribute allocations to tasks; capture requested size/capabilities/function on failure. Static size reports expose linked DRAM/IRAM/flash growth. | Heap tracing/task tracking consume RAM and can severely affect allocator performance; broad hooks can perturb the exact shortage under study. Static size cannot show runtime allocations or fragmentation. [ESP-IDF heap documentation](https://docs.espressif.com/projects/esp-idf/en/latest/esp32p4/api-reference/system/heap_debug.html) describes these APIs and overhead. | Low for size reports; moderate-to-high and perturbing for target tracking. | **Select only as later A10-03/A10-06 targeted diagnostics, not a general A10-04 scan.** Each instrumentation change and hardware run needs the task's bounded plan and authorization. |

## Recommended minimum A10-04 tool set

The following set is recommended for Author acceptance. “Minimum” means each
item covers a distinct risk class; it does not mean every available rule should
be enabled.

A10-SET01 — **Existing build and executed host checks.** Preserve the selected
target compilers' warnings and all existing `-Wall -Wextra -Werror` builds.
Inventory and run the existing ASan/UBSan host harnesses under their documented
substitutions. Add no broad sanitizer mode until coverage and cost are known.

A10-SET02 — **LLVM 23.1.2 static pass.** Use Clang-Tidy plus Clang Static
Analyzer over the actual selected project C/C++ closure. Start with compiler,
`clang-analyzer-*`, `bugprone-*`, relevant `cert-*`, `concurrency-*`,
`performance-*` and `portability-*`; remove style-only or inapplicable checks
before the full run. Record parse/coverage counts. Do not auto-fix.

A10-SET03 — **Cppcheck 2.22.0 complementary pass.** Run project-owned and
actively selected C/C++ with the validated defines/includes and a bounded
configuration policy. Compare unique findings with LLVM before considering any
additional configuration expansion.

A10-SET04 — **Python and shell pass.** Run Ruff 0.16.9 across project-owned
Python with reviewed correctness/error/security rules; run mypy 2.3.1 in staged
modules with explicit coverage; run ShellCheck 0.11.0 over maintained shell
scripts. Generated, frozen-evidence and third-party paths need explicit
inclusion/exclusion records rather than silent global ignores.

A10-SET05 — **Local semantic-policy pass.** Run Semgrep CE 1.178.0 only with
locally stored, reviewed A10 rules and canaries. Initial rules should encode
specific known contracts such as owner-only ordinary VDU routing, forbidden
diagnostic code in release selections, allocation/cleanup pair leads and direct
bypasses identified by the coverage ledger. A generic public ruleset is not a
substitute for this pass.

A10-SET06 — **Dependency-vulnerability inventory.** Run OSV-Scanner 2.6.0
offline over recognized current-tree manifests/locks and any task-produced SBOM.
Report ecosystem coverage and unmatched pins. Disable remediation.

A10-SET07 — **Manual assembly, architecture and lifecycle review.** This is part
of the minimum even though it is not a new executable. None of A10-SET01 through
SET06 can prove cross-task ownership, rollback transactions, capability-heap
budgets, eZ80 ABI behavior or truthful externally published state.

## Tool-to-risk coverage and non-claims

| Risk ID | Primary automated evidence | Required manual or runtime evidence | What the combined check still cannot establish |
|---|---|---|---|
| A10-R01 dependency tracing | Actual-action coverage manifest; LLVM parse receipts; Semgrep owner/API matches; Python import/type checks | Coverage-ledger caller/consumer trace across all three project repositories and official references | That every runtime callback, indirect call, assembly edge or generated selection is semantically correct. |
| A10-R02 global inconsistency | Full selected builds; cross-module type/lint; regression suite | Resource/coexistence matrix and end-to-end transition review | Physical service coexistence, peak target resources or externally observed truth without bounded runs. |
| A10-R03 instruction drift | Local Semgrep/policy rules; task/document link and manifest validators | Reconcile current contract, ADR, handbook, production selection and source | That an instruction is the right product decision; Author acceptance remains authoritative. |
| A10-R04 fabricated API/dependency | Compiler/type/import failures; OSV recognized-package report | Official documentation/source verification and pin/provenance review | That an existing API was used with the right lifecycle or that an unrecognized pin is safe. |
| A10-R05 weak errors/rollback | Clang Analyzer, Cppcheck, Ruff, mypy; executed negative tests | Transaction/state trace and fault injection | Completeness of all failure paths or truthfulness to every consumer. |
| A10-R06 lifetime/concurrency | Static lifetime checks; existing ASan/UBSan; bounded host TSan where faithful | FreeRTOS lock/task/callback review and targeted target diagnostics | Absence of target races, ISR violations, stack overflow, capability fragmentation or timing faults. |
| A10-R07 test overfit | Regression manifest, coverage counts and negative cases | Author-reviewed behavioral oracle; isolated and simultaneous service runs | Equivalence to every real application or workload. |
| A10-R08 false completion | Durable phase/result receipts and independent artifact hashes | Evidence-scope review and physical observation where required | A broader success claim than the named observation. |
| A10-R09 review bias | Independent parsers with known-defect canaries; complete triage ledger | Counter-evidence review and source-contract reasoning | That tool agreement means correctness; correlated rules and shared assumptions remain possible. |
| A10-R10 nondeterminism | Frozen commands, versions, inputs and machine-readable output | Repeat only the cases where variability matters and retain exact receipts | General future behavior of a changed model, tool release, environment or target timing. |

## A10-04 execution safeguards proposed for review

A10-ES01 — Every accepted tool runs from an isolated, pinned environment and
prints its version into the receipt. Record binary/package hashes where the
installation channel provides them.

A10-ES02 — Before the real scan, every tool receives a tiny task-owned positive
canary and, where meaningful, a negative canary. Failure to detect the positive
case is a tool failure, not a clean product result. Delete or retain canaries in
the task silo; never seed product source with artificial defects.

A10-ES03 — Produce an explicit input manifest for each run. Counts must separate
project-owned source, selected vendor integration, third-party source, generated
source, tests/fixtures, frozen evidence, skipped files and parse failures.

A10-ES04 — C/C++ analysis begins only after an actual-action-derived or
independently proven compilation database matches the A10-02 selected-source
closure. A generic CMake database is inadmissible for this build.

A10-ES05 — Tools run report-only with network/telemetry disabled during source
analysis. No auto-fix, mass annotation, formatter rewrite, guided dependency
remediation or package-manager execution is permitted.

A10-ES06 — Retain raw machine-readable output and exact commands in the task
silo. Every report is triaged as confirmed, false positive, accepted exception
or unresolved. Suppressions require a local rationale and cannot hide parse or
coverage failure.

A10-ES07 — Run broad source analysis before repairs. Later targeted diagnostics
or per-fix reruns supplement, but do not silently replace, the frozen audit
result or previously passed regression manifest.

## First target diagnostic implied by the latest LCD/Nurples round

This is a proposal for later A10-03/A10-06 authorization, not work performed by
A10-01.

A10-DIAG01 — At boot, before game-asset load, immediately before and after
mode-20 allocation, after snapshot/LCD/HTTP service initialization, and at the
first failed allocation, record `heap_caps_get_free_size()`,
`heap_caps_get_largest_free_block()`, `heap_caps_get_minimum_free_size()` and
the relevant `multi_heap_info_t` fields separately for default/internal,
8-bit, DMA-capable and PSRAM capabilities. ESP-IDF documents the largest free
block as the largest currently possible single allocation and recommends
comparing it with total free memory to detect fragmentation
([ESP-IDF heap debugging](https://docs.espressif.com/projects/esp-idf/en/latest/esp32p4/api-reference/system/heap_debug.html)).

A10-DIAG02 — Register the failed-allocation callback only in the diagnostic
build so the P4 reports requested size, requested capabilities and originating
function. Add task-stack high-water marks for the renderer, LCD, HTTP and
snapshot tasks. Use a bounded standalone heap trace only if the lightweight
measurements do not discriminate total exhaustion, fragmentation,
capability-specific exhaustion and retained/leaked allocation.

A10-DIAG03 — Compare the two already demonstrated orders: early mode 20 before
assets and late mode 20 after assets. Run isolated LCD, isolated browser and
simultaneous LCD/browser cases separately. Browser clients remain disconnected
except in the cases that require them. Static linked-image size belongs in the
receipt but cannot explain runtime fragmentation; ESP-IDF notes that runtime
heap is lower than compile-time static estimates because startup allocates task
and other resources
([ESP-IDF memory allocation](https://docs.espressif.com/projects/esp-idf/en/v5.5/esp32p4/api-reference/system/mem_alloc.html)).

A10-DIAG04 — Declare the diagnostic overhead and removal condition before the
build. Heap task tracking is not a passive observer: ESP-IDF warns of
non-negligible RAM overhead and severe allocator-performance impact. Therefore
the first diagnostic should use lightweight snapshots and a failed-allocation
callback, not broad allocation tracking.

## Research disposition

A10-RD01 — A10-01a is satisfied by A10-R01 through A10-R10 and their controls.

A10-RD02 — A10-01b is satisfied with a negative comparative result: documented
behavioral differences exist, but no evidence justifies a general GPT-6 versus
GPT-5.6 code-quality ranking for Extender, and the bare labels do not completely
identify the runs.

A10-RD03 — A10-01c and A10-01d are satisfied by A10-TL01 through A10-TL13,
including selected, deferred and excluded tools across compiler/sanitizer,
static, semantic-policy, dependency, duplicate/dead-code, Python, security,
repository-policy and target-diagnostic classes.

A10-RD04 — A10-01e is satisfied by A10-SET01 through A10-SET07, the risk
coverage table and A10-ES01 through A10-ES07. The recommendation is not
authorization to install or execute anything.

A10-RD05 — **Review gate.** The Author should accept, revise or reject the
recommended set and safeguards before A10-P01/A10-02 proceed and before any new
scanner installation or run. A10-01 did not inspect Git history and did not
trigger any A10-H01 through A10-H07 exception.

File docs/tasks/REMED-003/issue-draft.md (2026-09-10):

# Draft: host-directory SD accepts an existing FA_CREATE_NEW file and fails f_sync

Ready for review; unsubmitted. The identical executable has now been checked
on physical Agon hardware and both emulator SD backends.

## Summary

The same standalone MOS application produces different FatFS results with
Fab's host-directory SD backend and its raw FAT-image backend. An existing
file opened with `FA_WRITE | FA_CREATE_NEW` returns success in directory mode
instead of `FR_EXIST`. `f_sync` on a successfully opened and written file then
returns `FR_INVALID_OBJECT` (9). Raw-image mode and physical Agon hardware
return the expected results.
The original file remains intact because the reproducer deliberately closes
the unexpectedly successful open without writing to it.

## Reproducer and results

The [small C application](fixture/src/main.c) uses only public MOS APIs.
It needs MOS 3.0 or later for `ffs_fsync`; it uses no EMOS-specific operation,
UART peer, direct hardware access or emulator-specific conditional code.
Each run creates a new `/extender/fscheck/Rnnnnn` directory and saves
`RESULT.TXT`, `CREATE.DAT` and `SYNC.DAT` there.

| Observation | Expected | Fab host directory | Fab raw FAT image | Physical Agon |
| --- | --- | --- | --- | --- |
| Open existing file with FA_CREATE_NEW | 8, FR_EXIST | **0, FR_OK** | 8 | 8 |
| Re-read original contents | Unchanged | Unchanged | Unchanged | Unchanged |
| Sync an open, written file | 0, FR_OK | **9, FR_INVALID_OBJECT** | 0 | 0 |
| Close file | 0 | 0 | 0 | 0 |
| Reopen/read written contents | Match | Match | Match | Match |

These are independently reported numeric observations, not just an aggregate
PASS/FAIL. All three runs used the identical binary:

Retained output: [directory mode](evidence/directory-result.txt),
[raw FAT image](evidence/image-result.txt), [physical Agon](evidence/hardware/RESULT.TXT),
[initial emulator observations](evidence/observations.json) and
[hardware collection record](evidence/hardware/collection.json). The returned
SD's executable hash matches the emulator executable, and both saved sentinel
files match byte-for-byte. These records do not invent exact run-start times.
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

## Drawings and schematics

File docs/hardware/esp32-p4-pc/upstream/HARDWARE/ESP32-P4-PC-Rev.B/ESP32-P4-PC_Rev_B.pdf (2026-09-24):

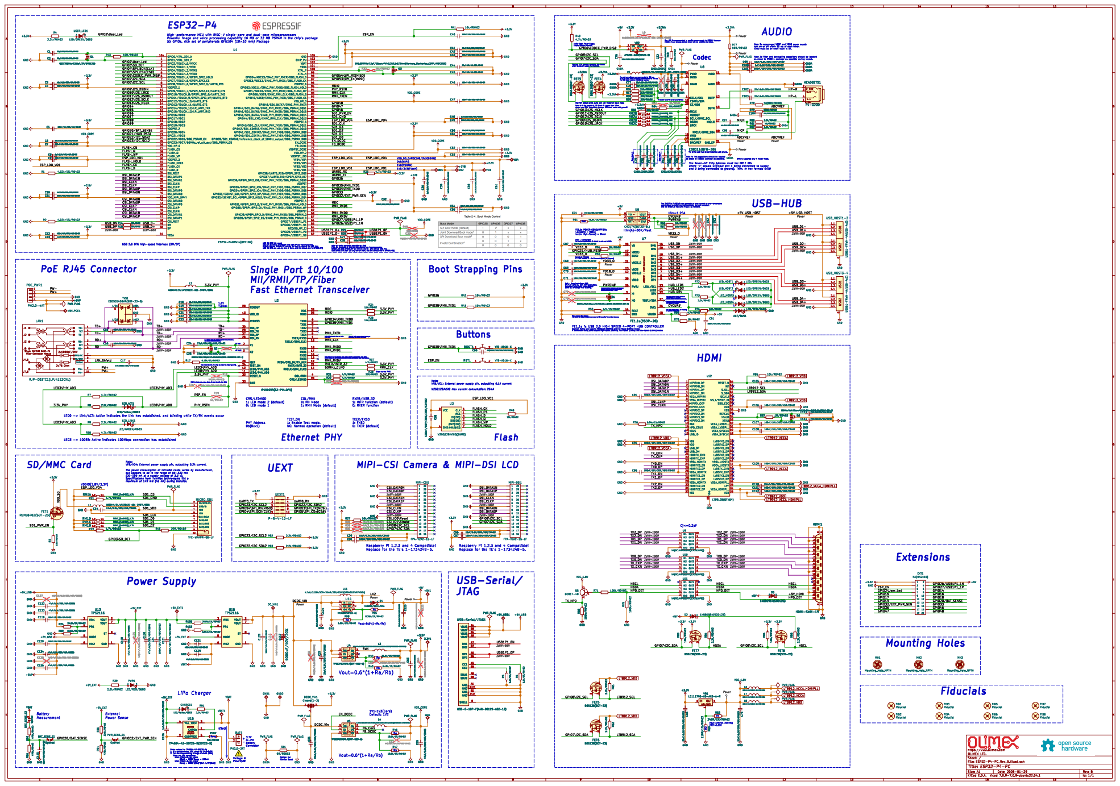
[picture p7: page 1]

One LDO is recommended to provide power supply to ES8311 because ES8311 is an analog device which will be sensitive to noise. PoE RJ45 Connector

Iout(max)=150mA@(VIN>=VOUT+1V)

Note 3: recommend VDDP and VDDD power supply

The two FETs prevent powering the Codec when its power supply is disabled.

The termal pad must be connected to audio ground.

VDD_SD_CARD(1V8/3V3(SDIO))
as close to ES8311 package as possible. 1V8/3V3(Flash)
2V5(MIPI)
1V8(PSRAM)

DMIC is supported only in master mode.

and 0 being connected to ground). Then, in hex format: 0x18

connectedto USBportVBUS Currentlimiting thresholdsetting, externalresistorRsetto GND to setIset ground

alarmopen-drainoutput,activelow Common

USB 2.0 OTG full-speed

Single Port 10/100
MII/RMII/TP/Fiber
Fast Ethernet Transceiver

RESET_N: Enable a low status signal will reset the chip. Type I(PU).

CRS/LEDMOD
1: LED mode 2 (default) 0: LED mode 1

COL/RMII 0: MII Mode

RXER/INTR_32
1: INTR function (default) 0: RXER function

GND GND GND GND GND GND GND GND GND

TEST_ON
1: Enable Test mode. NC: Normal operation (default)
Ethernet PHY

9 MIPI-DSI1 FPA-VZA2-15-LF GND GND

Card DetectSwitch Card'sHousing DAT2/RES 1

TFC-WPAPR-08-LF GND

Raspberry Pi 1,2,3 and 4 Compatible!
Replace for the TE's 1-1734248-5.

V(ENL)=0.4V(Max) Vin=(2-24)VDC

Vout=0.6*(1+Rc/Rd) LX 1 GND
Current(Shutdown)=1uA(Max) FB InputBiasCurrent=-50nA(min) FB Voltage=0.6V(Typical) OperatingInputVoltage
QuiescentCurrent(PFM)=200uA(Max) QuiescentCurrent(PWM)=2.2mA(Max) RecommendedInductorvalues:up to 22uH.

The inductorshouldhavelow corelossat 1.2MHz andlow DCR for betterefficiency. RecommendedInput/OutputCapacitors: 22uF/X5R(X7R). Schottkydiodeis a goodchoicefor MT3608

because of its low forwardvoltagedropandfast reversesrecovery. V(ENH)=1.5V(Min)

1 2 BAT_SENS_E2 Opened C115 100nF/10V/20%/X5R/C0402 C37 22uF/6.3V/20%/X5R/C0603 C116 NA(47uF/6.3V/20%/X5R/C0805) GND GND C34 NA(22uF/6.3V/20%/X5R/C0603) 1 C117 2 1000uF/10V/20%

(SOT563-6) A 0.47uHinductorcanalsobe usedwith thesamerecommendedoutput capacitorsfortheTPS62A02x. a largervaluereducesinputvoltageripple. Cin=4.7uF/6.3V/X5R

Cout=(10~22)uF/6.3V/X5Rþÿ(Vout"e1.8V). 22uFRecommended! Cout=22uF/6.3V/X5Rþÿ(1.2V"dVout<1.8V) Cout=44uF/6.3V/X5Rþÿ(0.6V"dVout<1.2V) DCR<50mR

In casea loweroutputrippleisdesired,higheroutputcapacitancecanhelpreducetheripple. Lx=1.0uH

Donotfloat. Enablecontrol. FB Input Current,I(FB)=100nA(max) FeedbackReferenceVoltage,V(REF)=0.6V
Rb mustnotbehigherthanþÿ100k© toprovideacceptablenoisesensitivity. ShutdownCurrentI(SHDN)=0.01-2uA

Option for Ferrite Bead Voltage &
GND
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

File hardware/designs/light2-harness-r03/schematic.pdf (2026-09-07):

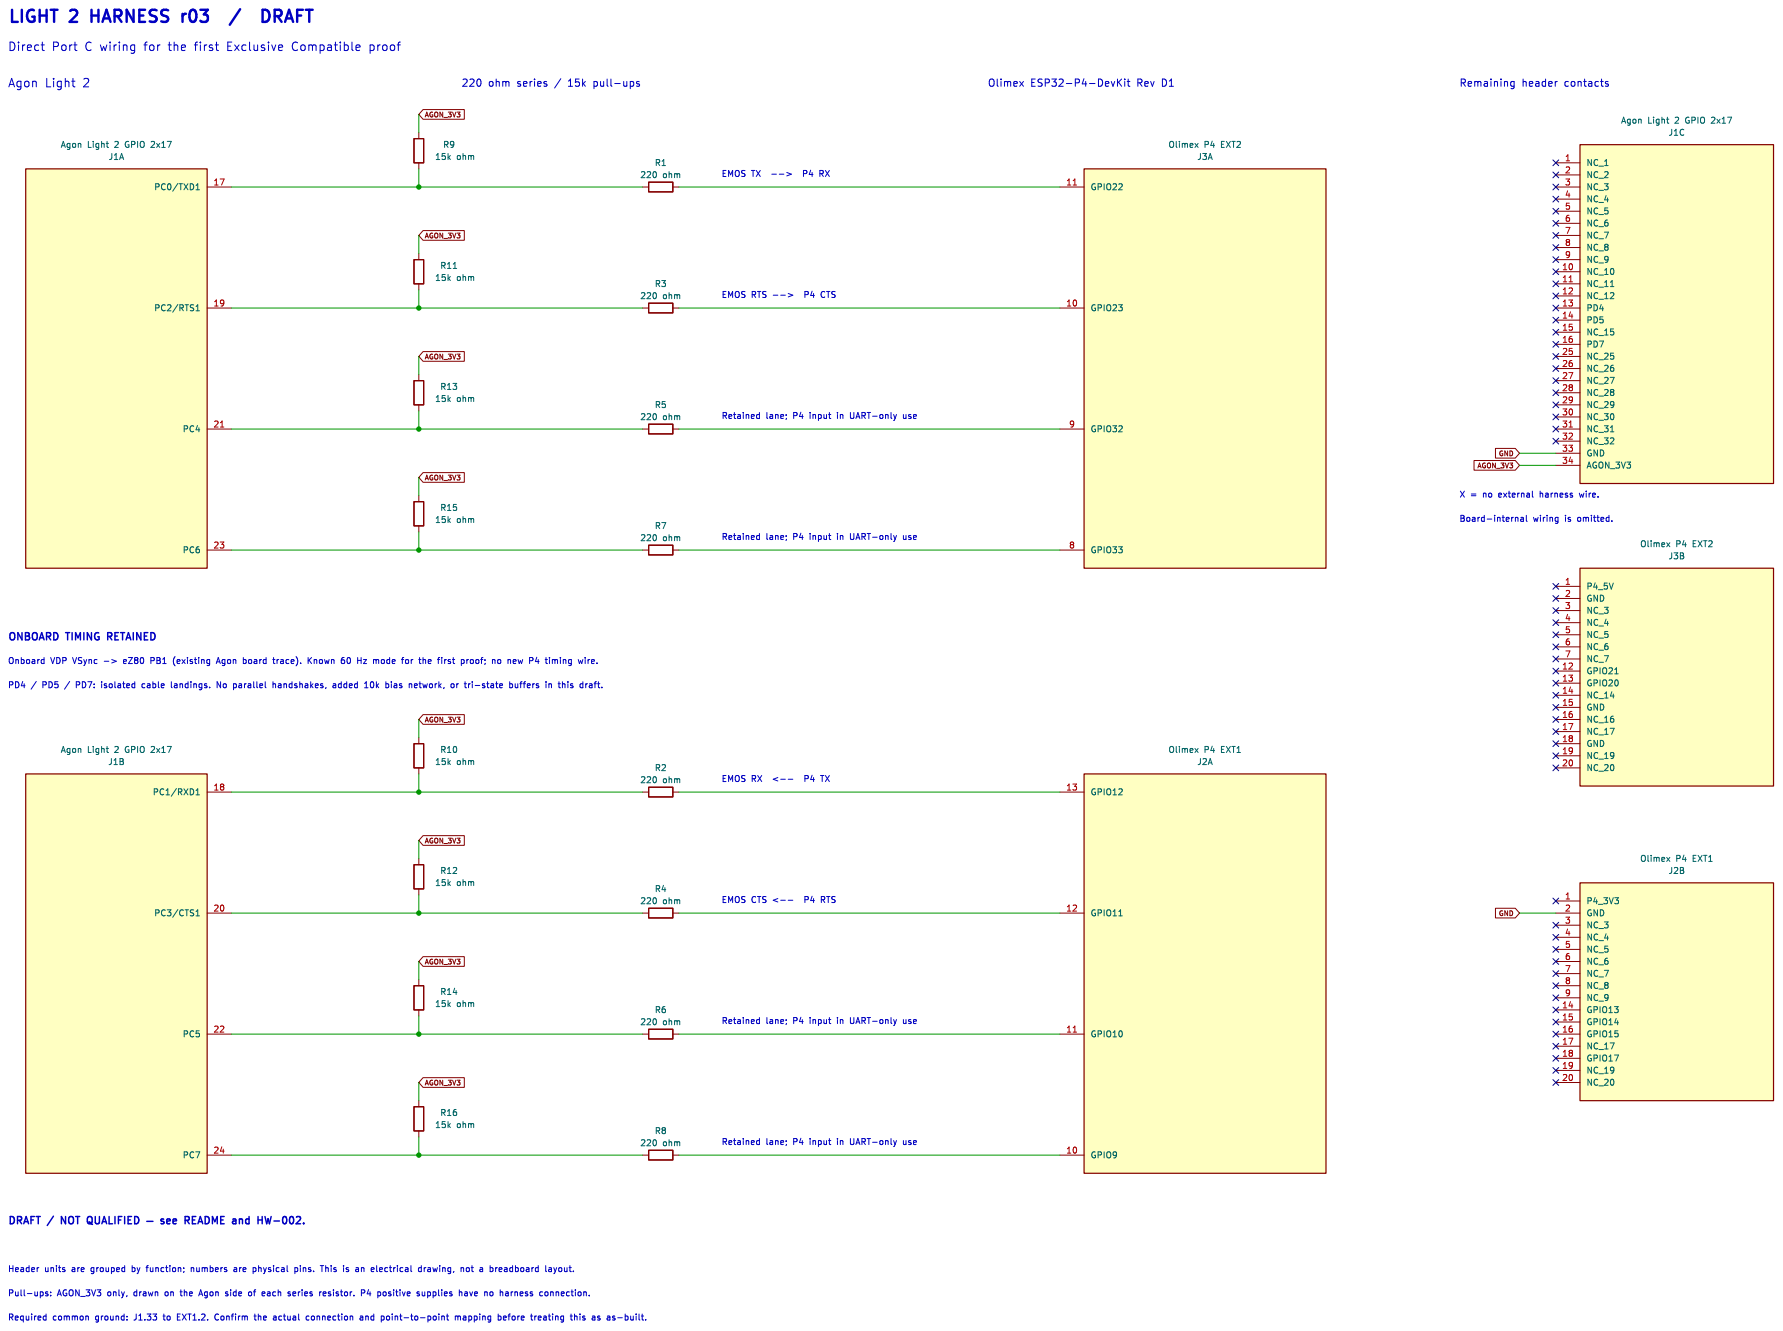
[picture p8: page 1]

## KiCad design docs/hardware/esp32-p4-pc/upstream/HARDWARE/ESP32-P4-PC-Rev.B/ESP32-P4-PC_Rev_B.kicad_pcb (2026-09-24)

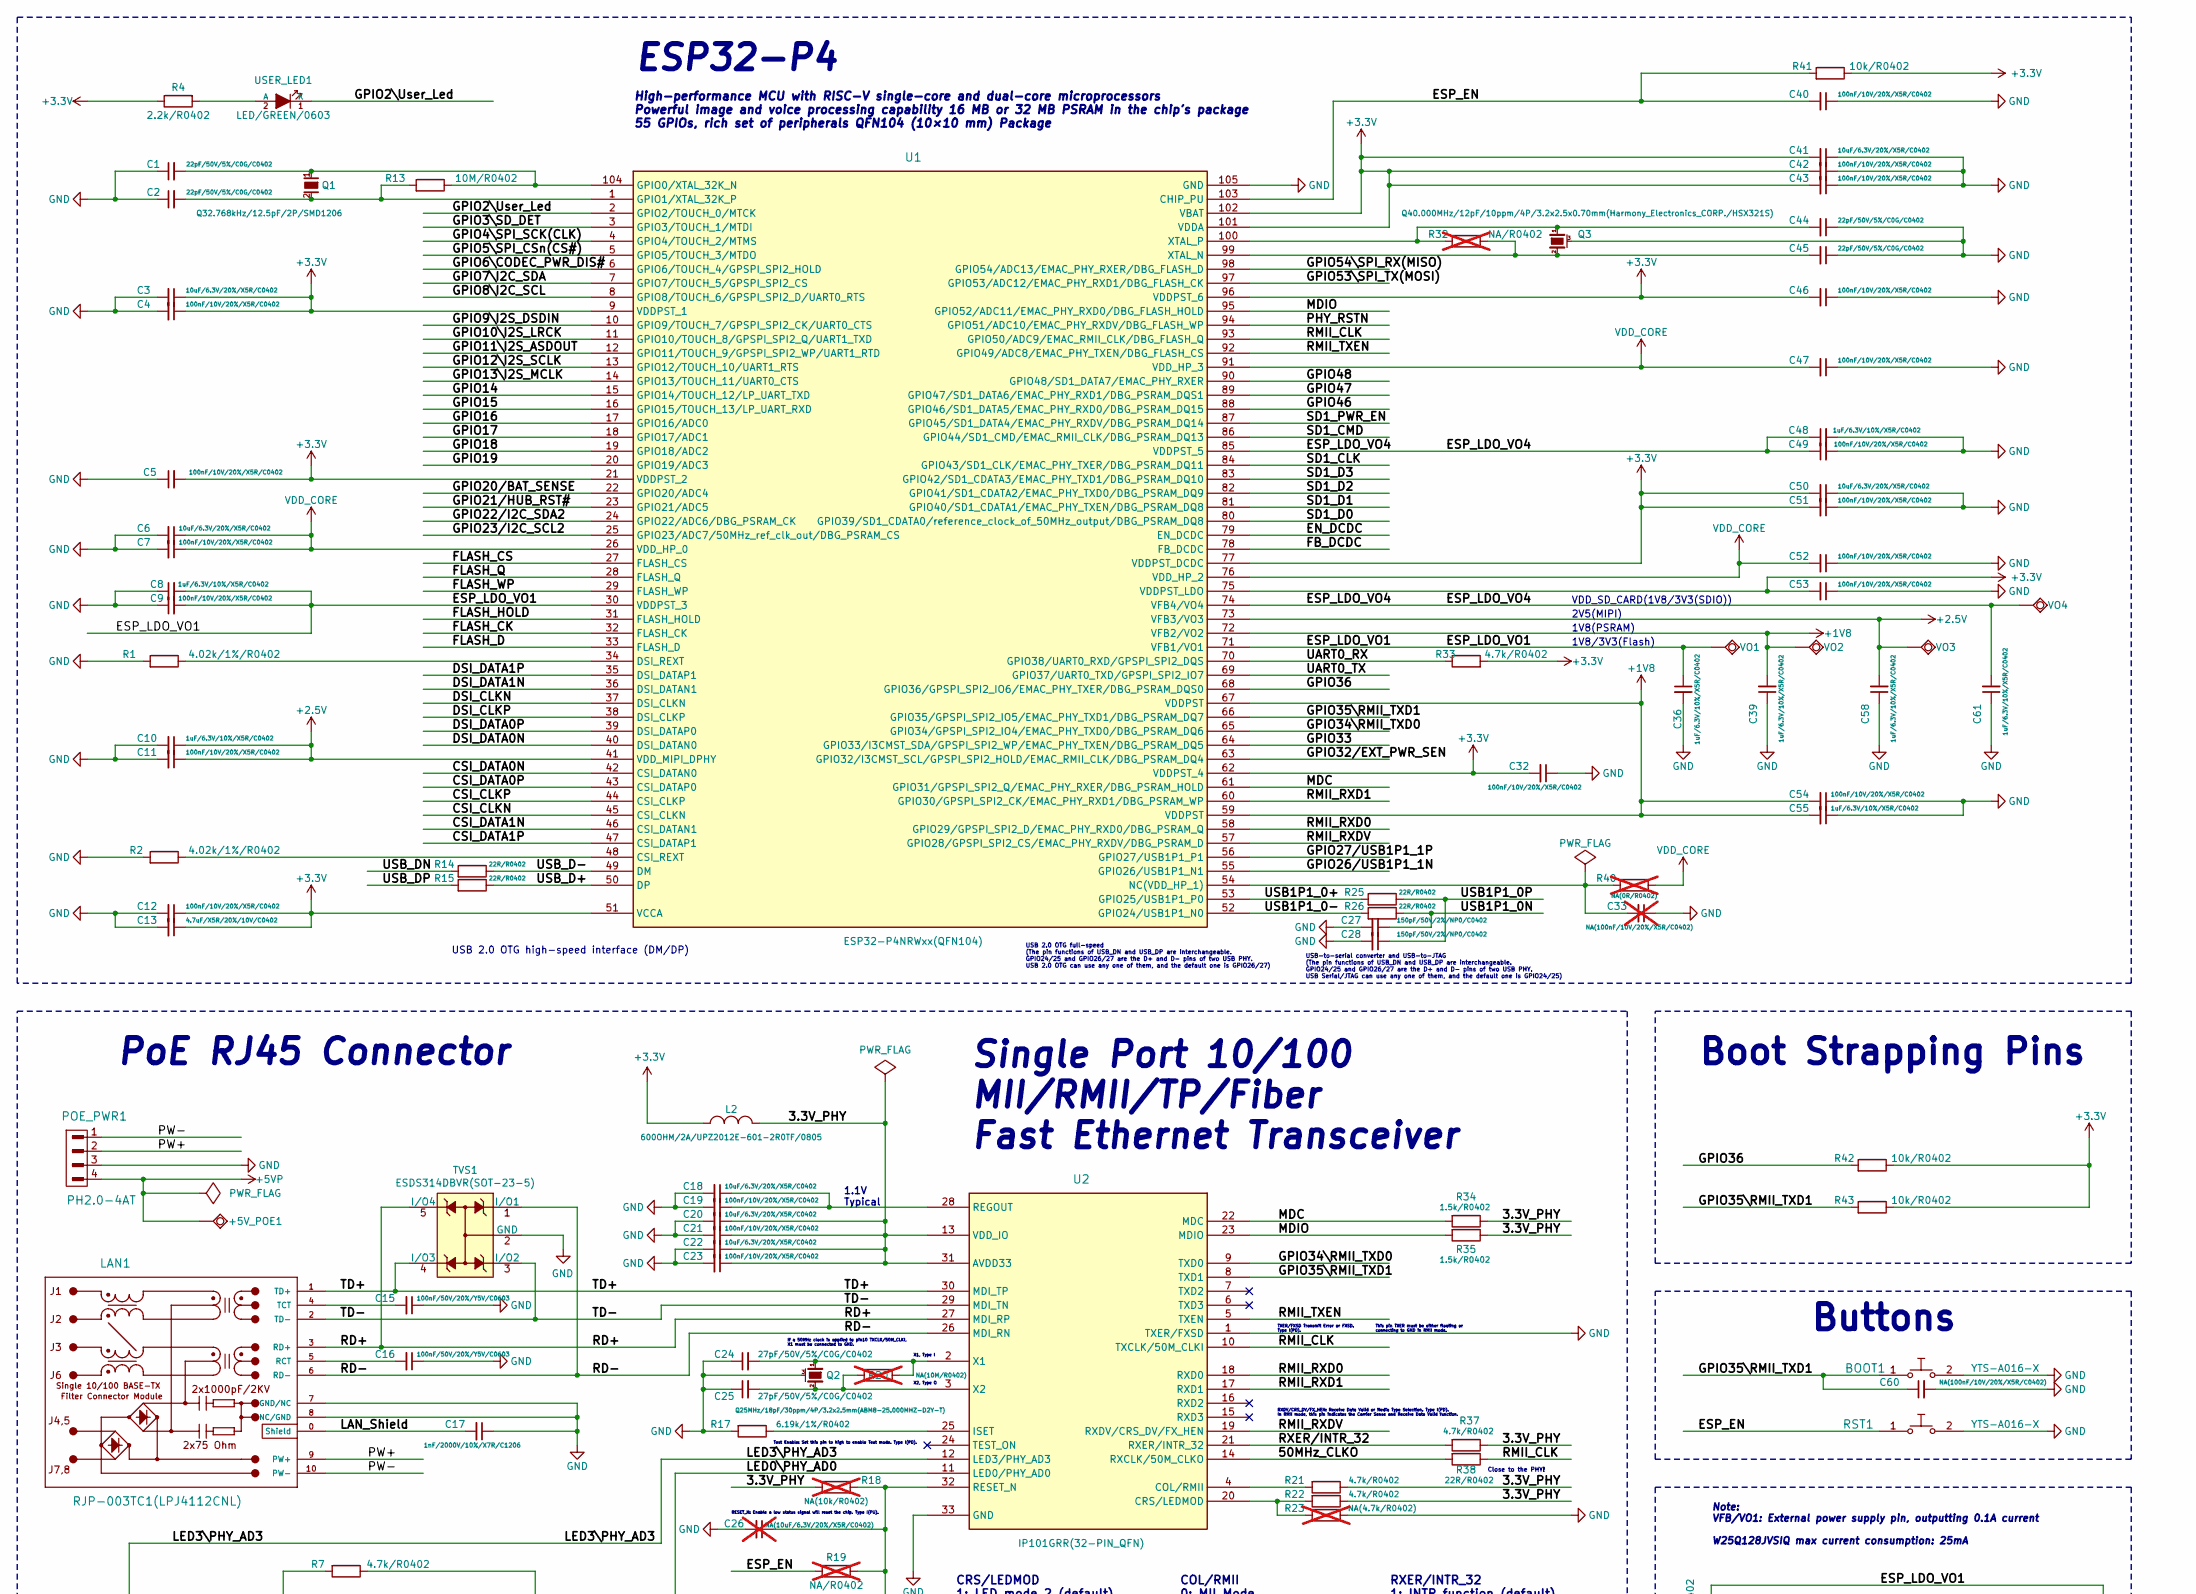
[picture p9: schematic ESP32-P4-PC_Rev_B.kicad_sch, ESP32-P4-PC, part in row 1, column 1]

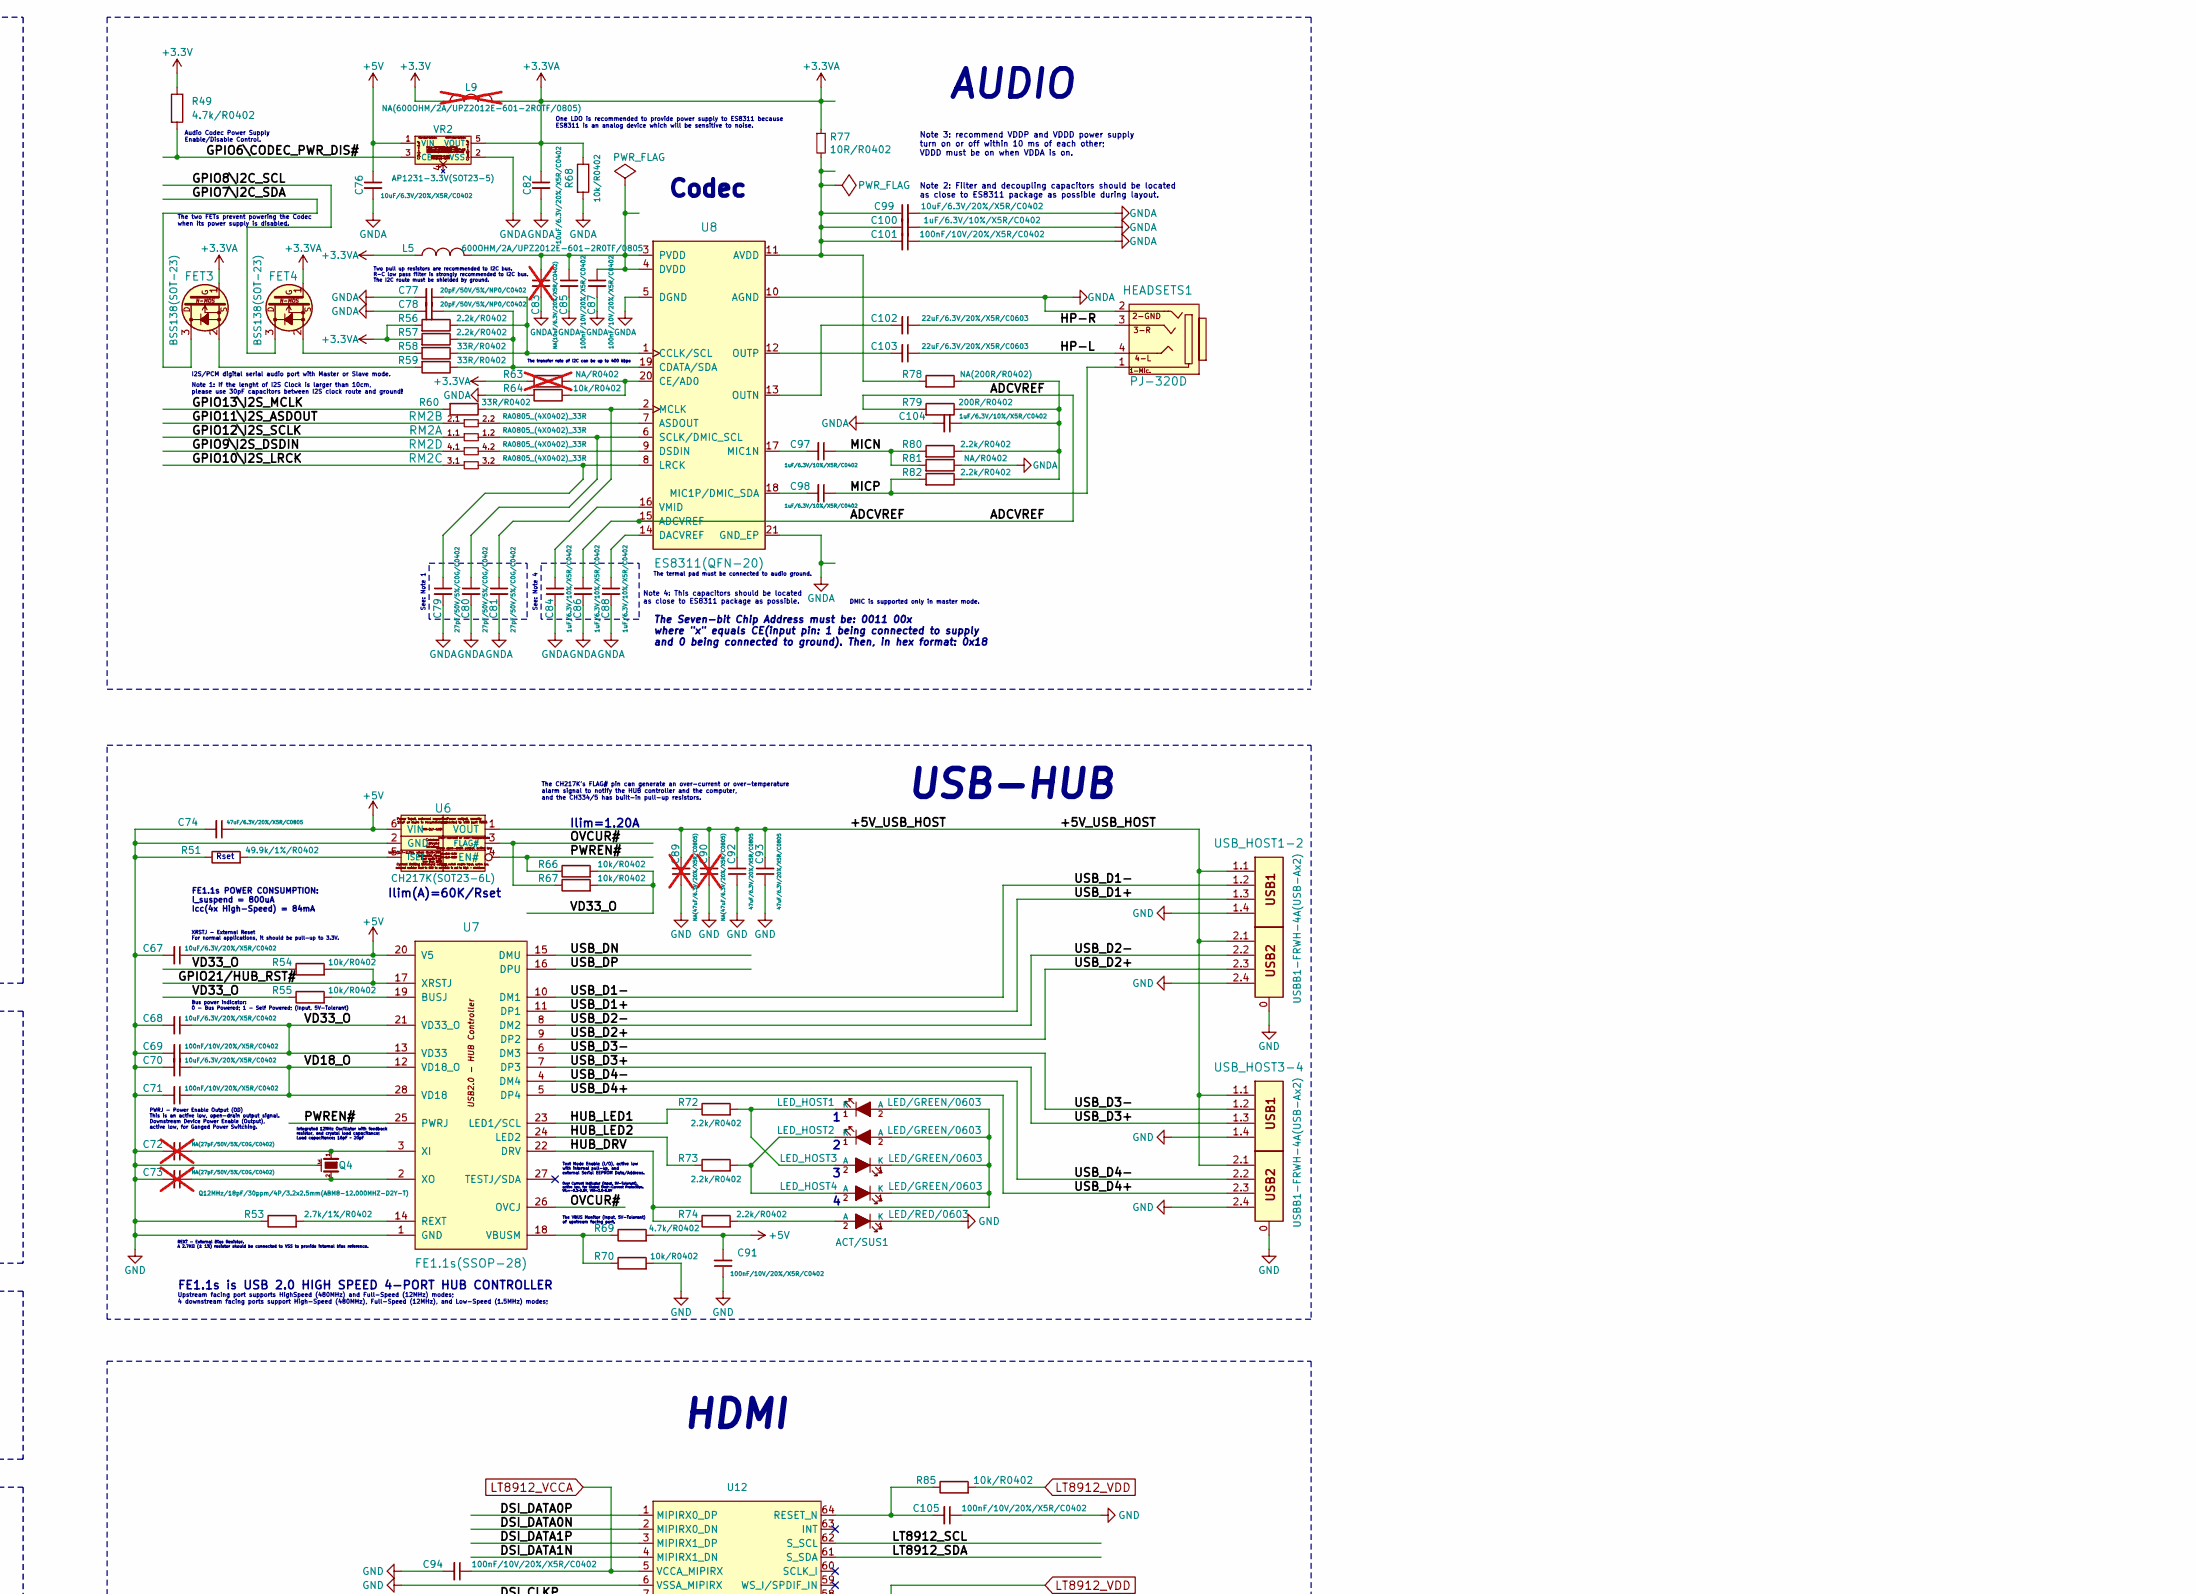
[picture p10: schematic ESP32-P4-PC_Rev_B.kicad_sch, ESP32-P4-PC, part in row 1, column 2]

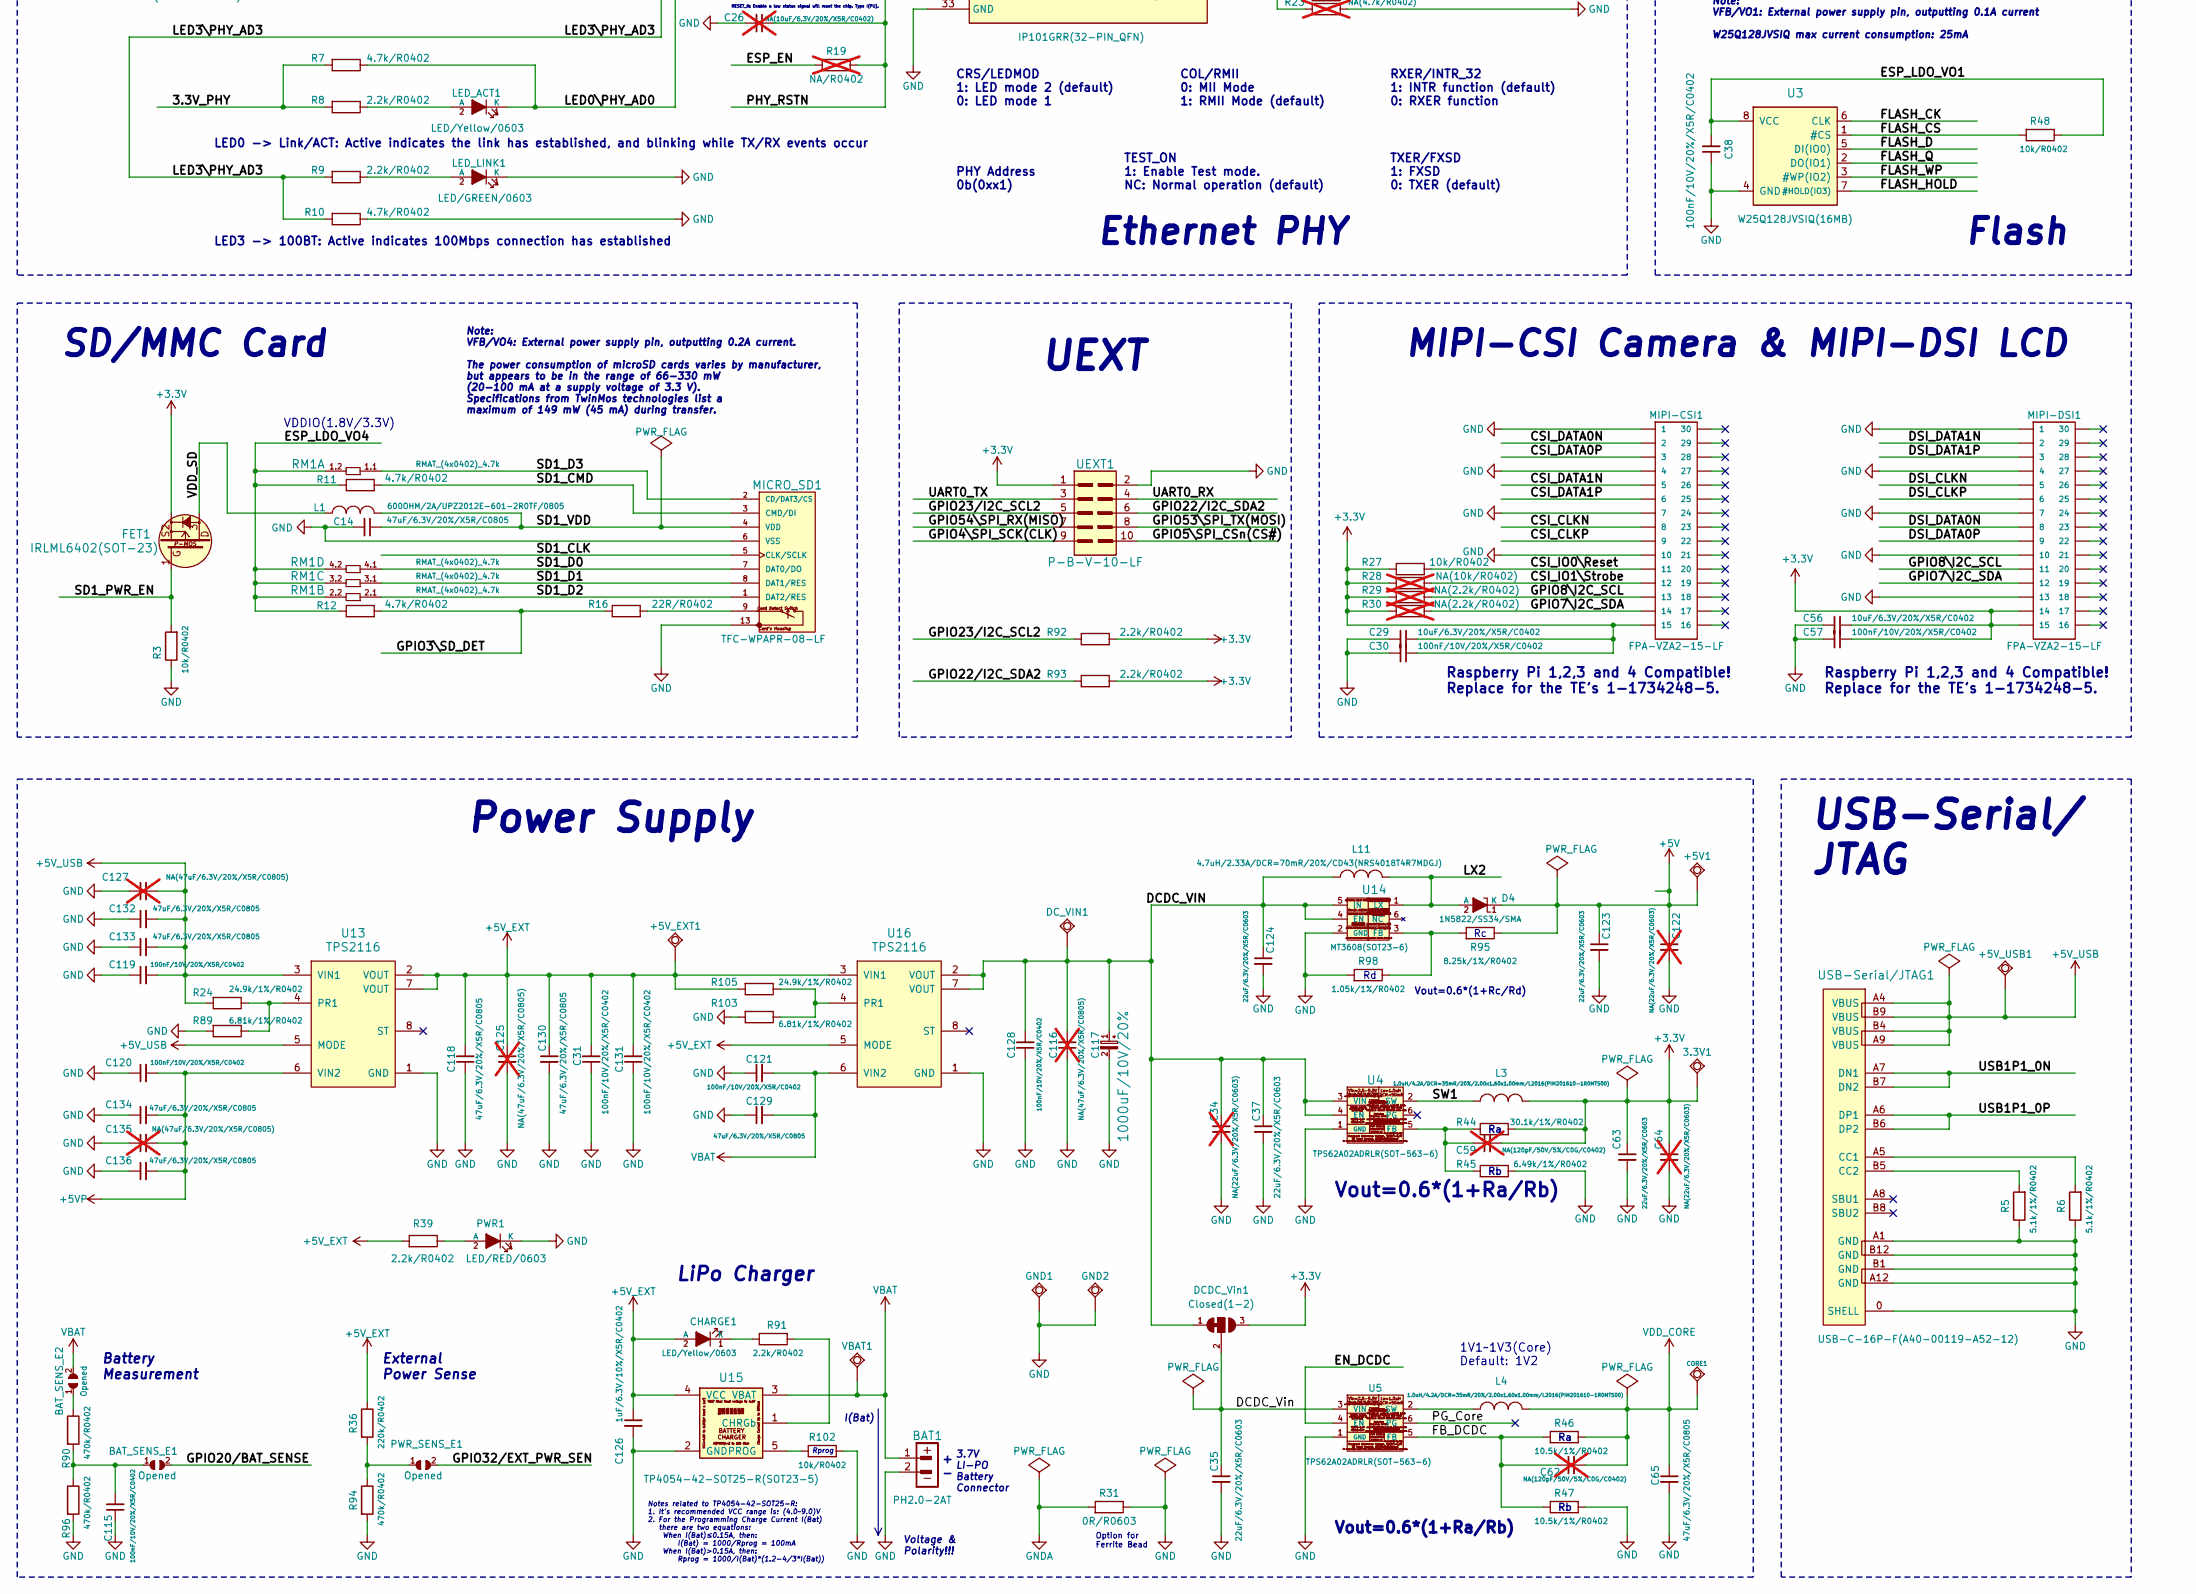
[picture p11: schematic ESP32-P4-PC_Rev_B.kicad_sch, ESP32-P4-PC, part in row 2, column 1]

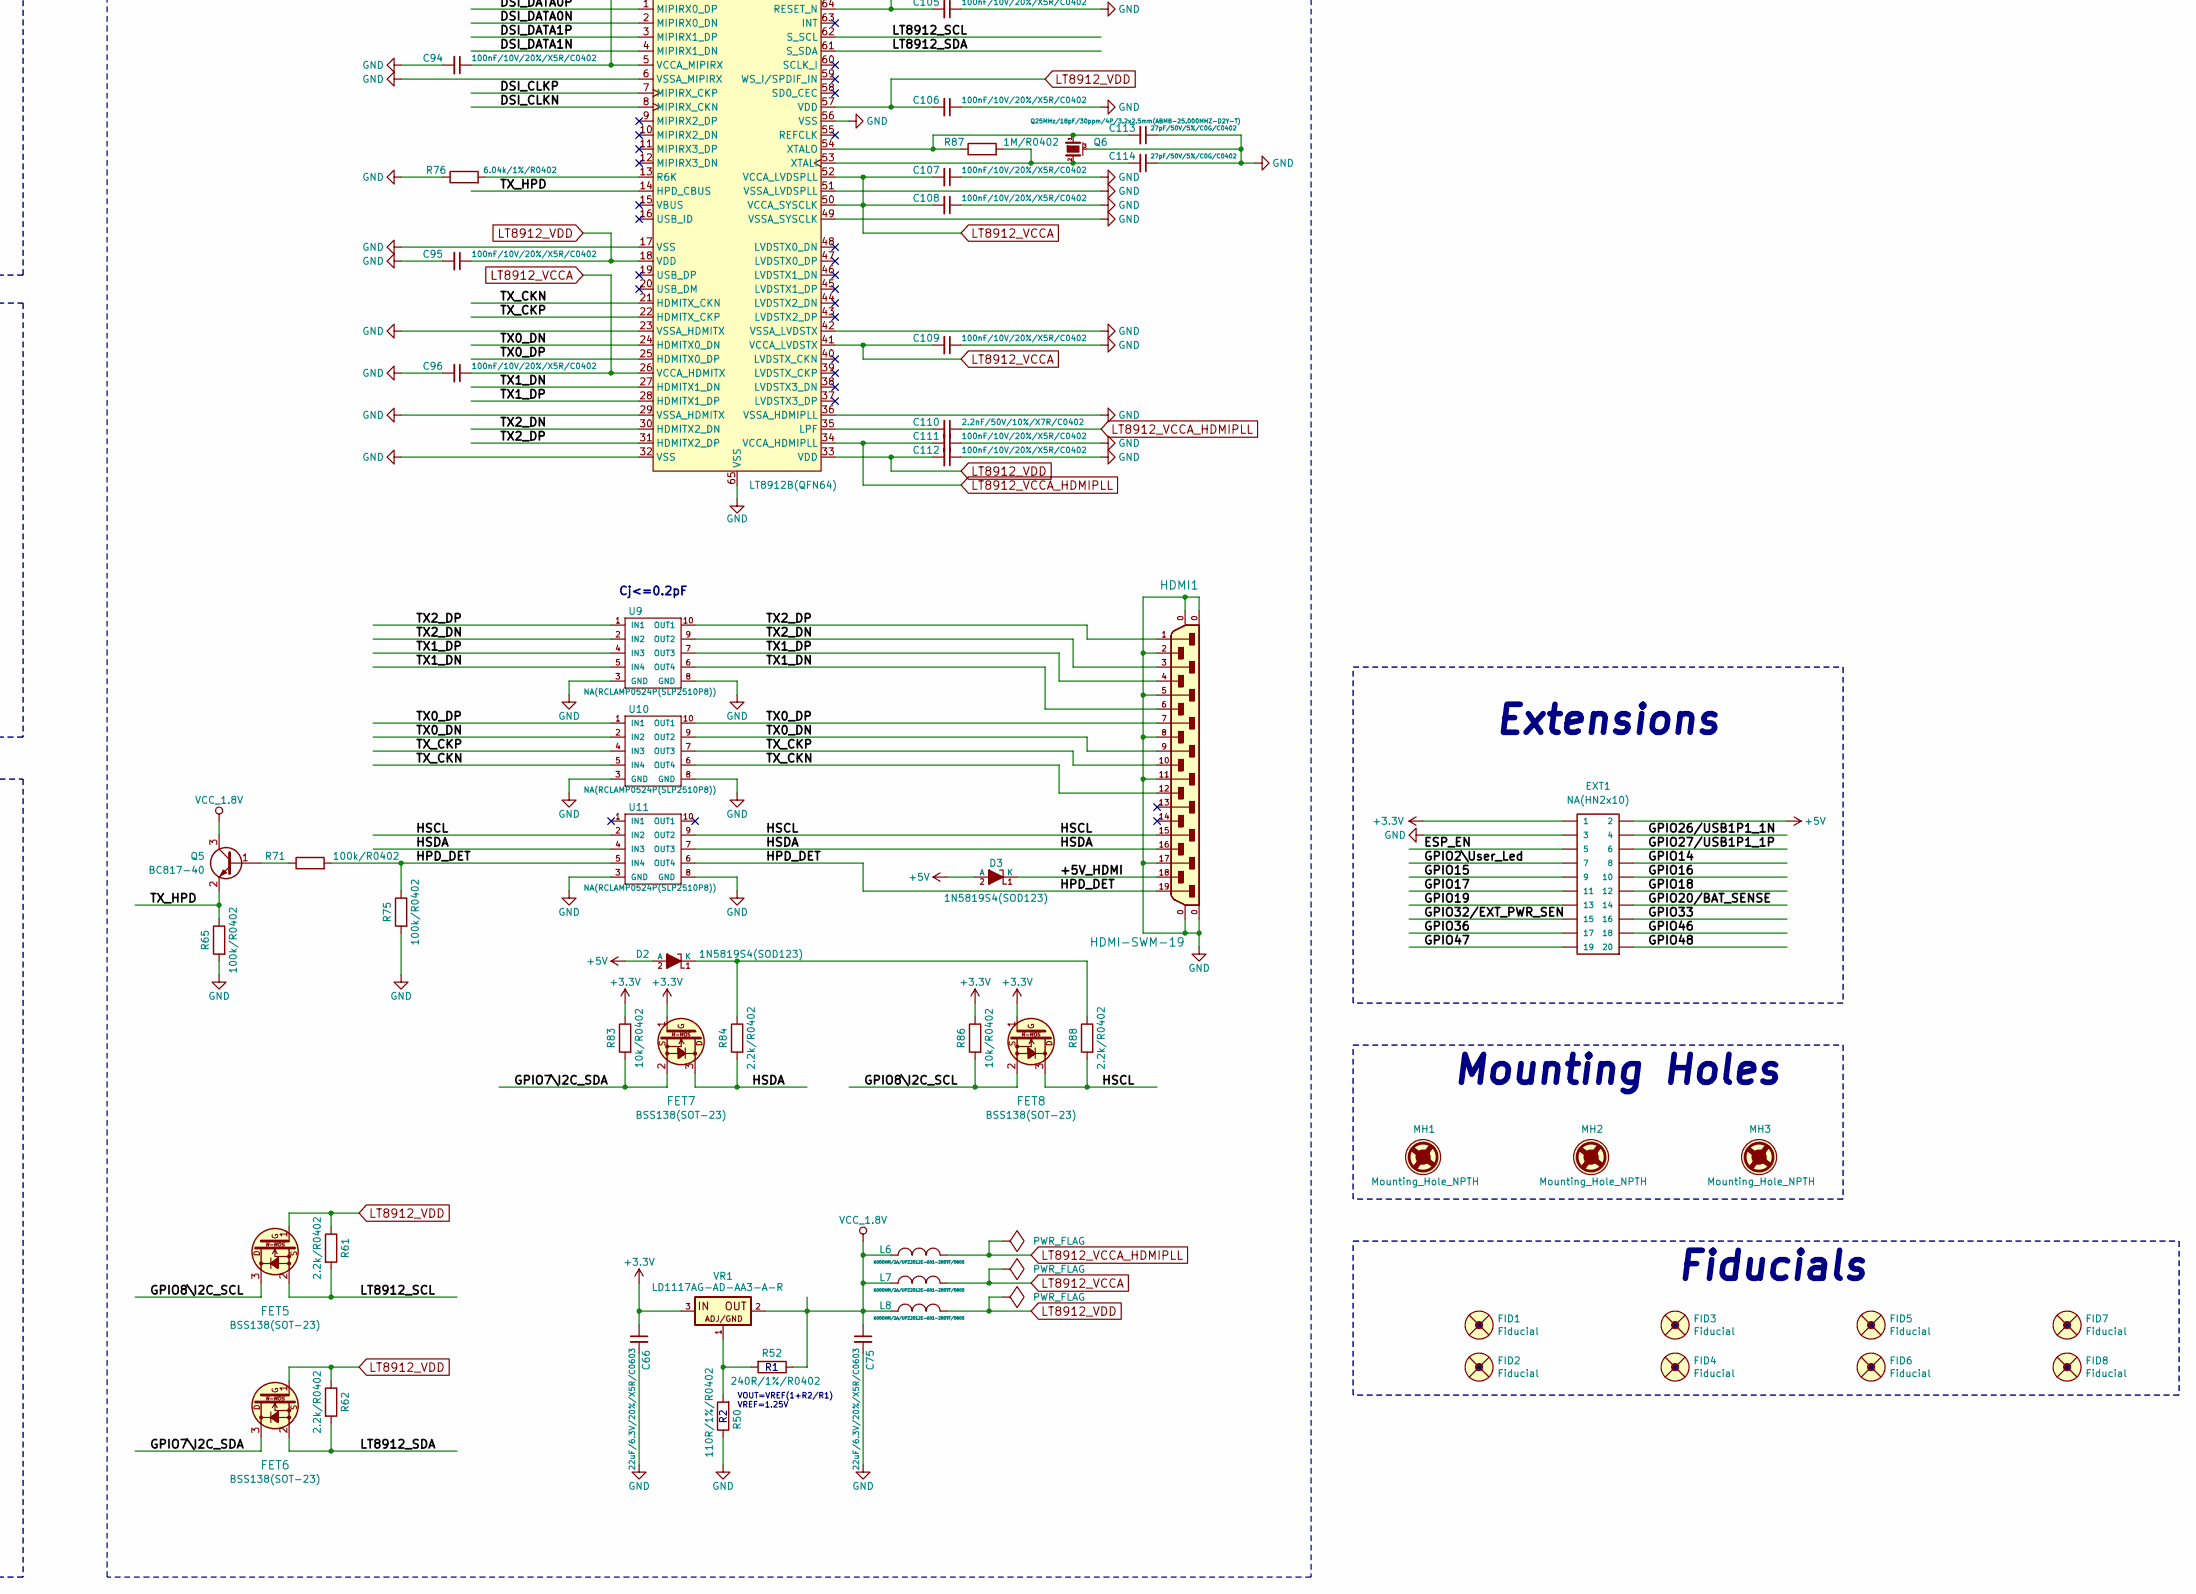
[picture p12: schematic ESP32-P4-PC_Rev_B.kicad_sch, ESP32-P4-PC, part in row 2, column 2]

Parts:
3.3V1: TESTPAD; TESTPAD_40-ROUND
+5V1, +5V_EXT1, +5V_POE1, +5V_USB1: TESTPAD; TESTPAD_40-ROUND
ACT/SUS1: LED/RED/0603; LED_0603_KA
BAT1: PH2.0-2AT; PH2.0-2AT(BAT)
BAT_SENS_E1, BAT_SENS_E2: Opened; SJ_1_SMALLER
BOOT1: YTS-A016-X
C1, C2, C44, C45: 22pF/50V/5%/C0G/C0402; C_0402_5MIL_DWS
C3, C6, C18, C20, C22, C29, C41, C50, C56, C67, C68, C70, C76, C82, C99: 10uF/6.3V/20%/X5R/C0402; C_0402_5MIL_DWS
C4, C5, C7, C9, C11, C12, C19, C21, C23, C30, C31, C32, C38, C40, C42, C43, C46, C47, C49, C51, C52, C53, C54, C57, C69, C71, C85, C87, C91, C94, C95, C96, C101, C105, C106, C107, C108, C109, C111, C112, C115, C119, C120, C121, C128, C131: 100nF/10V/20%/X5R/C0402; C_0402_5MIL_DWS
C8, C10, C36, C39, C48, C55, C58, C61, C84, C86, C88, C97, C98, C100, C104, C126: 1uF/6.3V/10%/X5R/C0402; C_0402_5MIL_DWS
C13: 4.7uF/X5R/20%/10V/C0402; C_0402_5MIL_DWS
C14, C65, C74, C92, C93, C118, C129, C130, C132, C133, C134, C136: 47uF/6.3V/20%/X5R/C0805; C_0805_5MIL_DWS
C15, C16: 100nF/50V/20%/Y5V/C0603; C_0603_5MIL_DWS
C17: 1nF/2000V/10%/X7R/C1206; C_1206_5MIL_DWS_ISO
C24, C25, C79, C80, C81, C113, C114: 27pF/50V/5%/C0G/C0402; C_0402_5MIL_DWS
C26, C83: NA(10uF/6.3V/20%/X5R/C0402); C_0402_5MIL_DWS; not fitted
C27, C28: 150pF/50V/2%/NP0/C0402; C_0402_5MIL_DWS
C33: NA(100nF/10V/20%/X5R/C0402); C_0402_5MIL_DWS; not fitted
C34, C64, C122: NA(22uF/6.3V/20%/X5R/C0603); C_0603_5MIL_DWS; not fitted
C35, C37, C63, C66, C75, C102, C103, C123, C124: 22uF/6.3V/20%/X5R/C0603; C_0603_5MIL_DWS
C59, C62: NA(120pF/50V/5%/C0G/C0402); C_0402_5MIL_DWS; not fitted
C60: NA(100nF/10V/20%/X5R/C0402); C_0402_5MIL_DWS
C72, C73: NA(27pF/50V/5%/C0G/C0402); C_0402_5MIL_DWS; not fitted
C77, C78: 20pF/50V/5%/NP0/C0402; C_0402_5MIL_DWS
C89, C90, C116, C125, C127, C135: NA(47uF/6.3V/20%/X5R/C0805); C_0805_5MIL_DWS; not fitted
C110: 2.2nF/50V/10%/X7R/C0402; C_0402_5MIL_DWS
C117: 1000uF/10V/20%; CPOL-RM3.5mm_8.0x11.5mm_PTH
CHARGE1: LED/Yellow/0603; LED_0603_KA
CORE1: TESTPAD; TESTPAD_40-ROUND
D2, D3: 1N5819S4(SOD123); SOD-123_1C-2A_KA
D4: 1N5822/SS34/SMA; SMA-KA
DCDC_Vin1: Closed(1-2); SJ_2_SMALL_12_TIED
DC_VIN1: TESTPAD; TESTPAD_40-ROUND
EXT1: NA(HN2x10); HN2x10
FET1: IRLML6402(SOT-23); SOT23
FET3, FET4, FET5, FET6, FET7, FET8: BSS138(SOT-23); SOT23
FID1, FID3, FID5, FID7: Fiducial; Fiducial1x3
FID2, FID4, FID6, FID8: Fiducial; Fiducial1x3_Paste
GND1, GND2: TESTPAD; TESTPAD_40-ROUND
HDMI1: HDMI-SWM-19; HDMI-SWM-19_Paste
HEADSETS1: PJ-320D
L1, L2, L5, L6, L7, L8: 600OHM/2A/UPZ2012E-601-2R0TF/0805; L_0805_5MIL_DWS
L3, L4: 1.0uH/4.2A/DCR=35mR/20%/2.00x1.60x1.00mm/L2016(PI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; L_2016_MM
L9: NA(600OHM/2A/UPZ2012E-601-2R0TF/0805); L_0805_5MIL_DWS; not fitted
L11: 4.7uH/2.33A/DCR=70mR/20%/CD43(NRS4018T4R7MDGJ); CD42(43)
LAN1: RJP-003TC1(LPJ4112CNL)
LED_ACT1: LED/Yellow/0603; LED_0603_KA
LED_HOST1, LED_HOST2, LED_HOST3, LED_HOST4: LED/GREEN/0603; LED_0603_KA
LED_LINK1: LED/GREEN/0603; LED_0603_KA
MH1, MH2, MH3: Mounting_Hole_NPTH; Mounting_Hole_Drill-3.3mm_Clerance-7mm
MICRO_SD1: TFC-WPAPR-08-LF; TFC-WPAPR-08
MIPI-CSI1: FPA-VZA2-15-LF; TE_1-1734248-5
MIPI-DSI1: FPA-VZA2-15-LF; TE_1-1734248-5
POE_PWR1: PH2.0-4AT; PH2.0-4PLB
PWR1: LED/RED/0603; LED_0603_KA
PWR_SENS_E1: Opened; SJ_1_SMALLER
Q1: Q32.768kHz/12.5pF/2P/SMD1206; CM7V-T1A(Crystal_Package-1206_3.20x1.50x0.65mm)
Q2, Q6: Q25MHz/18pF/30ppm/4P/3.2x2.5mm(ABM8-25.000MHZ-D2Y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; TSX-3.2x2.5mm_GND(3)
Q3: Q40.000MHz/12pF/10ppm/4P/3.2x2.5x0.70mm(Harmony_E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; TSX-3.2x2.5mm_GND(3)
Q4: Q12MHz/18pF/30ppm/4P/3.2x2.5mm(ABM8-12.000MHZ-D2Y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; TSX-3.2x2.5mm_GND(3)
Q5: BC817-40; SOT23
R1, R2: 4.02k/1%/R0402; R_0402_5MIL_DWS
R3, R27, R41, R42, R43, R48, R54, R55, R64, R66, R67, R68, R70, R83, R85, R86, R102: 10k/R0402; R_0402_5MIL_DWS
R4, R8, R9, R39, R56, R57, R61, R62, R72, R73, R74, R80, R82, R84, R88, R91, R92, R93: 2.2k/R0402; R_0402_5MIL_DWS
R5, R6: 5.1k/1%/R0402; R_0402_5MIL_DWS
R7, R10, R11, R12, R21, R22, R33, R37, R49, R69: 4.7k/R0402; R_0402_5MIL_DWS
R13: 10M/R0402; R_0402_5MIL_DWS
R14, R15, R16, R25, R26, R38: 22R/R0402; R_0402_5MIL_DWS
R17: 6.19k/1%/R0402; R_0402_5MIL_DWS
R18, R28: NA(10k/R0402); R_0402_5MIL_DWS; not fitted
R19, R32, R63: NA/R0402; R_0402_5MIL_DWS; not fitted
R20: NA(10M/R0402); R_0402_5MIL_DWS; not fitted
R23: NA(4.7k/R0402); R_0402_5MIL_DWS; not fitted
R24, R105: 24.9k/1%/R0402; R_0402_5MIL_DWS
R29, R30: NA(2.2k/R0402); R_0402_5MIL_DWS; not fitted
R31: 0R/R0603; R_0603_5MIL_DWS
R34, R35: 1.5k/R0402; R_0402_5MIL_DWS
R36: 220k/R0402; R_0402_5MIL_DWS
R40: NA(0R/R0402); R_0402_5MIL_DWS; not fitted
R44: 30.1k/1%/R0402; R_0402_5MIL_DWS
R45: 6.49k/1%/R0402; R_0402_5MIL_DWS
R46, R47: 10.5k/1%/R0402; R_0402_5MIL_DWS
R50: 110R/1%/R0402; R_0402_5MIL_DWS
R51: 49.9k/1%/R0402; R_0402_5MIL_DWS
R52: 240R/1%/R0402; R_0402_5MIL_DWS
R53: 2.7k/1%/R0402; R_0402_5MIL_DWS
R58, R59, R60: 33R/R0402; R_0402_5MIL_DWS
R65, R71, R75: 100k/R0402; R_0402_5MIL_DWS
R76: 6.04k/1%/R0402; R_0402_5MIL_DWS
R77: 10R/R0402; R_0402_5MIL_DWS
R78: NA(200R/R0402); R_0402_5MIL_DWS
R79: 200R/R0402; R_0402_5MIL_DWS
R81: NA/R0402; R_0402_5MIL_DWS
R87: 1M/R0402; R_0402_5MIL_DWS
R89, R103: 6.81k/1%/R0402; R_0402_5MIL_DWS
R90, R94, R96: 470k/R0402; R_0402_5MIL_DWS
R95: 8.25k/1%/R0402; R_0402_5MIL_DWS
R98: 1.05k/1%/R0402; R_0402_5MIL_DWS
RM1: RMAT_(4x0402)_4.7k; RA0805_(4X0402)_xx_BIGGEROUTPADS
RM2: RA0805_(4X0402)_33R; RA0805_(4X0402)_xx_BIGGEROUTPADS
RST1: YTS-A016-X
TVS1: ESDS314DBVR(SOT-23-5); SOT-23-5
U1: ESP32-P4NRWxx(QFN104); QFN104_10mm×10mm_Pitch_0.35mm
U2: IP101GRR(32-PIN_QFN); QFN32_EP(33)_4.00x4.00x0.80mm_Pitch_0.40mm
U3: W25Q128JVSIQ(16MB); SO-8_208mil
U4, U5: TPS62A02ADRLR(SOT-563-6); SOT-563-6
U6: CH217K(SOT23-6L); SOT23-6
U7: FE1.1s(SSOP-28); SSOP28_10x4mm_Pitch_0.64mm
U8: ES8311(QFN-20); QFN-20_EP(21)_3x3x0.6mm_Pitch_0.4mm
U9, U10, U11: NA(RCLAMP0524P(SLP2510P8)); SLP2510P8_TEST
U12: LT8912B(QFN64); QFN64_7.5x7.5mm_Pitch_0.4mm
U13, U16: TPS2116; SOT-5X3
U14: MT3608(SOT23-6); SOT23-6
U15: TP4054-42-SOT25-R(SOT23-5); SOT-23-5
UEXT1: P-B-V-10-LF; GBH-254-SMT-10
USB-Serial/JTAG1: USB-C-16P-F(A40-00119-A52-12); USB2.0_TYPE-C(A40-00119-A52-12)_Paste
USB_HOST1-2, USB_HOST3-4: USBB1-FRWH-4A(USB-Ax2); USB_TWO_LEVEL
USER_LED1: LED/GREEN/0603; LED_0603_KA
VBAT1: TESTPAD; TESTPAD_40-ROUND
VO1, VO2, VO3, VO4: TESTPAD; TESTPAD_40-ROUND
VR1: LD1117AG-AD-AA3-A-R; SOT223
VR2: AP1231-3.3V(SOT23-5); SOT-23-5

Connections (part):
+1V8: C39.2, C54.2, C55.2, U1.59 (VDDPST), U1.67 (VDDPST), U1.72 (VFB2/VO2), VO2.1 (Pad)
+2.5V: C10.1, C11.1, C58.2, U1.41 (VDD_MIPI_DPHY), U1.73 (VFB3/VO3), VO3.1 (Pad)
+3.3V: 3.3V1.1 (Pad), C3.1, C4.1, C5.2, C12.1, C13.1, C29.1, C30.1, C32.2, C41.2, C42.2, C43.2, C46.2, C50.2, C51.2, C53.2, C56.1, C57.1, C59.2, C63.1, C64.1, C66.1, DCDC_Vin1.3, EXT1.1, FET1.2, FET7.1 (G), FET8.1 (G), L2.1, L3.2, L9.1, MIPI-CSI1.15, MIPI-DSI1.14, MIPI-DSI1.15, R4.1, R27.1, R28.1, R29.1, R30.1, R33.2, R41.1, R42.1, R43.1, R44.2, R49.1, R83.1, R86.1, R92.2, R93.2, U1.9 (VDDPST_1), U1.21 (VDDPST_2), U1.51 (VCCA), U1.62 (VDDPST_4), U1.75 (VDDPST_LDO), U1.77 (VDDPST_DCDC), U1.96 (VDDPST_6), U1.101 (VDDA), U1.102 (VBAT), UEXT1.1, VR1.3 (IN)
+3.3VA: C82.1, FET3.1 (G), FET4.1 (G), L5.1, L9.2, R56.2, R57.2, R63.2, R68.1, R77.1, VR2.5 (VOUT)
+5V: +5V1.1 (Pad), C67.1, C74.1, C76.1, C91.2, C122.1, C123.1, D2.2 (A), D3.2 (A), D4.1 (K), EXT1.2, R69.2, R95.1, U6.6 (VIN), U7.20 (V5), VR2.1 (VIN)
+5VP: +5V_POE1.1 (Pad), C120.2, C134.2, C135.2, C136.2, POE_PWR1.4, U13.6 (VIN2)
+5V_EXT: +5V_EXT1.1 (Pad), C31.2, C118.2, C125.1, C126.1, C130.1, C131.2, CHARGE1.2 (A), R36.1, R39.2, R105.2, U13.2 (VOUT), U13.7 (VOUT), U15.4 (VCC), U16.3 (VIN1), U16.5 (MODE)
+5V_USB: +5V_USB1.1 (Pad), C119.2, C127.2, C132.2, C133.2, R24.2, U13.3 (VIN1), U13.5 (MODE), USB-Serial/JTAG1.A4 (VBUS), USB-Serial/JTAG1.A9 (VBUS), USB-Serial/JTAG1.B4 (VBUS), USB-Serial/JTAG1.B9 (VBUS)
/3.3V_PHY: C20.1, C21.1, C22.1, C23.1, L2.2, R7.2, R8.2, R18.1, R21.1, R22.1, R34.1, R35.1, R37.1, U2.13 (VDD_IO), U2.31 (AVDD33)
/50MHz_CLKO: R38.2, U2.14 (RXCLK/50M_CLKO)
/+5V_HDMI: D3.1 (K), HDMI1.18
/+5V_USB_HOST: C89.2, C90.2, C92.2, C93.2, U6.1 (VOUT), USB_HOST1-2.1.1, USB_HOST1-2.2.1, USB_HOST3-4.1.1, USB_HOST3-4.2.1
/ADCVREF: C86.1, R79.2, U8.15 (ADCVREF)
/CSI_CLKN: MIPI-CSI1.8, U1.45 (CSI_CLKN)
/CSI_CLKP: MIPI-CSI1.9, U1.44 (CSI_CLKP)
/CSI_DATA0N: MIPI-CSI1.2, U1.42 (CSI_DATAN0)
/CSI_DATA0P: MIPI-CSI1.3, U1.43 (CSI_DATAP0)
/CSI_DATA1N: MIPI-CSI1.5, U1.46 (CSI_DATAN1)
/CSI_DATA1P: MIPI-CSI1.6, U1.47 (CSI_DATAP1)
/CSI_IO0\Reset: MIPI-CSI1.11, R27.2
/CSI_IO1\Strobe: MIPI-CSI1.12, R28.2
/DCDC_VIN: C34.1, C37.1, C116.2, C117.1 (+), C124.1, C128.2, DCDC_Vin1.1, DC_VIN1.1 (Pad), L11.2, U4.3 (VIN), U4.4 (EN), U14.4 (EN), U14.5 (IN), U16.2 (VOUT), U16.7 (VOUT)
/DCDC_Vin: C35.1, DCDC_Vin1.2, U5.3 (VIN)
/DSI_CLKN: MIPI-DSI1.5, U1.37 (DSI_CLKN), U12.8 (MIPIRX_CKN)
/DSI_CLKP: MIPI-DSI1.6, U1.38 (DSI_CLKP), U12.7 (MIPIRX_CKP)
/DSI_DATA0N: MIPI-DSI1.8, U1.40 (DSI_DATAN0), U12.2 (MIPIRX0_DN)
/DSI_DATA0P: MIPI-DSI1.9, U1.39 (DSI_DATAP0), U12.1 (MIPIRX0_DP)
/DSI_DATA1N: MIPI-DSI1.2, U1.36 (DSI_DATAN1), U12.4 (MIPIRX1_DN)
/DSI_DATA1P: MIPI-DSI1.3, U1.35 (DSI_DATAP1), U12.3 (MIPIRX1_DP)
/EN_DCDC: U1.79 (EN_DCDC), U5.4 (EN)
/ESP_EN: C40.2, EXT1.5, R19.1, R41.2, RST1.1, U1.103 (CHIP_PU)
/ESP_LDO_VO1: C8.2, C9.2, C36.1, C38.2, R48.1, U1.30 (VDDPST_3), U1.71 (VFB1/VO1), U3.8 (VCC), VO1.1 (Pad)
/ESP_LDO_VO4: C48.1, C49.1, C61.2, R11.1, R12.1, RM1.1.2, RM1.2.2, RM1.3.2, RM1.4.2, U1.74 (VFB4/VO4), U1.85 (VDDPST_5), VO4.1 (Pad)
/FB_DCDC: C62.1, R46.1, R47.1, U1.78 (FB_DCDC), U5.5 (FB)
/FLASH_CK: U1.32 (FLASH_CK), U3.6 (CLK)
/FLASH_CS: R48.2, U1.27 (FLASH_CS), U3.1 (#CS)
/FLASH_D: U1.33 (FLASH_D), U3.5 (DI(IO0))
/FLASH_HOLD: U1.31 (FLASH_HOLD), U3.7 (#HOLD(IO3))
/FLASH_Q: U1.28 (FLASH_Q), U3.2 (DO(IO1))
/FLASH_WP: U1.29 (FLASH_WP), U3.3 (#WP(IO2))
/GPIO2\User_Led: EXT1.7, U1.2 (GPIO2/TOUCH_0/MTCK), USER_LED1.1 (K)
/GPIO3\SD_DET: R12.2, R16.1, U1.3 (GPIO3/TOUCH_1/MTDI)
/GPIO4\SPI_SCK(CLK): U1.4 (GPIO4/TOUCH_2/MTMS), UEXT1.9
/GPIO5\SPI_CSn(CS#): U1.5 (GPIO5/TOUCH_3/MTDO), UEXT1.10
/GPIO6\CODEC_PWR_DIS#: R49.2, U1.6 (GPIO6/TOUCH_4/GPSPI_SPI2_HOLD), VR2.3 (CE)
/GPIO7\I2C_SDA: FET3.3 (D), FET6.3 (D), FET7.2 (S), MIPI-CSI1.14, MIPI-DSI1.12, R30.2, R83.2, U1.7 (GPIO7/TOUCH_5/GPSPI_SPI2_CS)
/GPIO8\I2C_SCL: FET4.3 (D), FET5.3 (D), FET8.2 (S), MIPI-CSI1.13, MIPI-DSI1.11, R29.2, R86.2, U1.8 (GPIO8/TOUCH_6/GPSPI_SPI2_D/UART0_RTS)
/GPIO9\I2S_DSDIN: RM2.4.1, U1.10 (GPIO9/TOUCH_7/GPSPI_SPI2_CK/UART0_CTS)
/GPIO10\I2S_LRCK: RM2.3.1, U1.11 (GPIO10/TOUCH_8/GPSPI_SPI2_Q/UART1_TXD)
/GPIO11\I2S_ASDOUT: RM2.2.1, U1.12 (GPIO11/TOUCH_9/GPSPI_SPI2_WP/UART1_RTD)
/GPIO12\I2S_SCLK: RM2.1.1, U1.13 (GPIO12/TOUCH_10/UART1_RTS)
/GPIO13\I2S_MCLK: R60.2, U1.14 (GPIO13/TOUCH_11/UART0_CTS)
/GPIO14: EXT1.8, U1.15 (GPIO14/TOUCH_12/LP_UART_TXD)
/GPIO15: EXT1.9, U1.16 (GPIO15/TOUCH_13/LP_UART_RXD)
/GPIO16: EXT1.10, U1.17 (GPIO16/ADC0)
/GPIO17: EXT1.11, U1.18 (GPIO17/ADC1)
/GPIO18: EXT1.12, U1.19 (GPIO18/ADC2)
/GPIO19: EXT1.13, U1.20 (GPIO19/ADC3)
/GPIO20/BAT_SENSE: BAT_SENS_E1.2, EXT1.14, U1.22 (GPIO20/ADC4)
/GPIO21/HUB_RST#: R54.2, U1.23 (GPIO21/ADC5), U7.17 (XRSTJ)
/GPIO22/I2C_SDA2: R93.1, U1.24 (GPIO22/ADC6/DBG_PSRAM_CK), UEXT1.6
/GPIO23/I2C_SCL2: R92.1, U1.25 (GPIO23/ADC7/50MHz_ref_clk_out/DBG_PSRAM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), UEXT1.5
/GPIO26/USB1P1_1N: EXT1.4, U1.55 (GPIO26/USB1P1_N1)
/GPIO27/USB1P1_1P: EXT1.6, U1.56 (GPIO27/USB1P1_P1)
/GPIO32/EXT_PWR_SEN: EXT1.15, PWR_SENS_E1.2, U1.63 (GPIO32/I3CMST_SCL/GPSPI_SPI2_HOLD/EMAC_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)
/GPIO33: EXT1.16, U1.64 (GPIO33/I3CMST_SDA/GPSPI_SPI2_WP/EMAC_PH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)
/GPIO34\RMII_TXD0: U1.65 (GPIO34/GPSPI_SPI2_IO4/EMAC_PHY_TXD0/DBG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), U2.9 (TXD0)
/GPIO35\RMII_TXD1: BOOT1.1, C60.1, R43.2, U1.66 (GPIO35/GPSPI_SPI2_IO5/EMAC_PHY_TXD1/DBG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), U2.8 (TXD1)
/GPIO36: EXT1.17, R42.2, U1.68 (GPIO36/GPSPI_SPI2_IO6/EMAC_PHY_TXER/DBG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)
/GPIO46: EXT1.18, U1.88 (GPIO46/SD1_DATA5/EMAC_PHY_RXD0/DBG_PSRA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)
/GPIO47: EXT1.19, U1.89 (GPIO47/SD1_DATA6/EMAC_PHY_RXD1/DBG_PSRA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)
/GPIO48: EXT1.20, U1.90 (GPIO48/SD1_DATA7/EMAC_PHY_RXER)
/GPIO53\SPI_TX(MOSI): U1.97 (GPIO53/ADC12/EMAC_PHY_RXD1/DBG_FLASH_CK), UEXT1.8
/GPIO54\SPI_RX(MISO): U1.98 (GPIO54/ADC13/EMAC_PHY_RXER/DBG_FLASH_D), UEXT1.7
/HP-L: C103.1, HEADSETS1.4
/HP-R: C102.1, HEADSETS1.3
/HPD_DET: HDMI1.19, R71.2, R75.1, U11.5 (IN4), U11.6 (OUT4)
/HSCL: FET8.3 (D), HDMI1.15, R88.2, U11.2 (IN2), U11.9 (OUT2)
/HSDA: FET7.3 (D), HDMI1.16, R84.2, U11.4 (IN3), U11.7 (OUT3)
/HUB_DRV: LED_HOST1.2 (A), LED_HOST2.2 (A), LED_HOST3.1 (K), LED_HOST4.1 (K), R74.1, U7.22 (DRV)
/HUB_LED1: R72.1, U7.23 (LED1/SCL)
/HUB_LED2: R73.1, U7.24 (LED2)
/LAN_Shield: C17.2, LAN1.0 (Shield)
/LED0\PHY_AD0: LED_ACT1.1 (K), R7.1, U2.11 (LED0/PHY_AD0)
/LED3\PHY_AD3: R9.2, R10.2, U2.12 (LED3/PHY_AD3)
/LT8912_SCL: FET5.2 (S), R61.2, U12.62 (S_SCL)
/LT8912_SDA: FET6.2 (S), R62.2, U12.61 (S_SDA)
/LX2: D4.2 (A), L11.1, U14.1 (LX)
/MDC: R34.2, U1.61 (GPIO31/GPSPI_SPI2_Q/EMAC_PHY_RXER/DBG_P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), U2.22 (MDC)
/MDIO: R35.2, U1.95 (GPIO52/ADC11/EMAC_PHY_RXD0/DBG_FLASH_HO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), U2.23 (MDIO)
/MICN: C97.1, R80.2, R81.2
/MICP: C98.1, HEADSETS1.1, R82.2
/OVCUR#: R67.1, U6.3 (FLAG#), U7.26 (OVCJ)
/PG_Core: U5.6 (PG)
/PHY_RSTN: C26.1, R18.2, R19.2, U1.94 (GPIO51/ADC10/EMAC_PHY_RXDV/DBG_FLASH_WP), U2.32 (RESET_N)
/PW+: LAN1.9 (PW+), POE_PWR1.2
/PW-: LAN1.10 (PW-), POE_PWR1.1
/PWREN#: R66.1, U6.4 (EN#), U7.25 (PWRJ)
/RD+: LAN1.3 (RD+), TVS1.5 (I/O4), U2.27 (MDI_RP)
/RD-: LAN1.6 (RD-), TVS1.1 (I/O1), U2.26 (MDI_RN)
/RMII_CLK: R38.1, U1.93 (GPIO50/ADC9/EMAC_RMII_CLK/DBG_FLASH_Q), U2.10 (TXCLK/50M_CLKI)
/RMII_RXD0: U1.58 (GPIO29/GPSPI_SPI2_D/EMAC_PHY_RXD0/DBG_P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), U2.18 (RXD0)
/RMII_RXD1: U1.60 (GPIO30/GPSPI_SPI2_CK/EMAC_PHY_RXD1/DBG_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), U2.17 (RXD1)
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

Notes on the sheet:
One LDO is recommended to provide power supply to ES8311 because ES8311 is an analog device which will be sensitive to noise.
Cj<=0.2pF
XRSTJ - External Reset For normal applications, it should be pull-up to 3.3V.
Note: VFB/VO1: External power supply pin, outputting 0.1A current W25Q128JVSIQ max current consumption: 25mA
TXER/FXSD Transmit Error or FXSD. Type I(PD).
USB-to-serial converter and USB-to-JTAG (The pin functions of USB_DN and USB_DP are interchangeable. GPIO24/25 and GPIO26/27 are the D+ and D- pins of two USB PHY. USB Serial/JTAG can use any one of them, and the default one is GPIO24/25)
Power Supply
Ilim=1.20A
The termal pad must be connected to audio ground.
Vout=0.6*(1+Ra/Rb)
Two pull up resistors are recommended to I2C bus. R-C low pass filter is strongly recommended to I2C bus. The I2C route must be shielded by ground.
I2S/PCM digital serial audio port with Master or Slave mode.
The two FETs prevent powering the Codec when its power supply is disabled.
Note 4: This capacitors should be located as close to ES8311 package as possible.
REXT - External Bias Resistor. A 2.7KΩ (± 1%) resistor should be connected to VSS to provide internal bias reference.
See: Note 1
Boot Strapping Pins
Mounting Holes
LED0 -> Link/ACT: Active indicates the link has established, and blinking while TX/RX events occur
Over Current Indicator (Input, 5V-Tolerant), active low, for Global Over-Current Protection. VIL=-0.3~0.8V, VIH=2.0~5.5V
RXER/INTR_32 1: INTR function (default) 0: RXER function
COL/RMII 0: MII Mode 1: RMII Mode (default)
This pin TXER must be either floating or connecting to GND in RMII mode.
The transfer rate of I2C can be up to 400 kbps
RXDV/CRS_DV/FX_HEN: Receive Data Valid or Media Type Selection. Type I(PD). In RMII mode, this pin indicates the Carrier Sense and Receive Data Valid function.
TXER/FXSD 1: FXSD 0: TXER (default)
3.7V LI-PO Battery Connector
FE1.1s is USB 2.0 HIGH SPEED 4-PORT HUB CONTROLLER
TEST_ON 1: Enable Test mode. NC: Normal operation (default)
Ethernet PHY
The CH217K's FLAG# pin can generate an over-current or over-temperature alarm signal to notify the HUB controller and the computer, and the CH334/5 has built-in pull-up resistors.
LiPo Charger
See: Note 4
Test Mode Enable (I/O), active low with internal pull-up, and external Serial EEPROM Data/Address.
Test Enable: Set this pin to high to enable Test mode. Type I(PD).
High-performance MCU with RISC-V single-core and dual-core microprocessors Powerful image and voice processing capability 16 MB or 32 MB PSRAM in the chip's package 55 GPIOs, rich set of peripherals QFN104 (10×10 mm) Package
USB 2.0 OTG high-speed interface (DM/DP)
AUDIO
If a 50MHz clock is applied to pin10 TXCLK/50M_CLKI, X1 must be connected to GND.
1V8/3V3(Flash)

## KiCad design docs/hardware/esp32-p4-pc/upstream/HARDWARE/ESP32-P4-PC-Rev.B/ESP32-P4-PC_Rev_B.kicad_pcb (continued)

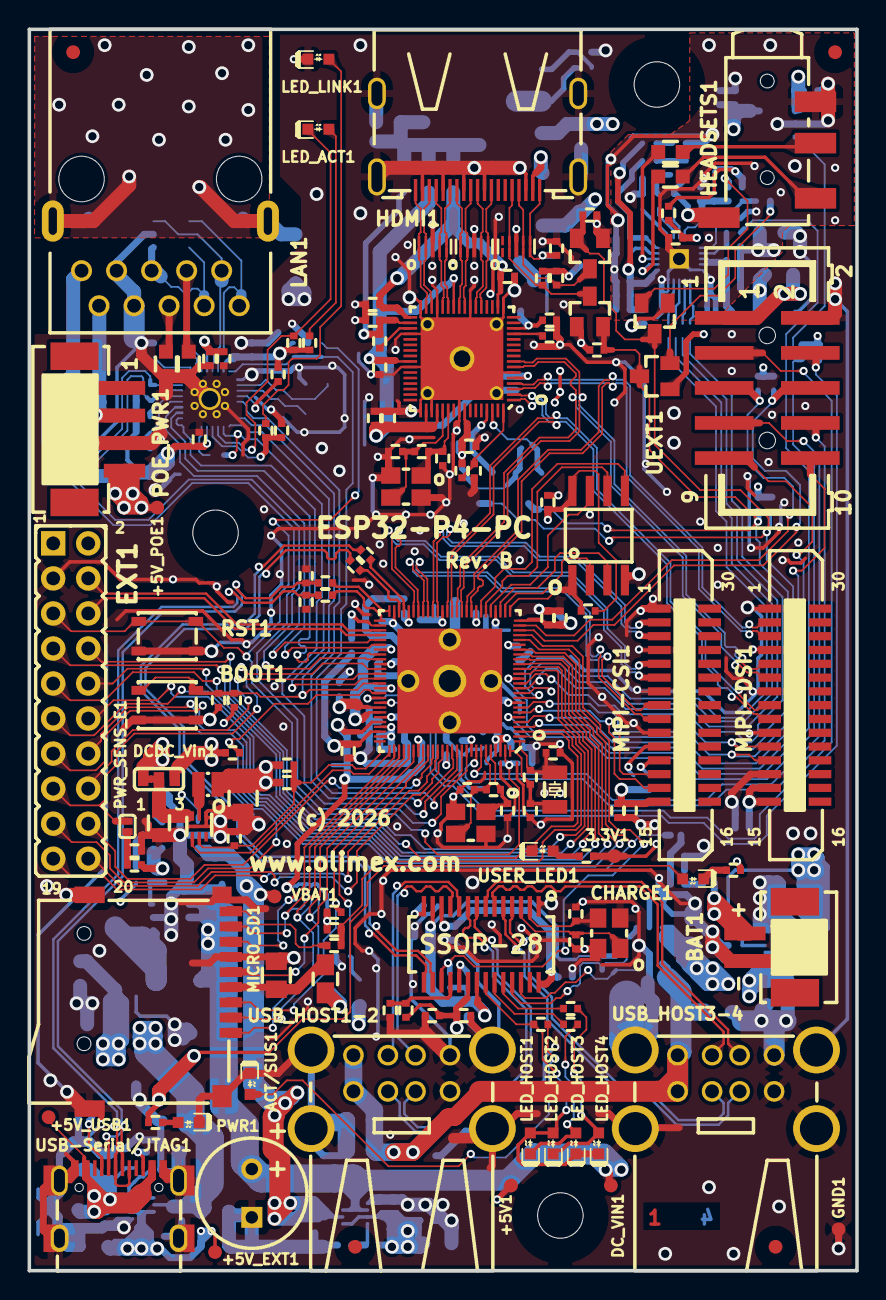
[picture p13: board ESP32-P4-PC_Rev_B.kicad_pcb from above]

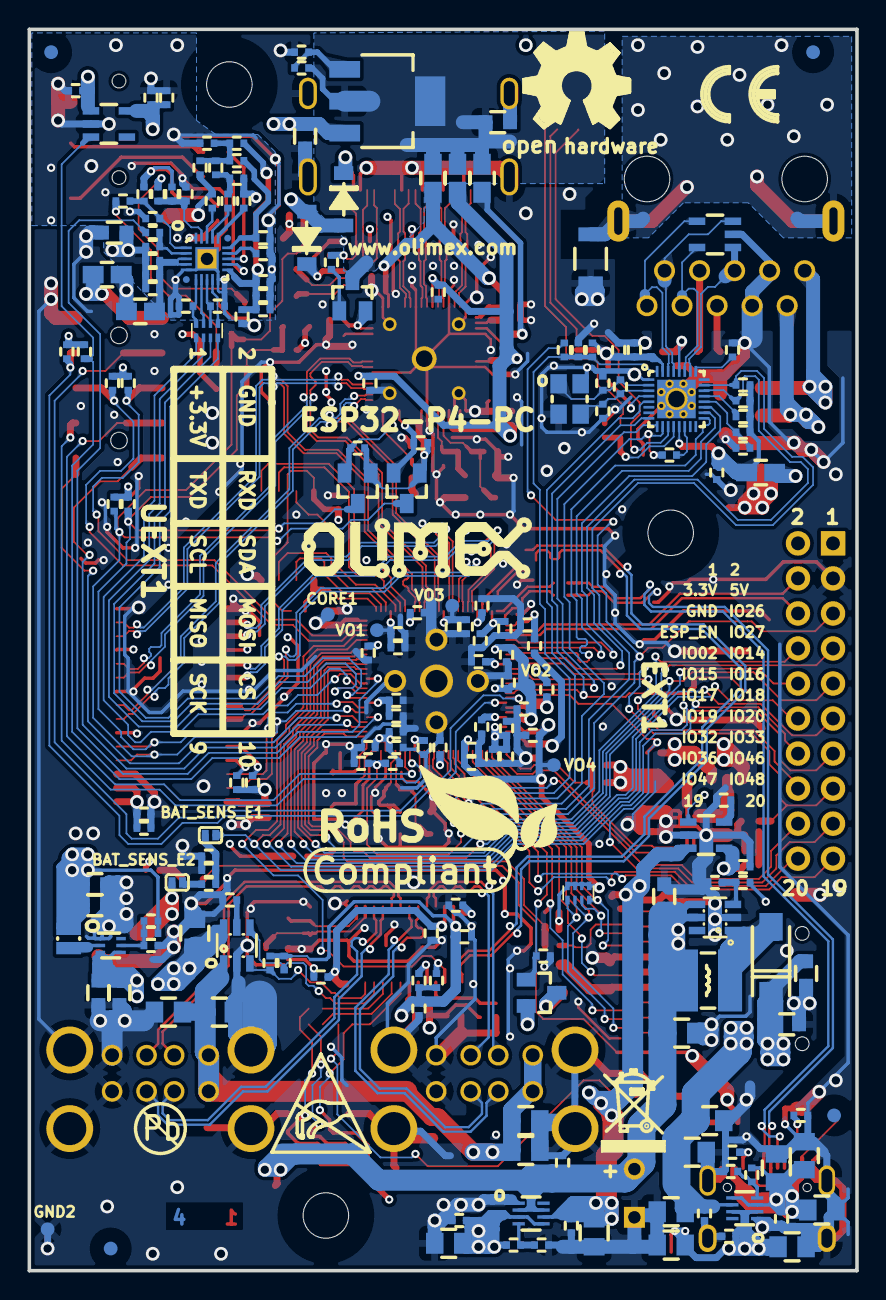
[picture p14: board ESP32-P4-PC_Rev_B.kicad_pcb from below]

Board: 4 copper layers, 60.0 x 90.0 mm, 344 parts (204 on the bottom side), 223 nets.

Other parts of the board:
Logo_OLIMEX_TB: Logo_OLIMEX_TB
Sign_Antistatic: Sign_Antistatic
Sign_CE: CE_Sign
Sign_OSHW_8x8: Sign_OSHW_8x8
Sign_PB-Free: Sign_PB-Free
Sign_RecycleBin_1: Sign_RecycleBin_1
Sign_RoHS_1: Sign_RoHS_1

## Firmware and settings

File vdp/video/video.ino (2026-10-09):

//
// Title:			Agon Video BIOS
// Author:			Dean Belfield
// Contributors:	Jeroen Venema (Sprite Code, VGA Mode Switching)
//					Damien Guard (Fonts)
//					Igor Chaves Cananea (vdp-gl maintenance)
//					Steve Sims (Audio enhancements, refactoring, bug fixes)
// Created:			22/03/2022
// Last Updated:	12/09/2023
//
// Modinfo:
// 11/07/2022:		Baud rate tweaked for Agon Light, HW Flow Control temporarily commented out
// 26/07/2022:		Added VDU 29 support
// 03/08/2022:		Set codepage 1252, fixed keyboard mappings for AGON, added cursorTab, VDP serial protocol
// 06/08/2022:		Added a custom font, fixed UART initialisation, flow control
// 10/08/2022:		Improved keyboard mappings, added sprites, audio, new font
// 05/09/2022:		Moved the audio class to agon_audio.h, added function prototypes in agon.h
// 02/10/2022:		Version 1.00: Tweaked the sprite code, changed bootup title to Quark
// 04/10/2022:		Version 1.01: Can now change keyboard layout, origin and sprites reset on mode change, available modes tweaked
// 23/10/2022:		Version 1.02: Bug fixes, cursor visibility and scrolling
// 15/02/2023:		Version 1.03: Improved mode, colour handling and international support
// 04/03/2023:					+ Added logical screen resolution, sendScreenPixel now sends palette index as well as RGB values
// 09/03/2023:					+ Keyboard now sends virtual key data, improved VDU 19 to handle COLOUR l,p as well as COLOUR l,r,g,b
// 15/03/2023:					+ Added terminal support for CP/M, RTC support for MOS
// 21/03/2023:				RC2 + Added keyboard repeat delay and rate, logical coords now selectable
// 22/03/2023:					+ VDP control codes now indexed from 0x80, added paged mode (VDU 14/VDU 15)
// 23/03/2023:					+ Added VDP_GP
// 26/03/2023:				RC3 + Potential fixes for FabGL being overwhelmed by faster comms
// 27/03/2023:					+ Fix for sprite system crash
// 29/03/2023:					+ Typo in boot screen fixed
// 01/04/2023:					+ Added resetPalette to MODE, timeouts to VDU commands
// 08/04/2023:				RC4 + Removed delay in readbyte_t, fixed VDP_SCRCHAR, VDP_SCRPIXEL
// 12/04/2023:					+ Fixed bug in playNote
// 13/04/2023:					+ Fixed bootup fail with no keyboard
// 17/04/2023:				RC5 + Moved wait_completion in vdu so that it only executes after graphical operations
// 18/04/2023:					+ Minor tweaks to wait completion logic
// 12/05/2023:		Version 1.04: Now uses vdp-gl instead of FabGL, implemented GCOL mode, sendModeInformation now sends video mode
// 19/05/2023:					+ Added VDU 4/5 support
// 25/05/2023:					+ Added VDU 24, VDU 26 and VDU 28, fixed inverted text colour settings
// 30/05/2023:					+ Added VDU 23,16 (cursor movement control)
// 28/06/2023:					+ Improved get_screen_char, fixed vdu_textViewport, cursorHome, changed modeline for Mode 2
// 30/06/2023:					+ Fixed vdu_sys_sprites to correctly discard serial input if bitmap allocation fails
// 13/08/2023:				RC2	+ New video modes, mode change resets page mode
// 05/09/2023:					+ New audio enhancements, improved mode change code
// 12/09/2023:					+ Refactored
// 17/09/2023:					+ Added ZDI mode

#include <HardwareSerial.h>
#ifndef AGON_EXTENDER_P4_BOOT
#include <WiFi.h>
#endif
#ifdef AGON_EXTENDER_P4_BOOT
#include "extender/compat/p4_vdp_gl.hpp"
#else
#include <fabgl.h>
#endif
#include <ESP32Time.h>
#ifdef AGON_EXTENDER_P4_BOOT
#include <esp_log.h>
#include <esp_heap_caps.h>
#if !defined(AGON_EXTENDER_SOURCE_IDENTITY) || \
      !defined(AGON_EXTENDER_BUILD_ID) || \
      !defined(AGON_EXTENDER_ARTIFACT_STATUS)
#error "The P4 boot target requires explicit build-identity definitions"
#endif
#ifdef AGON_EXTENDER_PORT008_NONRELEASE_QUALIFICATION
#ifndef AGON_EXTENDER_QUALIFICATION_COMPOSITION_IDENTITY
#error "The P4 qualification target requires an explicit composition identity"
#endif
#elif defined(AGON_EXTENDER_QUALIFICATION_COMPOSITION_IDENTITY)
#error "Ordinary P4 boot targets must not carry a qualification composition identity"
#endif
#endif

// Serial Debug Mode: 1 = enable
// Always enabled on the emulator, to support --verbose mode
#ifdef USERSPACE
#undef DEBUG
# define	DEBUG			1
#else /* !USERSPACE */
#undef DEBUG
# define	DEBUG			0
#endif /* USERSPACE */

#define SERIALBAUDRATE	115200

#ifdef USERSPACE
extern uint32_t startup_screen_mode; /* in rust_glue.cpp */
#else /* !USERSPACE */
#define startup_screen_mode 0
#endif /* !USERSPACE */

HardwareSerial	DBGSerial(0);

#include "agon.h"								// Configuration file

TerminalState	terminalState = TerminalState::Disabled;		// Terminal state (for CP/M, etc)
bool			consoleMode = false;			// Serial console mode (0 = off, 1 = console enabled)
bool			printerOn = false;				// Output "printer" to debug serial link
bool			controlKeys = true;				// Control keys enabled
ESP32Time		rtc(0);							// The RTC

#include "version.h"							// Version information
#ifdef AGON_EXTENDER_P4_BOOT
#include "extender/input/unavailable_input_adapter.hpp"
#include "extender/port/p4_task_watchdog.hpp"
#else
#include "agon_ps2.h"							// Keyboard support
#include "agon_audio.h"							// Audio support
#endif
#include "agon_screen.h"						// Screen support
#include "agon_ttxt.h"
#ifdef AGON_EXTENDER_P4_BOOT
#include "extender/network/wired_network_service.hpp"
#if defined(AGON_EXTENDER_CONSOLE)
#include "extender/transport/console_stream.hpp"
#include "extender/transport/console_uart_owner.hpp"
#elif defined(AGON_EXTENDER_BROWSER_TYPING)
#include "extender/diagnostic/browser_typing_stream.hpp"
#elif defined(AGON_EXTENDER_KEYBOARD_QUALIFICATION)
#ifdef AGON_EXTENDER_USB_CLI
#include "extender/diagnostic/usb_cli_stream.hpp"
#else
#include "extender/diagnostic/keyboard_probe_stream.hpp"
#endif
#elif defined(AGON_EXTENDER_VISIBLE_TEXT_QUALIFICATION)
#include "extender/diagnostic/visible_text_stream.hpp"
#elif defined(AGON_EXTENDER_GENERAL_POLL_QUALIFICATION)
#include "extender/diagnostic/general_poll_stream.hpp"
#elif defined(AGON_EXTENDER_PORT008_NONRELEASE_QUALIFICATION)
#include "extender/transport/p4_parallel_qualification.hpp"
#elif defined(AGON_EXTENDER_PORT008_FORWARD)
#include "extender/transport/forward_parallel_stream.hpp"
#else
#include "extender/transport/disconnected_stream.hpp"
#endif
#include "extender/web/browser_video_provider.hpp"
#if defined(AGON_EXTENDER_HDMI)
#include "extender/display/hdmi_output.hpp"
#endif
#else
#include "vdp_protocol.h"						// VDP Protocol
#endif
#include "vdu_stream_processor.h"
#ifndef AGON_EXTENDER_P4_BOOT
#include "hexload.h"
#endif

#ifndef AGON_EXTENDER_P4_BOOT
std::unique_ptr<fabgl::Terminal>	Terminal;	// Used for Terminal emulation mode (for CP/M, etc)
#endif
VDUStreamProcessor *	processor;				// VDU Stream Processor

#if !defined(USERSPACE) && !defined(AGON_EXTENDER_P4_BOOT)
#include "zdi.h"								// ZDI debugging console
#endif /* !USERSPACE */

#ifdef AGON_EXTENDER_P4_BOOT
#if defined(AGON_EXTENDER_CONSOLE)
// The ordinary UART composition supplies its Stream in setup.
#elif defined(AGON_EXTENDER_BROWSER_TYPING)
// The typing composition supplies its adopted Stream in setup.
#elif defined(AGON_EXTENDER_KEYBOARD_QUALIFICATION)
// The keyboard composition supplies its adopted Stream in setup.
#elif defined(AGON_EXTENDER_VISIBLE_TEXT_QUALIFICATION)
// The bounded visible-text composition supplies its Stream in setup.
#elif defined(AGON_EXTENDER_GENERAL_POLL_QUALIFICATION)
// The bounded General Poll composition supplies its adopted Stream in setup.
#elif defined(AGON_EXTENDER_PORT008_NONRELEASE_QUALIFICATION)
// The qualification composition owns its production objects and returns the
// one heap Stream that VDUStreamProcessor adopts below.
#elif defined(AGON_EXTENDER_PORT008_FORWARD)
// Rejected predecessor branch.  p4-forward-vdp is blocked by its retired
// source-selection record; retain this binding only to keep old source and
// evidence intelligible.
agon::extender::transport::ForwardParallelStream forwardVDPStream;
#else
agon::extender::transport::DisconnectedStream disconnectedVDPStream;
#endif
std::unique_ptr<agon::extender::web::BrowserVideoProvider>	browserVideoProvider;
std::unique_ptr<agon::extender::network::WiredNetworkService>	wiredNetworkService;
#endif

TaskHandle_t		Core0Task;					// Core 0 task handle

void setup() {
	#ifndef VDP_USE_WDT
		#ifdef AGON_EXTENDER_P4_BOOT
		// Official VDP v2.16.0 disables each classic-ESP32 IDLE watchdog
		// below. Arduino-ESP32 3.3.11 removes those P4 tasks but leaves
		// ESP-IDF 5.5.5's feed hooks active, producing a continuous error
		// flood. Use the hook-aware public ESP-IDF path on P4, retain the
		// original total delay, and fail closed if reconfiguration fails.
		if (!agon::extender::port::disableRetainedVdpIdleWatchdogs()) {
			ESP_LOGE("extender_boot", "retained VDP watchdog setup failed");
			return;
		}
		delay(200); delay(200);
		#else
		disableCore0WDT(); delay(200);				// Disable the watchdog timers
		disableCore1WDT(); delay(200);
		#endif
	#endif
	#ifdef AGON_EXTENDER_P4_BOOT
		// Stock UART0 GPIO 3/1 is inapplicable on the DevKit. ESP-IDF logging is
		// routed to the sdkconfig-selected USB Serial/JTAG console instead.
		#ifdef AGON_EXTENDER_PORT008_NONRELEASE_QUALIFICATION
			ESP_LOGW("extender_identity",
				"NON-RELEASE COMPILE/LINK QUALIFICATION TARGET; DO NOT DEPLOY");
			ESP_LOGW("extender_identity", "qualification_composition=%s",
				AGON_EXTENDER_QUALIFICATION_COMPOSITION_IDENTITY);
			#endif
		ESP_LOGI("extender_identity", "source_identity=%s",
			AGON_EXTENDER_SOURCE_IDENTITY);
		ESP_LOGI("extender_identity", "build_id=%s", AGON_EXTENDER_BUILD_ID);
		ESP_LOGI("extender_identity", "artifact_status=%s",
			AGON_EXTENDER_ARTIFACT_STATUS);
		ESP_LOGI("extender_boot", "retained VDP setup starting");
	#else
		DBGSerial.begin(SERIALBAUDRATE, SERIAL_8N1, 3, 1);
	#endif
	#if defined(AGON_EXTENDER_HDMI)
		// Initialize before the first fallible logical mode preparation, on
		// core 1 shared with the HDMI output worker and DSI/DMA interrupts.
		if (!agon::extender::display::hdmiOutput().start()) {
			ESP_LOGE("extender_boot", "HDMI startup failed; parser not started");
			return;
		}
	#endif
	changeMode(startup_screen_mode);
	copy_font();
	#ifdef AGON_EXTENDER_P4_BOOT
		#if defined(AGON_EXTENDER_CONSOLE)
		processor = new VDUStreamProcessor(beginConsole());
		#elif defined(AGON_EXTENDER_BROWSER_TYPING)
		processor = new VDUStreamProcessor(beginBrowserTyping());
		#elif defined(AGON_EXTENDER_KEYBOARD_QUALIFICATION)
		processor = new VDUStreamProcessor(beginKeyboardQualification());
		#elif defined(AGON_EXTENDER_VISIBLE_TEXT_QUALIFICATION)
		processor = new VDUStreamProcessor(beginVisibleTextQualification());
		#elif defined(AGON_EXTENDER_GENERAL_POLL_QUALIFICATION)
		processor = new VDUStreamProcessor(beginGeneralPollQualification());
		#elif defined(AGON_EXTENDER_PORT008_NONRELEASE_QUALIFICATION)
		auto *qualificationVDPStream =
			agon::extender::transport::
				beginP4ParallelNonreleaseQualification();
		if (qualificationVDPStream == nullptr) {
			ESP_LOGE("extender_boot",
				"non-release production transport composition failed");
			return;
		}
		processor = new VDUStreamProcessor(qualificationVDPStream);
		#elif defined(AGON_EXTENDER_PORT008_FORWARD)
		if (!forwardVDPStream.begin()) {
			ESP_LOGE("extender_boot", "forward transport start failed");
			return;
		}
		processor = new VDUStreamProcessor(&forwardVDPStream);
		#else
		processor = new VDUStreamProcessor(&disconnectedVDPStream);
		#endif
	#else
		setupVDPProtocol();
		processor = new VDUStreamProcessor(&VDPSerial);
	#endif
	auto processTaskResult = xTaskCreatePinnedToCore(
		processLoop,
		"processLoop",
		4096,		// Stack size - highwater mark checks show this generally still leaves about 2000 words free
		NULL,
		3,			// Priority
		&Core0Task,
		#if defined(AGON_EXTENDER_CONSOLE)
		agon::extender::transport::consoleUartOwnerCore
		#else
		0			// Core 0
		#endif
	);
	#ifdef AGON_EXTENDER_P4_BOOT
			if (processTaskResult != pdPASS) {
				ESP_LOGE("extender_boot", "retained process task creation failed");
				#ifdef AGON_EXTENDER_PORT008_NONRELEASE_QUALIFICATION
				agon::extender::transport::
					requestP4ParallelNonreleaseQualificationStop();
				#endif
				return;
			}
	#else
		(void)processTaskResult;
		initAudio();
	#endif
	boot_screen();
	#if defined(AGON_EXTENDER_P4_BOOT) && !defined(AGON_EXTENDER_GENERAL_POLL_QUALIFICATION) && !defined(AGON_EXTENDER_USB_CLI)
		if (_VGAController == nullptr) {
			ESP_LOGE("extender_boot", "browser service has no display controller");
		} else {
			browserVideoProvider.reset(
				new agon::extender::web::BrowserVideoProvider(
					displaySnapshotPool()));
			wiredNetworkService.reset(
				new agon::extender::network::WiredNetworkService(
					*browserVideoProvider));
			if (!wiredNetworkService->start()) {
				ESP_LOGE("extender_boot", "wired browser service start failed");
			}
		}
	#endif
	debug_log("Setup ran on core %d, busy core is %d\n\r", xPortGetCoreID(), CoreUsage::busiestCore());
}

// The main loop
//
void loop() {
	while (true) {
		delay(1000);
		#ifdef AGON_EXTENDER_P4_BOOT
			// Phase F target qualification reads only thread-safe, sink-owned
			// counters here. Do not sample LogicalFrameService::metrics() while
			// its task is running: that interface is intentionally post-stop.
			static uint8_t diagnosticSeconds = 0;
			if (++diagnosticSeconds >= 10) {
				diagnosticSeconds = 0;
				#ifdef AGON_EXTENDER_PORT008_NONRELEASE_QUALIFICATION
				agon::extender::transport::logP4QualificationStatus();
				#endif
				if (_VGAController != nullptr) {
					auto const snapshot = displaySnapshotPool().metrics();
					ESP_LOGI("extender_snapshot",
						"enabled=%u alloc_fail=%u cadence=%u transition=%u "
						"producer_busy=%u no_slot=%u compose_fail=%u "
						"published=%u no_new=%u",
						static_cast<unsigned>(snapshot.enabled),
						static_cast<unsigned>(snapshot.allocation_failures),
						static_cast<unsigned>(snapshot.cadence_skips),
						static_cast<unsigned>(snapshot.transition_busy),
						static_cast<unsigned>(snapshot.producer_busy),
						static_cast<unsigned>(snapshot.producer_no_slot),
						static_cast<unsigned>(snapshot.composition_failures),
						static_cast<unsigned>(snapshot.publications),
						static_cast<unsigned>(snapshot.consumer_no_new));
				}
				if (wiredNetworkService != nullptr) {
					auto const network = wiredNetworkService->metrics();
					ESP_LOGI("extender_network",
						"state=%u clients=%u refused=%u credits=%u protocol=%u "
						"sent=%u send_fail=%u disconnect_release=%u http=%u/%u "
						"http_fail=%u queued=%u queue_fail=%u socket_fail=%u",
						static_cast<unsigned>(wiredNetworkService->state()),
						static_cast<unsigned>(network.video.clients_accepted),
						static_cast<unsigned>(network.video.clients_refused),
						static_cast<unsigned>(network.video.credits_accepted),
						static_cast<unsigned>(network.video.protocol_errors),
						static_cast<unsigned>(network.video.sends_completed),
						static_cast<unsigned>(network.video.sends_failed),
						static_cast<unsigned>(network.video.disconnect_releases),
						static_cast<unsigned>(network.http_starts),
						static_cast<unsigned>(network.http_stops),
						static_cast<unsigned>(network.http_start_failures),
						static_cast<unsigned>(network.queued_sends),
						static_cast<unsigned>(network.queue_failures),
						static_cast<unsigned>(network.socket_send_failures));
				}
				if (browserVideoProvider != nullptr) {
					auto const provider = browserVideoProvider->metrics();
					ESP_LOGI("extender_provider",
						"acquired=%u no_new=%u invalid=%u sent=%u failed=%u "
						"disconnected=%u",
						static_cast<unsigned>(provider.acquired),
						static_cast<unsigned>(provider.no_new_message),
						static_cast<unsigned>(provider.invalid_snapshot),
						static_cast<unsigned>(provider.released_sent),
						static_cast<unsigned>(provider.released_failed),
						static_cast<unsigned>(provider.released_disconnected));
				}
				ESP_LOGI("extender_heap",
					"free_8bit=%u minimum_8bit=%u free_psram=%u minimum_psram=%u",
					static_cast<unsigned>(heap_caps_get_free_size(MALLOC_CAP_8BIT)),
					static_cast<unsigned>(heap_caps_get_minimum_free_size(MALLOC_CAP_8BIT)),
					static_cast<unsigned>(heap_caps_get_free_size(MALLOC_CAP_SPIRAM)),
					static_cast<unsigned>(heap_caps_get_minimum_free_size(MALLOC_CAP_SPIRAM)));
			}
		#endif
	};
}

void processLoop(void * parameter) {
#ifdef USERSPACE
	uint32_t count = 0;
#endif /* USERSPACE */

	setupKeyboardAndMouse();
#if defined(AGON_EXTENDER_CONSOLE)
	runConsole(processor);
	return;
#elif defined(AGON_EXTENDER_BROWSER_TYPING)
	runBrowserTyping(processor);
	return;
#elif defined(AGON_EXTENDER_KEYBOARD_QUALIFICATION)
	runKeyboardQualification(processor);
	return;
#elif defined(AGON_EXTENDER_VISIBLE_TEXT_QUALIFICATION)
	runVisibleTextQualification(processor);
	return;
#elif defined(AGON_EXTENDER_GENERAL_POLL_QUALIFICATION)
	// One bounded poll through the real parser. wait_eZ80 additionally emits
	// mode information and varies with reset cause; startup is a later gate.
	runGeneralPollQualification(processor);
	return;
#else
	processor->wait_eZ80();
#endif

	while (true) {
#ifdef USERSPACE
 		if ((count & 0x7f) == 0) {
			delay(1 /* -TM- ms */);
		}
 		count++;
#endif /* USERSPACE */

		#ifdef VDP_USE_WDT
			esp_task_wdt_reset();
		#endif
		if (processTerminal()) {
			continue;
		}

		processor->processNext();
	}
}

// The boot screen
//
void boot_screen() {
	printFmt("Agon %s VDP Version %d.%d.%d", VERSION_VARIANT, VERSION_MAJOR, VERSION_MINOR, VERSION_PATCH);
	#if VERSION_CANDIDATE > 0
		printFmt(" %s%d", VERSION_TYPE, VERSION_CANDIDATE);
	#endif
	#ifdef VERSION_SUBTITLE
		printFmt(" %s", VERSION_SUBTITLE);
	#endif
	// Show build if defined (intended to be auto-generated string from build script from git commit hash)
	#ifdef VERSION_BUILD
		printFmt(" Build %s", VERSION_BUILD);
	#endif
	printFmt("\n\r");
}

// Debug printf to PC
//
#ifndef USERSPACE
void debug_log(const char *format, ...) {
	#if DEBUG == 1
	va_list ap;
	va_start(ap, format);
	auto size = vsnprintf(nullptr, 0, format, ap) + 1;
	if (size > 0) {
		va_end(ap);
		va_start(ap, format);
		char buf[size + 1];
		vsnprintf(buf, size, format, ap);
		DBGSerial.print(buf);
	}
	va_end(ap);
	#endif
}
#endif

void force_debug_log(const char *format, ...) {
	va_list ap;
	va_start(ap, format);
	auto size = vsnprintf(nullptr, 0, format, ap) + 1;
	if (size > 0) {
		va_end(ap);
		va_start(ap, format);
		char buf[size + 1];
		vsnprintf(buf, size, format, ap);
		#ifdef AGON_EXTENDER_P4_BOOT
			ESP_LOGI("extender_vdp", "%s", buf);
		#else
			DBGSerial.print(buf);
		#endif
	}
	va_end(ap);
}

// Set console mode
// Parameters:
// - mode: 0 = off, 1 = on
//
void setConsoleMode(bool mode) {
	#ifdef AGON_EXTENDER_P4_BOOT
		(void)mode;
		consoleMode = false;
	#else
	consoleMode = mode;
	#endif
}

// Terminal mode state machine transition calls
//
void startTerminal() {
	#ifdef AGON_EXTENDER_P4_BOOT
		terminalState = TerminalState::Disabled;
		return;
	#else
	switch (terminalState) {
		case TerminalState::Disabled: {
			terminalState = TerminalState::Enabling;
		} break;
		case TerminalState::Suspending: {
			terminalState = TerminalState::Enabled;
		} break;
		case TerminalState::Suspended: {
			terminalState = TerminalState::Resuming;
		} break;
	}
	#endif
}

void stopTerminal() {
	#ifdef AGON_EXTENDER_P4_BOOT
		terminalState = TerminalState::Disabled;
		return;
	#else
	switch (terminalState) {
		case TerminalState::Enabled:
		case TerminalState::Resuming: 
		case TerminalState::Suspended:
		case TerminalState::Suspending: {
			terminalState = TerminalState::Disabling;
		} break;
		case TerminalState::Enabling: {
			terminalState = TerminalState::Disabled;
		} break;
	}
	#endif
}

void suspendTerminal() {
	#ifdef AGON_EXTENDER_P4_BOOT
		terminalState = TerminalState::Disabled;
		return;
	#else
	switch (terminalState) {
		case TerminalState::Enabled:
		case TerminalState::Resuming: {
			terminalState = TerminalState::Suspending;
			processTerminal();
		} break;
		case TerminalState::Enabling: {
			// Finish enabling, then suspend
			processTerminal();
			terminalState = TerminalState::Suspending;
		} break;
	}
	#endif
}
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

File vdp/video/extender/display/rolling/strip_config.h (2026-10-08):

#pragma once
#ifdef AGON_EXTENDER_HDMI_512X384
#define STRIP_WIDTH 512
#define STRIP_HEIGHT 384
#define STRIP_BLOCKS 12
#elif defined(AGON_EXTENDER_HDMI_684X384)
#define STRIP_WIDTH 684
#define STRIP_HEIGHT 384
#define STRIP_BLOCKS 12
#else
#define STRIP_WIDTH 848
#define STRIP_HEIGHT 480
#define STRIP_BLOCKS 15
#endif
// AUTO reserves the848 maximum, then uses runtime684/848 geometry.
// Three32-row slots:147456 bytes at512 pixels,196992 at684,244224 at848.
// Keep the same conservative refill abort, since the
// pixel clock and horizontal total (and hence a row's duration) are unchanged.
#define STRIP_ROWS (STRIP_HEIGHT / STRIP_BLOCKS)
#define STRIP_ROLLING 1
#define STRIP_SLOTS 3
#define STRIP_REFILL_LIMIT_US 1600
// Optional negative control; zero disables it. Not normal workload timing.
#define STRIP_INJECT_LATE_TAG 0

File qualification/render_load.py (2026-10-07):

#!/usr/bin/env python3
"""Frozen render-load-r04 bench runner; explicit operations, no uncertain replay.

Addresses/GPIO mapping are supplied by an ignored local JSON configuration.
External SD jobs run only at admitted CLI; measured applications exclude them.
"""
import argparse, datetime, hashlib, importlib.util, json, subprocess, sys, time
import urllib.error, urllib.request
from pathlib import Path
ROOT=Path(__file__).resolve().parents[1]
HOST_SOURCE_SHA256=hashlib.sha256(Path(__file__).read_bytes()).hexdigest()
sys.path.insert(0,str(ROOT/'tests/performance/render_load'))
from codec import plan,decode
from generate import MODES
sys.path.insert(0,str(ROOT/'scripts'))
from sdcard import Client as SDClient,RemoteError

def digest(b):return hashlib.sha256(b).hexdigest()
def utc():return datetime.datetime.now(datetime.timezone.utc).strftime('%Y-%m-%d-%H-%M-%SZ')
class Bench:
    def __init__(self,config,evidence):
        self.config=json.loads(config.read_text());self.evidence=evidence;evidence.mkdir(parents=True,exist_ok=True)
        self.events=json.loads((evidence/"requests.json").read_text()) if (evidence/"requests.json").exists() else [];self.state_path=evidence/'state.json'
        self.state=json.loads(self.state_path.read_text()) if self.state_path.exists() else {}
        self.sd=None
    def fast_connect(self):
        if self.sd is None:
            journal=Path(self.state.get('fast_journal',str(self.evidence/('fast-session-'+utc()+'.json'))))
            self.sd=SDClient(self.config['p4'],journal);self.sd.connect()
            self.state['fast_journal']=str(journal);self.save()
        return self.sd
    def key_command(self,command):
        subprocess.run([sys.executable,str(ROOT/'scripts/keyboard.py'),'--url',self.config['p4'],'--state',str(self.evidence/'keyboard.json'),'type',command,'--enter'],check=True,timeout=15,stdout=subprocess.DEVNULL)
    def fast_start(self):
        # Call only at a CLI established by a completed finite metadata job or
        # the foreground listener's successful EXIT, never a running fixture.
        self.key_command('EMOS LEGACY')
        time.sleep(1)
        self.key_command('EMOS sdserve --fast /')
        # This explicit start creates a new listener incarnation. Retain any
        # old journal as evidence, but never bind its SID/boot to the new one.
        if self.sd:self.sd.lock.close();self.sd=None
        self.state.pop('fast_journal',None);self.save()
        limit=time.monotonic()+10
        while time.monotonic()<limit:
            with urllib.request.urlopen(self.config['p4']+'/sd/status',timeout=3) as r:s=json.load(r)
            if s['online']:return self.fast_connect()
            time.sleep(.2)
        raise RuntimeError('fast listener did not start')
    def fast_exit(self):
        c=self.fast_connect();c.rpc(11);c.lock.close();self.sd=None
        self.state.pop('fast_journal',None);self.save()
        time.sleep(1)
        with urllib.request.urlopen(self.config['p4']+'/sd/status',timeout=3) as r:s=json.load(r)
        if s['online']:raise RuntimeError('foreground listener did not exit')
    def fast_read(self,path):return self.fast_connect().download(path)
    def fast_put_new(self,path,data):
        c=self.fast_connect()
        try:c.stat_entry(path)
        except RemoteError as e:
            if e.status!=6 or e.detail not in (b'\x04',b'\x05'):raise
        else:raise RuntimeError(('target not absent',path))
        t=time.monotonic();c.upload(path,data,True,fast=True);upload=time.monotonic()-t
        t=time.monotonic();got=c.download(path);readback=time.monotonic()-t
        if got!=data:raise RuntimeError(('fast upload readback differs',path))
        self.events.append({'utc':utc(),'operation':'fast-upload','path':path,'bytes':len(data),'sha256':digest(data),'upload_seconds':upload,'single_readback_seconds':readback});self.save()
    def save(self):
        self.state_path.write_text(json.dumps(self.state,indent=2)+'\n')
        (self.evidence/'requests.json').write_text(json.dumps(self.events,indent=2)+'\n')
    def request(self,method,path,data=None,headers=None,timeout=600):
        time.sleep(1.5) # EMOS finite SD job exits before the next admission.
        t=time.monotonic();url=self.config['dav']+path
        try:
            with urllib.request.urlopen(urllib.request.Request(url,data=data,method=method,headers=headers or {}),timeout=timeout) as r:status=r.status;body=r.read()
        except urllib.error.HTTPError as e:status=e.code;body=e.read()
        self.events.append({'utc':utc(),'method':method,'path':path,'status':status,'seconds':time.monotonic()-t,'bytes':len(body),'sha256':digest(body)})
        self.save();return status,body
    def read(self,path):
        s,b=self.request('GET',path)
        if s!=200:raise RuntimeError(('GET',path,s,b[:500]))
        return b
    def absent(self,path):
        s,b=self.request('HEAD',path)
        if s!=404:raise RuntimeError(('target not absent',path,s,b[:500]))
    def put_new(self,path,data):
        self.absent(path);s,b=self.request('PUT',path,data)
        if s not in (200,201,204):raise RuntimeError(('PUT failed; do not replay',path,s,b[:500]))
        if self.read(path)!=data:raise RuntimeError(('readback differs',path))
    def mkdir(self,path):
        s,b=self.request('MKCOL',path)
        if s not in (200,201,204):raise RuntimeError(('MKCOL',path,s,b[:500]))
    def move(self,src,dst):
        self.absent(dst);s,b=self.request('MOVE',src,headers={'Destination':self.config['dav']+dst,'Overwrite':'F'})
        if s not in (200,201,204):raise RuntimeError(('MOVE failed; do not replay',src,dst,s,b[:500]))
    def preserve(self):
        if 'original_sha256' in self.state:return
        b=self.fast_read('/autoexec.txt');(self.evidence/'original-autoexec.txt').write_bytes(b)
        self.state.update(original_sha256=digest(b),current_sha256=digest(b),startup_index=0);self.save()
    def startup(self,b):
        self.preserve()
        if digest(self.fast_read('/autoexec.txt'))!=self.state['current_sha256']:raise RuntimeError('startup changed outside this runner')
        self.fast_exit()
        # A previous closeout flag must not survive a new startup mutation.
        # Restoration is confirmed separately after image/startup verification.
        self.state['restored']=False;self.save()
        old=self.config['results_root']+f"/startup-{self.state['startup_index']:03}.txt"
        self.move('/autoexec.txt',old)
        self.state['startup_index']+=1;self.state['startup_missing']=True;self.save()
        self.fast_start();self.fast_put_new('/autoexec.txt',b)
        self.state['current_sha256']=digest(b);self.state['startup_missing']=False;self.save()
    def reset(self):
        t=time.monotonic()
        subprocess.run([sys.executable,str(ROOT/'scripts/reset_agon.py'),'--config',self.config['reset_config'],'--local'],check=True,timeout=15)
        return time.monotonic()-t
    def confirm_p4_fixture_cli(self,out):
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

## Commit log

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2026-08-22 PORT-003: pin bench fixture and qualification procedure r03
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2026-08-25 SETUP-006.1.1 inventory wiring objects and reset configurations
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2026-08-25 SETUP-006/AUDIT-002: establish and verify Light 2 wiring reference
    - finalize the deterministic BB1460/P4 Fritzing scaffold and corrected r05 P4 part
    - add Agon signal headers, labels, U1, and preserved/generated wiring drafts
    - document firmware-led electrical requirements and candidate isolation design
    - add deterministic connectivity extraction and expected-circuit validation
    - correct power entry, PC1/U1 routing, pull-ups, bypass wiring, and hole occupancy
    - verify draft_v2 is electrically equivalent with all 60 checks passing
    - record SN74LV125AN order status and close AUDIT-002
    [light2-extender-breadboard-scaffold.fzz, light2-extender-breadboard-wiring-draft.fzz, light2-extender-breadboard-wiring-draft_v1.fzz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]
2026-08-25 SETUP-006/CA-2026-08-25-001: correct Agon UART1 pin labels
    Advance the embedded Agon header and label-bank parts to r03, migrate all current Fritzing drafts, and refresh deterministic and electrical-audit evidence without changing wiring or net partitions. Preserve the associated SETUP-006.4 GPIO ownership research that exposed the defect.
    [light2-extender-breadboard-scaffold.fzz, light2-extender-breadboard-wiring-draft.fzz, light2-extender-breadboard-wiring-draft_v1.fzz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]
2026-08-28 PORT-003 15: correct P4 retained watchdog binding
    [video.ino]
2026-08-29 HW-001: freeze light2 harness r02 wiring specification
    Freeze the canonical UART and forward-parallel connectivity, checked design BOM, assembly identities, ADR, and deterministic KiCad signal atlas. Record r01 as the preserved forward-test prototype and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
    [00-canonical-component-placement.kicad_sch, 01-d0-uart-rx-lane.kicad_sch, 02-d1-uart-tx-lane.kicad_sch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]
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2026-08-31 PORT-008: record EMOS forward adapter handoff
    Pin the P4, EMOS, and mos-agondev source identities; record fixture/build measurements and approved emulator evidence; preserve the non-physical claim boundary; and ignore transient KiCad .lck files.
2026-08-31 PORT-008: preserve EMOS hardware recovery evidence
    Record the failed UART diagnosis, ZDI divisor capture, P4 recovery programmer, successful EMOS flash and smoke run, source selections, and bench-document corrections used during physical qualification.
    [schematic.kicad_sch]
2026-09-01 PORT-008: refreeze forward candidate after UART correction
    Select the corrected EMOS and mos-agondev authorities, preserve the unchanged forward fixture and procedure boundary, and add deterministic staging for clean identified EMOS and fixture artifacts.
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2026-09-01 PORT-008: stage forward fixture media
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2026-09-02 Add fail-closed production object provenance gate
    [video.ino]
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2026-09-04 HW-001: freeze r02 schematic and ordered signal views
    [01_schematic_power-domains.kicad_sch, 02_schematic_startup-and-fail-safe-bias-network.kicad_sch, 03_schematic_uart-forward-enable.kicad_sch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]
2026-09-05 Checkpoint PORT-008 work and Sol-to-Astra handoff
    Preserve the interrupted Work 2.e P4 recorder, EMOS comparator/policy,
    regression tests, and audit/remediation records as provisional source.
    Record the GPT-5.6 Sol to GPT-6 Astra handoff and the unresolved sequencing
    between qualification-object capture and eventual release equivalence.
    Also preserve the pending physical header/color reference, preliminary
    QUAL-002 construction observations, and exact passive-GPIO fixture inputs.
    Ignored raw evidence and generated build residue remain untracked.
    Validation: all 155 task-local host tests pass; changed Python and JSON parse.
    Version validation fails on an existing committed r02 connectivity/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
    [partitions.csv]
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2026-09-07 Checkpoint wiring records and put incomplete hardware work on hold
    Preserve the connection ledger, relocated power-domain observations, and staged-construction documentation. Mark superseded procedures and the rejected resistor proposal explicitly.
    Pause current hardware design, construction, test preparation, and qualification across the task and design records. Full wiring remains incomplete and the complete circuit is untested. Retain the r0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
    [connections.csv]
2026-09-07 Accept AUDIT-004 stock MOS/VDP communications audit
    Freeze the selected stock baselines, 46 communication families, 11 transport references, endpoint traces, coverage reconciliation and review overview.
    Record Author acceptance and related canonical-reference ownership corrections. Retain explicit evidence limits and the hardware hold; subsequent comparison and implementation tasks remain separate.
2026-09-07 Checkpoint r03 harness and accepted Port C pinwalk
    Add the direct Port C schematic, connectivity authority, KiCad project and checked review exports. Preserve the keyboard-free fixture and Pi capture workflow.
    Record the Author-accepted eight-line pinwalk PASS with raw evidence, exact build and acquisition tools. Retain the short-acquisition discrepancy and remaining electrical/UART review boundaries in HW-002.
    [schematic.kicad_sch]
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2026-09-08 Record accepted EMOS hardware boot and corrected procedure
    Registry r23 selects emos-ordinary-boot-r02, correcting the case-sensitive
    mos updater argument while retaining the one-shot rename guard. Record the
    Author-accepted three-cold-boot result and EMOS evidence commit 6c4aed7.
    Keep the completed run's original r01 identity and installation deviation.
    Firmware remains candidate; no r02 hardware rerun or broader compatibility
    claim is made.
    Validation: registry-specific and diff checks pass. The full version checker
    retains the documented, unrelated held r02 connectivity hash mismatch.
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2026-09-08 Record accepted UART flow-control hardware milestone
    Preserve installation and test preparation, raw serial and logic evidence,
    exact frame decoding, pause measurements and the Author-accepted capture
    duration exception. Record capture discovery corrections and informative
    analyzer failures; close PORT-011 with endpoint and waveform checks passed.
    The analyzer acquisition verdict remains failed at 27.57632 of 60 seconds;
    the complete exchange and 11.526723-second quiet tail support the accepted
    bounded result. Firmware candidate identities remain unchanged.
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2026-09-08 Allow repeated visible-text transactions after Agon reset
    Rearm the P4 fixture after successful completion and EMOS RTS release while retaining parser and framebuffer state. Remove idle expiry, preserve active-transfer deadlines and released GPIO outputs between cycles, and test the real orchestration with deterministic UART/GPIO fakes. Freeze approved r02/r33 and retain the first r01 UART/browser evidence and installation records.
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2026-09-09 Add focused browser typing through resident EMOS
    Map bounded browser sessions to retained keyboard packets and render the SD application's UART echo. Release held keys on revocation, contain partial network sends and failed server stops, and freeze reviewed candidate identities with the hardware test sheet. Physical typing remains pending.
    [video.ino]
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2026-09-09 Prepare native P4 USB keyboard acquisition candidate
    Record the reviewed browser timing findings and accepted USB priority, connector mapping and bounded PORT-015 work. Add a native boot-keyboard diagnostic with retained processed-key mapping, report-loss recovery and unplug cleanup.
    Pin HID 1.2.1 in a separate dependency lock while preserving all existing dependency versions. Decoder, browser regression and source-selection checks pass; an identified source-stable P4 draft builds. Hardware acquisition remains pending. Aggregate version validation retains the pre-existing r02 connectivity hash failure.
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2026-09-10 Freeze reviewed UART ExCom console composition
    Combine the retained P4 VDU parser, browser video and native USB input with a staged EMOS-owned console lease. Record the accepted idle-CLI switching decision, wire contract and bounded hardware procedure.
    Paired control/stream and failed-entry tests pass with EMOS checkpoint 8e63cc4; Author accepted the final mainboard screenshot. Preserve the unresolved native-reference glyph issue and held-r02 hash discrepancy. Physical console qualification remains pending.
    [video.ino]
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2026-09-10 Accept ExCom hardware console and Nurples gameplay milestone
    Record Author acceptance of native USB input and retained EDP browser output through EMOS-owned UART routing. Preserve successful entry, Legacy return and re-entry evidence; close the reproduced activation crash. The Author also played Nurples rendered on P4 and reports that graphics looked great apart from five-fps browser presentation.
    Keep browser presentation latency and wider VDP compatibility as follow-up work. Gameplay is an operator observation, not a frame-by-frame comparison. Firmware identities remain candidates; no additional flash, reset or SD operation accompanies this progress freeze.
2026-09-10 Add RGB222 browser video and remove fixed frame throttle
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2026-09-10 Freeze MOS reuse audit and benchmark-first plan
    Record W1/W2 source and saved-ELF findings without timing claims.
    Select paired Legacy/ExCom benchmarks before repairs, repeated measurements
    and Author Nurples playtesting. Defer automated Nurples control; any later
    fixture must send normal EDP keyboard packets through UART and EMOS.
    Record future MicroPython support with v1 placement undecided and make EMOS
    read access explicit in the existing P4 microSD storage plan.
    Validation: documentation whitespace and 111 local links checked; all TODO
    entries have task details. Documentation only; no firmware or bench changes.
2026-09-10 Freeze paired UART baseline and authorize CTS attribution capture
    Preserve the 48-row physical Legacy/ExCom comparison, bounded late-reply observer and functional fixture reviews. Record slower ExCom output without attributing it prematurely to sender overhead or P4 backpressure.
    Include the hardware-confirmed Fab filesystem reproducer and unsubmitted report. Freeze the W6 contract for one unchanged counted-point UART/CTS trace before selecting a firmware repair.
    [00000001.CSV, 00000002.CSV, 00000003.CSV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]
2026-09-10 Freeze measured P4 backpressure and browser-off control contract
    Preserve the exact counted-point UART capture analysis and matching Agon SD result. P4 withholding CTS accounts for 3.407 of 4.456 seconds on the payload wire; the final reply delay is not caused by Agon withholding receive permission.
    Include validated capture and analysis tools, retain informative acquisition failures, and formalize authorized W7: repeat the unchanged workload with browser video disconnected before choosing a firmware repair.
    [00000004.CSV]
2026-09-10 Freeze browser-off findings and P4 wait attribution contract
    [00000005.CSV]
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2026-09-10 Freeze stock-drain results and contract Nurples frame timing investigation
    [00000006.CSV, 00000007.CSV]
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2026-09-11 Restore original VDP depth controllers and independent P4 frame service
    Preserve stock packed rows, renderer bodies and scanline composition behind the reviewed P4 task and output bindings. Keep the frame clock independent of native drawing and browser output.
    Accept R2: 70 runtime and 42 scanline checks pass; 180 native comparisons pass with two unchanged upstream observations. P4 display and ordinary-console relocatable links pass. R3 deployment and qualitative Nurples review are authorized; physical qualification remains open.
    [agon_ps2.h, context.h, run.py]
2026-09-11 Select the restored stock renderer for the P4 console candidate
    Build the ordinary USB/UART console with all five original depth controllers and independent clock, drawing and packed-row output. Exclude the replaced generic backend. Preserve SDK header precedence and reject classic ISR execution.
    Complete draft image and source/body/layout checks pass. Freeze uart-excom-console-r10 under standing approval for P4-only deployment and a qualitative repaired-Nurples review; EMOS unchanged.
2026-09-12 docs: freeze first physical graphics timing failure and deployment history
    [GQT001.CSV]
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2026-09-13 Record framebuffer timings and stock UART divergence findings
    [baseline39.csv, first-partial.csv, second-partial.csv]
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2026-09-13 Freeze pure UART fixture and paired diagnostic build procedure
2026-09-13 Correct fixture recovery and validate complete UART result sequences
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2026-09-13 Record complete pure UART baseline before transport alignment
    [baseline.csv]
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2026-09-13 Record bulk-read hardware pass with unchanged UART throughput
    [bulk.csv]
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2026-09-13 Record stock RX timeout hardware comparison with exact data
    [rx2.csv]
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2026-09-13 Record faster return transfer with all pure-data cases passing
    [txfill.csv]
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2026-09-13 Preserve mixed-traffic failure and reproduce a stranded partial reply
    [mixed-failure.csv]
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2026-09-13 Confirm stock reply ordering resolves physical mixed-transfer failure
    [mixed-order.csv]
2026-09-13 PORT-008: close separate and mixed UART regression after stock ordering restoration
    [order-full.csv]
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2026-09-13 PORT-008: attribute pure UART gaps to sender idle and Agon return backpressure
    [wire.csv]
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2026-09-13 PORT-008: retain mainboard graphics timeout and recovered partial evidence
    [graphics-failure.csv]
2026-09-13 PORT-008: record complete graphics retry and isolated loading improvements
    [graphics.csv]
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2026-09-15 Record completed rendering comparison and empirical duration limits
    [GQT009.CSV]
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2026-09-15 test: isolate current Rally buffered road conversion on both displays
    [RXEXC02.CSV, RXLEG02.CSV]
2026-09-15 test: record reproducible ExCom road-section mismatch and review stop
    [RXEXC03.CSV, RXLEG03.CSV]
2026-09-15 fix: encode signed fixed-point transform results safely on P4
    [vdu_buffered.h]
2026-09-15 Record RX06 hardware parity and close immediate numeric repair
    [RXEXCF1.CSV, RXLEGF1.CSV]
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2026-09-15 Require sustained frame delivery after each viewer replacement
2026-09-15 Record passing audio framing hardware comparison and unmuted Rally capture
    [AFEXC1.CSV, AFLEG1.CSV]
2026-09-15 fix: guard P4 parser numeric narrowing before casts
    [vdu_buffered.h]
2026-09-15 test: correct numeric mask probe foreground palette
2026-09-15 test: record passing paired numeric guard hardware checks
    [NEXC2.CSV, NLEG2.CSV, NREJ2.CSV]
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2026-09-15 Pin corrected unfenced sustained fixture for probe-overhead control
2026-09-15 Freeze reapplication of qualified UART changes missing from bench image
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2026-09-15 Pin corrected-mutex same-core comparison for the next bench gate
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2026-09-15 Specify stock-compatible explicit refresh boundaries for trace fixture
2026-09-15 Add bounded post-run refresh trace and matched sprite fixtures
    [vdu_buffered.h]
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2026-09-15 Freeze quarter-frame drawing opportunity control after hardware-sprite tail failure
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2026-09-15 Summarize Nurples provenance corrections and current parity investigation
2026-09-15 Record repeated hardware-sprite timing failure and freeze probe-cost control
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2026-09-15 Verify all r40 workload fingerprints against stock and record repeat failure
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2026-09-15 Freeze stock multi-pool framebuffer control after probe-cost timing failure
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2026-09-15 Record r43 timing failure and freeze passive UART attribution under game load
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2026-09-16 diagnostics: retain network preemption trace and failed qualification gate
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2026-09-16 Record payload ladder failure below link capacity and restore baseline
2026-09-16 Freeze P4 standalone HTTP reference selection and measurement design
    [partitions.csv]
2026-09-16 Implement standalone P4 full-frame HTTP fixture and exact pixel receiver
2026-09-16 Keep fixture console on USB and add durable wired bench runner
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2026-09-16 QUAL-004 add isolated per-case collection with retained bounded crash retries
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2026-09-16 Record AGM decompression wire contracts and upstream collision check
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2026-09-17 Fix P4 command-task stack capacity for original szip asset decoding
2026-09-17 Record corrected SRLE2 P4 codec and full-frame asset correctness passes
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2026-09-17 Complete C02 native screen with exactness and timeout evidence
    [native.csv]
2026-09-17 Correct image experiment HTTP endpoint capacity before codec testing
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2026-09-17 docs: record Pico parts correction and bench automation options
2026-09-18 Complete AUDIO-001 feasibility with hardware SD rates and parallel budget
    [results.csv]
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2026-09-19 Record fixture adaptation and preserve SD startup during mode sweeps
    [run.py]
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2026-09-19 Require observed workload changes and hold injected fixture keys
    [run.py]
2026-09-19 Freeze selector short circuit before corrected all-mode sweep
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2026-09-20 Restore stock virtual-key query replies through processed input
    [result.csv]
2026-09-20 Record paired timing evidence and complete timing closeout
    [combined.csv, empty.csv, protocol.csv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]
2026-09-24 Preserve P4-PC references and deferred physical video research
    [ESP32-P4-PC_Rev_B-B_Cu.gbr, ESP32-P4-PC_Rev_B-B_Mask.gbr, ESP32-P4-PC_Rev_B-B_Paste.gbr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]
2026-09-24 Freeze AUDIT-008 findings and bounded EMOS simplification contract
    [FUNCTIONS.csv, OBJECTS.csv]
2026-09-24 Record AUDIT-008 ROM recovery and passing local validation; defer bench acceptance
    [FUNCTIONS.csv, OBJECTS.csv]
2026-09-24 Keep generated audit CSV evidence in repository text format
    [FUNCTIONS.csv, OBJECTS.csv]
2026-09-24 Consolidate current Extender operating guides and audit provenance gaps
    [INVENTORY.csv]
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2026-09-24 docs: reconcile implemented services and held hardware architecture
    [INVENTORY.csv]
2026-09-24 docs: distinguish current procedures from retained bench fixtures
    [INVENTORY.csv]
2026-09-24 docs: record audit coverage and reconcile sprite qualification status
    [INVENTORY.csv]
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2026-09-24 docs: reconcile porting checkpoints and record third audit tranche
    [INVENTORY.csv]
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2026-09-24 docs: reconcile upstream fidelity and dependency decisions for A09-N01
    [INVENTORY.csv]
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2026-09-25 Record corrected P4 boot verification and staged SD validation
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2026-09-27 Reconcile selected browser pacing with retained 30 fps policy
    [INVENTORY.csv]
2026-09-27 Clarify timing runner reuse boundary and refresh ownership
    [INVENTORY.csv]
2026-09-27 Clarify SD qualification reuse and assign procedure refresh
    [INVENTORY.csv]
2026-09-27 Consolidate example guidance and retain obsolete recipes as evidence
    [INVENTORY.csv]
2026-09-27 Audit shared P4 service guides and current integration status
    [INVENTORY.csv]
2026-09-27 Record early EMOS integration audit and historical probe scope
    [INVENTORY.csv]
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2026-09-28 Fix stale admission clock samples and ordinary rejection completion
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2026-09-28 Correct LCD framebuffer channel packing
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2026-09-29 build: stage corrected equivalence run
2026-09-29 docs: localize late mode switch failure
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2026-09-29 fix: bound mutable font storage
    [context.h, video.ino]
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2026-09-30 qualification: make reset verification explicit
    [run.py]
2026-09-30 qualification: suppress unsafe failure input
    [run.py]
2026-09-30 qualification: select legacy before RP04 fixture
    [run.py]
2026-09-30 Fix RP04 qualification completion protocol
    [run.py]
2026-09-30 Fix RP04 argument launch and failure cleanup
    [run.py]
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2026-10-07 test(render): add deterministic workload fixtures and comparison tools
    [game_art_visual.py, render_load.py, render_load_analyse.py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]
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2026-10-09 feat(transport): checkpoint P4 sessions and private boot recovery
    Bind version-2 control requests to the retained console owner and add reciprocal release adapters plus an explicit startup candidate. Keep ordinary startup selectable, gate shared UART pin restoration, and verify profile selections and modeled failure paths. Full native builds pass; no deployment or production promotion.
2026-10-09 fix(transport): quarantine P4 UART state on observed peer loss
    [context.h, vdu_stream_processor.h]
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2026-10-11 Prepare DevKit reverse control and preserve filtered D7 findings
2026-10-11 Freeze P4-PC reverse comparison without analyzer probes
2026-10-11 Record P4-PC reverse failure without analyzer probes
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2026-10-11 Freeze ExExt UART service isolation correction
2026-10-11 docs(exext): record reset proof and staged return boundaries
2026-10-11 docs(exext): bound mode teardown correction after captured DMA panic
2026-10-11 fix(hdmi): retire shared DMA interrupt before register clock
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2026-10-11 Freeze ExExt retained PARLIO resource correction after DMA allocation repeat
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2026-10-11 Record finite Rally UART controls and correct completion evidence scope
2026-10-11 Refresh current ExExt handoff and preserve Apple/reset evidence
2026-10-11 Freeze failed ExExt performance disposition and exact UART rollback
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2026-10-12 fix(bench): prevent serial-open resets and record restored UART baseline
2026-10-12 test(video): prepare UART-only indexed PPA comparison and CLI fixtures
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2026-10-13 Checkpoint qualification repairs and add HDMI aspect correction task
    Preserve all current work before proceeding on HDMI-003 at the Author's request. Record incomplete hardware qualification, Legacy startup restoration, diagnostic ID mapping, and the pending visual diagnosis; the full campaign remains stopped.
